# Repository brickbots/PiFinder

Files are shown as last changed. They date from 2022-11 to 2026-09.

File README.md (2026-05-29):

# PiFinder™
A plate solving telescope finder based around a Raspberry PI, imx296 camera, and custom UI 'hat'

For an overview of what the PiFinder™ is and how it came to be visit the official project website at [PiFinder.io](https://www.pifinder.io/build-yours) 

The PiFinder™ uses the [Cedar Detect](https://github.com/smroid/cedar-detect) and
[Cedar Solve](https://github.com/smroid/cedar-solve) libraries by
[smroid](https://github.com/smroid). Cedar Solve is licensed under Apache-2.0.

**Cedar Detect** is published under the Functional Source License (`FSL-1.1-MIT`),
which permits broad non-commercial use but excludes commercial uses that compete
with Cedar Detect. Because the PiFinder™ is also offered commercially, it bundles
and distributes the Cedar Detect binaries under a **separate license granted
expressly by the copyright holder** — not under the public FSL terms. The prebuilt
binaries live in [`bin/`](./bin/); see [`bin/README.md`](./bin/README.md) for the
full licensing details and a copy of the Cedar Detect license. Note this is
distinct from the PiFinder project's own GPL-3.0 [`LICENSE`](./LICENSE).

Thank you to [smroid](https://github.com/smroid) for all your support of the PiFinder project!

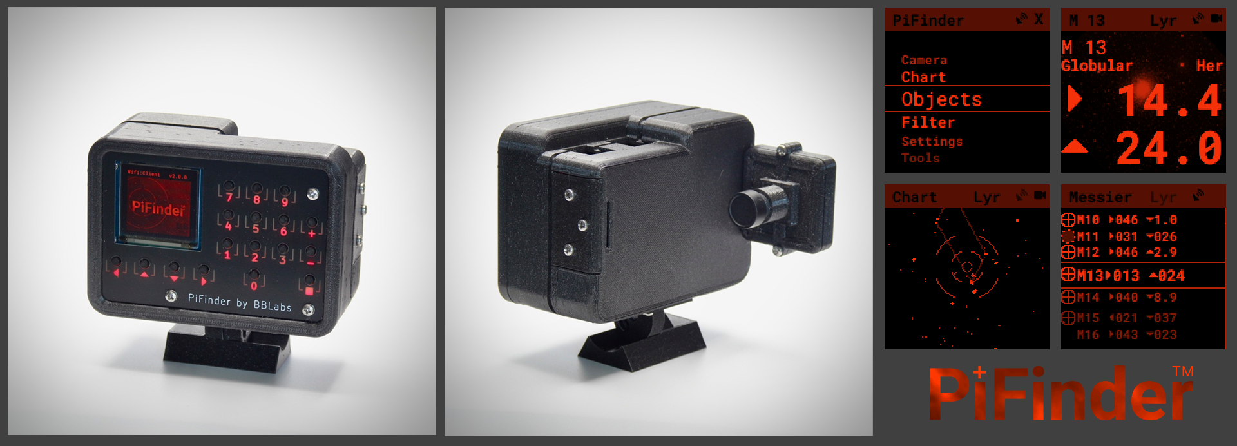
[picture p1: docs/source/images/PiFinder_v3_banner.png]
Banner

The PiFinder™ is my attempt to improve my time at my telescope.  I don't get nearly enough of it and I want to enjoy it as much as possible.  So after years of observing with paper charts and, later, a Nexus DSC here is what I felt I was missing:
* **Reliable telescope positioning:**  The Nexus DSC is great, but my scope just isn't built for solid encoder integration.  The slop in the way I have to couple the encoders means poor pointing accuracy.
* **Easy setup:**  The Nexus DSC needs multi-star alignment to understand how the encoders map to the sky.  The process is not terrible, but I'd like to avoid it.
* **Good push-to functionality**:  This is one place the Nexus DSC shines... if it's well aligned.  The catalog system is okay, and once you select and object the screen is clear and helpful to get the telescope pointed correctly.
* **Observation logging**:  I like to keep track of what I see each night.  I don't often sketch, just record what I saw when, with what eyepiece and some basic info about the experience.  If I could do this right at the eyepiece, that'd save time.

My hope is that other people will find this combination of functionality useful, will build their own PiFinder™ and help the whole project improve by making suggestions and potentially contributing to the software.  It's a pretty easy build with off the shelf parts and beginner friendly soldering.  

## Features
* Zero setup: Just turn it on and point it at the sky!  
* Accurate pointing: Onboard GPS determines location and time while the camera determines where the scope is pointing.  Inertial Measurement Unit tracks scope motion and updates sky position between camera solves
* Self-contained:  Includes catalog search/filtering, sky/object charting, push-to guidance and logging all via the screen and keypad on the unit.
* Dark site friendly:  Red OLED screen and soft backlit keys have wide brightness adjustment, right down to 'off'. No need for bright cell phones or tablets
* Easy access: Can be mounted by the eyepiece just like a finder.
- Wifi Access Point / SkySafari Integration:  The PiFinder™ can act as a WIFI access point to connect your tablet or phone to sync SkySafari or other planetarium software with your scope.

## Build Your Own
The PiFinder™ is fully open-source hardware and software.  You can order PCB's and 3d print the case with the files in this repo and order all the parts from the [parts List](https://pifinder.readthedocs.io/en/release/BOM.html).

If you would like pre-assembled units, kits or other items to jump start your PiFinder™ journey, visit [PiFinder.io](https://www.pifinder.io/build-pifinder) to see what's available and place an order.

## Docs

* [Quick Start](https://pifinder.readthedocs.io/en/release/quick_start.html)
* [User Manual](https://pifinder.readthedocs.io/en/release/user_guide.html)
* [Parts List](https://pifinder.readthedocs.io/en/release/BOM.html)
* [Build Guide](https://pifinder.readthedocs.io/en/release/build_guide.html)
* [Software Setup](https://pifinder.readthedocs.io/en/release/software.html)
* [Developer Guide](https://pifinder.readthedocs.io/en/release/dev_guide.html)

## Releases and Updates

If you are using a PiFinder, I recommend you watch releases in this repo.  Click the 'Watch' button up at the top right of the page, choose 'Custom' and then 'Releases' to make sure you don't miss any new features!

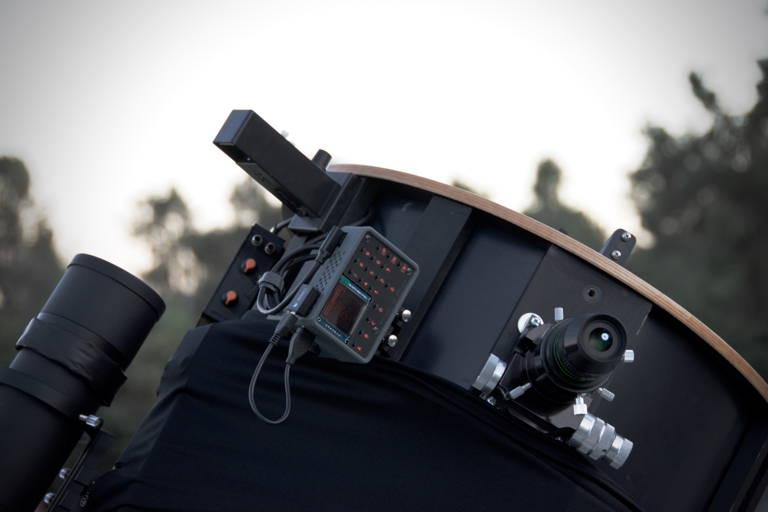
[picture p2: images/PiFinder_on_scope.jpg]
PiFinder™ on my Dob


If you'd like to learn more about how it works, and potentially build your own, everything you need should be here.  I recommend starting with the [User Manual](https://pifinder.readthedocs.io/en/release/user_guide.html) and then checking out the build process using the links below.

## Discord
Join the  [PiFinder™ Discord server](https://discord.gg/Nk5fHcAtWD) for support with your build, usage questions, and suggestions for improvement.

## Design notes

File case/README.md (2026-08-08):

# PiFinder Case Parts Readme 

In these directories you'll find STL's for all the parts of the PiFinder.
You won't need all these pieces for any one build.  There are a few options so
please read through the [build guide](https://pifinder.readthedocs.io/en/release/build_guide.html) 
and especially the [printed parts guide](https://pifinder.readthedocs.io/en/release/build_guide.html#printed-parts) 
before you start printing.   
Reach out to [info@pifinder.io](mailto:info@pifinder.io) or join our [Discord](https://discord.gg/Nk5fHcAtWD) 
to ask any questions.

## Versions

### DIY v2.5
The current DIY version of the PiFinder is the v2.5 and you can find all the parts for various
configurations in the v2.5 directory.  If you have purchased a kit or ordered PCB's and parts
from the BOM, this is the version you are building.

The v2.5 is functionally identical to the v3, runs the 
same software and performs the same, but the v2.5
has electronics that can be assembled by hand and the case design is easier to print/assemble.
Build instructions on the site are for the v2.5.

### Assembled rev4

Case parts and PCB designs for the rev3 are available here for reference, but there is no build 
guide and we can't support DIY rev4 builds as the electronics MUST be assembled
via reflow soldering and are not able to be built by hand.  If you've
ordered a kit or otherwise hand-assembled your electronics, you'll want to follow the v2.5 build
guide and print the v2.5 parts.

### Assembled v3

Case parts and PCB designs for the v3 are available here for reference, but there is no build 
guide and we can't support DIY v3 builds as the electronics MUST be assembled
via reflow soldering and are not able to be built by hand.  If you've
ordered a kit or otherwise hand-assembled your electronics, you'll want to follow the v2.5 build
guide and print the v2.5 parts.

## PiSugar
The internal battery option has proven so popular that all case configurations now accomodate the PiSugar battery and control board. 

## Adapters

In the adapters subdirectory you'll find different options and adapters for fixing your PiFinder to your telescope. 

At the moment there's an adapter solution for [Rigel Quickfinder's base plates](adapters/quikfinder).

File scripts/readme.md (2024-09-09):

use generate_script.py to generate a random testing script.

The frequencies you can find in the script can be changed for certain cases
but are a good starting point.

Scripts can be generated like this:

```bash
python3.9 generate_script new_random_1k 1000
```

Scripts can be run locally like this:

```bash
python3.9 -m PiFinder.main -fh --camera debug --keyboard local -x --script new_random_1k   # 1k is the number of frames
```

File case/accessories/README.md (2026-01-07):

# PiFinder Case Accesories

This directory contains a variety of useful accessories.  Unless otherwise
noted these are contributed by Brickbots

## 90 Degree Dovetail

Fits in a standard synta style finder shoe and offers a place to mount
another shoe at 90 degrees to the original.  If you have mounted your
scope side-saddle and the finder shoe is pointing out horizontally, this
may be the part you need to get your PiFinder mounted.

Requires 2x m4 inserts to provide a place to mount a commercial finder shoe

## Screen Cover

Contributed by KAL and found at:
* https://www.printables.com/model/1545603-v3-pifinder-protective-cover/files
* https://www.printables.com/model/1536615-v25-pifinder-protective-cover/files

A screen cover which friction fits onto the front of the PiFinder.  Designed to
be printed in a flexible material and with a version for v2.x and v3 style PiFinders!

## Tube Shoe Mounts

Clamps around a tube and provides a place to mount a finder shoe.  Tube OD size
is indicated in filename

Requires:
* 4x 1/4-20 Bolts
* 4x 1/4-20 Threaded inserts
* 2x M4 Threaded inserts

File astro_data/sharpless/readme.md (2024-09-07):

heasarc_sharpless.txt is currently not used, but contains J2000 coordinates.
galaxymap process/scrape is to gather the descriptions from the galaxymap website.

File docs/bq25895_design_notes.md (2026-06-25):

# BQ25895 Power-Path Design Notes

Reference notes from a design review of the BQ25895 battery charger for use in the new PiFinder hardware. Datasheet: TI SLUSC88C (March 2015, revised October 2022).

## Chip basics

- TI BQ25895 — single-cell Li-ion/Li-polymer I²C-controlled switch-mode charger.
- I²C address: **0x6A** (1101010b + R/W).
- Power-path topology: NVDC (Narrow VDC) — SYS is regulated just above battery voltage when running off VBUS, and switches to the battery via the internal BATFET when VBUS is gone.
- Internal FETs: RBFET (Q1, VBUS↔PMID), HSFET (Q2, PMID↔SW), LSFET (Q3, SW↔PGND), BATFET (Q4, SYS↔BAT).

## Pin map (relevant subset)

| Pin | Role |
|---|---|
| VBUS (1) | Adapter input (3.9–14 V), source of RBFET. |
| PMID (23) | **Internal node** between RBFET and HSFET. Doubles as boost (OTG) output. Only intended to have its bypass cap on it. |
| SW (19,20) | Switching node to external inductor. |
| SYS (15,16) | **System rail.** Regulated by buck when VBUS present, fed from BAT via BATFET when VBUS absent. This is the rail your loads should hang off. |
| BAT (13,14) | Battery terminal. |
| /OTG (8) | Hardware enable for boost mode. Both `/OTG` high *and* `OTG_CONFIG=1` (REG03 bit 5) required to enter boost. |
| /CE (9) | Charge enable, active low. |

## Key registers

| Reg | Bit(s) | Field | Notes |
|---|---|---|---|
| REG00 | 7 | EN_HIZ | Set to 1 to open RBFET (no current from VBUS). Default 0. |
| REG00 | 5:0 | IINLIM | Input current limit (100 mA – 3.25 A). |
| REG02 | 5 | BOOST_FREQ | 0 = 1.5 MHz, 1 = 500 kHz (default). |
| REG02 | 0 | AUTO_DPDM_EN | Auto D+/D- (USB adapter) detection on VBUS insertion. **Default 1.** When 1, each cable insertion re-runs detection and overwrites IINLIM (~500 mA for an SDP). Set to 0 to keep the configured IINLIM across replugs. |
| REG03 | 6 | WD_RST | Write 1 to kick the I²C watchdog. |
| REG03 | 5 | OTG_CONFIG | Boost (OTG) mode enable. **Default 1.** Set to 0 to disable. |
| REG03 | 4 | CHG_CONFIG | Charge enable (default 1). |
| REG03 | 3:1 | SYS_MIN | Minimum SYS voltage floor (3.0–3.7 V, default 3.5 V). |
| REG07 | 5:4 | WATCHDOG | I²C watchdog timer. **00 = disabled**, 01 = 40 s (default), 10 = 80 s, 11 = 160 s. When the watchdog times out, REG03 (and others) reset to defaults — meaning OTG_CONFIG snaps back to 1. |

## Disabling the boost converter from the command line

Goal: persistently disable the OTG/boost converter so PMID never sources voltage from the battery.

```bash
# Disable the I²C watchdog so register writes stick (REG07: 0x9D -> 0x8D)
sudo i2cset -y 1 0x6A 0x07 0x8D

# Clear OTG_CONFIG in REG03 (0x3A default -> 0x1A with bit 5 cleared)
sudo i2cset -y 1 0x6A 0x03 0x1A

# Verify
sudo i2cget -y 1 0x6A 0x03   # expect 0x1A
sudo i2cget -y 1 0x6A 0x07   # expect 0x8D
```

Order matters: kill the watchdog first, otherwise it can re-enable OTG between writes.

These are blind writes that assume otherwise-default REG03/REG07 contents. If you change SYS_MIN, charging timer, etc., do read-modify-write instead.

## Making a fast charge rate survive a cable replug (powered off)

Goal: charge at ~1.5 A and keep it there after the cable is unplugged/replugged while the PiFinder is off. The chip stays battery-powered when the system is off, so its registers persist; the two things that would otherwise revert the input limit are the I²C watchdog (a timeout resets the charge registers) and auto adapter detection (each insertion re-detects and drops IINLIM to ~500 mA). Disable both, then set the limits.

```bash
# 1. Disable the I²C watchdog first so the rest stick (REG07: 0x9D -> 0x8D)
sudo i2cset -y 1 0x6A 0x07 0x8D

# 2. Disable auto D+/D- detection so replugs don't re-detect (REG02 bit0)
#    0x3D default -> 0x3C
sudo i2cset -y 1 0x6A 0x02 0x3C

# 3. Input current limit -> 1500 mA (REG00 IINLIM=0x1C, keep EN_ILIM)
sudo i2cset -y 1 0x6A 0x00 0x5C

# 4. Fast-charge current -> ~1.5 A (REG04 ICHG=0x17 = 1472 mA)
sudo i2cset -y 1 0x6A 0x04 0x17
```

This is what `battery_bq25895.apply_charging_config()` does on every poll (read-modify-write, not blind). It is **not** truly permanent: a full power-on reset (battery fully drained or disconnected) restores `AUTO_DPDM_EN=1`, so the first insertion after that charges slowly until the unit is booted once more. The chip has no non-volatile config; the only software-independent fix is a hardware DCP signature (D+ shorted to D-) so the chip auto-detects a high-current source.

## Disabling VBUS draw (HIZ mode)

To stop drawing from VBUS while keeping the chip alive on battery:

```bash
sudo i2cset -y 1 0x6A 0x00 0x88   # set EN_HIZ=1, keep IINLIM at 500 mA
```

HIZ also stops charging — there is no mode that charges from VBUS while keeping PMID dark, because PMID *is* VBUS (through RBFET) during charging.

## OTG (On-The-Go / boost) mode summary

- Runs the buck converter in reverse: BAT → boosted output on PMID.
- Output: 4.55–5.51 V adjustable (REG0A bits 7:4).
- Output current: up to 3.1 A (REG0A bits 2:0).
- Activated only when both OTG_CONFIG=1 *and* /OTG pin high *and* no VBUS present.
- The intended use is "USB OTG" — letting a battery-powered host source 5 V on the same connector that normally receives charge.

## PMID vs SYS — important architectural point

PMID is **not** a regulated output rail in the normal sense. It has two roles:

1. **VBUS present, charging:** PMID = VBUS minus a small RBFET drop. It's the input bypass node for the buck converter, riding at adapter voltage (anywhere 3.9–14 V).
2. **VBUS absent, OTG enabled:** PMID is the boost output, regulated 4.55–5.51 V.

In the TI reference schematics (Figure 9-1, Figure 9-14) PMID has only its bypass cap (40–60 µF if OTG is used, 8.2 µF if not) and the optional OTG load. The host system is fed from **SYS**, never PMID.

**Takeaway for the new PiFinder board:** any system load currently tied to PMID should be moved to SYS. There is no I²C-only way to keep PMID dark while charging — the fix is in the schematic.

## SYS current limits

| Mode | Limit |
|---|---|
| VBUS feeding buck | **5 A continuous** (I_SYS spec, §7.3) |
| Battery feeding SYS via BATFET | **6 A continuous, 9 A peak ≤1 s** |
| BATFET OCP trip | 9 A |

Adapter must be sized ≥3 A on VBUS to deliver max SYS current per §10.

For a 1S Li-ion (3.0–4.2 V), 5 A on SYS ≈ 18–21 W — way more than a Pi-class load needs.

Thermal: WQFN-24, R_θJA ≈ 31.8 °C/W with PowerPAD soldered. Built-in thermal regulation at 120 °C (T_REG, REG08[1:0]), shutdown at 160 °C.

## SYS rail = 5.1 V?

Not natively achievable on the BQ25895. SYS is a narrow rail clamped just above battery voltage; you can't get 5 V regulated out of a 1S Li-ion via this chip's buck.

Options considered:

1. **Switch to a buck-boost charger** like BQ25798 / BQ25792 / BQ25790 — supports 1S–4S, USB-C PD, can produce higher SYS voltages. Bigger architectural change.
2. **2S battery + buck charger** like BQ25887 — gives a clean ≥5 V SYS naturally. More cells, more cost, more layout area.
3. **Keep the BQ25895 and add an external boost on SYS** — minimum-change path. **Chosen approach.**

## External SYS → 5.1 V boost

Existing build already uses an LM5157 to boost 5.1 V → 17 V for an OLED. LM5157 is a wide-input non-synchronous controller, fine where it sits, but **not** the right pick for the new SYS → 5.1 V stage:

- Non-synchronous (Schottky) costs ~7–9% efficiency at 5 V output.
- Boost ratio of 1.2–1.7× sits in the part's least-efficient region.
- Larger BOM / area than a dedicated low-Vout sync boost.

### Recommended part: **TPS61089**

- Synchronous boost, 5 A integrated switch, 94–96% efficiency at 5 V from Li-ion.
- Input 2.5–12 V, output adjustable 4.5–12 V.
- Internal compensation, programmable Fsw 500 kHz – 2.5 MHz.
- VQFN-12, ~3×3 mm.
- Sized appropriately for a Pi + camera + downstream LM5157 load (~2 A continuous, 3 A peak).

External BOM: ~1 µH inductor (e.g., Coilcraft XAL4020, ≥6 A sat), 22 µF X7R input cap, 22–47 µF X7R output cap, two-resistor FB divider for 5.1 V. No diode (synchronous).

### Alternatives

- **TPS61022** — if continuous load is firmly under 1.5 A; smaller, but likely undersized for the cascaded OLED stage.
- **TPS61288** — 10 A switch class; only worth it if ≥3 A continuous on the 5 V rail.

## Architectural optimization to consider

The current chain is two cascaded boost stages: SYS (3–4.5 V) → 5.1 V → 17 V, ≈ 83% end-to-end for the OLED rail.

LM5157 will accept inputs down to 1.5 V, so it could run directly from SYS (or BAT) and produce 17 V in one stage:
- From 3.7 V → 17 V, duty cycle ≈ 78%, well inside LM5157's ~90% max.
- Single-stage efficiency ≈ 88–90%.
- Eliminates the second conversion entirely for the OLED.

The 5.1 V rail (TPS61089) would then only feed actual 5 V loads, sizing the boost down. Worth evaluating if OLED runtime ever becomes a concern.

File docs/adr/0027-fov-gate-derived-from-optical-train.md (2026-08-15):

# FOV gate derived from the optical train

PiFinder ships more than one camera sensor and now more than one lens, but the
solver's FOV gate was the fixed pair `fov_estimate=12.0, fov_max_error=4.0` —
a compromise straddling the two sensors rather than a description of either.
We now derive the gate, SQM's radiometric field width, and the chart's frustum
shading from an **optical train**: the auto-detected camera profile paired with
a user-configured **lens**. Field of view stops being three disagreeing
constants and becomes one computed value.

## Why it mattered

A 12 mm lens on an imx296 images 17.8°, which falls outside the old
`[8.0, 16.0]` window. Tetra3 enforces that window twice — candidates are pruned
by implied field of view before verification, and survivors are rejected after
fitting — so such a frame does not solve *at all*, however many good centroids
it contains. The old constants happened to cover three of the four
sensor × lens combinations we can ship, and nothing in the code said which one
they were for.

## Considered options

**Widening the fixed window** to span every combination would work, but it
keeps a constant that describes no actual hardware and gets looser with each
new lens. Deriving instead makes the gate *tighter* than before while being
correct everywhere: the old window was effectively ±33% of its estimate.

**Margin: ±15% of the derived field of view**, not a fixed number of degrees.
An absolute margin is proportionally four times looser on a 10° train than a
20° one. 15% covers lens-sample spread, barrel distortion and focus shift;
it was validated against real frames re-projected to all four combinations,
including injected ±5% lens error, with every case solving.

**Effective, not nominal, focal length** drives the derivation. The shipped
"16 mm" lens measures ~15.6 mm, and a single effective length of 15.61 mm
reproduces *both* independently calibrated SQM field widths (imx296 13.71,
imx462 10.38) to within 0.02°. Deriving from the nominal 16.0 instead would
silently shift every existing user's SQM by ~0.05 mag. `Lens` therefore
carries both: nominal for the menu label the user reads off the barrel,
effective for all arithmetic.

## Consequences

**A mis-stated lens means no solves, and we deliberately do not recover from
it.** The gate is centred on what the user said is fitted, so stating the
wrong lens puts every frame outside the window. We considered detecting this
(retry unconstrained, read the fitted FOV, infer the lens) and rejected it for
this change: the lens is clearly marked on the barrel, so the troubleshooting
path documents cleanly, and self-healing would add a recovery path through the
solver's hot loop for a once-per-device setting.

The sharp edge is that this failure *presents as an exposure problem*.
Auto-exposure is driven by `Matches`, not by centroid count, so zero matches
from a rejected-but-perfectly-good frame sends zero-match recovery walking the
exposure ladder indefinitely. That weakness is not new — defocus does the same
thing today — and gating recovery on centroid count is tracked separately.
Until then, "solves stopped after I changed the lens" is a documentation
problem, not a code path.

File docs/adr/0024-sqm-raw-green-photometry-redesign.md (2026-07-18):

# SQM: raw-green photometry with self-calibrating black level, color term, and wing correction

The shipped SQM was computed on the 8-bit processed display image with a static
pedestal constant. It wandered 0.7–2.4 mag within a night as auto-exposure moved,
and shifted with focus and sensor swaps. We redesigned it to be self-calibrating:
every correction is either measured from the frame stream itself or is a fixed
property of the sensor — no hand-tuned absolute constant.

The plate-solving path is untouched: solving stays on the processed image
(bare sensors keep their NIR sensitivity for solving); only SQM photometry moves
to the raw frame.

## The decision, in four parts

1. **Photometry on the raw green channel** (`sqm_use_raw_green` in the camera
   profile). The processed image's clipping, 8-bit quantisation and resize break
   the flux linearity photometry needs. For Bayer sensors the green channel is
   the mean of the two green sites; solve centroids are scaled from the 512-px
   processed frame to green-frame pixels. If the raw frame is unavailable the
   SQM cycle is **skipped**, never computed on the processed image with the raw
   profile.

2. **Black level from a per-frame joint fit** (`PedestalEstimator`). Auto-exposure
   sweeps exposure continuously, so fitting `background = P0 + rate·exposure`
   over a rolling window recovers the true black level `P0` (glossary: this is
   the *bias offset*; the fitted slope is the dark-current term and is discarded,
   never subtracted). A static constant that misses the true black level is what
   made SQM exposure-dependent. The fit refuses to run until the exposure range
   spans ≥2×; the profile `bias_offset` is the fallback.

3. **Color term** `V − T·(B−V)` per matched star (B−V from Hipparcos by HIP id).
   The catalog magnitude is Johnson V but the sensor passband is not: bare color
   sensors leak NIR, over-fluxing red stars. `T` is per-sensor
   (`color_coefficient`): 0.8 measured on-sky for bare imx462/imx290, 0.0 for
   HQ (factory IR-cut; measured −0.05 ≈ 0), 0.0 *placeholder* for the imx296
   mono (unmeasured — no working unit available). This is an instrumental
   passband match — the same thing a hardware SQM meter's fixed spectral
   response does — and is distinct from the atmospheric correction that
   ADR-0002 keeps out of the published value.

4. **Wing correction** (`WingEstimator`). Curve-of-growth measurement on the
   sweeps showed the r=5 px aperture misses 25–38% of each star's flux in the
   lens-halo wings, biasing `mzero` low and SQM bright by 0.3–0.5 mag — the
   dominant absolute error. The estimator finds each star's wing boundary by
   growing rings until the profile flattens, measures the aperture's enclosed
   fraction `f`, smooths `f` in a rolling window, and applies `−2.5·log10(f)`
   to `mzero` on every frame. The **measure/smooth/apply split is load-bearing**:
   wings sink below the noise at short exposures, so a per-frame correction
   re-introduces the exposure dependence (measured: exposure slopes up to
   −1.2 mag/dex and 3–6× worse scatter).

5. **Robust mzero.** The zero point is the **median** of the per-star zero
   points, not a flux-weighted mean, and stars peaking above 70% of full scale
   are excluded (CMOS response bends well before hard clip). A flux-weighted
   mean concentrates the vote in the brightest stars — exactly the ones prone
   to nonlinearity and to colour-term extrapolation (B−V lookups are clamped
   to ≤1.2 for the same reason). One near-saturated red giant dragged a
   night's SQM by 0.5 mag under flux weighting; the median is unmoved
   (validated: night-to-night spread 0.63 → 0.06 mag on the imx462 sweeps).

## Considered and rejected

- **IR-cut filter (hardware):** clobbers the NIR sensitivity plate-solving
  depends on, and thousands of devices are already in the field.
- **Per-sensor zero-point constant** (additive mag offset calibrated against a
  reference meter): implemented, then removed. It rested on 3 hand-read meter
  points per sensor, and the residual it papered over turned out to be the wing
  loss (correctable from data) plus night-to-night reference scatter (not a
  sensor property). A constant cannot represent either.
- **Per-frame adaptive apertures** (radius ∝ HFD): wings extend far beyond any
  HFD-scaled radius, and the correction becomes exposure-dependent.
- **Low-percentile / minimum annulus background:** order statistics of a noisy
  sky sit below truth by a noise-dependent amount, and noise varies with
  exposure — measured slopes to −0.6 mag/dex. Median (or a mode estimator on
  large samples) is the only safe annulus statistic.
- **Faint-star cut in the mzero fit:** pooled per-star statistics show the
  faintest flux quartile reading −0.11 mag (identically on imx462 and hq —
  a fixed-ADU annulus error eats a bigger fraction of a small flux). Cutting
  those stars was scanned across the 8-sweep ensemble and made every metric
  worse: the median mzero already absorbs the tail, and shrinking a 10–20
  star sample toward 3–5 costs more in median noise than the bias removal
  gains. Don't re-invent this.

## Consequences

- On the six validation sweeps, SQM is exposure-flat and focus-flat
  (std 0.07–0.22 mag within a sweep) and lands within **±0.07 mag** of the
  hand-held reference meter on 4 of 6 nights with no tuned constant. Two nights
  read ~0.6 mag apart from the reference for reasons the star photometry cannot
  see (reference pointing/haze suspected); settling the absolute anchor needs a
  proper campaign (side-by-side meter on the camera field, or M67 standard
  photometry).
- All published values change scale relative to prior firmware; prior SQM logs
  are not comparable.
- The imx296 mono `color_coefficient=0.0` is an unmeasured placeholder; measure
  it when a working unit exists.
- The estimators condition over the first minutes of operation; until then SQM
  runs on the profile fallback (`bias_offset`, no wing correction).

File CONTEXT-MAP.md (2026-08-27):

# Context Map

PiFinder is a multi-process Raspberry Pi finder/plate-solver. These contexts each own a distinct slice of the runtime and have their own vocabulary.

## Contexts

- [Catalog](./docs/ax/catalog/CONTEXT.md) — loads, filters, searches astronomical catalogs (M, NGC, IC, WDS, planets, comets) for the UI.
- [Positioning](./docs/ax/positioning/CONTEXT.md) — acquires telescope pointing via plate-solving and IMU dead-reckoning; publishes the canonical "where am I looking?" answer.
- [GPS](./docs/ax/gps/CONTEXT.md) — acquires the observer's position and the wall-clock time from a satellite receiver, behind three interchangeable backends (raw UBX, gpsd, replay/fake).
- [SQM](./docs/ax/sqm/CONTEXT.md) — estimates sky brightness in mag/arcsec² from solved frames; also produces the noise-floor signal auto-exposure consumes.
- [Equipment](./docs/ax/equipment/CONTEXT.md) — models the user's telescopes and eyepieces; supplies the active optics that drive magnification, true field of view, and object-image orientation.
- [UI](./docs/ax/ui/CONTEXT.md) — the on-device menu system: menu tree, screen modules, the navigation stack and key dispatch, marking menus.
- [Camera](./docs/ax/camera/CONTEXT.md) — captures frames and decides exposure: the three exposure regimes, the auto-exposure controllers, and zero-match recovery.
- [Battery](./docs/ax/battery/CONTEXT.md) — reads battery voltage and charge state from the rev-4 BQ25895 charger and publishes `BatteryState`; read-only telemetry, gated on hardware presence.
- [Sound](./docs/ax/sound/CONTEXT.md) — turns named events into short **earcons** on the rev-4 passive buzzer (hardware PWM ch0, GPIO12); best-effort, fire-and-forget feedback, gated on hardware presence.
- [Display](./docs/ax/display/CONTEXT.md) — how panels turn rendered pixels into light: each panel's brightness axes, the dimming policy (knee curve), and the camera-as-photometer bench rig that measures panel flux. Runtime policy + bench tooling.
- [NixOS](./docs/ax/nixos/CONTEXT.md) — how a NixOS PiFinder is built, published, and updated over the air: the Attic cache, the stable/beta/unstable channels, and the on-device upgrade flow. Cross-cutting infrastructure, not a runtime slice.
- [Bring-up](./docs/ax/bringup/CONTEXT.md) — first power-on validation of a freshly assembled board: the checks a builder runs at the bench and which of them can be machine-verified. Bench tooling, not a runtime slice.

## Relationships

- **Positioning → Catalog**: Catalog reads RA/Dec/Alt/Az from `shared_state.solution()` to compute visibility and "near me" lists.
- **GPS → system-wide**: the GPS process is the only subsystem process that does **not** hold `shared_state`; it publishes `("fix" | "time" | "satellites", payload)` onto `gps_queue` and the main loop writes them into shared state on its behalf, applying the **location source** precedence rules (a `WEB`/`MANUAL`/`CONFIG:`/`replay` location outranks the receiver) and discarding any fix whose **position error** is worse than the stored one. `gps_queue` flows only *into* main — there is no main → GPS channel.
- **GPS → Positioning**: the stored location supplies the observer's lat/lon/altitude and the wall-clock time that turn a plate-solved RA/Dec into Alt/Az. Beware the word **solution**: in GPS it is the receiver's navigation solution, in Positioning it is a plate-solve result, and both hang off `shared_state`.
- **GPS → UI**: `UIGPSStatus` renders lock and satellite state, and can publish a fix of its own back onto `gps_queue` (save/lock location). The STATUS screen's **comms row** reports link liveness from the parser's **event** stream, including markers for frames that could not be decoded (see [ADR 0032](./docs/adr/0032-ubx-parser-yields-undecodable-frames.md)).
- **Positioning → SQM**: SQM is a side effect of every successful plate solve in the solver process; it reuses the tetra3 `matched_centroids` and the camera frame.
- **SQM / Camera units boundary**: SQM photometry and its pedestal diagnostics use raw sensor ADU. The Camera background controller measures processed 8-bit images and uses its separate shared 10 ADU floor; raw SQM thresholds must not cross that boundary.
- **Positioning → Camera**: `Matches` is published on every solve attempt (success or failure) as the feedback signal for solver-driven auto-exposure.
- **Camera → Positioning / SQM / UI (optical train)**: Camera owns the **optical train** — the detected sensor profile paired with the configured **lens**. Its derived **field of view** is the single source for Positioning's **FOV gate**, SQM's **radiometric field width**, and the chart's frustum shading. Each of those was previously an independent hard-coded constant, and they disagreed with each other and with the hardware. The sensor half is auto-detected and the lens half cannot be detected at all, so a mis-stated lens is a configuration error that surfaces as *no solves whatsoever* — deliberately not auto-corrected (see [ADR 0027](./docs/adr/0027-fov-gate-derived-from-optical-train.md)).
- **Camera → Positioning**: `SCREEN_ROTATE_AMOUNTS` (`camera_interface.py`) rotates every capture before the solver sees it; the post-rotation image defines Positioning's **camera frame**, so each entry is only valid paired with that variant's `q_imu2cam` — pairs are derived with the imu2cam tool and pinned together by `tests/test_imu2cam_tool_presets.py`.
- **Catalog ↔ Positioning**: Catalog supplies the `(RA, Dec)` target for the alignment flow that calibrates `solve_pixel` in Positioning.
- **Equipment → Catalog**: the active telescope's flip/flop flags and the active eyepiece's true field of view orient and scale the POSS/SDSS object image in `cat_images.get_display_image`.
- **Positioning → Equipment**: the object-image baseline rotation combines the active telescope's flip/flop with the live solve **roll** from `shared_state` (see [ADR 0003](./docs/adr/0003-object-image-orientation.md)).
- **Battery → UI**: STATUS (and web/API) display `BatteryState` from `shared_state.battery()` — *consumption is future work; this run is plumbing + tests only*.
- **Battery → system-wide**: `hardware_detect` probes the I²C bus at startup and publishes `HardwareCapabilities` into `shared_state`; the battery monitor process only runs when `has_bq25895` is detected (rev4). The same capabilities record is the source of truth for other rev-dependent decisions.
- **Sound → system-wide**: `hardware_detect` sets `has_buzzer` from the *same* rev4 marker (the charger probe — a bare GPIO buzzer can't be probed directly); the sound process only spawns when `has_buzzer`. On rev3/dev `sound_queue` is `None` and the producer helper no-ops.
- **UI → Sound**: keypresses and the volume menu in the main loop request earcons (`KEYPRESS`, `VOLUME_SAMPLE`); master volume is a `Config` setting (`sound_volume`) pushed to the player as `SetVolume`.
- **Sound → shutdown**: the shutdown chokepoint (`callbacks.shutdown`) plays `SHUTDOWN` and waits its catalog duration + margin **before** triggering the GPIO14 power latch (see [ADR 0007](./docs/adr/0007-gpio-poweroff-latch.md)), so the cue isn't cut off by power-down.

- **Bring-up → Battery / Sound / Positioning**: bring-up constructs those contexts' hardware seams *directly* (`BQ25895`, `BuzzerPWM`, `imu_pi.Imu`) instead of spawning their monitor processes — it is a single process with no `SharedStateObj`. It stays inside each context's rules: charger access is reads plus the sanctioned one-shot ADC trigger, never the fast-charge config write (ADR 0017), and earcons come from the Sound catalog rather than raw tones.
- **Display → UI**: the UI's brightness setting (level, 0-255) is Display vocabulary; `set_brightness` in the display drivers maps it to each panel's axes. The UI's tonal-range canary (the title-bar shade) constrains how far the dimming policy may cap rendered pixel values.
- **Display → Camera**: the photometer rig borrows the Camera context's sensor (lensless, fixed manual exposure) as its light meter and the SQM camera profiles for bias/crop constants — bench-only; at runtime the two contexts don't interact.
- **Display ↔ Bring-up**: both are (partly) bench tooling that drives panels below the UI layer; bring-up checks "does the panel light at all", Display characterizes how much light.
- **Bring-up → UI**: bring-up reuses the display drivers, fonts and layout helpers, but **not** `UIModule`, `MenuManager` or the menu tree — it draws its own frames and never joins the navigation stack. It reads the keypad as **switches** at their **matrix positions**, below the layer where UI's logical **keys**, `ALT_*` chords and `LNG_*` long presses are formed.
- **Bring-up ↛ `hardware_detect`**: unlike `main.py` and `splash.py`, bring-up does **not** derive its panel from the BQ25895 probe. Doing so would make a dead charger indistinguishable from a dead screen on exactly the boards it exists to diagnose.

Companion architecture docs live next to each `CONTEXT.md`:
- [`docs/ax/nixos.md`](./docs/ax/nixos.md)
- [`docs/ax/catalog.md`](./docs/ax/catalog.md)
- [`docs/ax/positioning.md`](./docs/ax/positioning.md)
- [`docs/ax/sqm.md`](./docs/ax/sqm.md)
- [`docs/ax/equipment.md`](./docs/ax/equipment.md)
- [`docs/ax/ui.md`](./docs/ax/ui.md)
- [`docs/ax/camera.md`](./docs/ax/camera.md)
- [`docs/ax/bringup.md`](./docs/ax/bringup.md)

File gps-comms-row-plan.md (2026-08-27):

# GPS comms row — implementation plan

**Goal:** answer "are we receiving GPS messages?" at a glance, on the device, with no restart and no second machine.

**Shape:** one row on the STATUS screen naming the most recent GPS **event** and how long ago it arrived.

```
GPS MSG TIMEGPS  0.4s
```

## What the row tells you

| On screen | Meaning |
|---|---|
| `SOL` / `DOP` / `TIMEGPS` churning, age near 0 | Healthy. The name changing frame to frame is itself the liveness signal — readable across a dark field without parsing digits. |
| `?0135` churning | Receiver is transmitting, but in a dialect we have no parser for. Wrong receiver, or a u-blox variant emitting IDs we don't register. |
| `?CKSUM` churning | Bytes arriving corrupted. Baud mismatch (`gps_baud_rate` is user-editable) or bad wiring. |
| name frozen, age climbing | The link died. The name tells you what it was doing when it stopped. |
| `--` | Nothing has *ever* been received this session. |

All four failure modes discriminated in one 21-character row. Today every one of them looks identical from anywhere above the parser.

## Decisions taken (and why)

1. **Live instrument, not a log view.** Every parsed message is *already* logged at DEBUG and there is a ready-made `logconf_gps.json`, but reaching it means switching log config, restarting the app, reproducing the fault, then reading a text file from another device. Unusable in the field.
2. **Capture at the frame layer, not just the message layer.** `_parse_ubx` silently drops any class/id it has no parser for, so "unintelligible" and "absent" are currently the same observation.
3. **One readout covering both backends.** `gps_gpsd` has no frames at all — its message half works unchanged, its frame-level events simply never occur.
4. **A menu item, not a key chord.** Originally scoped as SQUARE on the status screen; landed as its own discoverable, translatable entry. In the end the readout collapsed into a single status row, so no new screen is needed at all.
5. **Age + last event name, not a rate.** u-blox emits in per-epoch **bursts**, so a one-second window alternates between roughly 5 and roughly 10 and never settles. Age needs no window, is immune to burstiness, and reports *when* a dead link died — which a rate cannot.
6. **The parser yields markers for undecodable frames.** See [ADR 0032](docs/adr/0032-ubx-parser-yields-undecodable-frames.md).

## Rejected

- **A ring buffer of recent messages in `shared_state`.** The GPS process does not receive `shared_state` — it gets `(gps_queue, console_queue, gps_logqueue)` and nothing else, so this needs a new process argument. Worse, `UIStatus.update()` runs at the full 30 fps target with no throttle, so a whole-buffer copy back through the manager proxy would run 30×/second.
- **A dedicated GPS debug screen.** Designed in full, then dropped: a single row answers the actual question, and the screen would have been a second thing to navigate to while cold.
- **On-demand capture (press a key to start).** There is no main → GPS channel. `gps_queue` looks like one because it lives in `command_queues["gps"]`, but it flows only *into* main. Always-on also wins on merit: the age is already correct the instant you look, with no warm-up.
- **A once-per-second aggregate.** Would freeze the event name for a whole second and quantise the age, destroying the churn signal the design rests on.

## Implementation

### `PiFinder/gps_ubx_parser.py`

- `_parse_ubx`: for an unregistered `(class, id)`, return `{"class": f"?{msg_class:02X}{msg_id:02X}"}` instead of `{"error": "Unknown message type"}`, so the existing `if "class" in parsed` guard lets it through.
- `parse_messages`: on checksum mismatch, `yield {"class": "?CKSUM"}` alongside the existing WARNING.

Reserve the `?` prefix for markers. No real message class may start with it.

### `PiFinder/gps_comms.py` — new

`CommsPublisher(gps_queue, clock)`, shared by all three backends so the row means the same thing whichever is running. Holds the rate-cap state and does the `put`.

### `PiFinder/gps_ubx.py` — `process_messages`

Publish one comms event at the top of the `async for` loop, before the dispatch chain, so *every* event counts including ones we parse but don't act on:

```python
now = clock()
comms.publish(msg_class, now)
```

- Send the **raw** class (`NAV-TIMEGPS`); presentation belongs to the UI.
- Payload `("comms", class_name)` — the name only. See the stamping watch-out below.
- One clock reading per event, shared with the NAV-SAT freshness window, so the two agree on when a message arrived.
- **Rate-cap forwarding to ~20/s.** A resync storm can yield markers far faster than real messages arrive, and the `.ubx` replay path runs with `wait=0`. 20 Hz is well past perceptible against a 30 fps redraw, and it bounds worst-case queue traffic. This caps *reporting*, not parsing.

Steady-state cost is a handful of pipe writes per second against backpressure thresholds of 10 and 50, on a queue the main loop drains to empty 30×/second. The throttles only bite when the main loop is already stalled, where slowing GPS is the intended behaviour.

### `PiFinder/gps_gpsd.py`

Same publish in the `dict_stream` loop, using `time.monotonic()` and the same cap. Note the existing `filter=["TPV", "SKY"]` means this path can only ever report those two classes — the row is a weaker instrument on gpsd, and deliberately so rather than widening the filter as a side effect.

### `PiFinder/gps_fake.py`

The `.ubx` replay path reuses `process_messages` and gets this free. Add a publish to the synthetic branch too (class `FAKE`) so the row is live under `-fh` and the feature is developable without hardware.

### `PiFinder/state.py`

`gps_comms()` / `set_gps_comms()` and a `self.__gps_comms = None`, shaped exactly like the existing `sats` pair.

### `PiFinder/main.py`

One branch in the existing `gps_queue` drain, which is also where the event gets its stamp:

```python
if gps_msg == "comms":
    shared_state.set_gps_comms((gps_content, time.monotonic()))
```

### `PiFinder/ui/status.py`

- Add `"GPS MSG"` to `status_dict`, positioned after `"GPS LCK"` to group the four GPS rows. The key is exactly 7 characters, which is the width `_render_row` pads to. Status keys are untranslated literals throughout, so no `_()` — consistent with every existing row.
- Format in `update_status_dict` from `shared_state.gps_comms()`:
  - `None` → `"--"`
  - strip a leading `NAV-`: `TIMEGPS` and `POSECEF` (7) are the longest, versus `NAV-TIMEGPS` (11) which would not fit
  - age from `time.monotonic() - stamp`, bucketed to stay ≤ 5 chars: `<100s` → `47.2s`, `<100m` → `12m`, else `2h`

Base font is 21 chars on the 128 panel (`width=6`), key padded to 7, so the value column is **14**. Worst case `TIMEGPS 47.2s` is 13. The 176 panel gets 29, so it is only ever roomier. If a value ever does overflow, the row's existing horizontal scroller catches it rather than truncating.

## Tests

- **`test_gps_ubx_parser.py`** — an unregistered class/id yields `?XXYY`; a corrupted checksum yields `?CKSUM`. No existing test touches either branch (the one `"error"` assertion covers a short-payload SVINFO case), so nothing needs rewriting.
- **`test_gps_ubx_dispatch.py`** — extend the existing `run_messages` helper to capture `("comms", …)` puts. Assert one publish per event; assert the rate cap suppresses a burst, driven by the `FakeClock` already wired into `process_messages`; assert markers publish without disturbing the `(seen, used)` counts.
- **`test_status_scroll.py`** (or a sibling) — reuse the existing headless-display fixture for the formatter: `None` → `--`, `NAV-` stripping, age bucketing at each boundary, and **a width regression guard** asserting the rendered row fits `fonts.base.line_length` for every message class we can emit, on both panel resolutions.

## Watch-outs

- **The age stamp must be `time.monotonic()`, never wall clock.** GPS is what *sets* the system clock, so a wall-clock age jumps or inverts the moment a fix lands. This is the single easiest thing to get wrong here and it fails in exactly the situation the feature exists to diagnose.
- **...and both readings must come from the same process.** The first cut stamped in the GPS process and subtracted in main, on the theory that `CLOCK_MONOTONIC` is system-wide on Linux. It is — but `time.monotonic()`'s reference point is explicitly *undefined*, and on macOS it is process start, so the dev-machine row read a steady ~4s stale on a fake GPS publishing every 0.5s. Caught by running it, not by the tests. The stamp is now taken by main on receipt; only the name crosses the boundary.
- **`gps_queue.qsize()` raises `NotImplementedError` on macOS**, so the `.ubx` replay backend cannot run there at all (pre-existing, in both `gps_fake.emit` and `process_messages`' backpressure check). Exercise the replay path by driving `process_messages` directly, or on a Pi.
- `?` is reserved for markers.
- The gpsd path is limited to TPV/SKY by an existing filter.

## Follow-ups (not in scope)

- Surface `gps_comms` on the web status page / `/api/current-selection` — the web server already holds `shared_state`, so it is nearly free, and "read me your GPS MSG row" is a good support question.
- User-guide line documenting how to read the row.

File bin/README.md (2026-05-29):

# Cedar Detect binaries

This directory contains prebuilt **Cedar Detect** server binaries that the
PiFinder uses for star detection during plate solving:

| File | Platform |
|---|---|
| `cedar-detect-server-aarch64` | 64-bit ARM (`aarch64`) |
| `cedar-detect-server-arm64` | 64-bit ARM (`arm64`) |

At runtime PiFinder launches the binary matching the host architecture as a
local gRPC server (see the application startup notes in the project `CLAUDE.md`).

## Source

Cedar Detect is developed by Steven Rosenthal (**[smroid](https://github.com/smroid)**):

- Repository: <https://github.com/smroid/cedar-detect>

These binaries are built from that source and bundled here for convenience so
that PiFinder runs out of the box without a separate build step.

## License

Cedar Detect is published under the **Functional Source License, Version 1.1,
MIT Future License (`FSL-1.1-MIT`)**. A verbatim copy of that license, including
the upstream copyright notice, is kept alongside the binaries in
[`LICENSE-cedar-detect.md`](./LICENSE-cedar-detect.md).

In summary, the FSL grants broad rights to use, modify, and redistribute the
software for any *Permitted Purpose* — which includes internal use, and
non-commercial education and research — but **excludes a "Competing Use"**: making
the software available in a commercial product or service that substitutes for, or
offers substantially similar functionality to, Cedar Detect. (The license also
converts to the permissive MIT license five years after each version is released.)

> **Note:** This `FSL-1.1-MIT` license applies to **Cedar Detect** (the binaries in
> this directory). It is **separate from the GPL-3.0 license** that covers the
> PiFinder project itself (see the [`LICENSE`](../LICENSE) file in the repository
> root).

## PiFinder's commercial use is by express, separate permission

Because PiFinder is also offered as a commercial product, bundling and
distributing Cedar Detect with it falls outside the FSL's Permitted Purpose. The
PiFinder project does this under a **separate license granted expressly by the
copyright holder**, Steven Rosenthal — not under the public FSL-1.1-MIT terms.

The FSL itself anticipates this: *"The Software is available to be licensed under
different terms; please contact the copyright holder (Steven Rosenthal
smr@dt3.org) to discuss."* This separate grant covers the PiFinder project's use
only; it does not extend the right to commercial/competing use to anyone else
redistributing these binaries.

If you fork or redistribute PiFinder commercially, you are responsible for your
own compliance with the FSL-1.1-MIT terms or for arranging your own license with
the copyright holder.

Our thanks to [smroid](https://github.com/smroid) for supporting the PiFinder
project.

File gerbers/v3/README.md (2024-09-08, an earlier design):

# PiFinder v3 PCB Files

These files are for producing the surface mount boards used in the v3 PiFinder.
They are probably not the files you are looking for.  To build the DIY version
of the PiFinder with through-hole parts, use the gerber files in the directory
above this one.

These files require reflow soldering to assemble, even if you are good at 
hand soldering SMT parts.  The BNO055 package has leads under it that are 
impossible to solder by hand.

More than most of the files in this repo, these are very much provided AS IS
and will require a good amount of skill to assemble.

## Bill of Materials

There is a csv BOM file here with designators, part numbers, descriptions
and values.  These include the specific JLCPCB part numbers, but you should
be able to source these parts from any supplier.  To verify specific values
please use the provided part numbers and the database at https://jlcpcb.com/parts

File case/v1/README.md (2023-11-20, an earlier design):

# Version 1 parts

The current version for PiFinder case parts is version 2.  These parts are archived for reference/replacement.

## Insert Size
The build uses m2.5 threaded inserts, but there are two main types of these in general availability.  To support both of these types, there are two versions of all the pieces that require inserts.  These are stored in a `small_inserts` and `large_inserts` folder and you should only need one set.

See the images below to identify the type of insert you have.  They accept the same type of screw, but the outside diameters are slightly different.

#### Small Inserts
Small Inserts

#### Large Inserts
Large Inserts

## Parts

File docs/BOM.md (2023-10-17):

# Parts List

Please see our new documentation at:
[pifinder.readthedocs.io](https://pifinder.readthedocs.io/en/release/BOM.html)

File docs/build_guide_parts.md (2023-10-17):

# Build Guide - Printed Parts

Please see our new documentation at:
[pifinder.readthedocs.io](https://pifinder.readthedocs.io/en/release/build_guide.html)

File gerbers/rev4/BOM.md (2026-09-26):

# PiFinder rev4 Parts List

Working parts list for the rev4 (Landscape) PiFinder. This version of the PiFinder
is NOT intended as a DIY project and requires significant skill and experience to 
produce.  This list is provided as-is and no guarantee is provided. 

If you have questions, please reach out via the normal email or discord channels.

## Board files in this directory

Two of the line items below are boards produced from the gerbers here rather
than parts you order from a catalogue:

| File | Produces |
|---|---|
| `PiFinder4.zip` | The rev4 main board, ordered from JLCPCB as an assembled PCBA |
| `PiFinder4-top-plate.zip` | The rev4 keypad cover, ordered from JLCPCB as a bare PCB |
| `PiFinder4_jlc_bom.csv` | Component BOM for the PCBA assembly service |
| `PiFinder4-all_jlcpos.csv` | Pick-and-place positions for the PCBA assembly service |

The two CSVs describe the surface-mount parts that go onto the main board, so
they are not repeated in the tables below. The PCBA is a single line item here.
As with the v3 boards, the JLCPCB part numbers in the BOM can be cross-checked
or substituted using <https://jlcpcb.com/parts>.

## Electronics

| Qty | Item | Source | Notes |
|---|---|---|---|
| 1 | Raspberry Pi Compute Module 4 | TBD | CM4102000 — 2GB RAM, Lite, wireless. Lite because the board boots from its own microSD socket (J1). More RAM works if the SKU is easier to get |
| 1 | Camera module | TBD | imx296 or imx462 |
| 1 | M12 Lens (12mm or 16mm) | TBD | Set the Lens setting to match the focal length fitted, or the PiFinder will not solve |
| 1 | MicroSD card | TBD | Quality matters more than size — the software needs only a few GB |
| 1 | NHD-1.91-176176B | TBD | Newhaven Display 1.91" 176×176 display |
| 1 | Raspberry Pi heatsink kit | TBD | |
| 1 | Beitian BE-182 | TBD | GPS receiver |
| 1 | GPS cable (BE-182) | Shop-made | Current PCBA have 6 pin connector, BE-182 has 4 and currently requires a custom cable.  Future PCBA revisions will have the same 4 pin connector|
| 1 | 8000 mAh battery w JST 2.0 connector | TBD | |
| 1 | rev4 PCBA | JLCPCB, from `PiFinder4.zip` | Assembled board. See the BOM and pick-and-place CSVs in this directory |

## Other components

| Qty | Item | Source | Notes |
|---|---|---|---|
| 1 | Keypad cover (Landscape) | JLCPCB, from `PiFinder4-top-plate.zip` | A bare PCB, not a printed part |
| 1 | Rubber joystick cap | Adafruit | |

## Hardware

| Qty | Item | Source | Notes |
|---|---|---|---|
| 1 | M12 lock nut | TBD | Lens lock ring |
| 2 | M5 25 mm bolt | TBD | |
| 1 | M5 nut | TBD | |
| 2 | M5 nyloc nut | TBD | |
| 4 | M2.5 heat-set insert | TBD | |
| 7 | M2.5 8 mm screw | TBD | |
| 6 | M2.5 12 mm screw | TBD | |
| 4 | M2 10 mm self-tapping screw | TBD | |
| 1 | Spring | https://www.leespring.com/product/compression-spring-lc042d02m-music-wire | |

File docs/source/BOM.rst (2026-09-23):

Parts List
==========

Here's a full list of all the items you'll need to build your own PiFinder.  It roughly follows the :doc:`Build Guide<build_guide>` and I've tried to provide current sources where possible.  Reach out with any questions!

For those folks in the US, Digikey has most of the electronics components and this List can get you started:
`https://www.digikey.com/en/mylists/list/JMHESEPVKV <https://www.digikey.com/en/mylists/list/JMHESEPVKV>`_

PiFinder Hat Components
-----------------------

These are the electronic bits needed to build the Display/Keypad unit that fits onto the Raspberry Pi as a 'Hat'.  It's all through-hole soldering so should be approachable for all skill levels.

.. list-table::
   :header-rows: 1

   * - Qty
     - Item
     - URL
     - Notes
   * - 1
     - PCB Set
     - https://github.com/brickbots/PiFinder/tree/release/gerbers
     - You'll need a PiFinder board and the PiFinder top plate
   * - 17
     - 6 x 6mm x 7mm PCB Momentary Switch 4 Pin DIP
     - https://www.mouser.com/ProductDetail/113-DTS63KV or https://www.digikey.com/en/products/detail/apem-inc/ADTS63KV/1798560
     - Diptronics DTS63K or Apem ADTS63KV recommended
   * - 17
     - Red 1.8 mm (miniplast) leds
     - https://www.mouser.com/ProductDetail/78-TLUR2401
     - These need to be 2.5W x 3.3L x 3H to fit properly
   * - 1
     - 2N2222A NPN Transistor
     - https://www.mouser.com/ProductDetail/637-2N2222A
     - 
   * - 1
     - 22ohm Axial Resistor
     - 
     - R01 - 5% - 1/4w
   * - 1
     - 330ohm Axial Resistor
     - 
     - R02 - 5% - 1/4w
   * - 1
     - Waveshare 1.5 RGB Oled
     - `https://www.waveshare.com/wiki/1.5inch_RGB_OLED_Module <https://www.waveshare.com/wiki/1.5inch_RGB_OLED_Module>`_
     - 
   * - 1
     - Adafruit IMU Fusion Breakout - BNO055 - **See Note**
     - https://www.adafruit.com/product/4646
     - Order product 4646 exactly. Adafruit sells another BNO055 board (product
       2472) that looks very similar, but its data pins are in a different
       order and it does not work in the PiFinder
   * - 1
     - 2x20 40 Pin Stacking Female Header
     - https://www.amazon.com/dp/B0827THC7R
     - Depending on your heatsink/clearance you'll need long pins on this to make up the gap
   * - 1
     - GT-U7 GPS Transceiver board
     - https://www.amazon.com/Microcontroller-Compatible-Sensitivity-Navigation-Positioning/dp/B07P8YMVNT
     - There may be other pin compatible devices, but this one works great and the antenna fits the holder

Raspberry Pi / Camera / GPS
---------------------------

These are the bigger items/assemblies which you'll need to purchase to include in the overall build.

.. list-table::
   :header-rows: 1

   * - Qty
     - Item
     - URL
     - Notes
   * - 1
     - Raspberry Pi 4b 2gb
     - https://www.adafruit.com/product/4292
     - More memory is fine here...
   * - 1
     - Micro SD Card
     - 
     - High quality is best to avoid power sensitivity and corruption.  The software only needs a couple gigs, so almost any available size should be fine
   * - 1
     - innomaker imx296 mono camera module

       or
       
       innomaker imx462 color camera module
     - https://www.inno-maker.com/product/cam-mipi296raw-trigger/

       https://www.inno-maker.com/product/cam-mipi462raw/
     - 
   * - 1
     - 16mm F2 CCTV Lens for m12 Mount
     - https://www.amazon.com/dp/B07VDWNSG9
     - Other lenses might work here, but something fast is ideal.  How much sky the PiFinder
       sees depends on the camera as well as the lens.  This 16mm lens gives about 13.7
       degrees on the imx296 and about 10.4 degrees on the imx462.  The bundled star-pattern
       database sets the real limit on what you can substitute.  It is built for fields
       between 10 and 30 degrees.  A camera and lens that together see less than 10 degrees,
       or more than 30, cannot plate solve at all.  If you fit a 12mm lens instead, select
       Settings from the main menu, scroll down to Advanced, then select Lens and set it to
       12mm

You can use either the imx296 or imx462 module from innomaker.  They both 
perform about the same so choose the least expensive/easiest to get model 
in your particular location.

Case hardware
-------------

In addition to the 3d printed parts detailed in the :doc:`Build Guide<build_guide>` you'll need some bolts, heat-set inserts and standoffs to complete the build.  Everything is M2.5 and some of the lengths can vary a bit.

.. list-table::
   :header-rows: 1

   * - Qty
     - Item
     - URL
     - Notes
   * - 22
     - M2.5x4mm heat set inserts
     - 
     - 
   * - 20
     - M2.5x8mm bolts
     - 
     - Primary fastener for case frame
   * - 4
     - M2.5x20mm standoffs
     - 
     - Between Pi and Hat Depending on your heatsink and such you may need longer or shorter amounts here and you'll probably need to screw a couple together to get this length
   * - 7
     - M2.5x12mm bolt
     - 
     - 2 for the adjustable dovetail mount, 2 for the camera attachment and 3 for the shroud/top plate attachment

Power
-----

The PiFinder takes about .9amp at 5v under full load, and about 60% of this when in power-save/idle mode.  For battery sizing a good rule of thumb is about an hour of run time per 1,000mAh of battery capacity.  You can use any battery pack rated for at least 2 amps (start-up draws brief peaks of 1.5 amps) and plug this into the USB-C port on the unit.

If you'd like to have a fully stand-alone unit with integrated rechargeable battery, there are instructions in the build guide for integrating a `PiSugar S plus <https://github.com/PiSugar/PiSugar/wiki/PiSugarS-Plus>`_.  This is the lower-cost version without RTC, but it has a 5000mah battery which should provide four to five hours of run time.

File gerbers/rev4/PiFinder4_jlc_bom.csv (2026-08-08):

Comment | Designator | Footprint | JLCPart
- 503398-1892 | J1 | SD:MOLEX_503398-1892 | C428492
Light emitting diode - LED | D14,D12,D20,D3,D8,D18,D9,D5,D1,D6,D7,D2,D10,D4,D11,D17 | LED_SMD:LED_1210_3225Metric | C264578
Inductor, small symbol - 2.2uH | L4,L2 | Inductor_SMD:L_Coilcraft_XAL4020-XXX | C3151182
Resistor, small symbol - 180R | R6 | Resistor_SMD:R_0402_1005Metric | C138045
Gate resistor - 1k | R26 | Resistor_SMD:R_0402_1005Metric | C11702
22uF 25V cap - 22uF | C29,C28,C43,C45,C44 | Capacitor_SMD:C_0805_2012Metric | C45783
Resistor, small symbol - 5.1k | R19,R21,R18,R20 | Resistor_SMD:R_0402_1005Metric | C25905
2A, Discharge, Active High EN, TSOT-23-5 - RT9742CGJ5 | U5,U4 | Package_TO_SOT_SMD:TSOT-23-5 | C424402
Unpolarized capacitor, small symbol - 47nF | C47,C50 | Capacitor_SMD:C_0603_1608Metric | C1622
- TPS61088RHLR | U1 | TPS61088:RHL0020A | C87357
Push button switch, generic, two pins - SW_Push | SW0,SW_PLUS1,SW5,SW3,SW1,SW8,SW9,SW7,SW2,SW_MINUS1,SW10,SW4,SW_SQUARE1,SW6 | RSU:SW_Push_6x6mm_SMT_withhole_tight | C4364377
Resistor, small symbol - 680 | R5,R34,R33 | Resistor_SMD:R_0402_1005Metric | C137948
- Q_NPN_EBC | Q1 | RSU:PF_SOT-23-NPN | C280842
Unpolarized capacitor, small symbol - 5.6nF | C46 | Capacitor_SMD:C_0603_1608Metric | C107095
Unpolarized capacitor, small symbol - 100nF | C35,C51,C22,C34,C2,C4,C30,C14,C17,C9,C23,C55,C8,C19,C25 | Capacitor_SMD:C_0603_1608Metric | C14663
Unpolarized capacitor, small symbol - 2.2uF | C54 | Capacitor_SMD:C_0603_1608Metric | C23630
HuaWha MLT-5020 magnetic transducer, 12 ohm, 4kHz, SMD - MLT-5020 | BZ1 | RSU_Buzzers:MagneticBuzzer_HuaWha_MLT-5020 | C94598
Unpolarized capacitor, small symbol - 10uf | C52,C27,C33,C5,C1 | Capacitor_SMD:C_0805_2012Metric | C15850
Controlled Single Cell 5A Fast Charger with MaxCharge, WQFN-24 - BQ25895RTW | U9 | Package_DFN_QFN:Texas_RTW_WQFN-24-1EP_4x4mm_P0.5mm_EP2.7x2.7mm_ThermalVias | C80200
Resistor, small symbol - 10k | R7,R32,R8,R11,R12,R13 | Resistor_SMD:R_0402_1005Metric | C25744
Resistor, small symbol - 22 | R16,R29,R27,R28 | Resistor_SMD:R_0402_1005Metric | C25092
Resistor, small symbol - 182k 1% | R36 | Resistor_SMD:R_0402_1005Metric | C5159679
Unpolarized capacitor, small symbol - 1uF | C53,C40,C3,C20,C11,C18,C32 | Capacitor_SMD:C_0603_1608Metric | C15849
N-MOSFET, 30V, 5.7A, logic-level - AO3400A | Q2 | Package_TO_SOT_SMD:SOT-23 | C20917
Unpolarized capacitor, small symbol - 10uF | C21,C48 | Capacitor_SMD:C_0603_1608Metric | C96446
Resistor, small symbol - 12k | R14 | Resistor_SMD:R_0402_1005Metric | C25752
Unpolarized capacitor, small symbol - 47uF | C42 | Capacitor_SMD:C_1206_3216Metric | C403725
Navigation Switch, SMD, 500 gf, 12 V, 50 mA, Solder, 5 - MU-AS90R | SW_5WAY1 | 5-Way:MUAS70R | C38516684
Resistor, small symbol - 150k 1% | R39 | Resistor_SMD:R_0402_1005Metric | C2909320
Resistor, small symbol - 56k 1% | R37 | Resistor_SMD:R_0402_1005Metric | C114756
Resistor, small symbol - 270k 1% | R40 | Resistor_SMD:R_0402_1005Metric | C25770
Resistor, small symbol - 330 | R17 | Resistor_SMD:R_0402_1005Metric | C25104
Resistor, small symbol - 100k | R10,R15,R23 | Resistor_SMD:R_0402_1005Metric | C25741
Unpolarized capacitor, small symbol - 4.7uF | C49 | Capacitor_SMD:C_0603_1608Metric | C19666
Resistor, small symbol - 11k | R38 | Resistor_SMD:R_0402_1005Metric | C25749
Resistor, small symbol - 50 | R24 | Resistor_SMD:R_0603_1608Metric | C844932
Diode - D | D16,D15 | Diode_SMD:D_SOD-123 | C81598
Resistor, small symbol - 73.2k | R1 | Resistor_SMD:R_0402_1005Metric | C26986
Unpolarized capacitor, small symbol - 15nf | C31 | Capacitor_SMD:C_0402_1005Metric | C114405
- LTC2954ITS8-1#TRPBF | U3 | LTC2954:TSOT-23_TS8_LIT | C683782
Generic connector, single row, 01x06, script generated - JST 6pin connector - SM06B-SRSS-TB | J6 | Connector_JST:JST_SH_BM06B-SRSS-TB_1x06-1MP_P1.00mm_Vertical | C160392
Polarized capacitor, small symbol - 4.7uF | C26 | Capacitor_SMD:CP_Elec_4x5.4 | C970651
Resistor, small symbol - 33 | R31,R30 | Resistor_SMD:R_0402_1005Metric | C25105
Unpolarized capacitor, small symbol - 4.7uF | C15,C16 | Capacitor_SMD:C_1206_3216Metric | C29823
Ferrite bead, small symbol - 120Ω@100MHz | FB1 | Inductor_SMD:L_1206_3216Metric | C85841
Intelligent 9-axis absolute orientation sensor, LGA-28 - BNO055 | U2 | Package_LGA:LGA-28_5.2x3.8mm_P0.5mm | C93216
USB 2.0-only 16P Type-C Receptacle connector - USB_C_Receptacle_USB2.0_16P | J7,J2 | Connector_USB:USB_C_Receptacle_HCTL_HC-TYPE-C-16P-01A | C165948
- CM4102008 | M1,M2 | CM4102008:MODULE_CM4102008 | C597931
Unpolarized capacitor, small symbol - 10nF | C24 | Capacitor_SMD:C_0402_1005Metric | C15195
0.3mm 0.5mm 2mm 30P FPC Connector - ~ | J5 | FPCCONN:TE_3-1734592-0 | C375905
Schottky diode - SS210 | D21 | Diode_SMD:D_SMA | C14996
Resistor, small symbol - 49.9k | R2 | Resistor_SMD:R_0402_1005Metric | C2906873
Resistor, small symbol - 1.8M | R25 | Resistor_SMD:R_0402_1005Metric | C38587
400W unidirectional Transient Voltage Suppressor, 5.0Vr, SMA(DO-214AC) - SMAJ5.0A | D19 | Diode_SMD:D_SMA | C10758
Resistor, small symbol - 5.1 | R35 | Resistor_SMD:R_0402_1005Metric | C412902
Resistor, small symbol - 4.7k | R4,R46 | Resistor_SMD:R_0402_1005Metric | C25900
10uF 50v - 10uF | C7,C6 | Capacitor_SMD:C_1206_3216Metric | C13585
Two pin crystal - 32.768kHz | Y1 | Crystal:Crystal_SMD_3215-2Pin_3.2x1.5mm | C32346
Resistor, small symbol - 6.04k | R22 | Resistor_SMD:R_0402_1005Metric | C97819
Unpolarized capacitor, small symbol - 22pF | C13,C12 | Capacitor_SMD:C_0402_1005Metric | C1555
Resistor, small symbol - 3.09k | R3 | Resistor_SMD:R_0402_1005Metric | C11460
Resistor, small symbol - 44.2k | R9 | Resistor_SMD:R_0402_1005Metric | C25895
- FH12-22S-0.5SH55 | J8 | CSI22CONN:CONN_FH12-22S-0.5SH55_HIR | C597981
Inductor - 22uH | L1 | Inductor_SMD_Wurth:L_Wurth_WE-LQSH-3012 | C41405943
Unpolarized capacitor, small symbol - 220pF | C10 | Capacitor_SMD:C_0402_1005Metric | C1530
Generic connector, single row, 01x02, script generated - Battery | J4 | Connector_JST:JST_PH_B2B-PH-SM4-TB_1x02-1MP_P2.00mm_Vertical | C160352
- LM51571RTER | U8 | LM5171Q1:LM51571 | C3188430
Very low capacitance ESD protection diode, 2 data-line, SOT-23-6 - USBLC6-2SC6 | U7 | Package_TO_SOT_SMD:SOT-23-6 | C2687116

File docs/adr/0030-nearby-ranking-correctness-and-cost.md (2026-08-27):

# Nearby objects: a (Dec, RA) haversine index, queried as a bounded window, with the cursor bound to the pointing

Two features ask the same question — *which catalog objects are near where the
scope points?* The object list's **Nearby** sort wants them ranked, nearest
first; the chart's **nearby-DSO marker layer** wants everything inside the
current field. Both are served by `ClosestObjectsFinder` in
`PiFinder/nearby.py`, and both run against the live pointing while the user
slews.

That last part sets the constraints. The answer must be correct at *any*
declination, not just near the equator where most testing happens. It must be
cheap enough to compute inside the 30 Hz draw loop on a Pi. And it must decide
what the list does when the answer changes under the user's hands.

## Index the sky as `[dec, ra]`, in radians, haversine

The spatial index is a scikit-learn `BallTree` with `metric="haversine"`. That
metric is documented for geographic coordinates: **dimension 0 is latitude,
dimension 1 is longitude**. Declination is the latitude; right ascension is the
longitude. So rows are `[dec_rad, ra_rad]`, and every query point must be built
the same way.

This is written down because the argument order is invisible at the call site —
it is two floats in a list, and the wrong order raises nothing. Worse, the
mistake hides: when two objects share a meridian the metric degenerates to
`|dec1 - dec2|`, which is right whichever way round the axes go. Any test or
spot-check that keeps RA fixed will pass on a swapped index. **Treat a
same-meridian check as no check at all** — exercise this code with objects at
different RAs and at high declination, where a swapped axis order is loudest.

The alternative was to drop the index: compute a vectorised haversine over all
objects and `argsort`. Measured at 0.9 ms (14 000 objects) against the tree's
1.5 ms — no meaningful gain, and it gives up `query_radius`, which is what the
chart layer actually needs (bounded by angular distance, not by count). Keep
the BallTree.

## The Nearby list is a bounded window, not a total ordering

`get_closest_objects` accepts `n=0` meaning "rank everything", and the object
list used to take it. Ranking the whole catalog to draw about nine rows costs
O(N) twice over: once in the k-NN query, and again in the cursor-tracking
helper that rebuilds a `(catalog_code, sequence)` dict over the new ordering in
pure Python.

| N | k = N query | k = 200 query | cursor helper |
|---|---|---|---|
| 14 000 | 1.5 ms | 0.09 ms | 7.6 ms |
| 40 000 | 4.4 ms | 0.13 ms | 22 ms |

(Measured on a fast dev machine; a Pi is roughly an order of magnitude slower,
against a 33 ms frame budget.)

The cost is inherent to producing a *total* ordering — the vectorised
alternative above measured no better. It can only be avoided, so the decision
is to avoid it: `NEAREST_LIST_CAP = 200`, and the object list queries
`k = min(cap, N)`. Everything downstream is then bounded by the cap rather than
by catalog size, which is what keeps the re-rank off the frame budget.

**The trade-off:** a Nearby-sorted list no longer scrolls down to the object on
the far side of the sky. An object 140° away is not "nearby" under any reading,
and paying O(N) on every degree of slew to keep that tail reachable is the
wrong bargain. Catalog and RA sort still expose the full set.

Lazily extending the window as the user scrolls past 200 was considered and
rejected: it buys back an ordering with no observing use, at the cost of
carrying a paging state machine through the re-rank path.

`n=0` stays supported for callers that genuinely want everything, but the cap
is the default posture for anything drawing a list.

### Two lengths, and which one each caller means

Capping makes explicit something the screen already half-had: the list the user
navigates is not the same length as the catalog behind it. (Even before the cap,
`deduplicate_objects` merged listings sharing an `object_id`, so the ranked list
was already the shorter of the two.)

`UITextMenu.get_nr_of_menu_items` counts `_menu_items`, the source list.
`UIObjectList` overrides it to count `_menu_items_sorted`, because **that** is
what the screen draws, scrolls, opens and serialises. Anything addressing a row
— cursor clamping, the scrollbar, opening the focused object, the serialised
selection — must use the length of the list it is indexing, or the cursor can
address rows that do not exist. Long-DOWN to "the end" is the case that finds
this immediately.

The catalog's own object count is a *different* quantity, and it stays the
source length: it is reported in `catalog_info_1` for the header, where the user
is being told how big the catalog is, not how far the carousel scrolls.

Two consequences worth stating, because both were latent and are now reachable:
a sort may legitimately produce an empty list while the source is non-empty, so
the scrollbar must tolerate a zero count; and the in-frame re-rank must not run
before the spatial index has been built for the current list, or it replaces a
populated list with an empty one mid-draw. `Nearby.should_refresh` answers False
until the index is ready, which keeps the explicit `sort()` path the only thing
that can empty the list.

## Staleness is measured on the sky, not per axis

The ranking is recomputed when the pointing has moved far enough to change it.
"Far enough" is a **great-circle separation** from the pointing the current
ranking was built at (`great_circle_degrees`), compared against
`MAX_DEVIATION = 1.0` true degrees.

Per-axis RA/Dec degrees are not a usable proxy for this, and the reason is
worth recording because the cheaper test looks reasonable:

* One degree of RA spans `cos(dec)` degrees on the sky — 0.17° at Dec 80°,
  0.017° at Dec 89°. A per-axis threshold therefore re-ranks for movement the
  user cannot see, and does so exactly where slewing is slowest and a stall is
  most visible.
* RA wraps. A test on raw difference reads the step from 359.5° to 0.5° as 359,
  so it fires continuously in a band around the meridian.

Neither failure loses a refresh, so neither is visible as wrong output — they
are pure cost, which is why a per-axis test can sit unnoticed. The great-circle
form has no such blind spot and costs one `arccos`.

A second trigger re-ranks after `MAX_TIME = 10` s regardless of pointing. Its
job is *not* pointing changes — the deviation test owns those. It exists to pick
up catalog and filter changes and altitude drift. Sized from the sky's 15°/hour:
10 s bounds the drift error to ~0.04°, far inside anything the list expresses.
A shorter cadence buys nothing and re-ranks a stationary scope for no reason.

## The top row follows the pointing; a scrolled cursor follows the object

A Nearby list is rebuilt for two different reasons, and the user's intent
differs between them.

A **filter-driven** rebuild — the user logged an object, or tightened the
magnitude or altitude filter — should hold the cursor on the selected object, or
on the first of its old successors that survived. That is the natural next
target, and it is what `_next_target_index` exists for (see the filter-freshness
ADR).

A **pointing-driven** re-rank is the opposite case. The user slewed the scope
*in order to change what is nearest*. Carrying the cursor along with the
previously selected object works directly against that: the focused row drifts
down the ranking, away from what they just pointed at.

The decision splits the two:

* While the cursor sits on the top row, a pointing-driven re-rank keeps it
  there. The focused object is the nearest object, which is what the mode is
  for.
* Once the user scrolls off the top they are browsing, and the cursor pins to
  their selected object as it migrates through the ranking. Scrolling back to
  the top re-arms the tracking.
* Filter-driven rebuilds keep the pinning behaviour unconditionally.

This needs no new state and no user-facing setting: "the user has not scrolled"
is exactly `_current_item_index == 0`, read before the list is replaced.
Rejected alternatives: always reset to the top (destroys browsing — the list
becomes unusable as anything but a readout), and always pin to the object
(the behaviour this replaces).

## One rebuild policy for the spatial index

The tree is rebuilt only when the object set behind it changes, guarded on the
catalog filter's `dirty_time` — the same key `UIChart` already uses for its own
nearby-marker index. `dirty_time` does not cover a list rebuilt from source, so
`refresh_object_list` invalidates the index explicitly. Two consumers, one
policy, so a filter edit cannot leave the list and the chart disagreeing about
what is on the sky.

## Consequences

* Correctness no longer depends on where the scope is pointed. The chart layer
  gains more from this than the list does: a marker that is silently absent from
  the field is not something the user can notice.
* Per-refresh work is bounded by `NEAREST_LIST_CAP` rather than catalog size,
  which is what allows the re-rank to stay on the draw path at all.
* Nearby lists are truncated to 200 objects — the one behaviour a user may
  experience as a loss.
* Sort orders must each be given a branch in `sort()` *and* an entry in
  `_sort_order_label`. Both labels route through that one helper so a mode
  cannot be displayed under another mode's name.

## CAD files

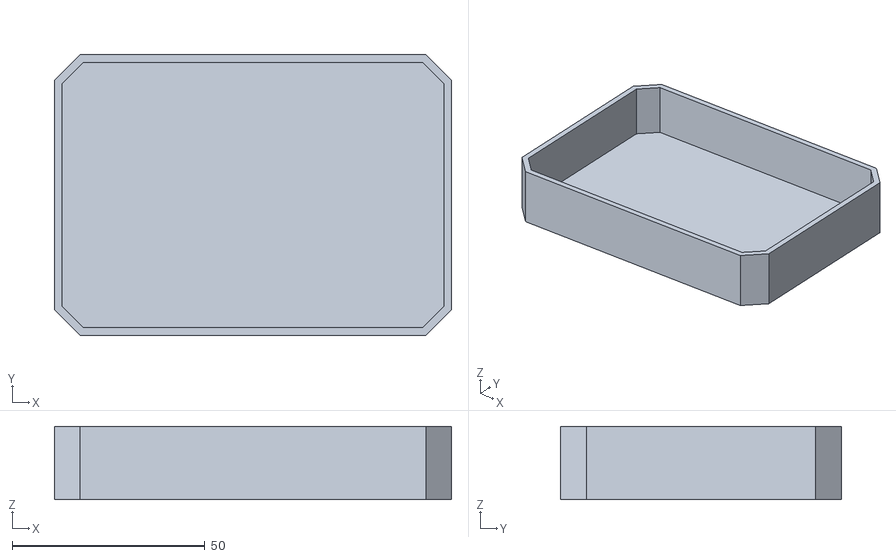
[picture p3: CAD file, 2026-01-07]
case/accessories/screen_cover_v2x.stl
103.1 x 72.8 x 19.0

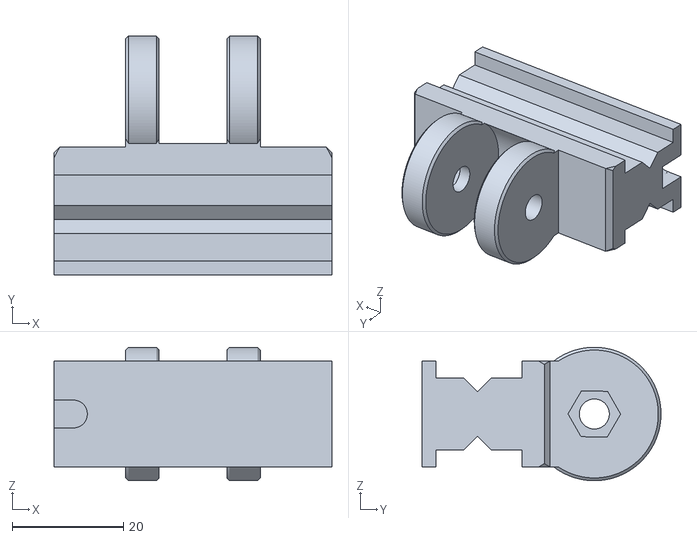
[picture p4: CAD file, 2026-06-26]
case/adapters/dovetail_meade_lxd.stl
50.0 x 43.0 x 24.0

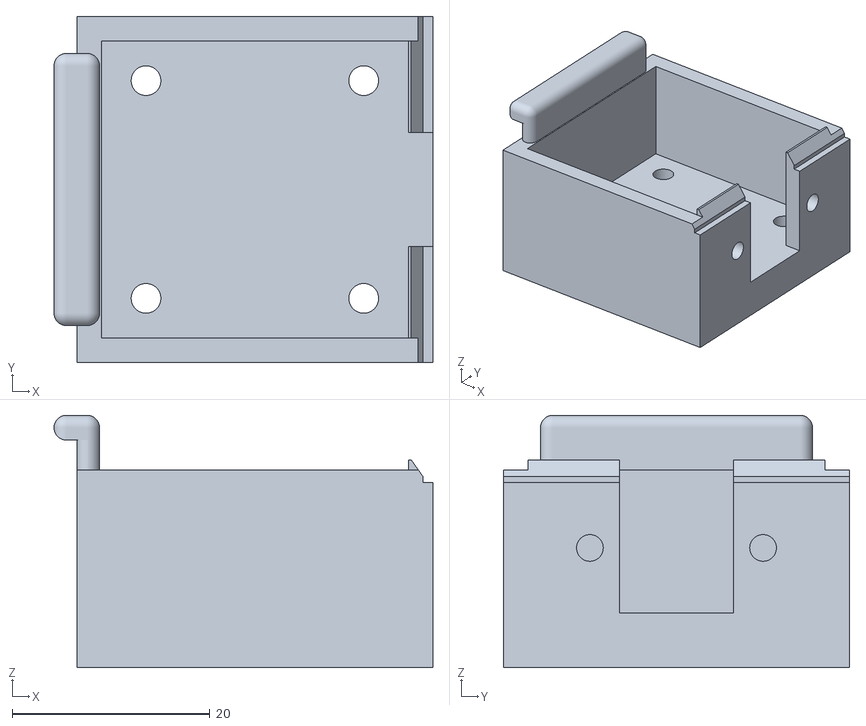
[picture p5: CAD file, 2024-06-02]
case/adapters/quikfinder/PiToQuikfinder v2 - Part 1.stl
38.3 x 35.0 x 25.5

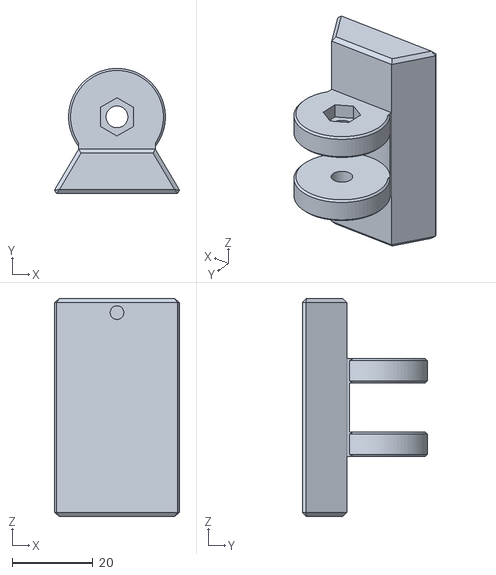
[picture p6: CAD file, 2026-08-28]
case/rev4/dovetail_bottom.stl
31.0 x 31.0 x 54.0

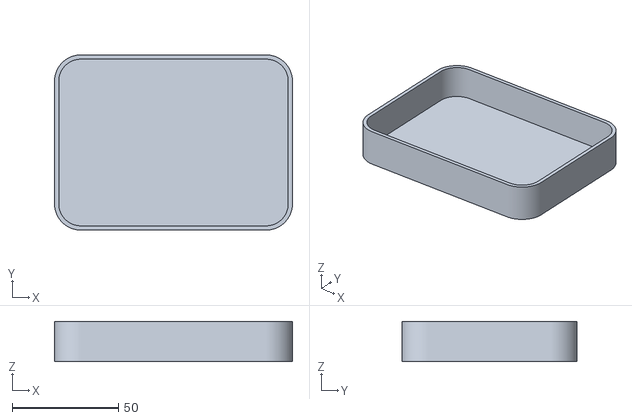
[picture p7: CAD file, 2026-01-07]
case/accessories/screen_cover_v3.stl
111.8 x 82.3 x 19.0

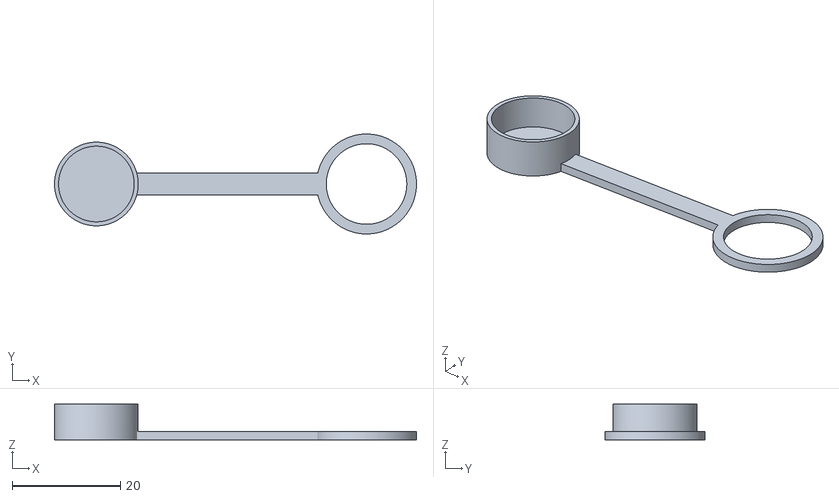
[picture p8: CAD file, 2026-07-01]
case/accessories/tethered_lens_cap/Tethered Lens Cap.stl
67.0 x 18.5 x 6.60

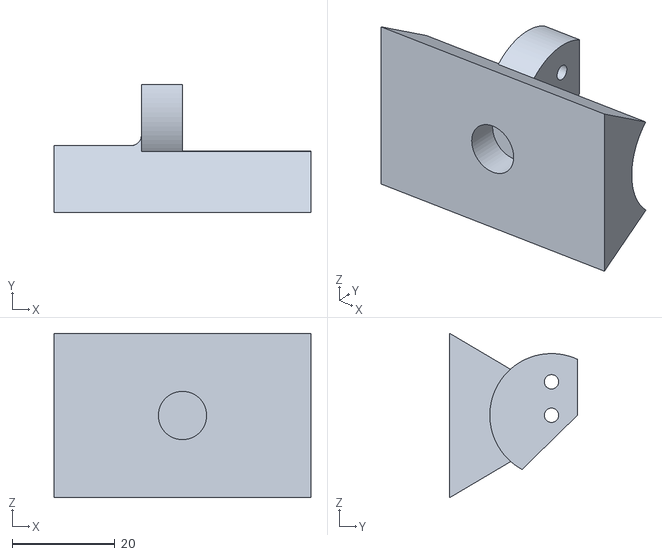
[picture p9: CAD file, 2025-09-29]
case/adapters/dovetail_bottom_tripod.stl
50.0 x 24.9 x 32.0

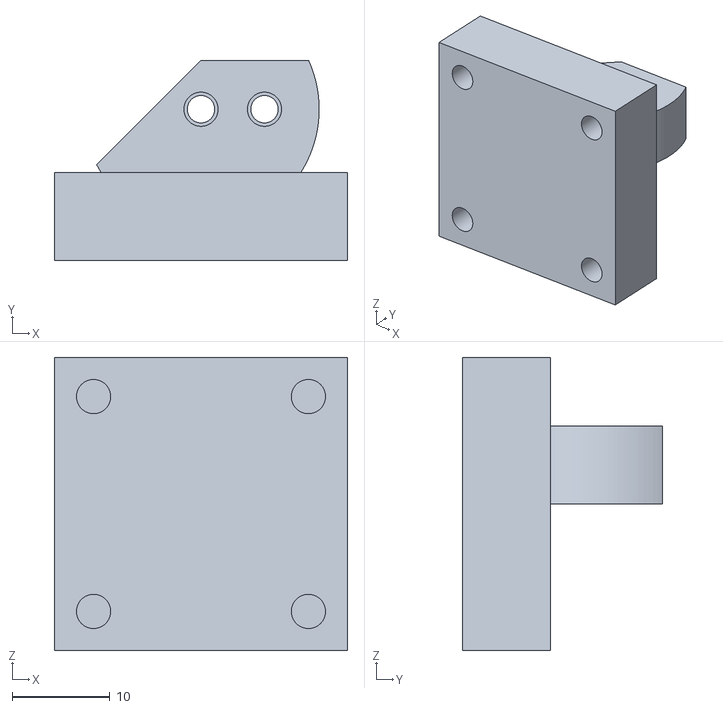
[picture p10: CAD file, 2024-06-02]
case/adapters/quikfinder/Pi2Q2Dovetail.stl
30.0 x 20.5 x 30.0

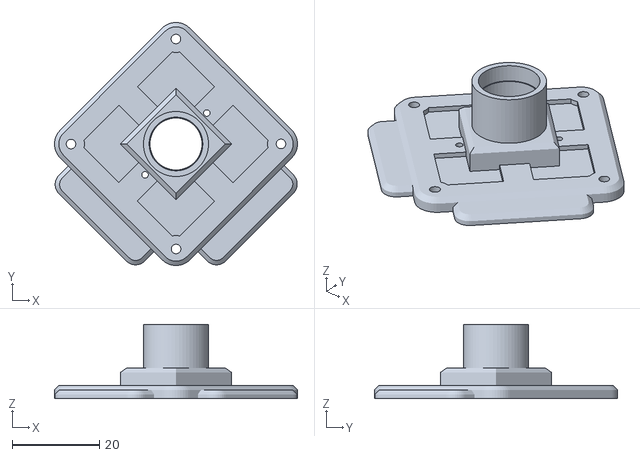
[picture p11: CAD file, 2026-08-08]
case/rev4/camera_hold_down.stl
55.6 x 55.6 x 17.0

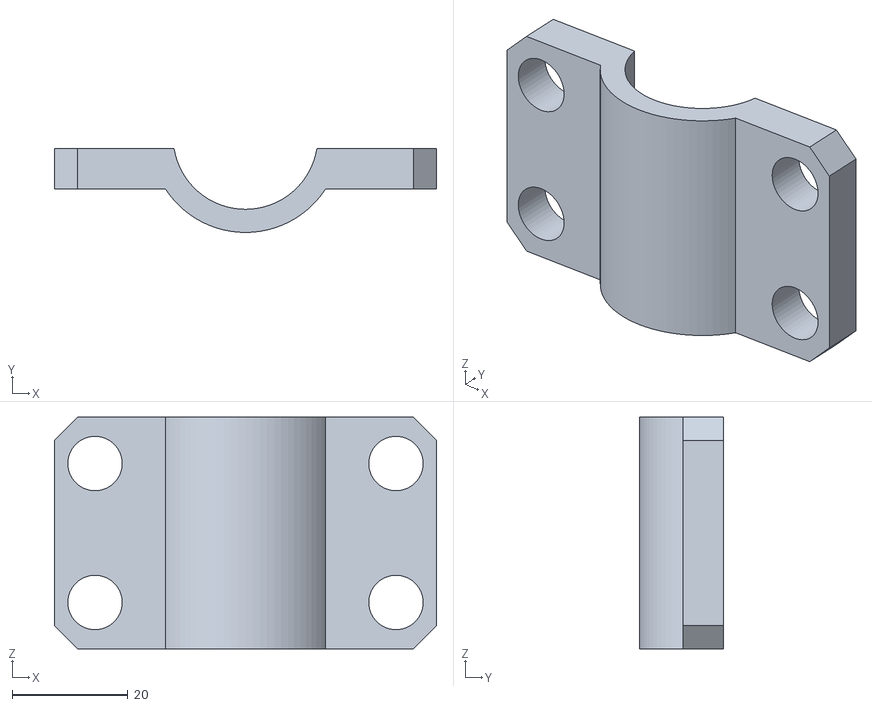
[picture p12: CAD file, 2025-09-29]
case/accessories/tube_shoe_mount_25mm_bottom.stl
66.0 x 14.5 x 40.0

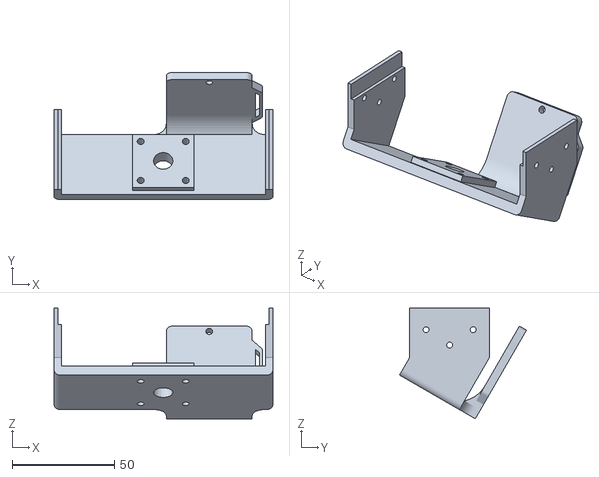
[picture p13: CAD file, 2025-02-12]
case/adapters/flat30_adapter_tripod.stl
107.0 x 62.1 x 54.0

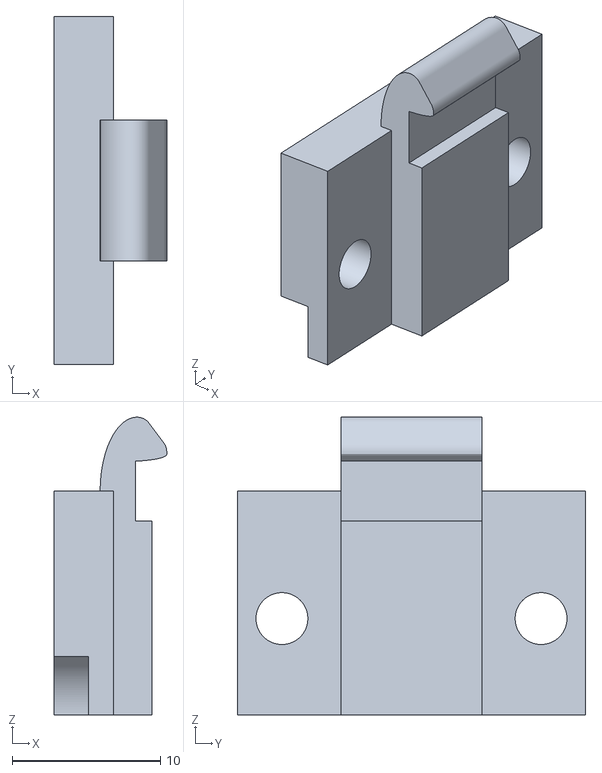
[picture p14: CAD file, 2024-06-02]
case/adapters/quikfinder/PiToQuikfinder v2 - Part 2.stl
7.60 x 23.5 x 20.1

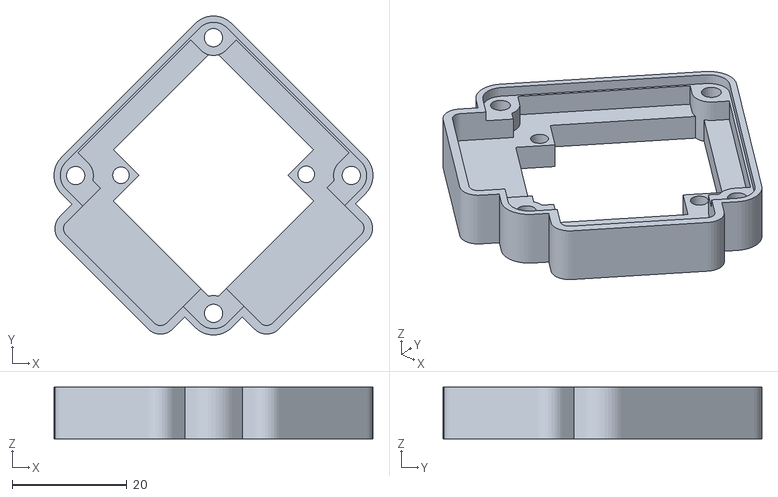
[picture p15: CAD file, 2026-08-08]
case/rev4/camera_tray.stl
55.6 x 55.6 x 9.00

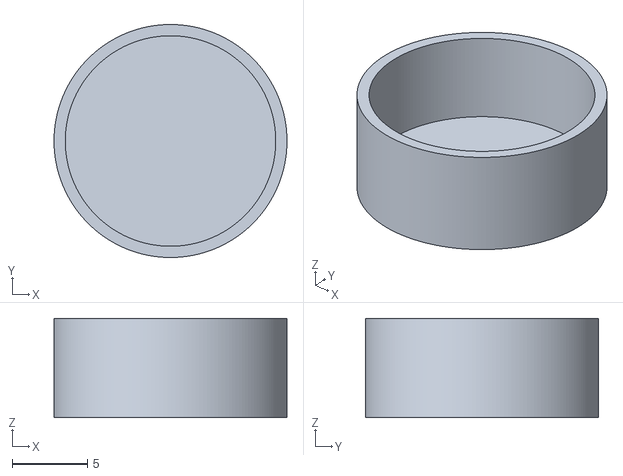
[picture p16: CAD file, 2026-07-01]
case/accessories/tethered_lens_cap/Lens Cap - TPU.stl
15.5 x 15.5 x 6.60

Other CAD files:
case/accessories/tube_shoe_mount_38mm_bottom.stl
case/adapters/flat30_adapter_sidemount.stl
case/rev4/case.stl
case/accessories/tethered_lens_cap/Lens Cap - PETG.stl
case/PiFinder_rev4.f3z
case/PiFinder_v3.f3d
case/accessories/90_degree_dovetail.stl
case/accessories/tethered_lens_cap/Jam Nut - Loose.stl
case/accessories/tethered_lens_cap/Jam Nut - Snug.stl
case/accessories/tethered_lens_cap/Threaded Lens Holddown.stl
case/accessories/tube_shoe_mount_22mm_bottom.stl
case/accessories/tube_shoe_mount_22mm_top.stl
case/accessories/tube_shoe_mount_25mm_top.stl
case/accessories/tube_shoe_mount_30mm_bottom.stl
case/accessories/tube_shoe_mount_30mm_top.stl
case/accessories/tube_shoe_mount_32mm_bottom.stl
case/accessories/tube_shoe_mount_32mm_top.stl
case/accessories/tube_shoe_mount_38mm_top.stl
case/accessories/vixen_right_angle.stl
case/adapters/dovetail_losmandy.stl
case/rev4/bezel.stl
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

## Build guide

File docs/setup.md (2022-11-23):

General Pi Setup
* Clock stretching - https://learn.adafruit.com/circuitpython-on-raspberrypi-linux/i2c-clock-stretching
**  Maybe not needed any longer with updated firmware?  Need to test

Packages
* timezonefinder
* Blinka - required to use BNO-055 circuitpython driver

Data
* Stellerium constellation data
* Hipparcos catalog - https://cdsarc.cds.unistra.fr/ftp/cats/I/239/hip_main.dat

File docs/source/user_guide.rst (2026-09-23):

======================
PiFinder™ User Manual
======================

.. note::
   This documentation covers rev4, v3 and v2.5 PiFinders running software |min_software| or
   above.  You can see which version you're running in the upper right of the welcome screen.

   Not sure which you have?  See
   :ref:`Which PiFinder do I have? <quick_start:which pifinder do i have?>` in the Quick
   Start.

   For docs covering a previous version, see
   `1.x.x <https://pifinder.readthedocs.io/en/v1.11.2/index.html>`_,
   `2.0.x <https://pifinder.readthedocs.io/en/v2.0.4/index.html>`_ or
   `2.1.x <https://pifinder.readthedocs.io/en/v2.1.1/index.html>`_.

Thanks for your interest in the PiFinder!  This guide describes how to use one.  To build
one, see the :doc:`Build Guide <build_guide>` and the :doc:`Bill of Materials <BOM>`.

The manual has sections you can reach from the links to the left.  Let's dig into what the
PiFinder can do.

How It Works
===============

The PiFinder is a self-contained telescope positioning device.  It tells you where your
telescope is pointed, lets you select an object such as a galaxy or another deep-sky
object, and directs you on how to move the telescope to find it.  It has other useful
features alongside these core functions, but its main purpose is to get interesting objects
into your eyepiece for a look.

To direct you, the PiFinder needs to know where your telescope is pointed.  It works this
out directly.  It photographs the night sky and examines the star patterns to determine
which section of sky it sees.  It does this quickly, up to 20 times per second, and very
accurately.  This only works while the telescope is still, so the PiFinder pairs the camera
with an accelerometer that estimates how far the telescope has moved since the last solve.
The Status screen and the Settings menu call this sensor the IMU.  The estimate carries
some error, but the moment you stop, a fresh photo corrects it.  The PiFinder works out its
own orientation as it solves, so you can mount it at any angle.  It does not need to sit
upright, as long as the camera points the same way as your telescope.

The PiFinder knows where your telescope points and where thousands of interesting objects
sit, so it can show you how to move the telescope to bring any of those objects into your
eyepiece.  Because it measures where the telescope actually points, you can trust its
guidance.

.. note::
   For a general overview of using the PiFinder, read the :doc:`quick_start`.  This manual
   goes deeper but doesn't cover the first-time set-up steps in the Quick Start.

The Menu System
=====================================

You reach all of the PiFinder's functions through its menu system:

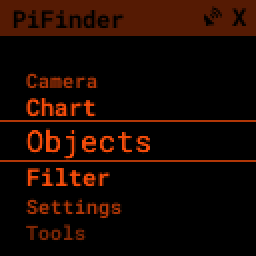
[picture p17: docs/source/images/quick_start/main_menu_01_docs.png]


Each menu is a list of items.  A menu item leads to a submenu, a screen, or a set of
options.  Scroll through a menu and select items with these keys:

.. This key list is duplicated in quick_start.rst (Using the PiFinder).  Keep the two in sync.

- The **UP** and **DOWN** arrows scroll the current menu
- The **RIGHT** arrow selects the current menu item, which either sets an option or opens another menu
- The **LEFT** arrow takes you back to the previous menu or screen
- Press and hold **LEFT** for more than a second to jump back to the TOP of the menus
- **RIGHT** is also the confirm key.  On a screen that asks you to confirm, such as
  :ref:`user_guide:shutdown`, **RIGHT** selects the highlighted option and **LEFT** goes back
- **SQUARE** does not confirm.  Press and hold it to open the :ref:`user_guide:quick menu`.
  A short press does whatever the screen you're on uses it for, such as cycling through
  extra information

The arrows are the four directions of the joystick.  Pressing the joystick straight in does
the same as the **SQUARE** key, and holding it in opens the Quick Menu.  To confirm, press
**RIGHT**.

.. note::
   On v3 and v2.5 PiFinders the arrows are four separate buttons in a row along the bottom
   of the keypad rather than a joystick.  The key names are the same on both.
   |v3_docs|

The status bar at the top of the screen shows the name of the menu you're viewing.

For a bird's-eye view of every menu and what each menu item does, see the
:doc:`menu_map`.

Screens
--------

Some menu items, like Camera, lead to a specific screen: a camera preview, a star chart, or
details about a catalog object.  The sections below cover each screen in more detail.

Options
--------

Some menus present a list of options where you select one or more items to control how the
PiFinder operates.  For instance, the Set Filters menu item takes you to a sub-menu of ways
to filter your object lists:

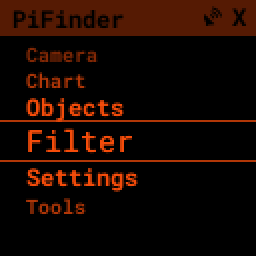
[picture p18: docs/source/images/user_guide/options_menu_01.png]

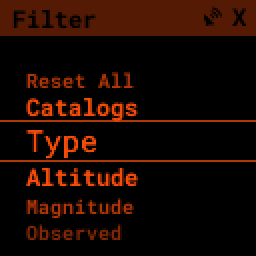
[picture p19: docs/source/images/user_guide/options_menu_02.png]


Select Type to see the deep-sky object types you can use to control which objects appear in
your object lists.

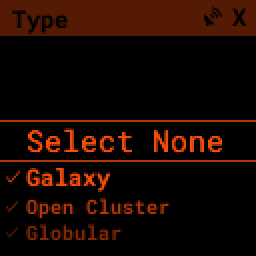
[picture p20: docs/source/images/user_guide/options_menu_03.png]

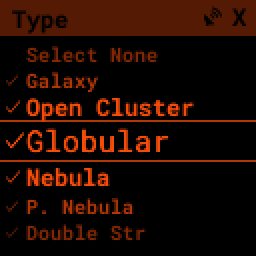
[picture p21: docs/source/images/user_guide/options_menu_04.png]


Lists that offer selections show a check-mark next to each selected option.  Press
**RIGHT** with an option highlighted to select or de-select it.


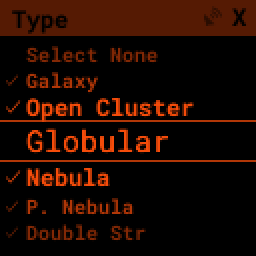
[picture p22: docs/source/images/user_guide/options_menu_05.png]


In menus that allow only a single selection, such as Altitude, selecting one option
de-selects any others.  Multi-Select menus offer options to select or de-select all items
at once.

When you're done, press **LEFT** to go back to your last menu or screen.

With this simple set of scroll-and-select tools you can reach all of the PiFinder's
features.

Quick Menu
-------------------------------------

You can reach everything through the menu system.  A secondary quick-menu brings some
functions into easier reach.

Press and hold **SQUARE** to open the Quick Menu.

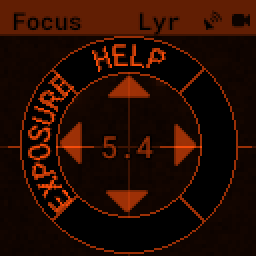
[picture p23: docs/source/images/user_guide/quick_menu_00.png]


This menu presents up to four options, one per arrow button.  Press an arrow to select its
item.  The menu changes with the screen you're on, but it often has
:ref:`HELP<user_guide:help system>` at the UP option.

Some Quick Menus have a second layer.  The Object List's Quick Menu, for example, offers
Sort and Filter.  Press **LEFT** for Sort to open a ring of sort orders, with subtle
shading marking the current one.

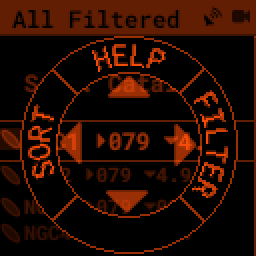
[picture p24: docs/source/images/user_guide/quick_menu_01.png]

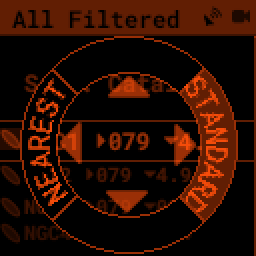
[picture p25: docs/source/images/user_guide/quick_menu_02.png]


Select a sort order to apply it.  To exit the Quick Menu at any time, press **SQUARE**
again.

Help System
--------------

Many screens offer help with their button functions, and with other details about how
things work or what a screen is for.

When available, HELP is the UP option in the Quick Menu



Press **UP** to select help.  Help opens one or more pages.  A prompt at the top or bottom
of the screen shows when more pages are available.  Press **UP** or **DOWN** to scroll
through them.

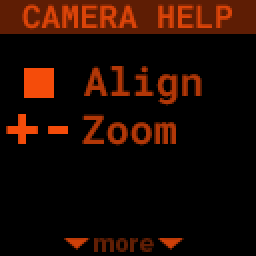
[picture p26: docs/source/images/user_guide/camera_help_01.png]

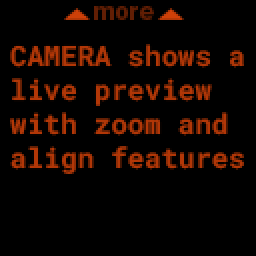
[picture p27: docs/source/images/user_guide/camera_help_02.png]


Observing with PiFinder
========================

Out under the stars, you do four basic things in various combinations:

* Curating a list of objects you're interested in
* Viewing details about those objects
* Pushing the telescope to bring them into your eyepiece
* Logging your observations

Everyone observes their own way, so use the features you want and skip the rest.

Object List
--------------------

The Object List is one of the PiFinder's main features.  It presents a collection of
objects you've selected using catalogs, filters, observing lists, and text search.

To start a list, select Objects from the main PiFinder menu, then select one of five menu
items:

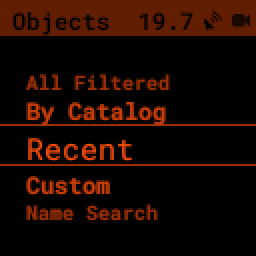
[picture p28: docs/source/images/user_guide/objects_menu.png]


- **All Filtered**: All objects across all catalogs that meet your
  :ref:`filter criteria<user_guide:filters>`.  This could be thousands of objects, and it
  is most useful with strict filters, such as globulars above 30 degrees altitude and
  brighter than magnitude 10.
- **By Catalog**: All objects from a specific catalog that meet your filter criteria.  Great
  for observing projects and finding the nearest objects in a particular catalog.
- **Recent**: Starts empty and builds a history of the objects you've looked at during
  the current session.
- **Custom**: Enter a right ascension and declination by hand to make a one-off Custom Target.
  See :ref:`user_guide:custom targets`.
- **Name Search**: Search for objects by name with the number keypad.  The Snowball planetary?
  Cat's Eye?  This is the way to find them.

However you build the list, it always displays the same information and offers the same
sorting and selection.

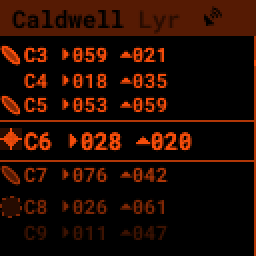
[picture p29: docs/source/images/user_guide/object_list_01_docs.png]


A symbol along the left shows each object's type.  Next to it is the designation, usually
the catalog abbreviation and index number, then the distance from your current telescope
position.  Each entry's brightness hints at its magnitude.

Press **SQUARE** to cycle through additional information for the objects on the list.

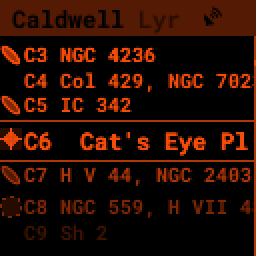
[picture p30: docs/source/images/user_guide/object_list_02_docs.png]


You can see a scrolling list of common names for each object.

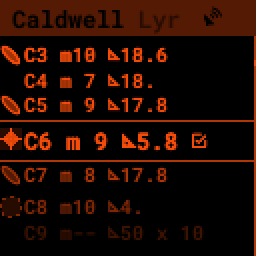
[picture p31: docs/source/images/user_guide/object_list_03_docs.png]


The next press shows the magnitude and size of each object, with a check mark to indicate
whether you've observed and logged it before.

Press and hold **SQUARE** to open the Quick Menu, where you can sort and filter this list.

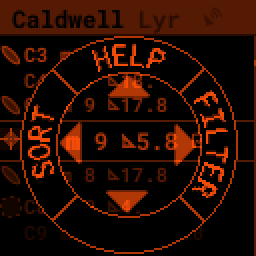
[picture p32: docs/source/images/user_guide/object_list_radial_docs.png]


Press **LEFT** to select SORT

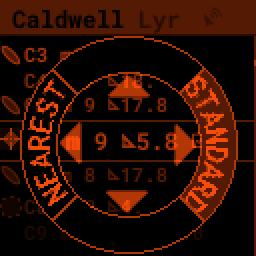
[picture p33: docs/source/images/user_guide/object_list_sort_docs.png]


By default, lists use STANDARD order.  That is usually the order the objects appear in the
catalogs.  Press the indicated arrow to select another order such as NEAREST, which puts
the object closest to your current telescope position at the top.

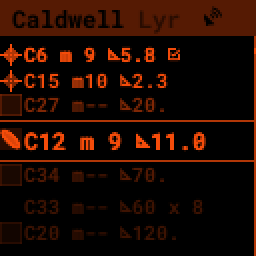
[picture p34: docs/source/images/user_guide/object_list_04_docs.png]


If you start typing a number, the Object List jumps to the next object with that index
number.  Press the **UP/DOWN** arrows to step to the next or previous match.  Press
**SQUARE** to exit jump mode and select an object.

Press **RIGHT** to open the details for the selected object.

Object Details
--------------------

Press **RIGHT** from the Object List to open the Object Details screen for the highlighted
object.  This screen shows large Push-To instructions,
:ref:`object images<user_guide:object images>`, and catalog details.

Press **SQUARE** to cycle through the object's information.  Press **UP/DOWN** to move to
the next or previous object in the list.  **LEFT** goes back to the full list, and
**RIGHT** opens the :ref:`Logging<user_guide:logging observations>` interface for the
current object.

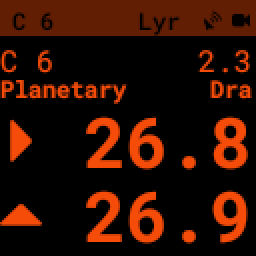
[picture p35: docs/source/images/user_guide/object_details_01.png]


The Push-To information shows which way, and how far, to move your telescope to put the
object in your eyepiece.  As you move the telescope the numbers dim, which means the
PiFinder is using the accelerometer to estimate where the telescope points.  When you stop,
or move slowly enough, the camera plate solves to give an absolute position and the numbers
brighten again.

When the numbers are near 0.00 the object should be in your eyepiece.  The numbers are the
distance to the object in degrees, so with an eyepiece offering a 0.5 degree true field of
view, getting them below 0.25 (half the true field) should put the object in view.

Closer to zero means more centered.  For a very dim object, knowing it's dead center and
consulting the object image can make all the difference.

.. note::
   By default the Push-To arrows guide you in altitude and azimuth, the way an Alt/Az or
   Dobsonian mount moves.  On an equatorial mount, set Mount Type to Equatorial in the
   :ref:`user_guide:settings menu`.  The guidance then switches to right ascension and
   declination to match your mount's axes.

   Leave Mount Type on Alt/Az if you use an alt-az telescope on an equatorial tracking
   platform.  You still move the telescope in altitude and azimuth, and the PiFinder
   corrects for the platform's rotation on its own.

The number in the upper right is the object's
:ref:`contrast reserve <user_guide:contrast reserve>`.  It estimates how easily the object
should show in your eyepiece tonight.

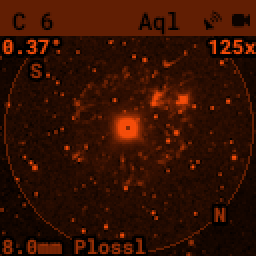
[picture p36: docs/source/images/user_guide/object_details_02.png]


The PiFinder can show images of all the extended objects in its catalogs.  See the section on
:ref:`object images<user_guide:object images>` below for more.

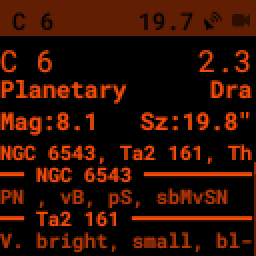
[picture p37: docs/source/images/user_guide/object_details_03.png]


Depending on the catalog, the PiFinder may have detailed notes alongside the object's type,
constellation, magnitude, and size.  It gives the size in degrees, arcminutes, or
arcseconds, whichever best suits the object.  Use the **+/-** keys to scroll the notes.

Many objects carry more than one catalog designation, and the notes can gather a description
from each.  A bright horizontal rule labelled with the catalog and number, for example
*NGC 6543*, separates one catalog's notes from the next, so you can see at a glance where
each note comes from.  The notes finish with a count of how many times you've logged the
object, marked by its own rule (it reads *Not Logged* until your first sighting).

What each part of the screen shows
^^^^^^^^^^^^^^^^^^^^^^^^^^^^^^^^^^^

The Object Details screen packs a lot in.  These two views label every part.  The first is
the Push-To screen.  The second is the catalog details you reach by pressing **SQUARE**.

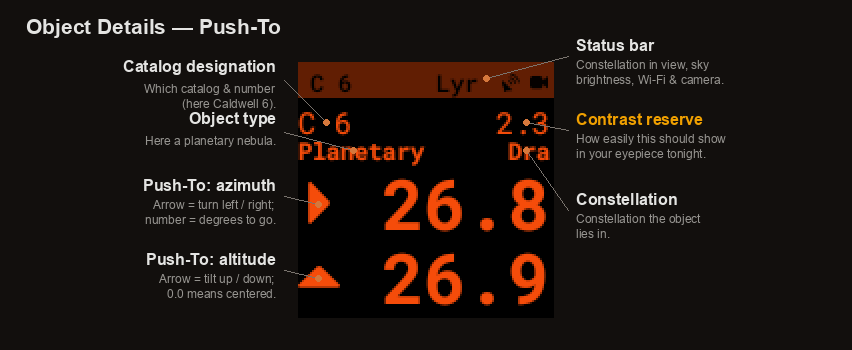
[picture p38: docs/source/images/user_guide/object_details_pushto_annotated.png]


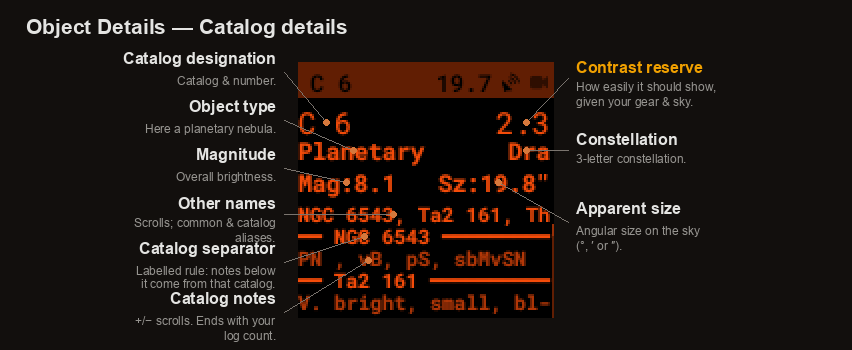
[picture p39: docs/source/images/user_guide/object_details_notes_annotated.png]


Contrast Reserve
^^^^^^^^^^^^^^^^^

The number in the upper right of the Object Details screen is the **contrast reserve**.  It
estimates how easily an object should stand out in your eyepiece.  It weighs the object's
brightness and size against your sky brightness, your telescope's aperture, and the
magnification of your active eyepiece, then compares the result to what the eye can detect.
A higher number means the object should be easier to see.

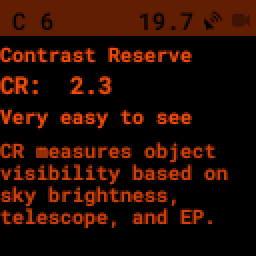
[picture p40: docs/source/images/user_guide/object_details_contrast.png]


Keep pressing **SQUARE** to reach the Contrast Reserve page, which shows the value on its
own with a plain-language reading of what to expect:

.. list-table::
   :header-rows: 1

   * - Contrast reserve
     - What to expect
   * - Below −0.2
     - Object is not visible
   * - −0.2 to 0.1
     - Questionable detection
   * - 0.1 to 0.35
     - Difficult to see
   * - 0.35 to 0.5
     - Quite difficult to see
   * - 0.5 to 1.0
     - Easy to see
   * - 1.0 and above
     - Very easy to see

The contrast reserve appears only when the PiFinder has everything it needs to work it out:
an active :ref:`telescope and eyepiece <equipment:choosing your active telescope and eyepiece>`,
a sky-brightness reading, and an object with a known magnitude and size.  If any of these is
missing, the PiFinder leaves the number off.  A double star has no single magnitude, for
example, and the sky brightness is unknown until the camera has estimated it.

.. note::
   The sky-brightness figure comes from the PiFinder's Sky Quality Meter (SQM), its
   camera-based estimate of how dark your sky is.  The contrast reserve therefore tracks
   your real conditions: the same object reads higher under a dark sky than from town.
   Treat it as a guide rather than a guarantee.  Averted vision, transparency, and how
   dark-adapted you are all play their part at the eyepiece.

Sky Quality Meter
------------------

The PiFinder measures how dark your sky is from its own camera.  It reports the result in
magnitudes per square arcsecond, where higher numbers mean darker skies.  To see the
reading, select SQM from the main menu.

The screen shows the current figure in large digits, along with the Bortle class that
describes the same sky in words.  Press **SQUARE** for a plain-language description of what
you can expect to see under a sky of that class.

There is nothing to set up.  The PiFinder recognises its own camera and starts measuring
when you turn it on.  The reading needs no plate solve, so it keeps updating through thin
cloud and through frames with too few stars to solve.

The :doc:`Sky Quality Meter page <sqm>` covers the screen in full, explains what the number
means, and describes the optional calibration wizard: when you need it, how to run it, and
what it changes.

Star Chart
-------------

The Star Chart, reached from the main PiFinder menu, draws a live map of the sky around
where your telescope points, with constellation lines and markers for nearby objects.  It
redraws as you move the telescope, so it is a quick way to see what is around you and
confirm your aim.  Zoom in and out with the **+/-** keys.

Deep-sky objects show as small symbols, one shape per object type.  Near where you point,
the chart marks the objects your :ref:`filters <user_guide:filters>` allow.  It reveals
fainter ones as you zoom in and keeps only the brightest as you zoom out, so the field never
crowds.  The chart also marks objects on a loaded observing list.  To dim these markers, or
switch them off, use the DSO Display setting under Chart... in the
:ref:`user_guide:settings menu`.

A brighter cross marks the object you last opened in :ref:`user_guide:object details`,
wherever you steer.  It is a quick way to see where that object sits relative to your aim.
On the chart the cross carries the object's designation, "M 57" for example.  Once the
object drifts off the edge, an arrow at the rim points the way instead.  The cross stays
bright even with DSO Display turned off.

A line along the bottom of the chart names the center object, the marker nearest the middle
of the chart.  It gives the object's designation and the first other name the catalogs carry
for it, "NGC 7000 North America nebula" for example.  Text too long for the line scrolls
across it.  With RA/DEC Disp. turned on, the
coordinates keep the bottom line and the center object sits just above them.

Press **RIGHT** to open that object's :ref:`user_guide:object details`.  The arrow at the
right of the line is a reminder of that key.  In the details screen, press **LEFT** to come
back to the chart.  Press **UP/DOWN** to step outward through the chart's other markers,
nearest first.

Only markers the chart has drawn can take the line, and only while they are on screen.  The
readout never names something you cannot see.  With DSO Display off, the cross is the only
marker left, so the line goes blank once the cross drifts off the edge.  The readout also
holds its choice until another marker comes clearly closer, so it does not flicker between
two markers as your aim drifts.  To switch the line off, set Center Object to Off under
Chart... in the :ref:`user_guide:settings menu`.  **RIGHT** then does nothing on the chart.

You decide how the chart is turned.  Select Coordinate Sys. under Chart... in the
:ref:`user_guide:settings menu`:

- **Horizontal** (the default) keeps the horizon level and the zenith up, matching what you
  see with the naked eye.
- **EQ (Auto)** lines the chart up with the celestial pole: north-up in the northern
  hemisphere, south-up in the southern.
- **EQ (North-up)** and **EQ (South-up)** force north-up or south-up wherever you are.

The chart labels what is currently at the top, so you always know how it is oriented.  The
labels are "Zenith up", "NCP up" (north celestial pole), and "SCP up" (south celestial
pole).  The same orientation applies to the Align screen.

.. note::
   The chart works before the PiFinder has a GPS fix.  The Horizontal and EQ (Auto) modes
   need to know where you are to orient themselves.  Until GPS locks, or you
   :ref:`enter your location by hand <user_guide:place & time>`, the chart falls back to
   north-celestial-pole-up.  It marks the label with a leading "!", for example "!NCP up",
   to show that the orientation is temporary and settles once your location is known.

Filters
----------

Every object list aside from :ref:`user_guide:name search` and Recent shows only objects
that meet the filter criteria you've set.  View and adjust your filters from the Set
Filters menu, the last item in the Objects menu.

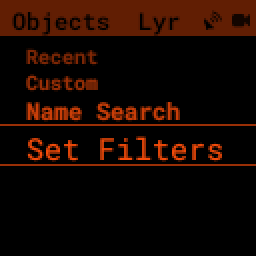
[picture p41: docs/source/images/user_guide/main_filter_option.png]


You can also reach the filter options from the :ref:`user_guide:quick menu` on the Object
List screen.



The Set Filters menu offers several ways to limit which objects appear, plus a Reset All
option to clear every filter.

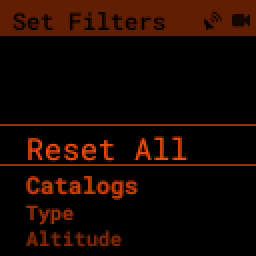
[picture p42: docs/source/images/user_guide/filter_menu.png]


With no filters set, every available object appears.  The All Filtered list then shows over
18,000 objects.

Some filter types take a single value, like Altitude, and some allow multiple selections,
like Object type.  Here's a brief explanation of each:

- **Catalogs**: Limit which catalogs the All Filtered list includes.  This is distinct from
  the catalog-specific object lists, which are a shortcut to one catalog.  Using the
  Catalogs filter, the All Filtered list can show globular clusters across multiple
  catalogs at once.
- **Type**: Limit by object type.  You can select multiple types to include.
- **Altitude**: The current apparent altitude of an object from your observing location.
- **Magnitude**: Limit to objects at least as bright as the selected magnitude.
- **Observed**: Include only objects you've logged, never logged, or any logged state.

Catalogs Filter
^^^^^^^^^^^^^^^^^

The PiFinder has many catalogs, so this menu groups them by category.

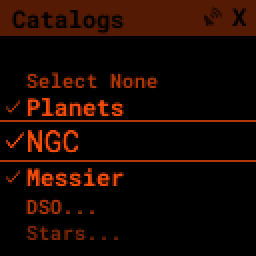
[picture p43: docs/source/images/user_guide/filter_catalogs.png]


Common catalogs appear at the top level for quick reference.  Less common ones sit in
sub-categories marked with an ellipsis (...).

Here's the DSO... category as an example:

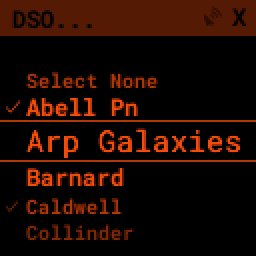
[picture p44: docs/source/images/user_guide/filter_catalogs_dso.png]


Selected catalogs show a check box, and you may see the same catalog, like Messier, in
multiple spots.  Selecting or de-selecting anywhere changes its state everywhere.

Name Search
------------

Name Search is a powerful way to search the PiFinder's large object database.  It finds
objects by their common name, like the Cat's Eye nebula.  To reach the Name Search screen,
select it from the Objects menu:

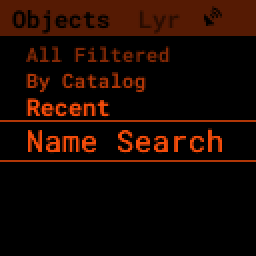
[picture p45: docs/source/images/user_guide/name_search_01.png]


It uses multi-tap text input, like the cellphones from the dawn of text messaging.  The
on-screen keypad shows the letters you get by pressing each number key several times in a
row.

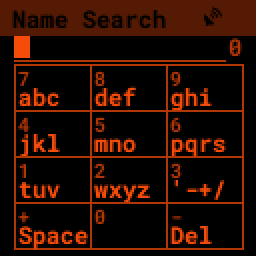
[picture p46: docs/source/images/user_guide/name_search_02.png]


Each number key generates its number, then the three or four letters shown, in turn.  Pause
long enough between presses, or press a different key, and the cursor moves to the next
position.

To press each key just once, switch the search input to T9.  Every press enters its digit,
and the PiFinder matches the digit sequence against the letters of each object name, so
``1897`` finds Vega.  Select Multi-Tap or T9 under Search Input in the
:ref:`user_guide:settings menu`.  You can also press and hold **SQUARE** here and select
Input from the :ref:`user_guide:quick menu` to reach the setting directly.

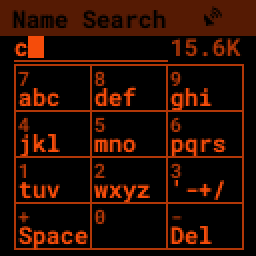
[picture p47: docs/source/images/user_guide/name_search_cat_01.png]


As you type, the PiFinder shows how many objects match your search term, to the far right
of your text.

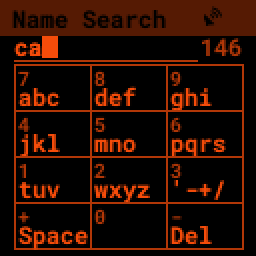
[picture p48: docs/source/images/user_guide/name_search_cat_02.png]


The count drops as you add more text.

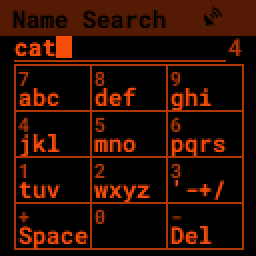
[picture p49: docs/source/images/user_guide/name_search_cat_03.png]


Once you've narrowed the list enough, press **RIGHT** to see the full list of matches.

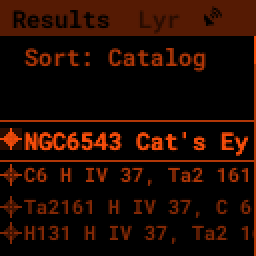
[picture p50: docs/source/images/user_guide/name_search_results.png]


Custom Targets
---------------

Sometimes the object you're after isn't in any catalog: a newly discovered comet, or a
position from a chart or article.  Select Custom from the Objects menu to enter a right
ascension and declination by hand, then push to it like any other object.

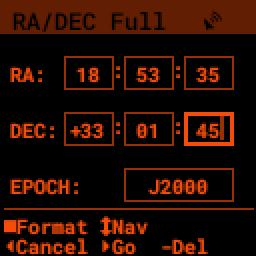
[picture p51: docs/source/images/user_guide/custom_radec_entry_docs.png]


Type the coordinates with the number keys.  The **UP/DOWN** arrows move between fields, and
**-** deletes the last digit.  Press **SQUARE** to cycle the entry format: full
hours/minutes/seconds (shown above), decimal hours and degrees, or decimal degrees for
both.  The title bar names the active format.  With the declination degrees selected, **+**
flips its sign.  On the EPOCH field, **+** cycles between J2000, JNOW, and B1950.

When the numbers look right, press **RIGHT** to create the target.  The PiFinder makes a
one-off object, opens its :ref:`Object Details<user_guide:object details>` screen with
Push-To guidance, and adds it to the Recent list so you can return to it during the
session.  Press **LEFT** to go back without creating anything.

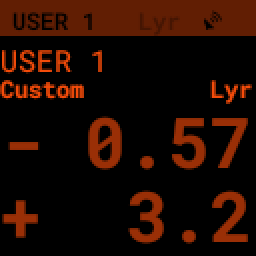
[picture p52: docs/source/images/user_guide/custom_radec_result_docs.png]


Observing Lists
---------------

You can bring a session you planned ahead of time to the eyepiece, whether you built it in
SkySafari or a spreadsheet, or a fellow observer shared it with you.  Copy the list file
into the ``obslists/`` folder of the PiFinder's :ref:`shared data
folder <connectivity:shared data access>`, then load it from Obs Lists in the Objects
menu.

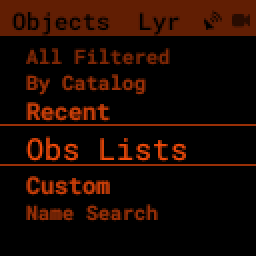
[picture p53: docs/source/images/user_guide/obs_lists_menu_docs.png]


The PiFinder reads observing lists in all of these formats.  It recognizes each by its file
extension and, for ``.txt`` files, by the content itself:

.. list-table::
   :header-rows: 1

   * - Format
     - Extension
   * - `SkySafari observing list <https://support.simulationcurriculum.com/hc/en-us/articles/236161107-SkySafari-5-Observing-Lists>`_
     - ``.skylist``
   * - PiFinder native
     - ``.pifinder``
   * - CSV
     - ``.csv``
   * - `Stellarium observing list <https://stellarium.org/guide/>`_
     - ``.sol``
   * - `Autostar / Meade tour <http://www.weasner.com/etx/autostar/as_tours.html>`_
     - ``.txt``, ``.mtf``
   * - `Argo Navis catalog <http://www.wildcard-innovations.com.au/downloads/documentation/argoman10.pdf>`_
     - ``.txt``
   * - `NexTour / Celestron tour <https://www.nexstarsite.com/PCControl/NexRemote.htm>`_
     - ``.hct``
   * - `EQMOD tour <https://eq-mod.sourceforge.net/tour/>`_
     - ``.lst``
   * - Plain text, one object name per line
     - ``.txt``

The Obs Lists screen shows every list it finds, along with any folders.  Folder names appear
in ``[brackets]``, so you can organize lists into subfolders by trip, season, or source.
Scroll with the **UP/DOWN** arrows and press **RIGHT** to open a folder or load a list.

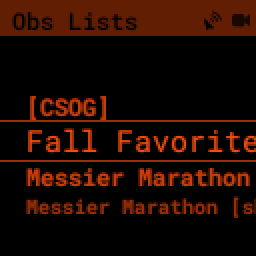
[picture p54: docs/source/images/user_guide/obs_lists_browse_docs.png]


When two lists share a name, such as ``Messier Marathon.skylist`` and
``Messier Marathon.csv``, the PiFinder appends the format to tell them apart, as in the
image above.

Loading a list matches each entry against the PiFinder's catalogs, briefly reports how
many objects matched, and opens the result as a regular
:ref:`Object List <user_guide:object list>` you can sort, browse, and push to.

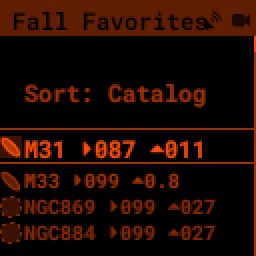
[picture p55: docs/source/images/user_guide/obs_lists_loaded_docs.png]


Entries that match a catalog behave exactly like objects you find by browsing.  Images,
descriptions, and your observation logs all come along.  An entry the PiFinder cannot
match, but that includes coordinates, becomes a one-off object under the code OBS, so
nothing on your list is left behind.

.. note::
   The ``.pifinder`` format is the PiFinder's own JSON list format.  Use it when a planning
   tool offers it, because it carries catalog references, magnitudes, object sizes, and
   coordinate epochs that the other formats drop.  The `observing-list formats reference
   <https://github.com/brickbots/PiFinder/blob/main/docs/ax/catalog/obslist-formats/README.md#the-pifinder-format>`__
   documents its fields, JSON schema, and a worked example.

Importing a CSV list
^^^^^^^^^^^^^^^^^^^^^

CSV is the format to reach for when another tool gives you a list as plain columns: a
spreadsheet, an observing planner, or a sky atlas.  The first line is a header naming the
columns.  The PiFinder reads them by name, so their order does not matter and the case is
ignored.  Only ``Name`` is required, plus coordinates so the PiFinder knows where to point:

.. list-table::
   :header-rows: 1

   * - Column
     - Holds
   * - ``Name``
     - A label for the row, e.g. ``M 3`` or ``My comet``.
   * - ``RA`` / ``Dec``
     - Right ascension and declination (see the coordinate forms below).
   * - ``Magnitude``
     - Brightness, optional.
   * - ``Type``
     - Object type such as ``Gx`` or ``PN``, optional.

The PiFinder accepts common spellings of those headers too.  ``ra``, ``dec``, ``mag``,
``RA_deg`` and ``Dec_deg`` all work.  The RA header can also carry the unit: the PiFinder
reads a decimal under ``RA_h`` or ``RA_hours`` as hours, and one under ``RA`` or ``RA_deg``
as degrees.  Write coordinates in any of three forms:

.. list-table::
   :header-rows: 1

   * - Form
     - RA example
     - Dec example
   * - Decimal degrees
     - ``205.8583``
     - ``+28.244``
   * - Colon-separated
     - ``13:43:26``
     - ``+28:14:39``
   * - Sexagesimal
     - ``13h 43m 26s``
     - ``+28° 14' 39"``

The PiFinder reads a decimal right ascension as **degrees** (0–360) unless its header names
hours.  A small list looks like this::

   Name,RA,Dec,Magnitude
   My target,205.8583,28.2442,6.3
   Comet 2024X,250.667,36.411,11.0

Each row resolves the same way as any other observing list.  If its name matches a catalog
object, you get that object with its images, descriptions, and your logs.  Matching ignores
spacing and capitalisation, so ``M 13``, ``M13`` and ``NGC 224`` all work.  If the name
matches nothing, the PiFinder uses the row's own coordinates as an OBS target.  To keep your
exact coordinates for an object the catalog would otherwise recognize, give the row a name
the catalog does not match.  A prefix, as in ``_M 3``, is enough.

For the complete column reference, see the `observing-list formats reference
<https://github.com/brickbots/PiFinder/blob/main/docs/ax/catalog/obslist-formats/README.md#csv-import>`__.
It covers every accepted header spelling, the coordinate forms, and the import notes.

Object Images
---------------

If you used the prebuilt PiFinder image, or have
:ref:`downloaded<software:catalog image download>` the set of catalog images, you can see
what the selected object looks like in sky-survey images.  These appear in the background of
the :ref:`user_guide:object details` screen.  Press the **SQUARE** key to cycle through the
pages of information about each object and view the images in full detail.

The PiFinder rotates each image to match the view through your eyepiece at your position and
time, which helps you identify the faintest objects.

Zoom in and out with the **+/-** keys.  The FOV appears at the bottom of the image, so you
can match it to your eyepiece.

As an example, here are the images available for M57

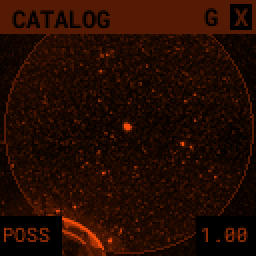
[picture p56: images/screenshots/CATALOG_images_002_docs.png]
Catalog Image


Catalog Image

These images match the view through your eyepiece for the telescope you're using, pointing
at a specific area of sky from your current location.  By default they are oriented for a
Newtonian reflector.  If you use a refractor, or an SCT with a star diagonal, set the
orientation options for your telescope as described in :doc:`equipment`.  Use the **+** and
**-** keys to switch between the fields of view of the eyepieces you configured in the
:ref:`Web Interface <connectivity:web interface>`.

Two overlays help you read the image.  Letters near the edge of the field mark the cardinal
directions, so you can relate the view to a chart.  You see two of N, S, E, and W,
depending on how the image is rotated.  A thin outline traces the object's cataloged size
and orientation.  When only the bright core shows in the eyepiece, that outline gives you a
feel for the object's full extent.  You can switch both overlays off under Image... in the
:ref:`user_guide:settings menu`.

Object image with cardinal-direction letters and size outline

The bottom left of the screen shows the source of the current image, and the left side
shows the current FOV information.

Logging Observations
-----------------------

Press the **RIGHT** arrow while viewing any object's details to open the logging interface.
There you add context about your observation and save it to your log.




Use the **UP/DOWN** arrows to select one of the four context items to change:

- **Observability**: How easy is it to spot and recognize this object
- **Appeal**: Your overall rating.  Would you recommend it to a friend?

Set these first two with a number key from 1 to 5, or press the **RIGHT** arrow to cycle
through the stars.

- **Conditions**...

  - **Transparency**: A relative measure of contrast.

  - **Seeing**: The stillness of the atmosphere.

- **Eyepiece**: Note which of your eyepieces you're using.

When you're done, use the **UP/DOWN** arrows to select **SAVE LOG** and record your
observation.  You can also save straight away, with no context, just to note that you
observed an object.

Observing Projects
--------------------

If you're like me, you may enjoy observing projects, such as working through all the
Messier or Herschel objects.  The PiFinder makes these long-term efforts easy.  Log each
object, and it then shows you only the objects you have left that are visible during a
session.

Combine a :ref:`filter<user_guide:filters>` on observation status with an object list
sorted by NEAREST to work through a collection easily.

Power & Charging
=====================================

Every rev4 PiFinder has an internal battery, good for a full night on a single charge.  You
can also keep one running indefinitely from any USB-C power source.  This section covers the
power button, how charging behaves, what the battery indicator tells you, how long a charge
lasts, and how to look after the cell.  For the first time you turn one on, the
:ref:`quick_start:powering the pifinder` section of the Quick Start walks through it step
by step.

Power button and shutdown
-------------------------

To turn the PiFinder on, press and hold the button marked **PWR**, on the front below the
keypad, for about two seconds.  The **PWR** label lights while the PiFinder starts up, and
goes out once the screen and keypad come up.



To shut down, press and hold the button again for about a second.  The screen goes straight
to the shutdown confirmation.  Press and hold the button once more to confirm, or press the
**RIGHT** arrow.  A tone plays, and the PiFinder turns itself off once it has closed
everything down safely.  In normal use you never need to cut the power by hand.  If the
software ever hangs and will not shut down, press and hold **PWR** for more than 14 seconds
to reset the power system.  See :ref:`troubleshooting:the pifinder won't turn on`.

The menus get you to the same place if your hands are already on the keypad.  See
:ref:`user_guide:shutdown`.

.. note::
   On v3 and v2.5 PiFinders power is a small white **slide** switch above the screen:
   facing the screen, slide it right for on and left for off.  Shut down from the menus
   first, then slide the switch off.
   |v3_docs|

Charging
--------

Two USB-C ports sit on top of the case, each named on the faceplate just below it:

- **POWER** runs the PiFinder and charges the battery.  This is the one to plug a charger
  or a power bank into.
- **DATA** is for connecting accessories, such as the PiFinder remote or other USB
  devices.

From empty, a full charge takes about six hours with the PiFinder turned off.  Charging
draws up to **1.5A**, so use a supply that can deliver it.  A weaker source charges
proportionally slower.

You can carry on observing while the battery charges.  There is no need to turn the
PiFinder off first.  Expect the charge to take considerably longer that way, because the
PiFinder consumes much of what the charger supplies.  A long charge that leaves the battery
still low almost always means the PiFinder was running the whole time.

A charge indicator labelled **CHG** lights while the battery is charging and goes out once
it's full.  It is red, but bright enough to be distracting once your eyes are dark adapted,
so it's worth knowing what it is before it appears beside you at the eyepiece.

.. note::
   The last stretch of charging is slow.  As the cell approaches full the charging current
   tapers off, so the **CHG** light can stay on for a while after the battery is nearly
   there.  That's normal, not a fault.

.. note::
   v3 PiFinders charge through the optional **PiSugar S Plus** board rather than an
   on-board charger.  Charge a v3 with the slide switch **off**, because one left running
   barely fills at all.  Use the port nearest the back of the case.  Its indicator glows
   blue while charging and green when full, and a full charge takes roughly three hours.
   The port nearest the keypad runs the PiFinder without charging.  It is wired ahead of
   the slide switch, so plugging into it turns a v3 on regardless of the switch position.
   |v3_docs|

The battery indicator
---------------------

The title bar carries a battery glyph, just left of the GPS and solver icons.





It estimates **how much longer the PiFinder will run**, not how much charge is left in the
cell.  Take it as a guide to the rest of the evening rather than a precise figure, and
expect it to err on the cautious side.

The glyph empties in coarse steps rather than counting down smoothly, and shows a hollow
outline for the last stretch.

While the battery is charging, a bolt appears in place of the usual glyph.



.. note::
   v3 and v2.5 PiFinders have no battery indicator.  The PiSugar board's charge state isn't
   visible to the PiFinder software, so nothing appears in the title bar.
   |v3_docs|

Low-battery warnings and automatic shutdown
-------------------------------------------

The PiFinder warns you twice as the battery runs down: once when the estimate reaches
**10%**, and again at **5%**.  Each is a brief message on screen with a sound to match.



Measured on the bench under a continuously solving load, the 10% warning arrives about an
hour and a half before the end, and the 5% warning about half an hour before it.  Lighter
use stretches both.  Each warning appears once per discharge rather than repeating, so it
does not nag you for the rest of the night.  Plugging in re-arms them for next time.

When the battery is nearly flat, the PiFinder shows a final warning, plays the shutdown tone
and shuts itself down cleanly.  It stops deliberately rather than letting the power cut out
on its own.



Battery life
------------

A full charge of the 8,000mAh cell runs the PiFinder for about **ten hours**.  Treat that as
a floor rather than an average.  It was measured with the camera solving continuously, the
screen at full brightness and the screen sleep turned off, which is harder work than a real
night at the eyepiece.  Sitting on one object, or stepping away from the telescope, lets the
PiFinder drop into power-save mode and stretches the time considerably.  Turning the
brightness down helps too.  Hold **SQUARE** and press **+** or **-** to adjust the screen
and keypad at any time.

.. note::
   The PiFinder drops into power-save mode after it has been idle for a while.  It dims the
   screen and slows the camera to save power.  Any key press, or movement of the telescope,
   wakes it.  You can change the idle time, or turn it off entirely, in the
   :ref:`user_guide:settings menu`.

Running on external power
-------------------------

Any USB-C source rated for at least **2A** runs the PiFinder: a wall charger, a USB power
bank, or a portable power station's USB output.  Plug it into the **POWER** port.  The
PiFinder then runs from it and tops the battery up at the same time, and you can add
external power mid-session without restarting.  As a rough guide, about 1,000mAh of
power-bank capacity runs the PiFinder for an hour, so a 10,000mAh bank is good for the
better part of a night.

If you hit power dropouts, suspect the cable first.  Some USB-C cables are unreliable at
the ~2A the PiFinder draws, especially on long runs.

.. note::
   On a v3, the port nearest the keypad runs the PiFinder without charging.  That makes a
   useful trick for stretching a long night.  Plug a power bank into that port and turn the
   battery **off**.  The PiFinder then runs on external power, with the cell held in
   reserve for after you unplug the bank.
   |v3_docs|

.. warning::
   Feed the PiFinder **5V USB-C power only**.  To run it from a telescope's 12V supply, you
   must use a 12V-to-5V step-down (DC-DC) converter with a USB-C output.  Never connect 12V
   directly to the PiFinder.  That will damage it.

Battery safety & care
---------------------

The internal battery is a lithium-polymer (LiPo) cell.  Treat it sensibly and it lasts for
years, but like any lithium battery it deserves a little respect.

.. warning::
   Stop using the battery and disconnect power if it ever becomes **swollen, damaged,
   unusually hot, or develops an odour**.  A puffed-up or punctured LiPo cell can vent or
   catch fire.  Do not continue to charge or use a cell in this condition.  Contact us
   about a replacement.

.. warning::
   Do not **puncture, crush, drop, or open** the battery, and don't open the case to get at
   it.  Keep the PiFinder dry.  The battery and electronics are not waterproof.

A few habits keep the cell healthy:

- **Charge through the POWER port only.**  The PiFinder's own charger looks after the cell,
  so just supply 5V USB-C as described above.  There is no need for an external LiPo
  charger, and you should not connect one.
- **Charge where you can keep an eye on it,** and not on or near anything flammable.  Do not
  charge or leave the PiFinder in extreme heat.  A closed car on a sunny day is the classic
  way to cook a battery.
- **Mind the temperature.**  Observers report using the PiFinder from about -15°C (5°F) to
  45°C (110°F).  That range describes the whole PiFinder in the field, not a separate
  battery rating.  Capacity drops in the cold, though the computer's own heat keeps the cell
  warm enough to work in most conditions.  Do not charge a battery that is below freezing.
- **For long-term storage,** leave the cell partly charged rather than full or empty and keep
  it somewhere cool and dry.  Top it up every few months so it does not discharge completely.
- **Dispose of it responsibly.**  Take a worn-out lithium battery to a battery-recycling
  drop-off, not the household rubbish.

.. note::
   On a v3, the battery and its charger are the optional **PiSugar S Plus 5000mAh** board,
   which is also the only compatible replacement part.  Other PiSugar models share the I2C
   bus with the PiFinder's motion sensor and cause problems, so make sure you fit the
   S Plus.  Don't attempt to disassemble the board itself.
   |v3_docs|

Settings Menu
==============

All user-configurable items live in the Settings Menu, near the bottom of the main
PiFinder menu.



The top items collect several options under User Preferences, the Chart Screen, and the
:ref:`object image <user_guide:object images>` overlays.  An ellipsis (...) indicates
more options below.



Below the general UI options are settings for which :ref:`connectivity:wifi` mode your
PiFinder is in, and for its physical configuration.



The Advanced submenu, near the bottom of the Settings Menu, holds the hardware setup you
normally configure once: PiFinder Type, Camera Type, and GPS Settings (type and baud rate).
Opening it shows a brief "Options for DIY PiFinders" reminder, because on a fully built
PiFinder these already match your hardware.

Sounds
------

A rev4 PiFinder has a small buzzer.  It plays a short tone on each key press, at startup
and shutdown, and with every low-battery warning.  The Volume menu item, in User
Preferences, sets how loud they are.  Its options are Off, or 1 through 5.  Selecting a
level plays a sample tone at that level, so you can set it by ear.



The tones vary in loudness by design: the buzzer is far louder at some pitches than
others, so a cue pitched away from its loudest note sounds softer.  Set Volume to Off if
you'd rather observe in silence.

.. note::
   v3 and v2.5 PiFinders have no buzzer.  The Volume setting appears on those PiFinders too,
   but nothing sounds.
   |v3_docs|

Connectivity
==============

The PiFinder hosts its own WiFi network, ``PiFinderAP`` (no password), so your phone or
tablet can join it anywhere.  It can also join your home network instead.  Switch between
the two modes from the :ref:`user_guide:settings menu`, and check the current mode and
address on the :ref:`user_guide:status screen`.  From a connected device the PiFinder
answers at ``http://pifinder.local``.  The :doc:`connectivity` page covers the web
interface, SkySafari and other planetarium apps, and the shared data folder.

Tools
==========================

Near the bottom of the main PiFinder menu, the Tools menu item leads to a set of screens
that aren't observing-related but provide useful information or let you perform actions:
checking the PiFinder's :ref:`status<user_guide:status screen>`, selecting your active
:doc:`telescope and eyepiece <equipment>`, setting your place and time by hand,
:ref:`updating the software<user_guide:update software>`, and
:ref:`shutting down<user_guide:shutdown>` or restarting.



For the full tree and a note on what every item does, see the
:ref:`Tools section of the Menu Map<menu_map:tools>`.  The sections below cover the screens
you reach for most often.

Status Screen
----------------------------------

The Status Screen is the central place to check the PiFinder's current state and operation.



Some of the key information shown:

- The current solver state, as LAST SLV on the top line.  It shows the seconds since the
  last plate solve, the solve type (i for IMU or C for camera), and, for a camera solve,
  the number of stars matched.
- WiFi information a bit further down, including the current WiFi mode, network name, and
  IP address.
- The GPS rows near the bottom.  The list is longer than the screen, so scroll down to
  see them.  GPS MSG names the last message from the GPS receiver, with how long ago it
  arrived.  On a healthy link the names change constantly and the age stays under a
  second.  A frozen name with a climbing age, or names starting with ``?``, point to a
  GPS problem.  See :ref:`troubleshooting:the gps never locks`.

Place & Time
----------------------------------

The PiFinder needs to know where and when it is to turn the sky's coordinates into the
directions it gives you.  Its built-in GPS handles this automatically.  You do not have to
wait for a fix, or have GPS at all, to get going.  Open Tools, then Place & Time, to set
everything by hand.

Set Location gathers the ways to manage your observing site:

- **Enter Coords** lets you type your latitude, then longitude, then altitude with the
  number keys.  The **+** key flips the sign for southern latitudes and western longitudes.
- **Load Location** recalls one of your saved sites, and **Save Location** stores the
  current one so you can select it again next time.

Set Time/Date sets the clock when there's no GPS.  Enter the time, and the PiFinder moves on
to a date-entry screen.  The PiFinder protects a time you set by hand, so a later GPS fix
does not overwrite it and your manual clock stays put.  Reset Location and Reset Time/Date
discard what's set, if you'd rather start fresh or hand control back to GPS.

.. note::
   With your location and time set by hand, the PiFinder is fully usable without a GPS
   signal.  You can focus, align, browse objects, and push to them.  The
   :ref:`user_guide:star chart` and Align screens also work before a GPS lock.

Getting a GPS lock
----------------------------------

The PiFinder's GPS receiver takes a few minutes to work out where it is.  This is normal,
and it is the part of the first night that surprises people most.  Knowing what the
receiver is doing saves you from chasing a fault that isn't there.

Before it can fix a position, the receiver has to download orbit data from the satellites
themselves.  That download runs at a slow, fixed rate, so it takes several minutes however
good your sky is.  Expect longer after the PiFinder has been off for a while, or when you
have travelled a distance since the last session.  Later nights at the same site are
quicker, because the PiFinder still holds usable data.

Open the Start menu and select GPS Status to watch progress.  That screen turns the camera
off, which cuts electrical noise and helps the receiver hear more satellites.  It shows
**Lock boost on** while it does this.  Leave the PiFinder on that screen and let it work.

Four things are worth knowing while you wait:

- **"Sats seen/used: 0/0" is not a progress bar.**  It reads 0/0 for most of the wait and
  then climbs quickly near the end.  A long run of zeros does not mean the receiver has
  failed or that the sky is blocked.
- **Leave the PiFinder on.**  Turning it off and on again restarts the download from the
  beginning.  Rebooting every few minutes to check on it is the one reliable way to never
  get a lock.
- **Your phone is not a fair comparison.**  Phones use assisted GPS.  They download the same
  orbit data over the mobile network in seconds and already know roughly where they are.  A
  phone showing dozens of satellites next to your PiFinder tells you nothing about
  conditions.
- **Give the receiver a clear view.**  It needs open sky.  Indoors, under a roof, or hard up
  against a wall all slow it down or stop it.

Once the fix arrives, the Lock Type on the GPS Status screen tells you how good it is:

- **Accurate** is a 2D fix.  It gives latitude and longitude without altitude.
- **Precise** is a 3D fix, which adds altitude.

Both are plenty.  The PiFinder only needs a rough position on Earth to point your telescope,
so a night that reads Accurate works exactly as well as one that reads Precise.  **Limited**
and **Basic** appear before a full fix, while the receiver is still settling.

.. note::
   You do not have to wait.  If the sky is good and you would rather start observing, enter
   your location and time by hand as described above.  Everything works from there.

Update Software
------------------

The PiFinder can download and install software updates directly from its screen and keypad.
To start, select Software Upd from the :ref:`user_guide:tools` menu.

Updates happen on the PiFinder itself, so there is no need to send it anywhere.  New PiFinders
often ship a version or two behind the latest release, so running an update is a normal part
of your first night out.



The PiFinder needs internet access, so put it in Client Mode connected to a WiFi network.
See :ref:`connectivity:connecting to a new wifi network` for details.

The PiFinder confirms it can reach the internet, then compares the current release version
to the one installed.



.. note::
   If the release version shows as **unknown**, the PiFinder cannot reach the internet to
   check.  It is either in Access Point mode, or its WiFi is not configured.  Put it in
   Client mode on a network with internet access (see
   :ref:`connectivity:connecting to a new wifi network`).  Re-imaging the SD card is not the
   fix for this.  If WiFi is configured but the check still fails, move closer to the
   router or re-enter the network details.

If a new version is available, select the option presented to start the update.  This may
take several minutes, and the PiFinder restarts when it's done.





You can also download a pre-built image of any software release and write it to the
PiFinder's SD card.  See our `release page <https://github.com/brickbots/PiFinder/releases>`_
for information about each release and a download link.

Instructions for writing release images to an SD card are on the :doc:`software setup<software>`
page.

Polar Alignment
---------------------------

An equatorial platform or equatorial mount tracks the sky by turning your telescope around a
single axis that's meant to point at the celestial pole.  That axis is the platform's pivot,
or the mount's right ascension axis.  The closer it is to the true pole, the longer objects
stay put in the eyepiece.  The Polar Alignment tool measures how far your axis sits from the
pole and walks you through correcting it.  It works from ordinary plate solves, so you need
no polar scope and no sight of Polaris.

It lives near the bottom of the main menu: open Tools, scroll down to Experimental, and
select Polar Align.

The tool solves the sky at two or three points while you rotate around that axis between
them.  You turn the platform, or slew the mount in right ascension only.  The PiFinder then
works out where the axis points from how the view shifts.  The measurement is only as good
as the solves behind it, so before you start make sure the PiFinder has a GPS lock, is
focused, and is solving reliably.  Turn your mount's or platform's sidereal tracking off as
well, because the measurement assumes the telescope holds still except when you rotate it
yourself.



.. note::
   This aligns the rotation *axis*, not the PiFinder to your eyepiece.  The one rule that
   matters: between captures, move only *around* that axis.  On a platform, keep the
   telescope clamped to the platform and rotate the platform.  On an equatorial mount, lock
   the declination axis and slew only in right ascension.  During adjustment, move the axis
   itself with your altitude and azimuth adjusters, not by slewing the telescope.

To take a measurement, open Polar Align and press **SQUARE** to begin, then:

1. Aim the telescope near the pole and wait for the screen to report a recent solve.  Press
   **SQUARE** to capture the first point.  :ref:`user_guide:getting a good measurement`
   below gives the best aim and sweep for each mount.
2. Rotate around the axis by at least about 10°, turning the platform or slewing in right
   ascension only.  Wait for a fresh solve, then press **SQUARE** for the second point.
3. For a stronger result, rotate farther and capture a third point.  Three points let the
   PiFinder check how well the captures agree.  To stop at two points instead, press **0**
   to solve now.



If the screen says 'Rotate more', the captures were too close together to pin down the axis.
Rotate farther and capture again.

Once it has enough rotation, the PiFinder switches to a live readout showing how far the
axis is from the pole, as push-to offsets in altitude and azimuth.  Turn your altitude and
azimuth adjusters to follow the arrows until both readings fall to zero.  On a platform
those are the platform's adjusters.  On a mount they are the polar-alignment bolts.  The
readout refreshes with each new solve.  If it shows 'No solve', hold everything still until
the PiFinder solves again.

.. note::
   Before touching the adjusters, lock *both* of the mount's axes.  Right ascension is the
   one everyone forgets, because you unlocked it to rotate between captures.  A clutch that
   slips while you work the adjusters quietly ruins the correction.  On a platform, leave
   the telescope alone entirely and adjust only the platform.

.. note::
   Turn Sleep Time off before you start.  Adjuster knobs move the telescope too slowly for
   the motion sensor to notice, so the screen dims part way through an adjustment even
   though you are working.  Only key presses hold the PiFinder awake, and the longest sleep
   delay is 2 minutes, so **Off** is the setting that suits this job.  Sleep Time sits under
   User Pref in the :ref:`user_guide:settings menu`.

   The same applies to a motorized mount at guide speed.  A slow slew may not register as
   motion, so the Push-To numbers appear to freeze and then jump when the PiFinder wakes.



The top line summarises the measurement: the number of points used, the total sweep, and,
for a three-point solve, a fit rating of ``ok``, ``mid``, or ``bad``.  A poor fit usually
means something moved between captures that shouldn't have, so it's worth redoing.

Press and hold **SQUARE** to open the :ref:`user_guide:quick menu`, which gathers the
advanced actions.  **STATS** opens a read-only detail view.  **REDO PT** drops just the
last point so you can recapture it.  **Roll On/Off** switches between a full three-axis
fit and an RA/Dec-only fit that ignores camera roll, which is useful after a camera flop.
:ref:`user_guide:getting a good measurement` covers which fit suits each mount.



The STATS view spells out the correction in both degrees and arcminutes for each axis, the
fitted axis position, the fit quality, and how the captures were spaced in time.  That
detail helps you judge whether a measurement is trustworthy.



To start a fresh measurement at any time, press **SQUARE**.  To exit the tool, press
**MINUS**.

Getting a good measurement
^^^^^^^^^^^^^^^^^^^^^^^^^^

The connection between the PiFinder and the telescope is never perfectly rigid.  Small
flexures grow with how much the PiFinder's attitude changes between captures, and they show
most strongly in camera roll.  Wider sweeps are better in theory, but in practice the sweet
spot is a moderate sweep taken close to the pole, which keeps the PiFinder's attitude nearly
constant.

On an equatorial mount:

- Point the declination axis so the telescope sits roughly 7–10° off the mount's polar axis.
  Measure from wherever that axis points now, not from where the true pole is.
- Sweep roughly 30–45° in right ascension: take the middle capture with the PiFinder's
  screen roughly vertical, and the first and last captures 15–22° either side of it.
- Set Roll Off in the Quick Menu.  Flexure shows up most strongly in roll, so the fit is
  better without it.

On an equatorial platform:

- Aim the telescope close to Polaris, ideally within 5°.
- Keep Roll On.  Aimed this close to the axis, the pointing barely shifts between captures,
  so the roll change carries most of the rotation information.
- Position the PiFinder so its screen is vertical at the middle of the platform's travel.
  That also keeps the altitude and azimuth arrows matching the real directions while you
  adjust.

Expect the result to land within 20–30 arcminutes of the pole.  A very rigid connection
between the PiFinder and the telescope, plus a wider sweep, can bring that down to around
10.  That won't match a polar scope, or a routine that images through a rigidly mounted
telescope with a much smaller field of view.  It is still a solid alignment when the pole is
hidden from your site or you have no polar scope, and it is close enough to put Polaris into
a polar scope's reticle.

Shutdown
---------------------------

You do not strictly have to shut down before you cut the power, but the PiFinder is a
computer and skipping the shutdown risks file corruption.  Some MicroSD cards are more
sensitive than others.

The quickest route is the power button.  Press and hold it for about a second, and the
confirmation below appears from wherever you are.



Press and hold the power button again, or press the **RIGHT** arrow, to confirm.  Press the
**LEFT** arrow to go back.  The screen and keypad turn off within a few seconds, and the
PiFinder turns itself off.

**SQUARE** does not confirm on this screen.  Press and hold it and the Quick Menu opens
instead.  For what each key does, see :ref:`user_guide:the menu system`.

The keypad gets you to the same screen.  The Tools menu offers a Shutdown menu item under
Power, and the Quick Menu is faster:

- Press and hold **LEFT** for more than a second to jump to the main menu
- Press and hold **SQUARE** to open the Quick Menu




- Press **DOWN** to select the SHUTDOWN option

.. note::
   On v3 and v2.5 PiFinders there is no power button, so use the keypad route above.  Once
   the screen and keypad turn off it's safe to slide the power switch off or unplug the
   battery.
   |v3_docs|

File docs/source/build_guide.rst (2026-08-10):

===========
Build Guide
===========

Introduction and Overview
=================================

.. note::
   This guide covers the self-built (DIY) PiFinder. It uses the v2.5 hardware
   and comes together in one of three configurations: Left, Right, or Flat.
   v3 PiFinders ship assembled and do not use these instructions.

Welcome to the PiFinder build guide. The build has three main parts: the :ref:`UI Hat <build_guide:pifinder ui hat>` with its screen and buttons, :ref:`3d printing <build_guide:printed parts>` and preparing the case parts, and :ref:`final assembly <build_guide:assembly>`. The :doc:`Bill of Materials <BOM>` lists every part you need. Send any questions by `email <mailto:info@pifinder.io>`_ or on `discord <https://discord.gg/Nk5fHcAtWD>`_.

PiFinder UI Hat
========================

A key part of the PiFinder is the UI Hat, a custom board that matches the general form factor of the Raspberry Pi and connects to its GPIO header. It carries the switches, the screen, the Inertial Measurement Unit, and the keypad backlight components.

Every component is through-hole, so this build is approachable even for beginners. The build order matters, though, because some components block access to others.

Some photos here still show the v1 non-backlit board, but the assembly is the same once the backlight components are in place.

You need both PCBs to start. One holds the electronic components. The other carries the shine-through legends and goes on top of the assembled board at the end. The main `PiFinder git repo <https://github.com/brickbots/PiFinder/tree/release/gerbers>`_ holds the Gerber files for both.

Backlight Components
------------------------

Start with the LEDs. They sit close to the board, so fitting them first makes them easier to align.



Polarity matters, so check the direction of each LED. The longer lead goes through the round hole in the footprint. The photo below shows the orientation.



Position each LED carefully. Keep them fairly uniform, though small inconsistencies don't matter much. Place them all in the board, then tape them in place.





Pull the legs straight and solder one leg of each LED. Remove the tape and check again. If any are wildly out of place, reheat that one joint and adjust.



When you are happy with the alignment, solder the remaining legs and clip the leads down to a single pair. Leave one pair of legs long. You need them to power the backlight for the test in the next section.



Fit the two resistors and the transistor next. R2 is the 330 ohm part and stands vertically. R1 is the 22 ohm part and lies horizontally. Direction doesn't matter for the resistors, but it does for the transistor. Check the photo below for the orientation. Make sure the transistor sits flat against the PCB and the resistors sit low. Solder from the back and clip the leads once they look good.



Testing the Backlight
^^^^^^^^^^^^^^^^^^^^^^

Test the backlight and the LEDs now with any 3V coin cell, such as a CR2032. Connect the positive side of the battery to the longer pin of an LED and the negative side to the shorter pin, as shown below with a single LED. The LEDs are wired in parallel on the board, so this lights all of them at once. Every LED should light up:



Replace any LED that doesn't light before you continue.

Switches
------------------------

Fit the switches next. Place each one on its footprint and press it down fully. Before you solder, check that none of them sit tilted.



Place the top legend plate over them to confirm they all clear the holes properly. Then solder them. You don't need to clip the switch leads, because they have plenty of room.



Headers
---------

Fit the headers next. They receive the IMU, the GPS module, and the screen. The procedure is the same for all three: insert the header, solder one pin, check that it sits flat and straight, then solder the rest. Clip the pins flush and apply some insulating tape.

Start with the IMU header. It goes on the underside of the board. Solder it from the top.





Apply the insulating tape. Fit the screen header next. It goes in from the top side:



Trim the pins and tape it up.



Fit the GPS header next. The modules ship with a yellow header, but any header works. Insert it from the bottom, then solder and tape it like the rest.





IMU
------------------------

Fit the Inertial Measurement Unit next. It has an annoyingly bright green LED. Paint over it with a few layers of black nail polish, or destroy it with your soldering iron. You can deal with it after soldering if you forget, but it is much easier beforehand. The image below shows the offending component.

Green led on IMU

The photo below shows the orientation on the back of the PCB. Make sure the IMU sits flat and square with the board. It doesn't need to be perfect, but it must be secure and low-profile. Solder it into position.



Display
------------------

The screen comes next. It covers the solder points of the IMU header, so check those joints before you continue.

Unscrew the stand-offs from the front and remove them.

Display as shipped

Display with standoffs removed

Next, remove the plug from the underside of the board. This step isn't strictly necessary, but it helps the screen sit lower and flatter. First cut each lead to the connector with sharp cutters. Cut low, though the exact spot isn't critical. Then cut away the plastic at the attachment points on both short sides with clippers.

Connector cut free

Sand back or cut the bottom tabs on the screen PCB. This makes the top plate fit better and look tidier. The tabs carry no circuitry and only provide screw points you don't need.

Cut/Sand tabs on display

Test-fit the screen with the header installed and the top plate in place. Everything should fit neatly and sit square.

Screen test fit

Solder the screen in place. Solder one pin first and check all around to make sure the screen sits flat. If it doesn't, heat that one joint and adjust.



GPS
------------------

.. danger::
   Complete the :ref:`Testing the Backlight <build_guide:testing the backlight>` step before you solder on the GPS module. The GPS module blocks access to some LED pins. To replace a blocked LED, you have to remove the module first. Removing it is difficult and can destroy the PCB. It has happened to us. Make sure the LEDs work before you continue.

   If you do need to desolder the GPS module later, work slowly and carefully, and use a desoldering pump.

.. caution::
   The GPS module also blocks access to some switch pins, so you can leave it out entirely until the end if you want to test the switches. The GPIO connector that attaches the UI Hat to the Raspberry Pi then makes this awkward.

   We don't recommend it. The LEDs have given us trouble in the past, but the switches have usually been rock solid.

The last active component is the GPS module. It goes component side up so you can access the antenna plug. Check the photo below and solder it securely.



Connect the antenna to the GPS module. The plug is fiddly, so check the alignment carefully before you apply much force. It snaps in and then rotates easily.

.. list-table::

   * - 

     - 

The route of the antenna cable matters for reception. Tape the cable to the back of the board as shown below. This keeps it secure and out of the way during the build.



Connector
------------------

The GPIO connector is the last soldered part of the UI Hat. To space it correctly, mount the PCB to your Pi with the stand-offs you use for final assembly.

The pins of the connector are long, so they suit a range of spacings. Plug the connector firmly into your Pi, mount the UI Hat with stand-offs and screws, then solder the connector at the correct spacing.

Add any heatsinks you plan to use first. Before you solder, take your time and check that the UI Hat sits securely on the Pi, that no parts interfere mechanically, and that you are happy with the spacing.

The photos below show the procedure, which is easier than it sounds. There are a lot of pins, so solder each one securely. This part takes force every time you install or remove the UI Hat.





With all the pins soldered, insert the SD card and turn the PiFinder on to check that everything works.



Once it has started completely, the :ref:`menu system <user_guide:the menu system>` appears. Use the buttons below the screen to scroll and select. The faceplate shows what each button does.

From the main menu, select Tools, then select Status to open the :ref:`Status screen <user_guide:status screen>`. Check that the PiFinder detects the IMU. The "IMU" lines show some numbers when it does. Then select Objects, select Name Search, and enter a few letters of an object name to test the keypad. The keypad is now working properly.

The UI Hat is now fully assembled. Move on to printing your parts or to :ref:`final assembly <build_guide:assembly>`.

Configurations Overview
========================

You can build the PiFinder in three configurations, so that it works conveniently on a wide range of telescopes.

.. list-table::

   * - 

          Left Handed

     - 

          Right Handed

     - 

          Flat

Any configuration works with any telescope. The camera always needs to face the sky, so the configurations differ in where they put the screen and the keypad for easy access. The Left and Right configurations mainly suit newtonian-style telescopes, such as Dobsonians, whose focuser sits perpendicular to the light path.

The Flat configuration puts the keypad and the screen in easy reach on refractors, SCTs, and other rear-focuser telescopes. When the telescope points upward, the screen tilts towards you for quick access.

All the STL files for the PiFinder case parts are in the main `PiFinder git repo case folder <https://github.com/brickbots/PiFinder/tree/release/case>`_.

Printed Parts
===========================

You can build the PiFinder in a left, right, or flat configuration to suit many telescopes. See the :ref:`configurations overview <build_guide:configurations overview>` for more, including example photos. Each configuration needs only some of the available parts.

Common Parts
-----------------------

Some parts are common to all three configurations. Every build uses the Bezel, the Camera Cover, and the Pi Mount.

Right and Left configurations
^^^^^^^^^^^^^^^^^^^^^^^^^^^^^

The photo below shows all the parts for a left- or right-hand PiFinder. The edge inserts let these pieces assemble into either configuration, so you need just one set of parts whichever side your focuser faces. The assembly guide covers how to orient the pieces as you put them together.



Flat Configuration
^^^^^^^^^^^^^^^^^^

The photo below shows the pieces for the flat version. The parts are the same with or without a PiSugar battery.



Printing
--------

These pieces print without supports in the orientation shown. I use 3 perimeter layers and 15% infill. The parts are small and don't take heavy forces, so almost any print settings work.

Print in a material other than PLA. Your PiFinder probably sees some sunlight, and PLA degrades under moderate heat and UV. PETG or a co-polymer such as NGen is a good choice. Prusament Galaxy PETG is the official PiFinder filament and appears in most of this guide, except where grey provided needed contrast.

Inserts
-------

Only some holes take inserts. The rest take M2.5 screws that pass through into inserts in other pieces. The brass inserts used here are M2.5 x 4mm long. Some go into holes through the full thickness of the piece, and some go into blind holes in the edges. The photos below show each part that takes inserts:

Pi Mount
^^^^^^^^^

The Pi Mount takes eight inserts total: four in the printed stand-offs and four in the edges.





Bottom
^^^^^^^

For left/right builds this is the bottom piece. It needs four inserts to attach the dovetail mount.



Flat Adaptor
^^^^^^^^^^^^^
.. note::
   The photos for the Flat Adaptor and the Back show the v2 build. The v2.5 parts
   are almost identical, but they have 2 camera mount holes rather than 4.

This piece replaces the bottom and back pieces from the left/right build. It needs eight inserts: four to attach the dovetail mount and four to attach the camera.



Back
^^^^^^^^^

The back piece holds the camera for left/right builds. It also reinforces the Pi Mount and the Bottom piece to keep everything square and sturdy. It needs six inserts: four to mount the camera and two in the bottom edge to connect with the bottom piece.



Dovetail Bottom
^^^^^^^^^^^^^^^^

The dovetail bottom has two inserts for the longer 12mm screws that allow angle adjustment. These inserts go in the side opposite where the top piece connects. The screws pass through the top piece and part of the bottom before they engage the inserts. This makes the assembly strong enough to hold the angle you set once the screws are tight enough.



Installation
^^^^^^^^^^^^^

I use a lot of these inserts, so I use a tool to seat them plumb into the parts. I have also done plenty freehand, and it isn't difficult. Use a temperature a bit below your normal printing temperature (I print PETG at 230c and use 170-200c for inserts) and give the plastic time to melt around them.

Insert Inserting

Mounting
--------

Most people print the dovetail mount. It fits the finder shoe included on most telescopes. The angle of the dovetail mount adjusts, so you can set the screen surface roughly vertical and perpendicular to the ground. This puts the IMU into its expected position. The image below explains it more clearly:

Finder shoe angle

Adjustable Dovetail Assembly
^^^^^^^^^^^^^^^^^^^^^^^^^^^^

If you print your own parts, add heat-set inserts as pictured in the photo above. The inserts must go in from the outside of the bottom piece, as pictured. The holes on the inside aren't large enough for inserts. They only let the screws pass through into the inserts.

The photos below show how the pieces fit together. Once assembled, loosen both screws to adjust the angle up to 40 degrees from horizontal, then secure them again. They don't need to be too tight, but they need a bit of friction to hold the angle.









If you need more flexibility, a go-pro compatible plate also bolts into the bottom plate. To use it, add inserts to the mounting footprint on the bottom plate.

Once all the parts are printed and the inserts are seated, you're ready to :ref:`assemble <build_guide:assembly>`.

Rigel Quikfinder Assembly
^^^^^^^^^^^^^^^^^^^^^^^^^

You need the following for a Rigel Quikfinder adapter:

.. list-table::
   :header-rows: 1

   * - Qty
     - Item
     - URL
     - Notes
   * - 1
     - PiToQuikfinder v2 - Part 1.stl
     - `git repo quikfinder <https://github.com/brickbots/PiFinder/tree/release/case/adapters/quikfinder>`_
     - You need both this and the next item
   * - 1
     - PiToQuikfinder v2 - Part 2.stl
     - `git repo quikfinder <https://github.com/brickbots/PiFinder/tree/release/case/adapters/quikfinder>`_
     - You need both this and the previous item
   * - 2
     - heat-set insert M2.5 x 4 mm
     -
     - Same as for the case

Print "Part 2" to maximize the strength of the "hook". Print it with supports, as shown below:



If you print your own parts, add heat-set inserts as pictured below. Space is limited, so fix it to the PiFinder first and then insert the second part. Tighten the screws just a little to hold the second part so it can't fall off.

After you put it on a Rigel Quikfinder base, tighten the screws fully. The double-sided foam adhesive supplied with the Rigel Quikfinder may compress under the weight of the PiFinder, which is about 6 times the weight of a Quikfinder. You may need to fix the base plate to your telescope another way.







To adjust the orientation of your PiFinder so it stands vertical on your telescope, you also need these:

.. list-table::
   :header-rows: 1

   * - Qty
     - Item
     - URL
     - Notes
   * - 1
     - Pi2Q2Dovetail.stl
     - `git repo quikfinder <https://github.com/brickbots/PiFinder/tree/release/case/adapters/quikfinder>`_
     - You need at least this and the next item
   * - 1
     - dovetail_top.stl
     - `git repo dovetail <https://github.com/brickbots/PiFinder/tree/release/case/v2>`_
     - You need at least this and the previous item
   * - 6
     - heat-set insert M2.5 x 4 mm
     -
     - Same as for the case

Add 4 heat-set inserts as shown in the photos below:





Assembly then follows the dovetail assembly in the previous section. You can fix the optional adapter in either of two orientations, depending on your needs. Make sure the "long lip" points in the same direction as the PiFinder. The photos below show the fully assembled adapter:





Once all the parts are printed and the inserts are seated, you're ready to :ref:`assemble <build_guide:assembly>`.

Assembly
======================

Assembly Overview
-----------------

From here you need the M2.5 screws, stand-offs, and thumbscrews, along with the 3d printed parts, the UI Hat, and the camera, lens, and GPS module. Most photos in this part show a build with the PiSugar. If you power the PiFinder another way, the assembly is almost identical.

*In all cases, don't over tighten the hardware.* There's no need, and you could damage the 3d printed pieces, inserts, or screws. Once they feel snug, that's enough. Once everything is in place, the case forms a rigid assembly that easily supports the camera and the other parts.

Pi Mounting
---------------------------

First, mount the Pi and the PiSugar battery to the Pi Mount piece. The photo below shows the pieces you need.

Build Guide Step

Whatever the orientation of your build, the Raspberry Pi and the battery always mount this same way, on top of the posts in the Pi Mount.

If you use a PiSugar, mount the battery pack now. Otherwise, skip this step. Flip the Pi Mount piece over and secure the battery with the zip ties as shown. Don't tighten these much, because that may damage the battery. Tighten them just enough to keep the battery from moving too much.

Orient the battery pack so the connector sits in the notch, as shown below.



Snip off the loose ends of the zip ties, then move on.



Camera Prep
---------------------------

The new v3 camera comes with one of two lens holders already installed. Remove and replace it in either case.

.. include:: includes/camera_prep.rst

Cable Routing
---------------------------

For a flat build, set the camera cable aside, because it routes differently. For left/right builds, it's easier to position the cable roughly now.

Return to the Raspberry Pi assembly and thread the camera cable through as shown. Note the orientation of the silver contacts at each end of the cable. The photos below show the cable routing for left- and right-hand builds.

.. list-table::

   * - 

       Left hand cable routing

     - 

       Right hand cable routing

.. important::
    If you use the recommended PiSugar S Plus, prepare it now.

    * Set the 'Auto Startup' switch on the bottom of the PiSugar to OFF. If you leave it ON, i2c does not work and the PiFinder cannot use the IMU. The orange outline in the image below shows the switch in the correct OFF position.

    * The blue power light on the PiSugar board is very bright. Cover it with black nail polish or destroy it with a soldering iron. Plug the board into the battery and turn it on to confirm the light is subdued. The orange arrow in the image below points to the LED you need to cover. The photo shows it already blacked out with nail polish.

Build Guide Step

The PiSugar ships with a protective film on the screw posts, as shown below. Remove it, or the screws are frustrating to fit.

Build Guide Step

The PiSugar sits under the Raspberry Pi with the gold pogo pins pressed against the bottom of the Pi. The side facing up in the image above presses against the bottom of the Raspberry Pi. The PiSugar documentation covers this in more detail.

Secure the combined PiSugar/RPI stack to the Pi Mount with the 20mm stand-offs. The photos below show the right- and left-hand stacks with their respective cable routing. Flat configurations build the same way, without any camera cable.

.. list-table::

   * - 

          Left hand PiSugar stack

     - 

          Right hand PiSugar stack

   * - 

          Secured with stand offs

     - 

          Secured with stand offs

Right / Left Configuration
---------------------------

Continue here to build a right- or left-hand PiFinder. The build is the same for both versions, with some differences in part orientation. Each step shows photos with the left-hand version on the left and the right-hand version on the right.

Now that the RPI is mounted, secure the Pi Mount to the bottom plate. You can flip the bottom plate so the screen faces the right or the left side, as the two photos below show.

In both cases, the RPI/Screen always faces the same direction as the long, flat side of the bottom piece. The angled cutout is always on the camera side, and the lens faces the angled portion.

.. list-table::

   * - 

     - 

First, screw the Pi Mount assembly to the bottom plate. Use two screws from underneath, running through the bottom plate into the threaded inserts in the side of the Pi Mount piece.

.. list-table::

   * - 

     - 

The back piece is next. First screw in the four short stand-offs that support the camera module. These can go on either side for left- or right-hand configurations. Check the photos below to see how the back piece fits each configuration, then decide which side takes the stand-offs.

.. list-table::

   * - 

     - 

   * - 

     - 

Secure the back piece to the assembly with three M2.5 8mm screws. One goes through the back plate into the side-insert in the Pi Mount. The Pi Mount has one of these inserts on either side, for left- and right-hand builds. The other two go through the bottom plate into the side-inserts on the back plate.

.. list-table::

   * - 

     - 

   * - 

     - 

Now mount the camera module. You need the module, the camera tray, and 2x 12mm M2.5 screws.

.. note::
   The images here show an older back piece and camera tray. New kits have a back piece
   with two holes which match the camera holder. In this simpler arrangement the camera
   tray has two holes through it and does not screw directly to the back piece.
   Longer screws pass through the tray and into the two holes in the back piece to hold
   the camera holder.

Connect the cable to the new camera module first.

.. include:: includes/camera_cable_connect.rst

.. note::
   The photos in the rest of this guide do not yet show the v3 camera.
   The build proceeds just the same, and we will update the photos soon.

Flip the PiFinder over and connect the RPI end of the camera cable. The photo below shows the proper cable orientation into the connector, with the silver contacts facing the white portion of the connector.



The left-hand version needs a twist in the cable before it enters the connector on the RPI. Work gently. You can adjust the twist when you fit the UI Hat later.

.. list-table::

   * - 

     - 

.. note::
   The rest of the build is almost the same for left- and right-hand builds. The photos below mix left and
   right handed builds. Where the difference is important, both appear for clarity.

Next, connect the UI Hat and fit the shroud. Lay the board out as it connects and slide the antenna into the holder on the Pi Mount piece. The ceramic top with the silver dimple needs to face upwards. See the photos below.







.. note::
   The images above show the GPS cable loose and routed incorrectly. Use the
   routing shown in the :ref:`GPS <build_guide:gps>` section.

Now plug the UI Hat carefully into the Raspberry Pi. Make sure both rows of pins line up, and take your time with the camera and GPS cables. The photos below show the cable routing for the left and right configurations.

.. list-table::

   * - 

     - 

The screw holes on the UI Hat should line up with three of the four stand-offs. The fourth provides support but does not secure the outer case. Collect the Shroud, the Bezel, and the cover plate, along with three of the 12mm screws, for the next steps.



The shroud has three optional openings: one on top for the PiSugar power switch, one for the USB ports, and one on the side for easier access to the SD card. Remove these with a little force or a sharp knife. If you use a PiSugar battery, you must remove the power switch tab. See the photo below:



Slide the shroud over the PiFinder, then stack the bezel and the front PCB plate on top. Secure them all with the three screws.









That's looking great. The PiFinder now needs a way to mount to the telescope. The top portion of the adjustable dovetail screws directly to the bottom of the PiFinder. The bottom portion then secures to the top. The orientation of the top part matters, so that the dovetail adjusts the proper way. See the left- and right-hand photos below:





The final dovetail assembly is tricky to photograph on the PiFinder. Follow the photos below and secure the bottom dovetail portion to the top:









That's it! You now have a fully assembled PiFinder.

If you haven't already prepared an SD card, continue to the :doc:`software setup <software>`.



Flat Assembly
----------------

This section covers a Flat build. This configuration is great for refractors, SCTs, and other rear-focuser telescopes. The screen sits 'flat' when mounted and the camera faces forward:

Flat example

Follow the :ref:`general assembly guide <build_guide:assembly>` through to the point pictured below, then return here.

Pi Module Assembled

If you routed the cable as above, pull the camera cable out of the RPI assembly. The routing differs for a flat build.

Collect the flat adapter and the dovetail. The dovetail secures to the underside of the flat adapter with screws through the adapter. The Pi Mount assembly slots into the flat adapter, and screws into the edge inserts hold it there. See the photos below for details.

Assembly Steps

Assembly Steps

Assembly Steps

Assembly Steps

Assembly Steps

Note the one additional screw on the other side, visible in the next photo. Once the Pi Mount is secure in the flat adapter, connect the camera cable to the RPi and to the camera as shown below.

Assembly Steps

Turn the PiFinder around and screw in the three thumbscrews as shown. Check the threads for excess plastic. If you hit resistance, try screwing them in from the other side first to clear any obstruction. Screw them most of the way in, but leave some room for adjustment.

Assembly Steps

Next, position the camera module and secure it with the longer M2.5 screw. Insert the screw through the center hole in the back of the flat adapter and thread it into the center hole in the camera cell. It should screw in 3-4mm and pull the camera cell against the ends of the three thumbscrews. If the cell isn't secure, extend the thumbscrews until they support it. No need to tighten anything too much here. You adjust it again later to align the PiFinder with the optical axis of your telescope.

Assembly Steps

Gently plug in the UI Hat and tuck the cable underneath it. Take your time and make sure the camera cable isn't pinched between the stand-offs and the UI Hat.

Assembly Steps

Assembly Steps

Assembly Steps

Once the UI Hat is plugged in all the way and the cable is tidy, gather the remaining parts to finish the build. The shroud slips over the UI Hat first, then the bezel slots on top, and finally the top PCB. Secure everything together with three of the long screws, as shown in the photos below.

.. note::
   If you haven't already flashed the SD card and inserted it into the Raspberry Pi, do it
   now. The card is harder to reach once the shroud is installed. If you use a PiSugar,
   also check that you have cut and punched the power switch opening out of the shroud.

Assembly Steps

Assembly Steps

Assembly Steps

Assembly Steps

Assembly Steps

One task remains: fit the camera lens. Unscrew the cap from the camera module, but leave the knurled adapter in place. The adapter sets the correct focus distance. Remove the cap from the silver end of the lens and gently screw the two together.

Assembly Steps

Congratulations, you have a PiFinder! See the :doc:`Software Setup <software>` guide for next steps.

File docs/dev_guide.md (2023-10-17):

# PiFinder software development guide

Please see our new documentation at:
[pifinder.readthedocs.io](https://pifinder.readthedocs.io/en/release/dev_guide.html)

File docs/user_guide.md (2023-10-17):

# PiFinder User Manual

Please see our new documentation at:
[pifinder.readthedocs.io](https://pifinder.readthedocs.io/en/release/user_guide.html)

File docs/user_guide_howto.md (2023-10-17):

# PiFinder User Manual - How To

Please see our new documentation at:
[pifinder.readthedocs.io](https://pifinder.readthedocs.io/en/release/user_guide.html#how-to)

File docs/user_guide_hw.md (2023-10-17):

# PiFinder User Manual - Hardware

Please see our new documentation at:
[pifinder.readthedocs.io](https://pifinder.readthedocs.io/en/release/user_guide.html#hardware)

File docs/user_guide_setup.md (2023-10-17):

# PiFinder User Manual - Setup

Please see our new documentation at:
[pifinder.readthedocs.io](https://pifinder.readthedocs.io/en/release/quick_start.html)

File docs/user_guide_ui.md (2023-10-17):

# PiFinder User Manual - User Interface

Please see our new documentation at:
[pifinder.readthedocs.io](https://pifinder.readthedocs.io/en/release/user_guide.html#user-interface)

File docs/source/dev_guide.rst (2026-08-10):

.. _dev_guide:

Contributors Guide
===================

If you'd like to help with developing PiFinder, this is the place 
to start. You don't need to be a developer to help out, as there 
are many ways to contribute to the project. Whether it's improving 
documentation, testing new features, or suggesting ideas, your 
contribution is valuable.

Here are some ways you can get involved:

- **Report Bugs**: If you encounter any issues, report them with detailed steps to reproduce the problem. This helps developers identify and fix bugs quickly.
- **Suggest Enhancements**: Share your ideas for new features or improvements. Your suggestions can help shape the future of PiFinder.
- **Improve Documentation**: Help make the documentation clearer and more comprehensive. If you find something confusing or incomplete, feel free to update it or suggest changes.
- **Translate the user interface**: Since v2.3.0 PiFinder is available in multiple languages. If you want to help with translations, please check the `internationalization`_ section below.
- **Beta Testing**: Try out new features and provide feedback. Testing helps ensure the software is stable and works as expected.
- **Contribute Code**: If you're a developer, you can contribute code by fixing bugs, adding features, or improving existing functionality.

No matter how you choose to contribute, your efforts are greatly appreciated. Join the PiFinder community and help make it even better!

The easiest way to get started is to join the `PiFinder Discord server <https://discord.gg/Nk5fHcAtWD>`_ and ask questions. The community is friendly and always willing to help newcomers. Reporting bugs and suggesting enhancements is also a great way to get involved.

If you have some experience with Unix/Linux and are willing to spend a little more time, you can improve the documentation or be a beta tester. See `beta testing`_ section below for more information.

If you are a developer, like to tinker with the code, troubleshoot your
PiFinder in depth or contribute to the project: this guide helps you to
do all these cool things. 

Submitting issues, bugs and ideas
---------------------------------

Generally the rule applies: if you ask a question or contribute, either 
here in GitHub, via Mail or in the discord channel, the more descriptive
and precise you are, the better. Please always describe exactly what 
you **found**, what you **expected** and how the way is to **reproduce** 
the issue for others. Therefore you can additionally submit error logs, 
show us pictures of the problem or make screenshots. This helps a 
lot to speed up things.

Depending on the complexity of the problem, it is probably wise, 
to discuss the issue on the 
`PiFinder Discord server <https://discord.gg/Nk5fHcAtWD>`_ in advance.  

- If you have a **question**, that is likely to be answered in short, 
  the quickest way is to ask in the 
  `PiFinder Discord server <https://discord.gg/Nk5fHcAtWD>`_ in the 
  section "support-software". There are a lot of users and developers online 
  who can help.

- If you are serious about an **error** or you have seen a **bug**, then 
  please feel free to open a **descriptive issue** here on `GitHub <https://github.com/brickbots/PiFinder/issues/new>`_.  

- Also, if you like to **submit your ideas** or have a wish for the 
  PiFinder, you can use the **issue** page. This helps the developers 
  to sort things out and prioritize. 

Beta Testing
-------------- 

When you look at the `PiFinder GitHub repository <https://github.com/brickbots/PiFinder>`_ you will see, that there are different branches. 
That is the way, how we develop the PiFinder. The main branch is the one, on which development is happening. If you want to test the latest changes, you can
check out the main branch and run its code. For this your PiFinder needs to be connected to the internet, i.e. your WiFi. 
Once you have connected, log into your PiFinder via ssh and run the following commands in the terminal:

.. code-block:: bash

    cd ~/PiFinder
    git fetch --all
    sudo systemctl stop pifinder
    git checkout main
    git pull
    ./pifinder_post_update.sh
    sudo systemctl start pifinder

This will stop the PiFinder, update the code and dependencies to the latest development version and start it again.

If you want to return to the stable version, you can run the following command:

.. code-block:: bash

    ./pifinder_update.sh

If you really, really would like to use bleeding edge code, you can check out a different branch, or checkout one of the forks of the repository.

To list all branches, run the following command:

.. code-block:: bash

    cd ~/PiFinder
    git branch -a

To checkout one of the forks of the repository, run the following commands:

.. code-block:: bash

    cd ~/PiFinder
    git remote add <rname> <url-of-fork>
    git fetch --all
    git checkout -b <branch> <rname>/<branch>

You have to replace <rname> with the name of the remote you added, <url-of-fork> with the URL of the fork you want to check out (you can copy this from github, by pressing on the "code" button), and <branch> with the name of the branch you want to check out. This will create a new branch in your local repository, which follows the branch of the fork you checked out.

To keep up to date with the latest changes in the fork, you can run the following commands:

.. code-block:: bash

    cd ~/PiFinder
    git pull
    cd python
    sudo pip install -r requirements.txt

The last command will install the requirements and only needs to be run occasionally, depending on the changes in the branch. You need to restart the pifinder service to see the changes.

Fork me - getting or contributing to the sources with pull request
------------------------------------------------------------------

If you like to alter or contribute new functionalities, fix errors in the code, 
or even just help with the documentation, best is to **fork** the code 
into your own GitHub account. Also, you can communicate your effort in the 
above mentioned `PiFinder Discord server <https://discord.gg/Nk5fHcAtWD>`_ .

Within your fork, you can do all the fancy changes, you like to see in the 
PiFinder, test them locally. Then you can do a **pull request** to the original 
code of the PiFinder project. If you are a programmer you should already know 
the procedure. If not, here is how you do this: 

* `GitHub Docs - About pull requests <https://docs.github.com/en/pull-requests/collaborating-with-pull-requests/proposing-changes-to-your-work-with-pull-requests/about-pull-requests>`_
* `GitHub Docs - Creating a pull request <https://docs.github.com/en/pull-requests/collaborating-with-pull-requests/proposing-changes-to-your-work-with-pull-requests/creating-a-pull-request>`_
* `Youtube - How To Pull Request in 3 Minutes <https://www.youtube.com/watch?v=jRLGobWwA3Y>`_

Documentation
-------------

The `PiFinder documentation <https://pifinder.readthedocs.io/en/release/index.html>`_
is written in `reStructuredText <https://www.sphinx-doc.org/en/master/usage/restructuredtext/basics.html#external-links>`_ . 
The files are located in PiFinders GitHub repository under ``docs/source`` and have 
the ending ``.rst``. The documentation is then published to `readthedocs.io <https://readthedocs.io>`_, when the change is committed 
to the official GitHub repository (using readthedocs's infrastructure). 

You can link your fork also to your account on readthedocs.io, but it is easier to build the documentation locally. 
For this, install Sphinx and the Read the Docs theme from the pinned
requirements file (run this from the ``docs`` directory):

.. code-block::

    pip install -r source/requirements.txt

You can then use the supplied ``Makefile`` to build a html tree using ``make html`` and running a http server in the directory with the files: 

.. code-block::

    cd build/html; python -m http.server

Reference documentation and AI assistant skills
-----------------------------------------------

Alongside this manual, the repository carries a second layer of documentation
aimed at people working *in* the code rather than reading about the product. It
captures the project's vocabulary and the reasoning behind choices that aren't
obvious from the code alone, and it doubles as guidance for AI coding assistants
working in the repo. Reading the relevant pieces before you change an area saves
you from guessing, and from accidentally renaming a concept the rest of the
codebase depends on.

The domain model
................

PiFinder is split into a handful of *contexts* — distinct slices of the running
system, each with its own vocabulary. This documentation lives under ``docs/`` in
the repository (it is not part of this Sphinx site) and is organised like this:

- ``CONTEXT-MAP.md`` (repository root) — the index of contexts (Catalog,
  Positioning, SQM, Equipment, UI) and how they relate to one another. Start
  here for any cross-context question.
- ``docs/ax/<area>/CONTEXT.md`` — the canonical glossary for each context. These
  define what each domain term means, which words to avoid, and how related
  ideas fit together. When one of these defines a term, prefer it over synonyms
  in your code, comments, commit messages and pull requests.
- ``docs/ax/<area>.md`` — an architecture deep-dive for each context: data flow,
  lifecycle and the gotchas that catch newcomers out. These sit alongside the
  system-wide :doc:`dev_arch` page.
- ``docs/adr/NNNN-*.md`` — short Architecture Decision Records that capture the
  *why* behind a non-obvious or hard-to-reverse choice, so you can tell a
  deliberate decision from an accident.

Keeping everyone on the same words is the point: when the code, the conversation
and the commit history all use the same terms, changes are far easier to discuss
and review. If you find language in the code that conflicts with a ``CONTEXT.md``,
that's worth flagging.

AI assistant skills
...................

If you work with an AI coding assistant such as
`Claude Code <https://www.claude.com/product/claude-code>`_, the repository
bundles a set of *skills* in ``.claude/skills/``. Each one packages a common
PiFinder workflow — the right files, conventions and steps — so the assistant
follows the house way of doing things instead of guessing. They are entirely
optional; you don't need them to contribute, but they save time. Invoke one by
its name (for example ``/docs``):

- **docs** — author and edit this user-facing manual in the house style,
  including building it to check for broken cross-references. See the
  `Documentation`_ section above.
- **grill-with-docs** — stress-test a plan against the domain model described
  above, sharpen the terminology, and update the ``CONTEXT.md`` glossaries and
  ADRs as decisions settle.
- **i18n** — run the translation workflow: mark strings, run the Babel
  extract/update/compile pipeline, and fill in missing translations. See
  `Internationalization`_ below.
- **pifinder-remote** — run PiFinder headlessly and drive it like a user over
  its HTTP API: press keys to navigate the menus, capture the 128×128 screen as
  a PNG, and read live state such as the current solve, location and IMU. Handy
  for reproducing a UI bug or grabbing a screenshot without real hardware.

Internationalization
-----------------------

PiFinder uses ``gettext`` and ``pybabel`` for internationalization.
You can find the information in folder ``python/locale`` in the repository. 
This means that strings that need translation must be 
enclosed in a call to ``_()`` such as ``_("string that needs translation")``. 

As we would like to allow users to switch the language of the user interface from the menu, and with-out restarting PiFinder,
care must be taken, that translations are performed dynamically, i.e. not at load time of python files. 
If you have a variable at package level that needs to be translated, you still need to mark the strings with ``_()``, but make sure 
it is not translated by overriding the ``_()``-function with a local one, that returns the string and then ``del`` that from the context, when you're done.
You can find an example of this in ``menu_structure.py`` at the top and bottom of the file. 

Please also check your unit tests, that these take care of installing ``_()`` into the local context, this can be achieved like this: 

.. code-block::

    import PiFinder.i18n  # noqa: F401

The ``# noqa: F401`` is needed to avoid the linter to remove the line, as the import is not used in the code.

Translating the user interface
.................................................

The translation files are located in the subdirectories in the ``python/locale`` folder. The files that need to be edited are the 
``messages.po`` files, in the respective subfolder with the language code, which is the respective ISO 639-1 code. These folders
also contain the compiled ``.mo`` files, which are binary representations of the translation and are used by the PiFinder software.

When you edit the files, check for each entry that has a ``msgstr ""`` line, which means the string is not translated yet.
You also need to check the translations of strings marked as "fuzzy". You need to remove the "fuzzy" line, once you have checked the translation.

In order to run the PiFinder software with the latest translation, you need to run the following commands: 

.. code-block::

    cd ~/PiFinder/python
    sudo pip install -r requirements_dev.txt
    nox -s babel 

The ``pip`` command installs the dependencies for the translation, the second command runs the babel toolchain to extract the strings 
to translate and update the .po files. This also compiles the .po files into .mo files, which are then used by the PiFinder software.

So if you want to test your translations, you need to run the ``nox`` command every time you change the .po files, then restart the PiFinder software:

.. code-block::

    nox -s babel
    sudo systemctl restart pifinder

Please post the changed po files in the Discord channel "translation" and we will include it in the next release.

Setup the development environment
---------------------------------

On the PiFinder
..................

The best development platform for the PiFinder is the PiFinder itself via SSH or with a 
monitor keyboard attached.  This will let you develop and test any part of the code. 

See the :ref:`software:build from scratch` section of the Software Setup guide for 
information on creating a base SD card and getting the base software running.

Other Options
................

Second to this is a standalone Raspberry Pi hooked up to a keyboard and monitor.  This
will make sure your code will run on the PiFinder, but you won't be able to test the 
IMU, GPS or other physical hardware features.  You can emulate these using the 
`--fakehardware` and `--display` flags.  See below for more details.

You can also develop on any Posix compatible system (Linux / MacOS) in roughly the 
same way you can on a Raspberry Pi.  The emulated hardware and networking features 
will work differently so this is mostly useful for UI/Catalog feature development.

Note that you can develop on Windows by activating Windows Subsystem for Linux (WSL2) 
and installing Ubuntu from the Microsoft Store. The window launched by PiFinder will 
be fully integrated into your windows desktop. 

To get started, fork the repo and set up your virtual environment system of choice
using Python 3.9.  Then follow some of the steps below!

Install python dependencies
...........................

For running PiFinder, you need to install some python libraries in certain
versions. These lists can be installed via 
`pip tool chain <https://pypi.org/project/pip/>`_  and are separated in two
files: one for getting PiFinder to run, one for development purposes:

.. code-block::

    pip install -r requirements.txt
    pip install -r requirements_dev.txt

Hipparcos catalog
.................

The `hipparcos catalog <https://www.cosmos.esa.int/web/hipparcos>`_
(``astro_data/hip_main.dat``) now ships in the repository, so no separate
download is required. If you ever need to refresh it, it can be re-fetched
from:

.. code-block::

    wget -O astro_data/hip_main.dat https://cdsarc.cds.unistra.fr/ftp/cats/I/239/hip_main.dat

Install the Tetra3/Cedar solver
................................

The `Tetra3 Solver <https://github.com/esa/tetra3>`_ is a "fast lost-in-space
plate solver for star trackers written in Python". It is the next gen solver, that PiFinder uses.

This is set up as a git submodule and you will need to initialize it using the following
command from with your checked out repo

.. code-block::

    git submodule update --init --recursive

Code Quality Automation
-----------------------

The PiFinder codebase includes features for maintaining code quality,
adherence to style guide and for evaluation and testing.  These will
be installed along with the dev dependencies and should be available
to run immediately.

NOX
....

We use `Nox <https://nox.thea.codes/en/stable/>`_ as an entrypoint to all of 
the code quality tools. Simply run ``nox`` to from the ``PiFinder/python`` 
directory and it will run (almost) all of the code quality checks and tests.

The first time it runs Nox will set up suitable environments for each session
it manages and this might take a bit.  Subsequent runs will be much faster.

To see what sessions are available use ``nox -l``

To run only a specific session use ``nox -s [session_name]``

The defined sessions are:

- lint -> Runs `RUFF <https://docs.astral.sh/ruff/>`_ using ``ruff check --fix`` to 
  check/fix common code issues.  It may produce warnings or fail completely if 
  there are issues with new code you are working on.  See the documentation for 
  details on any errors it finds.

- format -> Runs ``ruff format`` to reformat code in the Black style. 

- type_hints -> Runs `my[py] <https://mypy.readthedocs.io/en/stable/>`_ to do static
  type analysis.  The PiFinder code is not fully typed (yet!) but we are working on it
  and any new contributions will need to be fully annotated.  If you've not worked
  with type-hinted Python before, we'll help you out, so feel free to put up PR's 
  for non-type-hinted code and we can collaborate.

- smoke_tests -> Runs `PyTest <https://docs.pytest.org/en/8.2.x/>`_ and executes
  all tests marked SMOKE.  Smoke tests should be FAST and provide some basic 
  checking of sanity/syntax.

- unit_tests -> Runs PyTest and executes all tests marked as UNIT.  Unit tests 
  should exercise more functionality and make take a bit more time.  This Nox
  session is not run by default, but is executed on code check in to the PiFinder
  repository.

- ui_tests -> Runs PyTest against the UI module smoke harness
  (``tests/test_ui_modules.py``).  It builds every UI screen through a real
  ``MenuManager`` and exercises each screen's key handlers as a crash-only smoke
  test.  Because it builds the real catalogs and may download ``hip_main.dat`` on
  first run, it is heavier and more network-dependent than the unit suite, so it
  lives in its own session and is not run by default.

- babel -> Runs the complete toolchain for internationalization (based on `pybabel`).
  That means extracts strings to translate and updates the `.po`-files in `python/locale/**`
  Then these are compiled into `.mo`-files. Unfortunately, this changes the `.mo`-files in any case,
  even if the there have been no changes to strings or their translation. As this will show up 
  as changes to checked-in, this is not run by default.

- web_tests -> Runs PyTest and executes all tests marked as WEB. Web tests use Selenium 
  to automate browser testing of the PiFinder web interface. These tests require a 
  running Selenium Grid server and a running PiFinder web server. You can test against a real PiFinder 
  or a locally running instance. See the sections below for setup instructions. 

CI/CD
.......

All pushes to the PiFinder repository will run all the defined Nox sessions. Automations
for PR's will need to be triggered by a maintainer, but you can (and should!) set up 
your fork to run the existing automation to validate your code as you develop.

If you need help, reach out via email or discord.  We are happy to help :-)

Website Tests
.............

The PiFinder web interface can be tested using automated browser tests powered by Selenium.
These tests verify functionality across different viewports (desktop and mobile) and ensure
the web interface works correctly.

The tests exercise the remote control features of PiFinder, changing **the state of the PiFinder** and
therefore should **not be run** against a PiFinder you are actively using for observing.

.. tip::

    Note that the whole test suite runs approximately 20 min.

Running Website Tests locally
_______________________________

You can run ``pytest -m web --browser <browser> --local`` to run the website tests locally. 
This will have Selenium launch a browser on your local machine and run the tests against a locally running instance of PiFinder. 
The respective browsers need to be installed on your machine. Recognized browsers are ``chrome``, ``firefox`` and ``safari``. 

Note that when running the tests on Safari, you need to enable "Allow Remote Automation" in the Develop menu of Safari. In addition Safari
does not support the "headless" mode, so you will see the browser window when running the tests and you cannot use other windows while the tests are running.

If you want to run the tests against a real PiFinder, set the ``PIFINDER_HOMEPAGE`` environment variable to the URL of your PiFinder instance or 
pass the URL directly as a command line parameter with ``--url``. The PiFinder instance needs to be in the same WiFi as your machine, so that it is 
reachable via the network.

Running Website Tests remotely
________________________________

Using Selenium Grid you can set up servers with different operating systems and different browsers to run your tests in parallel. 
As the PiFinder is designed to have only one client accessing the web interface at a time, we recommend to run one Raspberry Pi per computer 
instance and browser in the grid. You can install the software on bare bones Raspberry Pi and fake the non-existing hardware.  
Or you can test against real PiFinders. 

In the following we describe a simple setup with Selenium Grid running locally and running tests againt a locally running instance of PiFinder. 
You can easily adapt this to more complex setups, e.g. by running the Selenium Grid server on a different machine or testing against a real PiFinder. 

Running against a locally running instance at localhost:8080:

.. code-block:: bash

    cd ~/PiFinder/python
    . .venv/bin/activate # Optionally active your virtual environment
    export SELENIUM_GRID_URL=<your selenium grid url which ends in /wd/hub> # Optional, default is http://localhost:4444/wd/hub
    nox -s web_tests

If you want to test against a real PiFinder, set the ``PIFINDER_HOMEPAGE`` environment variable to the URL of your PiFinder instance:

.. code-block:: bash

    cd ~/PiFinder/python
    . .venv/bin/activate # Optionally active your virtual environment
    export SELENIUM_GRID_URL=<your selenium grid url which ends in /wd/hub> # Optional, default is http://localhost:4444/wd/hub
    export PIFINDER_HOMEPAGE=http://pifinder.local # Change to the URL of your PiFinder, which needs to be in the same WiFi
    nox -s web_tests

If you run the tests with-out a working Selenium Grid instance, the tests will all be skipped. 
You can also run individual tests with PyTest directly, use ``SELENIUM_GRID_URL=... PIFINDER_HOMEPAGE=... pytest tests/website/test_file.py``.

Note that due to the tests depending on the response times of the PiFinder web server and the Selenium Grid server, there may be occasional timeouts or failures.
If you encounter such issues, simply re-run the tests. We need to strike a balance between test speed and reliability, and this may require some tuning in the future.

Setting up Selenium Grid
___________________________

If you choose to run the website tests using a Selenium Grid server, the easiest way is to download the Selenum Grid server jar 
from the selenium website, see https://www.selenium.dev/downloads/ and run it with Java:

.. code-block:: bash
  
    java -jar selenium-server-<version>.jar standalone

If you run the Selenium Grid server this way, the browsers need to be installed on the same machine. 
You'll have to consult the Selenium documentation for setting up a more complex grid with different machines and browsers.

Running/Debugging from the command line
---------------------------------------

When you installed all the dependencies, you like to develop and test your
code. You like to see debugging information and all verbose messages. You
probably like to save this information into a file. 

Therefore, switch to the ``~/PiFinder/python`` folder and start the PiFinder
python program with the command line parameters you need for the certain use case. 

.. code-block::

    cd /home/pifinder/PiFinder/python
    python3 -m PiFinder.main [command line parameters]

You simply stop the program with "Ctrl + C".

**Remember**: PiFinder is designed to automatically start after boot. So a
PiFinder process is likely running. Before you can start a PiFinder process for
testing purposes from the command line, you have to stop all currently running
PiFinder instances. Simply, because you can not run multiple PiFinder instances
in parallel. They would try to access the same hardware, which is not possible.
You can do this e.g. with the following code, which uses awk to kill all running processes of
PiFinder:

.. code-block::

    ps aux | grep PiFinder.main | awk '{system("kill -9  " $2)}'

Running cedar-detect-server
.............................

You will need to start the ``cedar-detect`` process manually, if your development machine is not a PiFinder, 
as it is started as a separate process on the PiFinder starting with v2.4.0. 
You can do this by running the following command in another terminal window:

.. code-block::

    cd /home/pifinder/PiFinder/bin
    ./cedar-detect-server-<your arch> -p 50551

-h, --help | available command line arguments
.............................................

Run ``PiFinder.main`` with the ``-h`` flag to print every available option:

.. code-block::

    python3 -m PiFinder.main -h

.. note::

   The set of command line flags changes between releases, so rather than
   reproduce the full list here it is best to consult the real output of
   ``-h``.  The flags you'll reach for most often are described in their own
   sections below.

-x, --verbose | debug information
.................................

You enable the debug information output simply by passing the '-x' flag.

.. code-block::

    pifinder@pifinder:~/PiFinder/python $ python3 -m PiFinder.main  -x
    Starting PiFinder ...
    2024-03-17 11:31:26,285 root: DEBUG using pi camera
    2024-03-17 11:31:26,383 PiFinder.manager_patch: DEBUG Patching multiprocessing.managers.AutoProxy to add manager_owned
    2024-03-17 11:31:26,431 root: DEBUG Ui state in main is{'observing_list': [], 'history_list': [], 'active_list': [], 'target': None, 'message_timeout': 0}
    Write: Starting....
    Write:    GPS
    Write:    Keyboard
    2024-03-17 11:31:28,544 root: DEBUG GPS waking
    [...]

--display DISPLAY
..........................

Start the PiFinder software with a particular display device.  This is useful
for developing on a different posix system like MacOS or Linux.  Available options
are:

- ssd1351 - This is the standard 1.5" OLED screen (DEFAULT)
- pg_128 - PyGame emulated 128x128 display.  Use this for developing/testing
  PiFinder code on a laptop or desktop.

-c CAMERA, --camera CAMERA
..........................

Use the "fake" camera module, so the PiFinder camera is not physically necessary
for testing purposes. Else specify which camera to use: pi, asi, debug or none.

.. code-block::

    python3 -m PiFinder.main -k local --camera debug -x

-fh, --fakehardware | imu, gps only
...................................

This uses fake hardware for the imu and gps. On its own this emulates
rev3 hardware, with no battery indicator; add ``--fakebattery`` to
emulate rev4.

.. code-block::

    python3 -m PiFinder.main -fh -k local --camera debug -x

-fb, --fakebattery
..................

With ``--fakehardware``, runs the fake battery monitor and enables the
rev4 battery indicator.

.. code-block::

    python3 -m PiFinder.main -fh -fb -k local --camera debug -x

-k KEYBOARD, --keyboard KEYBOARD
................................

A switch between the pi keyboard (on a real device), the local keyboard
(eg Mac with emulated screen) or via a webserver. That last one will probably
be retired because the remote server is always started.

.. code-block::

    python3 -m PiFinder.main -fh -k server --camera debug -x

Troubleshooting
---------------

Shared Memory location already exists
.......................................

It can happen that during development the shared memory location 
``//cedar_detect_image`` is not cleaned up properly, e.g. because of a crash. 
In this case, you can simply remove the shared memory location with the following command: 

.. code-block:: bash

    sudo rm /dev/shm/cedar_detect_image

on Linux or with the following command on MacOS:

.. code-block:: bash

    python -c "import _posixshmem; _posixshmem.shm_unlink('//cedar_detect_image')"

My app crashes
..............

When crashing, there are many unrelated stack traces running. Search for the
relevant one. The rest is not important, these are the other threads stopping.

Test the IMU
............

First power up the unit and look at the Status page while moving it around. The
status screen is part of the :ref:`user_guide:tools` menu.



If the IMU section is empty ("- -") or does not move, it is likely, that either
the IMU is defect or you have a problem on your board.

1. Please check, if the board is soldered all pins correctly and did not shorten anything (spurious lead). 
2. If you sourced the parts by you own, it might be, that you bought the wrong
   IMU hardware version. You need the 4646 version. On the non-stemma QT versions,
   the data pins are switched. 
   `See here on Discord <https://discord.com/channels/1087556380724052059/1112859631702781992/1183859911982055525>`_. 
3. The IMU is defect. 

If the IMU is defect, this only can be tested by removing the faulty hardware and replacing it with another one. 

The demo mode - it is cloudy, but I like to test my PiFinder anyways
....................................................................

Using the **demo mode** you will be able to run the PiFinder and almost all it's functionality, but not under the stars. Therefore the PiFinder get's an image of the sky from the disc instead from the camera and uses it. You can use all PiFinder commands, like searching for an object, you see the IMU run and you get a "fake" GPS signal. You also can check the PiFinder keyboard and the complete menu cycle. 

There are a few ways to enter this 'test' (or 'debug') mode.

The easiest is from the menu: open **Tools › Test Mode**. This supplies a fake
GPS lock and time and has the PiFinder solve a stored image from disk instead of
the camera, while still responding to IMU movement, so Push-To and everything
else that needs a solve/lock keeps working.

You can also toggle it from the **Console screen**: open **Tools › Console**,
then press **0** (the display shows "Debug: true"). Press **0** on the Console
screen again to leave it (the display shows "Debug: false").

Finally, you can start straight into this mode from the command line — see the
:ref:`dev_guide:Running/Debugging from the command line` section above.

.. note::

  If you are using the demo-mode and move the PiFinder and telescope around, you will notice, that the picture alway starts at the same "standard demo picture". And it always switch back to the same picture, once you stopped. Do not expect to move through the sky, like you normally would do and get a solve to the newly reached location. You will always be brought back to the same position in the sky.





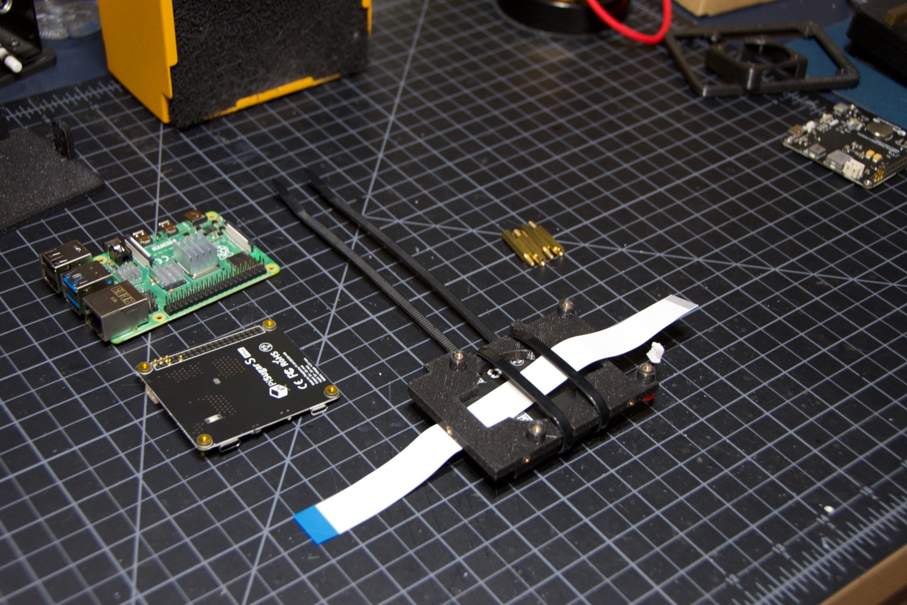
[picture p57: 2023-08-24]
docs/source/images/build_guide/cable_routing_right01.jpeg

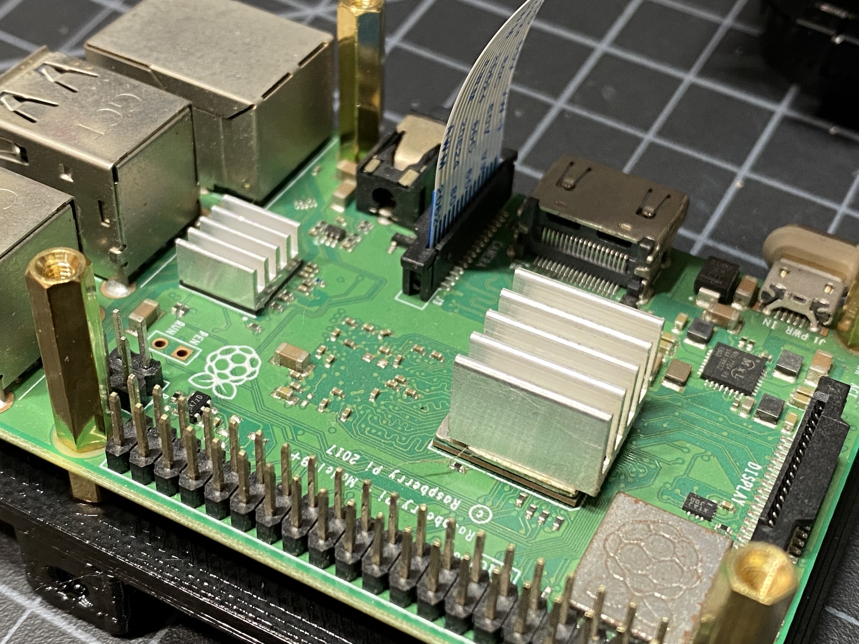
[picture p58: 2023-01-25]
images/build_guide/IMG_4690.jpeg

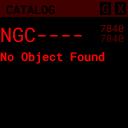
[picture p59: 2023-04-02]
images/screenshots/how_to_see_CATALOG_001.png

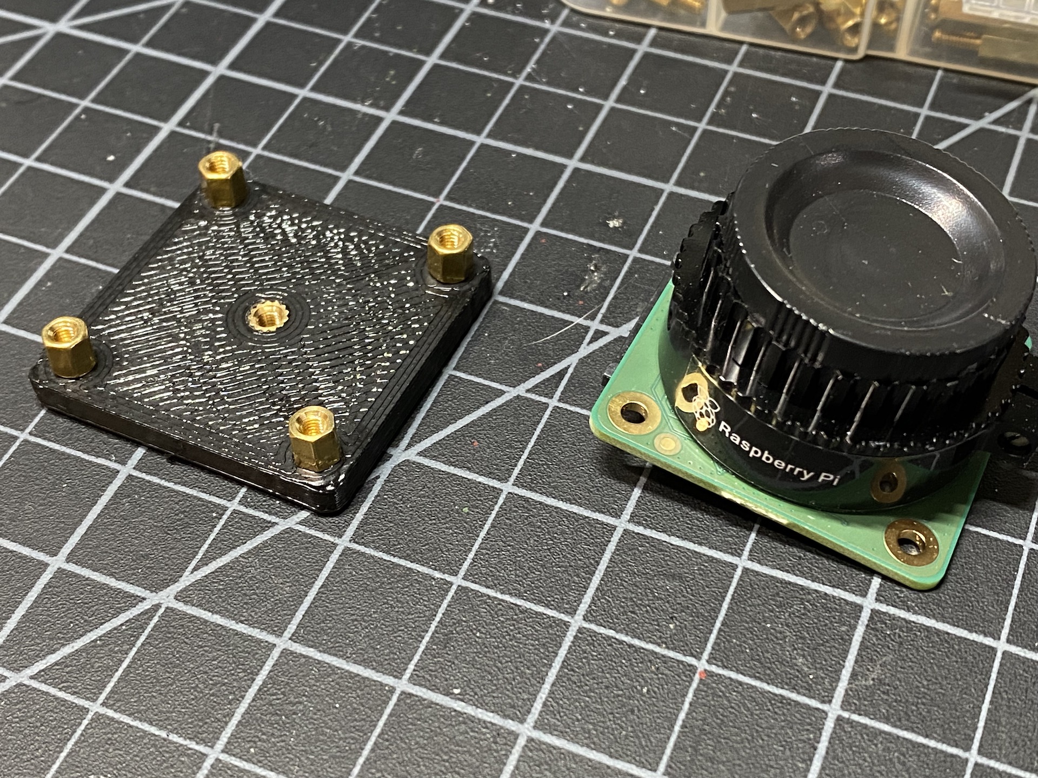
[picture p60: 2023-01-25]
images/build_guide/IMG_4707.jpeg

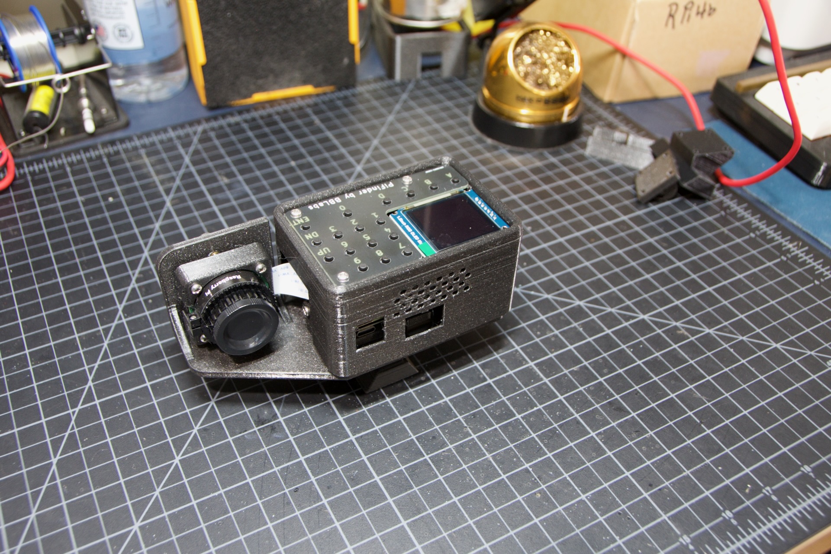
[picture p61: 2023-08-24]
images/build_guide/v1.6/flat/flat_build_guide_18.jpeg

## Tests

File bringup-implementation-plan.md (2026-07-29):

# `PiFinder.bringup` — implementation plan

Bench validation for freshly assembled rev4 boards: one command, one screen, every
listed subsystem exercised while the builder watches. Product of a grilling session
against the domain docs — the glossary it uses is
[`docs/ax/bringup/CONTEXT.md`](docs/ax/bringup/CONTEXT.md).

## 1. What it is

```
$ python -m PiFinder.bringup
```

A **single process** that opens the panel directly, drives the keypad backlight and
buzzer, interrogates the IMU and charger, and scans the keypad matrix — reporting
everything on one live screen. It does **not** boot the application: no
`SharedStateObj`, no catalogs, no solver, no camera, no `MenuManager`. It runs on a
card with nothing configured yet and is ready in about a second.

Six **checks**, in three kinds (the distinction the exit status turns on):

| Check | Kind | What proves it |
|---|---|---|
| `SCREEN` | witnessed | Test patterns then the live dashboard — builder's eyes |
| `BACKLIGHT` | witnessed | Continuous brightness ramp — builder's eyes |
| `BUZZER` | witnessed | Startup earcon + one per keypress — builder's ears |
| `IMU` | **probed** | BNO055 answers its chip-identity register; quaternion moves when tilted |
| `CHARGER` | **probed** | BQ25895 part-number register reads `0b111`; live voltages decode |
| `SWITCHES` | **exercised** | Every populated matrix position observed closing |

Only **probed** and **exercised** checks gate the verdict and the exit status.
Witnessed checks are reported as *emitted* — the program drove the hardware; whether
light or sound came out is not something it can know.

## 2. Decisions

| Decision | Choice | Why |
|---|---|---|
| Relationship to the app | Standalone module, `python -m PiFinder.bringup` | Works on a bare card before catalogs/cedar-detect exist; `splash.py` is the precedent |
| Name | `bringup`, not `hw_test` | `hw_test.py` matches pytest's `*_test.py` discovery and reads as a test file inside the package; "bring-up" is the industry term and gives docs a noun |
| Keypad input | Raw matrix scan in `bringup` | Proves each *switch* and its row/col wiring; immune to chording/long-press/auto-repeat, which would otherwise mask faults |
| Matrix tables | Extracted to a new import-safe `PiFinder/keypad.py` | One source of truth for the wiring; `keyboard_pi` can't be imported off-Pi (`libinput`, `RPi.GPIO`) |
| Panel selection | **Fixed rev4 default**, `--display` override | `main`/`splash` derive the panel from the charger probe; on a board under bring-up that makes a dead charger look like a dead screen |
| Screen proof | Pattern sequence, then dashboard | Dashboard alone can't reveal offset/rotation, edge pixels or wrong channel order |
| Sound + backlight | Wired into the button test | Startup earcon proves the buzzer at once; a keypress earcon per closure re-proves it ~18×; a ramping backlight makes a dim string obvious |
| Verdict | PASS banner + exit status | Scriptable later without redesign |
| Scope | The six checks only | Camera/GPS/wifi are separate bench steps with different rigs |

Declined during grilling: an ADR for the panel decision (the rationale goes in the
module docstring instead), and rewriting the build guide (follow-up).

## 3. Files

| File | Change |
|---|---|
| `python/PiFinder/keypad.py` | **New.** Import-safe matrix tables + population maps |
| `python/PiFinder/keyboard_pi.py` | Read the tables from `keypad.py`; no behaviour change |
| `python/PiFinder/bringup.py` | **New.** The entry point |
| `python/tests/test_bringup.py` | **New.** Pure-logic and layout tests |
| `docs/ax/bringup/CONTEXT.md` | **New.** Glossary (done — this PR) |
| `CONTEXT-MAP.md` | Bring-up context + relationships (done — this PR) |
| `docs/ax/ui/CONTEXT.md` | Keypad layout corrected to 5 columns / both revs (done — this PR) |

## 4. `PiFinder/keypad.py` (new, import-safe)

`keyboard_pi.py` imports `libinput` and `RPi.GPIO` at module scope, so it cannot be
imported on a dev box — which rules out importing the tables from it, both for
`bringup` (which must run headless for layout work) and for unit tests. Lift the pure
data into its own module, importing only `KeyboardInterface` (which is import-safe):

```python
"""Keypad matrix wiring: the physical truth shared by the keyboard scanner
and bring-up. Pure data, import-safe everywhere (no RPi.GPIO, no libinput)."""

from PiFinder.keyboard_interface import KeyboardInterface as K

MATRIX_ROWS = [19, 17, 18, 22, 20]      # BCM, driven LOW one at a time
MATRIX_COLS = [16, 23, 26, 27, 21]      # BCM, read with pull-ups
POWER_GPIO = 15                          # direct, not in the matrix

KEYMAP      = [...]   # 25 entries, moved verbatim from KeyboardPi.__init__
ALT_KEYMAP  = [...]
LONG_KEYMAP = [...]

def position(row: int, col: int) -> int:
    """Matrix position -> keymap index."""
    return row * len(MATRIX_COLS) + col

# Population maps: which positions carry a switch on each revision.
# rev3: cols 0-3 of every row (17 switches, 3 NA holes).
# rev4: rows 0-3 of cols 0-3, plus ALL of col 4 — the directional cluster
#       moved off the bottom row and gained its own centre SQUARE (18).
REV3_POPULATED = frozenset(...)
REV4_POPULATED = frozenset(...)
```

`KeyboardPi.__init__` then becomes `self.rows = keypad.MATRIX_ROWS`, etc. Its derived
`square_keycodes` / `repeat_keycodes` comprehensions keep working unchanged, since
they read `self.keymap`.

**The population maps are the load-bearing new fact.** From the 25-entry keymap:

```
       col0  col1  col2  col3    col4
row0    7     8     9    (na)    UP     ┐
row1    4     5     6    PLUS    LEFT   │ col4 = the cluster
row2    1     2     3    MINUS   DOWN   │ added for rev4, with
row3   (na)   0    (na)  SQUARE  RIGHT  │ a centre SQUARE
row4    LEFT  UP    DOWN  RIGHT  SQUARE ┘
        └─ rev3 directional row ─┘
           (unpopulated on rev4)
```

rev4 = 13 (calculator pad) + 5 (col 4) = **18 switches, two `SQUARE`s**. Note that
`(4,4)` *is* populated on rev4 — only cols 0–3 of row 4 are rev3-only. Getting this
wrong in either direction breaks the verdict: too many expected and PASS never
arrives; too few and a dead switch passes silently. **Confirm against the first
board** (see §10).

## 5. `PiFinder/bringup.py` structure

Follows `sound.py`'s discipline — pure logic separated from thin hardware seams, so
the interesting parts are unit-testable off-Pi and every hardware import is lazy.

```
bringup.py
├── module docstring ......... carries the panel-choice rationale (no ADR)
├── pure logic (testable off-Pi, no imports beyond stdlib/PIL)
│   ├── parse_pwm_overlay(config_txt) -> dict[channel, gpio]
│   ├── GridState .............. seen/held sets, press/release edges
│   ├── CheckResult / Kind ..... probed | exercised | witnessed
│   ├── compute_verdict(results) -> bool     # witnessed excluded by construction
│   ├── grid_layout(display) -> GridLayout   # derives from resolution
│   └── format_summary(results) -> str
├── hardware seams (constructed only on real hardware)
│   ├── BacklightPWM ........... PWM ch1, mirrors sound.BuzzerPWM
│   ├── MatrixScanner .......... GPIO row/col scan + power line
│   ├── ImuProbe ............... wraps imu_pi.Imu
│   └── ChargerProbe ........... wraps battery_bq25895.BQ25895
├── rendering
│   ├── draw_patterns(display) ......... the witnessed screen sequence
│   └── draw_dashboard(display, state) . title + status rows + grid
└── main(argv) ....... argparse, lock, preflight, run loop, summary, exit code
```

### Reuse

| From | Used for |
|---|---|
| `displays.get_display(name)` | Panel driver; `--display` accepts every existing name (`ssd1333`, `ssd1351`, `pg_176`, `headless_176`…) |
| `display.fonts` / `display.colors` | Text metrics and the red mask, so bring-up looks like the product |
| `ui.layout.rows_below_titlebar` | Status-line y-positions |
| `ui.layout.center_box_row` | One call per grid row — replaces per-screen centring math |
| `sound.BuzzerPWM`, `play_earcon`, `CATALOG`, `Earcon` | Buzzer; earcons from the catalog, never raw tones |
| `battery_bq25895.BQ25895`, `REG14`, `EXPECTED_PN` | Charger comms + live decode |
| `imu_pi.Imu` | IMU; its `adafruit_bno055` constructor validates the chip id and raises on mismatch — that *is* the comms proof |
| `utils.acquire_single_instance_lock()` | Refuse to run while the service holds the device |
| `keypad.*` | Matrix wiring and population maps |

Not reusable as-is: `main.py`'s `init_keypad_pwm` / `set_keypad_brightness` depend on
a `HardwarePWM` global imported inside main's `__main__` block (`main.py:1284`), so
bring-up needs its own ~12-line `BacklightPWM` seam. That seam is a candidate answer
to the standing `TODO` at `main.py:78` ("Keypad pwm class that can be faked maybe?"),
but adopting it in `main` is out of scope here.

## 6. The screen

```
┌────────────────────────┐
│ BRING-UP        rev4   │  title bar (inverts to "PASS" on verdict)
│ IMU  ok  cal2 q+0.71   │  status rows — rows_below_titlebar(small font)
│ CHG  ok  4.02V  PG     │
│ SW   13/18      PWR ·  │
│ ┌──┬──┬──┬──┬──┐       │
│ │7 │8 │9 │  │^ │       │  5×5 grid — center_box_row per row
│ ├──┼──┼──┼──┼──┤       │
│ │4 │5 │6 │+ │< │       │  cell states:
│ ├──┼──┼──┼──┼──┤       │    unpopulated  nothing
│ │1 │2 │3 │- │v │       │    unseen       dim outline + label
│ ├──┼──┼──┼──┼──┤       │    seen         bright outline + label
│ │  │0 │  │□ │> │       │    held         filled, label knocked out
│ ├──┼──┼──┼──┼──┤       │
│ │  │  │  │  │□ │       │  row4: only col4 populated on rev4
│ └──┴──┴──┴──┴──┘       │
│        [ PWR ]         │  power switch, its own cell (GPIO15 direct)
└────────────────────────┘
```

Separating **held** from **seen** is deliberate: a switch that reads permanently
closed is a solder bridge, and a switch that closes but never releases is a mechanical
fault. Both are build defects a press-counter alone would score as a pass.

Geometry derives from the display instance (ADR 0009), never hardcoded — cell size
falls out of `(resY - grid_top - 5*gap) // 6`. Fits 128×128 (≈12 px cells) and
176×176 (≈18 px cells); a unit test asserts no overflow on both.

**Pattern sequence** (≈4.5 s at entry, `--no-patterns` to skip, `--pattern-loop` to
repeat forever for panel-only work):

1. Full-field fill — dead pixels, uniformity
2. 1 px border + corner ticks + centre cross — full extent, offset, rotation
3. R | G | B vertical stripes — channel order, catches a wrong-BGR or wrong panel part

Patterns draw raw RGB, bypassing the red `Colors` mask — the point is to prove all
three channels reach the glass, even though the product only ever shows red.

## 7. Checks in detail

**Pre-flight** (before anything else, reported on its own line)

- `/dev/i2c-1` present → IMU and charger can be reached at all.
- PWM routing, parsed from `/boot/config.txt` (and `/boot/firmware/config.txt`):
  `dtoverlay=pwm,pin=13,func=4` routes **ch1 → GPIO13** only; the buzzer needs
  **ch0 → GPIO12**, i.e. `dtoverlay=pwm-2chan,pin=12,func=4,pin2=13,func2=4`.
  This matters because the Pi's PWM block always exposes two channels, so
  `HardwarePWM(pwm_channel=0)` **exports successfully and drives no pin** — a silent
  no-sound indistinguishable from a dead buzzer. Bring-up must say
  `PWM ch0 not routed to GPIO12 — buzzer cannot sound (add pwm-2chan)` instead of
  failing `BUZZER`. See §10: this repo's `pifinder_setup.sh` provisions only the
  single-channel overlay.

**SCREEN** (witnessed) — pattern sequence, then the dashboard is its own ongoing proof.

**BACKLIGHT** (witnessed) — `BacklightPWM` on ch1, sawtooth 0 → ~12 % → 0 over ~2 s,
stepped once per frame. A ramp beats a static level: a dim or partially-lit LED string
is obvious against a sweep and invisible against a fixed brightness. (12 % is main.py's
documented effective ceiling; re-confirm for rev4.)

**BUZZER** (witnessed) — `Earcon.STARTUP` once at entry at level `"5"`, then
`Earcon.KEYPRESS` on every new closure, so the buzzer gets re-proved ~18 times during
the switch sweep. Skipped with a clear reason if pre-flight says ch0 isn't routed.

**IMU** (probed) — construct `imu_pi.Imu()`; `adafruit_bno055` reads and validates the
BNO055 chip id in its constructor and raises on mismatch, so construction succeeding
*is* the comms proof. Then `imu.update()` per frame, showing calibration status and
the live quaternion so tilting the board visibly moves the numbers — that catches a
part that ACKs but sits in a bad mode, which a bare presence probe would pass.
PASS = constructed **and** at least one non-`None` quaternion.

Watch: `Imu.__init__` builds a `config.Config()`, which pulls in `equipment`/`locations`.
It tolerates a missing config file, so a fresh card is fine — but if it proves fragile
during bring-up, fall back to constructing `adafruit_bno055.BNO055_I2C(board.I2C())`
directly, which loses only the moving/threshold logic bring-up doesn't need.

**CHARGER** (probed) — construct `BQ25895()`, read `REG14`, check
`(reg14 >> 3) & 0b111 == EXPECTED_PN`. That identity check is stronger than the bare
ACK `hardware_detect` uses, and it is the right depth for bring-up. Then `read_state()`
about once a second for live battery/VBUS/SYS voltage and charge status.
**Strictly read-only**: `read_state()`'s one-shot ADC trigger is the sanctioned write
(ADR 0006); `apply_charging_config()` is never called — setting charge current belongs
to the monitor process (ADR 0017), not to a diagnostic.
PASS = part number matches.

**SWITCHES** (exercised) — the matrix scan mirrors `KeyboardPi.run_keyboard`: drive one
row LOW as an output, read all columns (pull-ups, active low), restore the row to
input. No debounce beyond the frame, no chord or long-press interpretation — bring-up
wants the raw edge. The power switch is read directly from `POWER_GPIO`, active low,
with no 1 s hold requirement (a brief tap lights it, which also keeps the press short).
PASS = every position in the revision's population map observed closed at least once,
power switch included.

Loop: scan at ~60 Hz like the shipping scanner; redraw at ~12 fps to keep SPI traffic
reasonable.

## 8. Lifecycle and guardrails

- **Single-instance lock.** Takes the same `utils.acquire_single_instance_lock()` as
  `main.py`, so it refuses to start while the service holds the panel, PWM and I²C —
  and says `stop the pifinder service first: sudo systemctl stop pifinder` rather than
  producing a garbled screen and confusing readings.
- **Never acts on the power switch.** No shutdown jump, no `jump_to_label`, and nothing
  anywhere near GPIO14 — pressing power during bring-up only lights a cell.
- **Never writes config**, never writes the charger's power path, never touches OTG/HIZ.
- **Ignores `Config` entirely** for its own behaviour: a board under bring-up has no
  user config yet. Consequence: it opens the panel unrotated, so a Bloom/Heart build
  shows the dashboard inverted — `--rotate {0,1,2,3}` covers that.
- **Cleanup in `finally`.** Both PWM channels stopped (buzzer silent, backlight off) and
  the panel blanked, on SIGINT/SIGTERM as well as normal exit — the buzzer must never be
  left driven.
- **Exit.** Ctrl-C ends the run; the summary prints to stdout and the exit status is 0
  when the verdict passes, 1 otherwise. Optional `--timeout SECONDS` for an unattended
  bench.

```
$ python -m PiFinder.bringup
PRE-FLIGHT  i2c-1 ok · pwm ch1→gpio13 ok · pwm ch0→gpio12 NOT ROUTED
SCREEN      emitted    3 patterns + dashboard          (witnessed)
BACKLIGHT   emitted    ramp 0-12% on pwm ch1           (witnessed)
BUZZER      skipped    pwm ch0 not routed              (witnessed)
IMU         PASS       BNO055 id ok, cal 2, q live     (probed)
CHARGER     PASS       BQ25895 pn=0b111, 4.02V, PG     (probed)
SWITCHES    FAIL       17/18 — (1,3) PLUS never closed (exercised)
VERDICT     FAIL
$ echo $?
1
```

## 9. Tests — `python/tests/test_bringup.py`, `@pytest.mark.unit`

Everything below runs off-Pi; the module must import with no `RPi.GPIO`, `board` or
`rpi_hardware_pwm` present, which is what keeps the hardware imports lazy.

1. `rev4` population map has 18 positions; `rev3` has 17.
2. Every populated position maps to a non-`NA` keymap entry (catches the two tables drifting).
3. `KeyboardPi` still sources its rows/cols/keymaps from `keypad.py` (guards the extraction).
4. `parse_pwm_overlay` — single-channel, `pwm-2chan`, absent, commented-out.
5. `compute_verdict` ignores witnessed results entirely; fails on a missing switch; fails on a probe failure; passes only when every gating check passes.
6. `GridState` press/release edges: repeat presses don't double-count; held ≠ seen; a stuck position stays held.
7. `grid_layout` fits within `resY` on `DisplayHeadless` (128), `DisplayHeadless176` and `DisplayHeadless320`.
8. `format_summary` renders each kind with the right label and never prints PASS/FAIL for a witnessed check.
9. `python -m PiFinder.bringup --help` succeeds with no hardware.

## 10. To confirm on the first board

These are assumptions the plan rests on that only hardware can settle:

1. **The rev4 population map.** The plan expects 18 switches including a second
   `SQUARE` at `(4,4)`. Commit `e82b809d` says the fix "enables repeat on **both**
   directional clusters", which could mean rev4 populates both the bottom row *and*
   col 4 (22 switches). If so, `REV4_POPULATED` changes — one constant, no redesign.
2. **`pwm-2chan`.** `pifinder_setup.sh:64` provisions only
   `dtoverlay=pwm,pin=13,func=4`. If a reference rev4 card's `/boot/config.txt` has no
   `pwm-2chan` line, the buzzer has never been routed to a pin and the setup script
   needs fixing — separate PR, and exactly the class of fault bring-up exists to name.
3. **The LTC2954 on a long power-button press.** ADR 0007 documents GPIO14 → KILL as
   the shutdown path; whether the controller *also* kills on a long button hold is
   unverified. If it does, document "tap, don't hold" in the builder instructions.
4. **Backlight duty range on rev4.** `main.py`'s "effective range seems 0-12" comment
   predates rev4; retune the ramp ceiling if the LEDs behave differently.
5. **Panel opens without the charger.** Pull the charger (or test a board with a dead
   one) and confirm `--display ssd1333` still brings the screen up — the entire reason
   the panel isn't derived from the probe.

## 11. Sequencing

- **PR 1 (this branch)** — docs only: the Bring-up glossary, the CONTEXT-MAP entry, and
  the rev3/rev4 keypad correction in the UI glossary. No code, no risk.
- **PR 2** — `PiFinder/keypad.py` extraction + `keyboard_pi.py` reading from it + tests.
  A pure data move with no behaviour change, landed on its own so any keypad regression
  is bisectable in isolation from the new tool.
- **PR 3** — `PiFinder/bringup.py` + `test_bringup.py`.
- **Follow-ups, not scheduled** — build-guide rewrite (replacing the manual "Tools >
  Status, then Name Search" procedure at `build_guide.rst:223`); `pifinder_setup.sh`
  PWM fix if item 2 above confirms it; adopting `BacklightPWM` in `main.py`.

## 12. Explicitly out of scope

Camera and solver validation (needs `cedar-detect` and a star target — a different
bench step), GPS, wifi, per-unit pass/fail record files, any menu entry in the running
app, and an ADR for the panel decision (rationale lives in the module docstring).

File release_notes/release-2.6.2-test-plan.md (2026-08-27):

# PiFinder v2.6.2 — Release Test Plan

Scope: everything on `main` that is not yet on `release` — 25 commits, 70 files,
+5,310 / −2,001 (Python: 32 files, +2,501 / −536; of which ~1,100 lines are new tests).

This plan is risk-ordered, not feature-ordered. Each gate has an owner, an explicit
pass criterion, and a note on what a failure blocks. Gates 1–3 must pass before the
`main` → `release` merge; gates 4–6 must pass before the update manifest is published.

**Status as of 2026-08-15** (`main` @ `db065b60`): `release` is an ancestor of `main`,
so the cut is a **fast-forward** with no conflicts to resolve. `.github/` is
byte-identical between the two branches, so the release workflow that runs post-cut is
the one already exercised on `release`. Gate 1 is green.

> **Both pre-cut blockers from the pre-release review (§9) are now resolved.**
> **(1)** `version.txt` reads **2.6.2** on `main` as of `db065b60` (**P1.1**).
> **(2)** #620 removed the Focus screen's Quick Menu Exposure jump, which was the
> ordinary route into the exposure-hold leak, and replaced the transient exposure
> readout with a standing status bar (**G2.12**). **This narrows the leak, it does not
> close it** — three routes still bury the screen, so G2.12 remains a real test item and
> the lease fix is still outstanding.
>
> Two cheap fixes remain recommended but unblocking: clearing `camera_lens` on a Camera
> Type switch (**G2.26**), and pulling in the docs-only #613 so that ADR 0027's accepted
> risk is actually mitigated (**§8.1**).

**Shape of this release, and what that means for testing.** Eighteen of the 25 commits
are documentation. The code surface is small — two features plus one fix — but one of
them sits
directly in the solver's hot path and changes the search window used for *every solve
by every user*. The testing effort should be weighted accordingly: this is not a
"docs release, ship it" cut. The single question that matters most is **does a
never-touched 2.6.1 device still solve exactly as it did**, and it has to be answered
on real hardware, because the thing that changed is a number derived from the sensor
the device reports at runtime.

---

## 0. Risk model

What actually changed, ranked by blast radius × likelihood of an undetected defect.

| # | Area | PRs | Blast radius | Why it's risky |
|---|---|---|---|---|
| R1 | Solver FOV gate now derived | #608, #609 | **All users, silent** | Every solve goes through a window that is now computed at runtime from the sensor the camera process reports, rather than a constant. A wrong derivation for any sensor means that sensor never solves — and tetra3 enforces the window twice, so the failure is total, not degraded. It also presents as an exposure problem, so it will be misdiagnosed. |
| R2 | Zero-migration lens default | #609 | **All upgrading users** | An install with no `camera_lens` key must resolve to the sensor's shipped lens. If that path raises, or picks the wrong lens, the device stops solving on update with no user action to explain it. |
| R3 | `CameraProfile` relocated out of `sqm/` | #609 | All users, silent | ~500 lines moved between modules, including the radiometric constants. A changed constant shifts everyone's SQM without failing; a missed importer breaks a process at startup. |
| R4 | Focus exposure hold lifecycle | #614, #620 | All users, next-session | A hold that is not released leaves the camera at a fixed manual exposure for the rest of the session **and stops zero-match recovery**, while Settings still reads "Auto". #620 removed the likeliest route in and reworked the on-screen readout into a standing status bar; three burying routes remain (see G2.12). New surface of its own: the bar changed tile geometry on every Focus view (G2.12b). |
| R5 | Debug camera relabelled `imx296` → `hq` | #609 | Developers, CI | If wrong, `-fh --camera debug` stops solving for every developer and every automated test that solves a frame. |
| R6 | Live lens re-read in the solver loop | #609 | All users | The train is resolved per frame from shared state. New shared-state reads inside the hot loop; a manager disconnect or a bad value must not wedge the loop. |
| R7 | Chart frustum + web chart API | #609 | Visual / web | Frustum shading now follows the derived value in two places. Cosmetic on the device, but the web chart API is a separate consumer that can fail independently. |
| R8 | Manual rewritten wholesale | #585–#600, #604, #607 | All users, **no code risk** | 13 pages rewritten. The risk is not breakage but *accuracy*: a rewrite can silently change meaning. #604 additionally reverses standing advice (EQ platforms → alt-az). |
| R9 | i18n | #609 | Non-English users | Four new msgids. One is machine-translated and unreviewed. Menu-index drift from a new menu entry has broken web remote tests in this project before. |
| R10 | SQM field width now derived | #609 | SQM users, silent | `radiometric_fov_degrees` was deleted as a stored constant. The claim is reproduction to within 0.03° (< 0.01 mag). If wrong, every SQM reading shifts and nothing fails. |

---

## 1. Pre-flight — repo housekeeping (before any testing)

- [x] **P1.1 — `version.txt` bumped to `2.6.2`** on `main` at `db065b60`. This was a
  release blocker, not housekeeping: `ui/software.py:245` fetches `release/version.txt`
  from GitHub and line 353 gates the update on `update_needed(self._software_version,
  self._release_version)`. Had `release` shipped 2.6.2 code with `2.6.1` in the file,
  **every existing device would have compared 2.6.1 against 2.6.1, rendered "No Update
  needed", and never been offered the update at all** — the release would have been
  invisible in the field. The Software screen, `splash.py:49`, `server.py:216` and
  `api_extensions.py:851` would also have misreported the version on every bug report.
  - **Re-run Gate 1 after this and any later commit**, and confirm on hardware at
    **G4.1** that the Status screen actually reads 2.6.2.
- [x] **P1.2 — Cut is a fast-forward.** `git merge-base --is-ancestor origin/release
  origin/main` succeeds. No merge commit, no conflict resolution, and no separate merge
  result to test — testing `main` *is* testing the cut.
- [x] **P1.3 — `.github/` is byte-identical** between `release` and `main`. The release
  workflow is the one already exercised.
- [x] **P1.4 — ADR collision resolved.** #608 and #606 both landed a `0027` a day apart.
  Resolved by #616 under the standing rules: the FOV gate keeps 0027 (most-referenced —
  ten bare `docs/adr/0027` mentions across seven source files plus two test modules),
  tracked black level moved to 0028. Three inbound references updated.
  - **Still outstanding, not this release:** #571 (`fix/equipment-input-validation`)
    carried a third `0027-equipment-measurements-are-validated-floats.md`. The earmark
    here went stale twice while the PR sat — 0029 went to #624, then 0030 to #622 — so
    it took **0033**, the lowest slot free across every branch, when main was merged in.
    Recompute the free slot at merge time; do not trust a written-down reservation.
    #502 still carries the older `0018` collision.
- [x] **P1.5 — i18n release pass verified.** Exactly four new msgids (`Lens`, `12mm`,
  `16mm`, `25mm`), taking every catalog 671 → **675 msgids, 0 untranslated, 0 fuzzy**,
  with no msgid removed. All four are wrapped in `_()` at `menu_structure.py`
  1078/1087/1091/1095, and all four `.mo` files are **byte-identical to a fresh
  compile** — no stale binaries. `Lens` is tagged `AI-TRANSLATED (claude): needs human
  review`; the three lens labels are numerals and identical across languages.
  *(`messages.pot` is gitignored in this repo — the check was scoped to the tracked
  `.po` diff rather than a full babel extract.)*
  - **Two cosmetic residuals, not blockers:** in es and fr the standalone
    `# AI-TRANSLATED` comment that preceded `GPS Settings` was displaced onto the newly
    inserted `Lens` entry (which carries its own copy), so `GPS Settings` silently drops
    off the human-review queue in those two catalogs. And `"HOLD"` on the Focus → Stats
    screen is not wrapped for translation — though the adjacent `"AUTO"` / `"MANUAL"`
    are equally unwrapped and already ship that way, so fixing all three together is the
    clean call rather than treating this as a 2.6.2 regression.
- [x] **P1.6 — No migration is required, and that is by construction.** No config-schema
  migration is added; the only `MIGRATION_*` constants in the tree belong to the
  unrelated NixOS OS migration (`sys_utils.py:480-481`), untouched in this range.
  `default_config.json` is **unchanged** and deliberately carries no `camera_lens` key.
  The new key is optional by design: `Config.get_option` falls through `_config_dict` →
  `_default_config_dict` → `None`, and `optics.resolve_lens(profile, None)` then returns
  `get_lens(profile.default_lens_key)`. `text_menu.py` was patched so that a stored
  `None` plus a `value_callback` keeps the resolved default rather than snapping to
  `items[0]` — which is what stops a 2.6.1 config from displaying "12mm". No
  `requirements*`, `pyproject.toml` or `noxfile.py` changes, so there is nothing new to
  stage on the image.

---

## 2. Gate 1 — Automated (CI, ~15 min)

Run on `main` directly — the cut is a fast-forward, so there is no separate merge
result.

```bash
cd python/
source .venv/bin/activate
git submodule update --init PiFinder/tetra3   # mypy + solver tests need this
nox -s lint
nox -s format
nox -s type_hints
nox -s smoke_tests
nox -s unit_tests
```

**Gate 1 is green on `main` @ `db065b60`** (macOS dev venv, Python 3.9, 2026-08-15),
re-run after #620 and the version bump. Run in clean worktrees rooted on `origin/main`
with the `tetra3` submodule freshly initialised, with reproducible results.

- [x] **G1.1** Ruff lint + format clean.
- [x] **G1.2** MyPy clean. Needs the `tetra3` submodule initialised; a stale
  `.mypy_cache` reports a phantom error, so clear it if the count disagrees.
- [x] **G1.3** `pytest -m "smoke or unit"` — **1,238 passed, 0 failures**, 472
  deselected (the non-smoke/unit markers). Reproduced exactly on a clean tree. (Was
  1,229 before #620, which added the Focus status-bar tests.) A materially lower count
  means test collection broke somewhere.
- [x] **G1.4** New suites confirmed **running, not skipping** — `test_optics.py`,
  `test_optics_solving.py`, `test_plot_frustum.py`, `test_lens_menu_callback.py`, plus
  the additions to `test_focus_preview.py` (now including the #620 status-bar and
  marking-menu tests) and `test_sqm.py`. `test_optics_solving.py`
  is the one that pushes real `test_images/` frames through tetra3, so **verify it did
  not skip** — if the submodule is missing it silently disappears and the debug-camera
  relabel (R5) goes untested.
- [x] **G1.5** Docs build clean — `python -m sphinx -nW -b html docs/source <out>`
  exits 0, "build succeeded", **0 warnings**, 18 sources. `conf.py` sets no
  `suppress_warnings` or `nitpick_ignore`, so a clean `-n -W` build is meaningful
  rather than muted. `sqm.rst` is wired into the `index.rst` toctree after `equipment`,
  all three new `images/sqm/*.png` are present, and the new `:ref:` targets in
  `user_guide.rst` resolve. *(Needs `pip install -r docs/source/requirements.txt`;
  `sphinxcontrib-mermaid` and `sphinx_rtd_theme` are not in the app venv by default.)*

**Blocks:** everything. **Re-run G1.1–G1.5 if anything further lands on `main` before
the cut** — in particular after the `version.txt` bump (P1.1).

---

## 3. Gate 2 — Bench, standard hardware (the population that upgrades)

**This is the most important gate.** Run on a real unit updated in place from 2.6.1.
Indoors is fine for most of it; use `Tools → Test Mode` for a solvable frame.

The organising question: *does a device nobody has touched behave identically?*

### The derived FOV gate (R1, R2) — highest priority

- [ ] **G2.1** Update from 2.6.1 **without opening the Lens menu**. Confirm the device
  solves. This is the zero-migration path and the one almost every user takes.
- [ ] **G2.2** Check the log for the `Optical train:` line. It must name your actual
  sensor, the shipped lens (16 mm on imx296/imx462, 25 mm on HQ), and a field of view
  matching the table in the release notes. **Record the fitted FOV tetra3 reports and
  compare it with the derived value** — #609 measured 10.20° fitted against 10.33°
  derived on the debug train. A fitted value near the edge of the gate rather than the
  centre is the early warning that the derivation is off for your sensor.
- [ ] **G2.3** Confirm `camera_lens` is **still absent** from `~/PiFinder_data/config.json`
  after a full session in which the Lens menu was never used. The default must be
  resolved, not written.
- [ ] **G2.4** Compare solve rate against 2.6.1 on the same test frame, same conditions.
  The new gate is *tighter* than the old one (±15% vs an effective ±33%), so a
  measurable drop in solve rate — not a total failure, a drop — is the signature of a
  derivation that is slightly off. **This is the subtlest failure mode in the release
  and the one most likely to escape.**
- [ ] **G2.5** Open `Settings → Advanced → Lens`. The correct lens must be shown as
  checked, with no config entry present. Confirm it is the resolved lens and not simply
  the first item in the list — 12 mm is first, so a bug here looks like "12mm is
  checked".
- [ ] **G2.6** Select the *correct* lens explicitly (the one already in force). Solving
  must continue uninterrupted, and `camera_lens` now appears in config.
- [ ] **G2.7** Select a **wrong** lens. Solving must stop **immediately, without a
  restart** — this is the designed behaviour and confirms the live re-read works.
  Select the right one again: solving must resume, again with no restart. Time both
  transitions; they should land within a frame or two.
- [ ] **G2.8** With a wrong lens selected, confirm the log carries the resolved-train
  line naming it. This is the only diagnostic a support thread will have.
- [ ] **G2.9** Select **25 mm on an imx296 or imx462**. Confirm the solver logs the
  explicit "FOV gate … lies outside the solver database's … range: no frame can solve"
  error. Confirm the device does not crash, wedge, or thrash — it should simply not
  solve. *(This is a combination the menu offers but the shipped pattern database cannot
  serve; see §8.)*
- [ ] **G2.10** Power-cycle with a non-default lens stored. It must survive the restart
  and be picked up by the solver on the first frame.

### Focus screen exposure hold (R4)

- [ ] **G2.11** Open Focus under Auto exposure. Stats must read `HOLD` with the exposure
  the controller had settled on — including an off-ladder value, not snapped to a menu
  rung. Confirm the value flashes top-left on entry.
- [ ] **G2.12** **The leak test — see review finding 2. Narrowed by #620, not closed.**
  The pre-release review confirmed, by driving the real `MenuManager`, that the exposure
  hold leaks whenever the Focus screen is *buried* rather than left with LEFT, and that
  the consequence is larger than #614 documented: `set_exp_transient` clears
  `_auto_exposure_enabled` in the camera process, and only `set_exp:auto` ever sets it
  back. A leaked hold therefore pins the camera at a manual exposure **and stops
  zero-match recovery for the rest of the session**, while Settings → Camera Exp still
  shows "Auto".
  #620 removed the Focus screen's Quick Menu Exposure jump, which was the one route an
  ordinary user was likely to take. The remaining routes are less likely but not
  hypothetical — and route **d** is *involuntary*, the user does nothing.
  Enter Focus, leave by each route, then watch the exposure for 60 s:
  - [x] **a.** Focus → Quick Menu → Exposure → long-LEFT. **Route removed by #620.**
        Instead confirm the Quick Menu on the Focus screen now offers **HELP only**, and
        that HELP still opens (nulling the menu would have taken the help with it).
  - [ ] **b.** Focus → long-RIGHT to object details → long-LEFT. *(Needs a non-empty
        recent list, so view an object first.)*
  - [ ] **c.** Focus → POWER button → long-LEFT (back out instead of confirming).
  - [ ] **d.** Focus open, push an object from SkySafari, then long-LEFT. **The user
        initiates nothing here** — `pos_server` calls `jump_to_label("recent")`.
  - [ ] **e.** Control: Focus → LEFT. This route is correct and must release the hold.
  For each leaking route, confirm the observable consequence: does auto exposure resume,
  does solving recover, and does Camera Exp still read "Auto"? Then confirm re-entering
  and leaving Focus with LEFT releases it, and that re-selecting Auto in Settings →
  Camera Exp recovers a leaked session.
  **Still outstanding:** the real fix is a self-expiring lease on the transient exposure,
  renewed per frame by the screen and dropped by the camera process on expiry (the
  black-level lease is the in-repo precedent). Making Focus `stateful` does **not** work
  — the `state` check in `add_to_stack` is on the pushed item, not the buried one.
  **Do not let #620 close this ticket.**

- [ ] **G2.12b** **The new Focus status bar (#620).** In **Stars**, **Single** and
  **Image**, a standing bar along the bottom shows the held exposure on the left and the
  keys on the right. Confirm:
  - [ ] The bar is present and readable, and the **arrows actually render** — Unicode
        arrows draw nothing in this font, so this is worth looking at rather than
        assuming.
  - [ ] The exposure in the bar tracks UP/DOWN immediately.
  - [ ] **Image** shows the exposure keys only, with no zoom hint (`+`/`-` do nothing
        there).
  - [ ] **Stats** has *no* bar, and still reports `HOLD` and the exposure itself.
  - [ ] No star tile is clipped or overdrawn by the bar — the rows are reserved out of
        the camera area, so the tiles should be slightly shorter, not covered.
  - [ ] Check on a 176px panel as well as 128px if one is available; the bar height is
        derived from panel resolution.
- [ ] **G2.13** UP/DOWN step along the ladder 0.025 s … 1 s. Confirm both ends **hold
  rather than wrap** — five UPs from 0.1 s must stop at 1 s. The underlying `exp_up` /
  `exp_dn` commands apply no clamp at all, so this bound exists only in the new code.
- [ ] **G2.14** `+` and `-` still change magnification, not exposure. This is shipped,
  documented behaviour from #531 and must not have moved.
- [ ] **G2.15** Confirm `camera_exp` in `config.json` is **unchanged** after a session of
  nudging the exposure up to 1 s and back.
- [ ] **G2.16** Leave Focus normally with a manual value set. Within ~35 s and with no
  input, auto exposure must move it — proving control was genuinely handed back.
- [ ] **G2.17** Back out of Focus with LEFT. `inactive()` is called twice on this route
  (once directly, once from `remove_from_stack`); confirm the double call is harmless.
- [ ] **G2.18** Open the Quick Menu over the Focus screen and dismiss it. Confirm the
  hold is neither leaked nor prematurely released.

### SQM (R3, R10)

- [ ] **G2.19** Record an SQM reading under stable conditions on 2.6.1, update, and read
  again under the same conditions. The claim is movement under 0.01 mag. **Anything
  larger than ~0.05 mag means the derived field width does not reproduce the deleted
  constant** and should block.
- [ ] **G2.20** Confirm the SQM screen still shows as calibrated if it was before — the
  calibration file is keyed to the camera and this release does not touch that keying.
- [ ] **G2.21** Change the lens and confirm the SQM field width follows on the next
  frame, not the next boot.
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

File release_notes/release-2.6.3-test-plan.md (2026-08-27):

# PiFinder v2.6.3 — Release Test Plan

Scope: **everything since the v2.6.1 tag** — 52 commits on `main` @ `0f54d7fc`.
Python: 75 files, +8,188 / −829. The raw repo diffstat (~260k insertions) is dominated
by the rev4 KiCad hardware files, which carry no software risk. This plan covers the
full 2.6.1 → 2.6.3 delta, **folding in the internal-only 2.6.2**: the field population
is on 2.6.1, so everything 2.6.2 changed is still new to every user this release
reaches.

This plan is risk-ordered, not feature-ordered. Each gate has an owner, an explicit
pass criterion, and a note on what a failure blocks. Gates 1–3 must pass before the
`main` → `release` merge; gates 4–6 must pass before the update is offered.
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

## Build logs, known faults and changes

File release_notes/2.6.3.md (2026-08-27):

# PiFinder v2.6.3 Release Notes

**There was no public 2.6.2.** A 2.6.2 build was cut to the release branch for internal use, with no announcement and no notes, and its update offer was withdrawn when it emerged that some rev4 units — the ones that shipped with a 12 mm lens and nothing in their configuration saying so — would stop solving on update. That regression is fixed in this release (see "Your PiFinder Now Works Out Its Own Lens"), and 2.6.3 supersedes 2.6.2 entirely: whether your device runs 2.6.1 or briefly took 2.6.2, it updates straight to 2.6.3. These notes cover everything since 2.6.1, with the internal 2.6.2's changes folded in.

PiFinder now understands that field of view is a property of the **sensor and the lens together**, which is what lets you fit a different lens and have the solver, the SQM and the chart all follow — and where nobody has stated which lens is fitted, the device now measures it for itself. The Focus screen stops fighting you by holding the exposure still while you turn the lens. **Nearby** now measures distance on the sky rather than on a swapped sphere, so the objects it ranks and the markers the chart draws are the ones actually near where you point. **Stellarium** can now push targets to the PiFinder the way SkySafari always could. The chart names the object at its center, the STATUS screen shows whether the GPS is actually talking, and the web interface's equipment and GPS forms now say so when they cannot read what you typed instead of pretending they saved it. All of this sits on top of the largest documentation pass the project has had: the manual rewritten end to end into a plain, translatable style, with a new Sky Quality Meter page and a batch of factual corrections driven by real support questions.

If you are on 2.6.1 and you have not changed your lens, this release changes nothing about what your device reads or how it solves. Update freely. If your PiFinder shipped with a 12 mm lens, it now works that out for itself rather than assuming the 16 mm.

## ⚠️ After You Update

- **A new `Settings → Advanced → Lens` setting appears, already set correctly.** An install with no stored lens resolves to the lens that ships with your sensor (HQ → 25 mm, imx296 / imx462 / imx290 → 16 mm). This reproduces the field widths previously stored as per-sensor constants to within 0.03°, which is under 0.01 mag of SQM — **no existing user's reading moves and no plate solve behaves differently.** You only need to touch this setting if the lens on the front of your PiFinder is not the one it shipped with.
- **If your PiFinder shipped with a 12 mm lens, it fixes itself on the first clear night.** Some rev4 units left with the 12 mm rather than the 16 mm and nothing in their configuration said so. Set the Lens if you like, but you do not have to: the PiFinder allows for every lens it could have shipped with until it has measured which one it has, then writes that lens down. It takes three solves. See "Your PiFinder now works out its own lens" below.
- **State the lens you actually have.** The lens cannot be detected, only declared, and the solver's search window is now centred on what you declared. Naming the wrong lens stops solving **completely** rather than degrading it — and because auto-exposure steers on match count, it presents as an exposure problem, not a configuration one. The focal length is marked on the lens barrel. See "Known sharp edges" below.
- **On the Focus screen, UP and DOWN now change the exposure**, and a new bar along the bottom of the screen shows the held exposure and the keys that change it. UP and DOWN were previously no-ops there. `+` and `-` are unchanged and still control magnification. Nothing you do on this screen is saved — the exposure is held for the visit and handed back when you leave, and `Camera Exp` in the menu still reads whatever you last saved. The Stats view reports the regime as `HOLD` while you are on the screen.
- **The Focus screen's Quick Menu no longer offers Exposure** (#620). UP and DOWN do that job directly now. To set an exposure the PiFinder keeps, go to `Settings → Camera Exp` as usual. Press and hold SQUARE on the Focus screen and you get HELP.
- **The Nearby sort ranks by true angular distance now, so the order you see changes.** The old ranking measured separation on a sphere with its axes swapped. It was right only for objects sharing a meridian, and got worse the further from the celestial equator you pointed. The chart's nearby-DSO markers ran on the same index and get the same fix.
- **A Nearby list now holds the 200 nearest objects rather than the whole catalog**, which is what keeps the re-rank off the frame budget while you slew. An object on the far side of the sky is no longer reachable by scrolling down a Nearby list. Catalog and RA sorts still expose every object.
- **In the Nearby sort, the top row follows your pointing.** While the cursor sits on the first row a re-rank leaves it there, so the focused object stays whatever is nearest. Once you scroll down, the cursor pins to the object you selected and follows it through the ranking instead; scrolling back to the top re-arms the tracking.
- **Object Details opens faster if you have a long observing log**, and the remote web interface's object-details view now works for objects opened from a Nearby-sorted list. It was silently blank on that path.
- **If you run an alt-az telescope on an equatorial tracking platform, set Mount Type to Alt-Az, not Equatorial.** The manual previously said the opposite. That misconfiguration is exactly what makes Push-To corrections jump around. This is a documentation correction, not a code change — but if you configured your device by following the old text, change it.
- **A rev4 board takes Camera Type `v3 - imx462`.** Also a documentation correction; the manual did not say so before, and rev4's card slot is externally accessible so people hit this during setup.
- **The chart gains a readout naming the object at its center, and it is on by default.** A line along the bottom of the chart names the drawn marker nearest the middle, and RIGHT opens that object's details. Turn it off at `Settings → Chart → Center Object` if you want your chart exactly as it was.
- **The STATUS screen gains a `GPS MSG` row** showing the last message the GPS receiver sent and how long ago it arrived. On a healthy unit the name churns and the age sits near zero; a frozen name with a climbing age means the link is dead. You do not need to do anything with it — it exists so support threads can tell four kinds of GPS failure apart.
- **Stellarium can now push targets to the PiFinder.** Same LX200 protocol, same port 4030 SkySafari uses; add a Meade LX200 compatible telescope in Stellarium pointed at `pifinder.local`. SkySafari setups are unchanged.
- **The web interface's equipment and GPS forms now reject input they cannot read, and say so.** Before, an unparseable value — a decimal comma is the easiest trigger — either reported "Eyepiece added" while saving nothing or returned a raw server error. Failures now re-render the form with a message and the values you typed. Fractional measurements like a 279.4 mm aperture are now accepted and survive a reload.
- No migration runs on update. The one thing that does write to your configuration file is lens self-heal, and only on a device that has never had a lens stated: after three agreeing solves it records the lens it measured, under `camera_lens`. It writes nothing else, and nothing at all if you have set the lens yourself.

## New Features

### Lens Selection and a Derived Field of View (#608, #609)

Field of view used to be three hard-coded constants that disagreed with each other and with the hardware:

| Consumer | Constant | Correct for |
|---|---|---|
| solver | `fov_estimate=12.0`, `fov_max_error=4.0` | 3 of the 4 sensor × lens combinations we can ship |
| SQM | `radiometric_fov_degrees`, per sensor | the 16 mm only |
| chart frustum | `9.5` | nothing currently shipped |

Nothing in the code said which lens any of them assumed. The practical consequence: a 12 mm lens on an imx296 images 16.38°, which falls outside the solver's `[8.0, 16.0]` window. Tetra3 enforces that window twice — pruning candidates before verification and rejecting survivors after fitting — so such a frame **does not solve at all**, however many good stars it contains.

All three now derive from one place, `PiFinder.optics`, which models the **optical train**: a camera profile paired with the lens fitted in front of it.

- **`Settings → Advanced → Lens`**, beside Camera Type, offering 12 mm, 16 mm and 25 mm. The menu shows the lens actually in force rather than the first entry in the list, including on installs that have never stored the setting.
- **Changing the lens restarts the PiFinder.** Everything that reads the lens live would follow it on the very next frame — the FOV gate, SQM's radiometric field width and the chart's frustum shading all re-resolve per frame. Tetra3's internal pattern cache would not: it stores results already filtered against whichever search window was in force when they were computed, under a key that does not mention the window, and nothing ever clears it. So a lens change could leave the solver holding stale work and appear not to have taken. Restarting is the reliable fix for a setting you change about once in the life of the device.
- **The gate is ±15% of the derived field of view**, proportional rather than a fixed number of degrees, which is *tighter* than the old fixed pair (effectively ±33%) while being correct for every combination rather than three of four.
- **Effective, not nominal, focal length drives the arithmetic.** The shipped "16 mm" measures 15.61 mm, and that single value reproduces both independently calibrated SQM field widths (imx296 13.71°, imx462 10.38°) to within 0.02°. Two different sensors agreeing on one lens is what makes it a measurement rather than a fudge factor. Deriving from the nominal 16.0 would have shifted every existing user's SQM by ~0.05 mag. The 12 mm has since been measured the same way and comes out at **13.04 mm** — 8.7% *long*, where the 16 mm runs 2.4% short, so no label predicts its own glass. The menu still shows the number printed on the barrel.

The field of view each combination now derives:

| Sensor | 12 mm | 16 mm | 25 mm |
|---|---|---|---|
| imx296 | 16.38° | **13.71°** | 8.26° ✗ |
| imx462 / imx290 | 12.44° | **10.40°** | 6.26° ✗ |
| HQ (imx477) | 20.43° | 17.12° | **10.33°** |

Bold is the lens that ships with that sensor and the value used when no lens is stated. ✗ marks combinations the shipped pattern database cannot solve — see "Known sharp edges".

### Your PiFinder Now Works Out Its Own Lens (ADR 0029)

The lens setting above has a gap in it, and it is one we put there. Deriving the search window from the lens is only right when we *know* the lens — and for an install that has never stored one, the "16 mm" the code fell back to was never knowledge. It was a guess wearing knowledge's confidence.

That guess is wrong on real hardware. Some rev4 units shipped with a 12 mm lens and nothing in their configuration recording it, so on 2.6.2 they searched a window centred on 10.40° for frames that are actually 12.44° wide. **Those units stopped solving on update having changed nothing.** The configuration that broke them is the configuration we shipped them.

The fix is to make the search window's width follow how much the PiFinder actually knows:

- **You stated the lens** (from the menu, or because the device measured it) → the window stays ±15% of that one lens's field of view, exactly as 2.6.2 already did. Nothing changes for you.
- **Nobody has stated it** → the window covers *every* lens that sensor has shipped with, so the device solves on either one while it works out which it has.

| Sensor | Lenses it shipped with | Window when the lens is unstated |
|---|---|---|
| imx462 / imx290 | 12 mm (12.44°), 16 mm (10.40°) | `11.57 ± 2.73` = [8.84, 14.30] |
| imx296 | 12 mm (16.38°), 16 mm (13.71°) | `15.25 ± 3.59` = [11.65, 18.84] |
| HQ (imx477) | 25 mm (10.33°) | [8.78, 11.88] — **unchanged** |

The imx462's window sits comfortably inside the fixed `[8.0, 16.0]` that 2.6.1 used, which is the behaviour these units are known to work under. The HQ only ever shipped one lens, so nothing about it widens at all.

**Then the PiFinder identifies the lens for itself.** A successful solve reports the field of view it measured, and the sensor is already known, so what is left is the lens. After **three consecutive solves agreeing to within 5%**, the device writes that lens into the Lens setting and narrows its window onto it. From then on the menu shows the real lens and the solver has 2.6.2's full precision back.

**The 12 mm's focal length had to be measured before any of that could work** (#627, #628). The registry carried the lens's nominal 12.0 mm, which derives a 13.51° field against a real 12.4366 ± 0.0025° — 7.9% out, and self-heal identifies a lens only within 5%. So a 12 mm unit fitted a field that matched no lens in the registry, on every frame, and took the branch above for third-party glass: write nothing, keep the wide window. The units this release exists to fix would have solved but never promoted. At the measured 13.04 mm that error is −0.07%, and promotion in three solves is demonstrated on the board that surfaced the bug, in both directions. It also corrects something nobody was looking for: SQM on a 12 mm unit was integrating over a field 8.6% too wide, and carrying the 16 mm's zero point across.

Four things it deliberately will not do:

- **It never overwrites a lens you set.** Your claim stays authoritative even when the measurement disagrees, because quietly overruling the setting would make the menu a lie. A mis-stated lens still means no solves, exactly as 2.6.2 documented.
- **It writes nothing when the measurement matches no lens we sell.** Third-party glass keeps the wide window and approximate SQM forever, which is honest: we do not know its focal length. A wrong write would be worse than none, because the window then tightens around it and the device can no longer measure its way out.
- **It never drops the window entirely.** Widening costs nothing measurable in solve time (1.1–1.4 ms at every width tested, against 1.5 ms with no window at all), but the *upper* bound is load-bearing: with injected noise, hintless searches returned confident false solves at 20–23° that the match threshold did not reject. The window is what catches those, so it stays finite.
- **It writes at most once per device.** The write is what ends the condition that triggers it.

Why widen rather than tighten the tolerance everywhere? Because the two failures are not the same size. A frame *outside* the window burns the entire solve timeout and returns nothing, every frame, forever. Against a wider window's ~0.3 ms, an over-tight one is the expensive mistake by three orders of magnitude.

No migration runs, and no rev4 unit is assumed to have a 12 mm. Not all of them do — a migration keyed on the board would have fixed most units by breaking the rest, and broken them in exactly the way this release exists to fix. The reasoning is in `docs/adr/0029-fov-gate-width-follows-lens-confidence.md`.

### The Focus Screen Holds the Exposure (#614, #620)

You open the Focus screen *because* focus is bad. But bad focus is what starves the plate solver of matches, and solver-driven auto-exposure steers on that match count — so the controller kept adjusting underneath you, and once matches hit zero, zero-match recovery walked the exposure much further still. The HFD readout moved and the visible stars changed for reasons that had nothing to do with the lens you had just turned. The signal you were trying to judge shifted under you.

The Focus screen now takes the exposure for the duration of the visit and hands it back on exit.

- **Entering** freezes whatever exposure is already in effect, without snapping to a menu value — under Auto it holds wherever the controller had settled, including off-ladder values like 0.32044 s.
- **UP** lengthens and **DOWN** shortens the exposure, stepping along the Camera Exp menu's own rungs (0.025 s … 1 s). The ends of the ladder hold rather than wrap. `+` and `-` remain magnification.
- **Leaving** restores the previous regime — back to Auto if that is where you were.
- **Nothing is persisted.** The hold never writes `camera_exp`. To save a value, use `Settings → Camera Exp`.
- **A standing bar along the bottom** carries the held exposure on the left and the keys on the right, so the exposure is readable for as long as you are on the screen rather than flashing and vanishing. The Image view lists the exposure keys only, since `+` and `-` do nothing there, and the Stats view has no bar because it already reports the exposure and its `HOLD` regime in full. The bar's rows are reserved out of the camera area rather than drawn over it, so no raw sensor pixel is hidden behind it.

This is the other half of a boundary the codebase already described: zero-match recovery is explicitly not responsible for defocus, because the focus indicator owns that. Now the focus indicator's screen suspends recovery too.

### Stellarium Can Push Targets (#621)

Stellarium — including Stellarium Mobile Plus — now connects to the PiFinder the same way SkySafari does and can send an object to the observing list for Push-To guidance. Same LX200 protocol, same port 4030: in Stellarium's telescope settings, add a **Meade LX200 compatible** telescope at `pifinder.local` (or the numeric IP from the STATUS screen). Stellarium marks the telescope's position on its chart, and a selected object sent to the PiFinder lands in the observing list exactly as a SkySafari push does. Stellarium also sends its own observing site and clock while connecting; the PiFinder accepts them and keeps using its own GPS position and time.

Getting there meant fixing the position server's LX200 dialect, because several replies were wrong in ways that only a second client ever exposed:

- **Degrees-to-arcminutes conversion multiplied the fractional digits by 60 and truncated**, which is only right when the product happens to be four digits — 42.10° answered an out-of-range `42*60` and 42.05° answered `42*30` for a true 3.0′. Roughly one site in six was silently wrong. Replaced with divmod arithmetic that rounds and carries.
- **Longitude dropped its sign**, so Berlin (13.4° E) read as 13.4° West. `:Gg#` now uses Meade's documented positive-west 000–359 convention — the same one `:Sg#` accepts — with the wrap applied after rounding so a site just east of Greenwich cannot land on `360*00`.
- **The UTC-offset reply parsed `"-0500"` as −500 hours**, a 20-day timedelta, masked only because the shared clock is always UTC-aware. `:GL#` and `:GC#` now report local time and `:GG#` returns LX200's sign-inverted `sHH` form (US Eastern is `+05`, not `-05`). Locale-dependent date formats are hardcoded to what LX200 specifies.
- **A packet carrying two commands only dispatched the first**, so Stellarium's goto — which sends `#:Sr…##:Sd…#` in one write — silently never fired. Reads are now split into `#`-framed commands and each is dispatched, with the leading `#` optional so unprefixed SkySafari traffic parses through the same path.

SkySafari is deliberately protected from all of this: `:Q#` is answered only for a client that identified itself with Stellarium's ACK (an unsolicited reply can desync SkySafari's parser), per-connection state is reset so a SkySafari session cannot inherit a stale Stellarium site, and a pushed object is no longer labelled as coming from SkySafari when Stellarium may have sent it. The position server also gains its first test suite — 382 lines covering both dialects.

### The Chart Names What You Are Centered On (#633, ADR 0031)

A new readout along the bottom of the chart names the **center object** — the drawn marker nearest the middle of the chart — as its designator plus the first other name the catalogs carry, marquee-scrolled when it does not fit, with an arrow glyph advertising that RIGHT opens that object's details. The choice is held sticky between solves so it does not alternate between two near-equidistant markers as the pointing drifts.

The candidate set is exactly what the chart drew this solve, restricted to the screen bounds, so the readout never names something you cannot see — that rather than the Nearby ranking, and distance measured in screen pixels, is the decision ADR 0031 records. The readout repaints its strip from a cached copy of the chart backdrop every frame, so the marquee scrolls smoothly at display rate rather than stuttering at the 1–2 Hz solve rate, and the projection of the candidate set is batched into a single skyfield round trip (3.68 ms → 0.18 ms per solve, bit-identical output).

`Settings → Chart → Center Object` (Off/On, **default On**) controls it, and RIGHT is gated on the same switch — off, blank, or no solve leaves RIGHT inert exactly as before. The chart also gains `serialize_ui_state`, so `/api/current-selection` now reports the center object and the readout state to the web interface.

### The STATUS Screen Shows GPS Link Health (#635, ADR 0032)

One new row — `GPS MSG TIMEGPS 0.4s` — showing the last event the GPS process handled and how long ago the main process received it. That single row discriminates four failure modes that previously all looked identical from anywhere above the parser:

| What you see | What it means |
|---|---|
| name churning, age near zero | healthy — the receiver is talking and being understood |
| `?0135`-style marker | the receiver is talking a dialect the parser does not decode |
| `?CKSUM` | bytes are arriving corrupted |
| name frozen, age climbing | the link is dead |

The parser change behind it is ADR 0032: a UBX frame that cannot be decoded now yields a marker instead of being silently dropped, which is what makes "we cannot read this" distinguishable from "nothing is arriving". All three GPS backends (UBX, GPSD, fake) publish through the same rate-capped channel — 20 Hz, a cap on reporting rather than parsing, so a resync storm cannot flood the queue.

One subtlety worth recording: the age is stamped by the **main process when it drains the queue**, not by the GPS process when it sends. `time.monotonic()`'s reference point is undefined across processes — on macOS it is process start — so stamping at the sending end made the row read a steady ~4 s stale against a fake GPS publishing every 0.5 s. Only the event name crosses the process boundary.

## Fixes

### Nearby Ranks by True Angular Distance, in a Bounded Window (#622, ADR 0030)

Two features ask the same question — which catalog objects are near where the scope points? The object list's **Nearby** sort wants them ranked nearest first; the chart's nearby-DSO marker layer wants everything inside the current field. Both are served by one `BallTree` with scikit-learn's `haversine` metric, and that metric reads **dimension 0 as latitude**. Declination is the latitude. The tree was built and queried as `[ra, dec]`.

With the axes swapped, separations came out right only between objects sharing a meridian, and worse the further from the celestial equator you pointed.

The mistake hides, which is why it survived. When two objects share an RA the metric degenerates to `|dec1 − dec2|`, which is correct whichever way round the axes go — so any spot-check that holds RA fixed passes on a swapped index. Index and query are now `[dec, ra]`, and the tests place objects off a shared meridian and at high declination, where a swapped axis order is loudest.

The chart layer gains more from this than the list does. A mis-ranked list is something you might notice; a marker silently absent from the field is not.

**Ranking is now bounded.** Ordering the whole catalog to draw about nine rows cost O(N) twice over — once in the k-NN query, and again in the pure-Python cursor-tracking helper that rebuilds a lookup over the new ordering — on every re-rank, on the draw path, while you slew:

| Objects | rank everything | rank 200 | cursor helper |
|---|---|---|---|
| 14 000 | 1.5 ms | 0.09 ms | 7.6 ms |
| 40 000 | 4.4 ms | 0.13 ms | 22 ms |

(Measured on a fast dev machine; a Pi is roughly an order of magnitude slower, against a 33 ms frame budget.)

`NEAREST_LIST_CAP = 200` bounds both, and everything downstream with them. The cost is the one behaviour a user may experience as a loss: a Nearby list no longer scrolls down to the object 140° away. That object is not "nearby" under any reading, and paying O(N) on every degree of slew to keep the tail reachable is the wrong bargain.

**Staleness is measured on the sky, not per axis.** The re-rank used to trigger on raw RA/Dec degrees. One degree of RA spans `cos(dec)` degrees on the sky — 0.017° at Dec 89° — so that test re-ranked for movement you cannot see, exactly where slewing is slowest and a stall is most visible. And RA wraps, so the step from 359.5° to 0.5° read as 359 and fired continuously in a band around the meridian. Neither failure loses a refresh, so neither showed up as wrong output; both were pure cost. The trigger is now a great-circle separation against 1.0 true degree, at the cost of one `arccos`. The unconditional time-based refresh moves from 2 s to 10 s: its job is catalog and filter changes, not pointing, and 10 s bounds sidereal drift to ~0.04°.

**The carousel counts the list it actually navigates.** `UIObjectList` draws, scrolls, opens and serialises the *sorted* list, which is shorter than the source whenever the sort caps or deduplicates listings sharing an `object_id` — but it counted the source. Long-DOWN therefore parked the cursor past the end of the ranked window, and opening that row raised `IndexError`. The catalog's own object count is a different quantity and stays the source length, reported in the header where you are being told how big the catalog is.

Fixed alongside, all latent and adjacent:

- **A Nearby-sorted list blanked the remote web interface's object-details view.** The list arrives as the NumPy object array the ranking returns, and `serialize_ui_state` tested it for truthiness — which raises on a multi-element array. The raise landed inside the method's own `except`, so it never surfaced as a crash. It just serialised every object opened from a Nearby list as an error instead of state.
- The **"No Solve Yet"** message was unreachable and now appears.
- The **scrollbar** tolerates an empty list, which a sort can now legitimately produce from a non-empty source.
- The **spatial index** is cached on the catalog filter's `dirty_time`, the same key `UIChart` already used for its own nearby-marker index — so a filter edit cannot leave the list and the chart disagreeing about what is on the sky.
- The in-frame re-rank **holds off until the index is built**, rather than replacing a populated list with an empty one mid-draw.

The reasoning is in `docs/adr/0030-nearby-ranking-correctness-and-cost.md`.

### Opening Object Details No Longer Rebuilds the Observed-Objects Cache (#623)

Since #528 the observed-objects cache resolves every logged listing to its sky object id, so that logging an object marks it observed under all of its catalog names. It did that one lookup per listing — and `UIObjectDetails` built a new `ObservationsDatabase`, and therefore a new cache, on every entry into the screen. #564's index on `catalog_objects` took each lookup from a ~151k-row scan down to an index probe, which removed the stall; what remained was a per-entry cost that still grew with the size of your observing log.

The mapping is now one chunked query, and the screen shares a single `ObservationsDatabase` for the life of the UI process, exactly as it already did for the catalog handle. Opening the screen no longer rebuilds the cache at all.

Measured on a Pi 4 with 138 logged listings, against the indexed catalog DB: 7.2 ms of per-listing lookups versus 1.6 ms for the bulk query. Against an unindexed catalog DB — one built before #564, before the on-open backfill runs — 5.5 s versus 0.075 s.

The bulk query groups by catalog code rather than asking for a `(catalog_code, sequence) IN (VALUES …)` row-value match, and that detail is load-bearing. SQLite will not drive a two-column index from a row-value list: it constrains on `catalog_code` alone and scans the remainder of every catalog named in the chunk. WDS holds ~131k of the ~151k rows in `catalog_objects`, so a single logged double star pulled the whole WDS range into every chunk — 110 Messier listings plus one WDS listing measured 21.83 ms against 0.67 ms of per-listing lookups, a regression on the exact path the change set out to speed up. Grouped by catalog code, SQLite plans a probe per listing. There are 21 catalog codes, so this stays a handful of queries however large the log grows: 0.12 ms for that case, and 3.16 ms for 2 000 random listings against 14.07 ms of individual lookups.

### The Web Forms Validate at the API, Not Just the Browser (#571, ADR 0033)

The equipment handlers parsed form input with bare `float()`/`int()` inside a catch-all that logged and then rendered the success template regardless — so an unreadable value reported **"Eyepiece added, restart your PiFinder to use"** while saving nothing. The GPS form had no handler at all, so the same input reached you as a raw 500. A decimal comma is the easiest trigger, and PiFinder ships in German, Spanish, French and Chinese — but any unparseable value did it, including the blank instrument name of #569.

Field rules now live in one table beside the equipment dataclasses: the edit forms render them into their client-side check, and the API re-checks them before anything reaches your configuration. A failure re-renders the form with a message and the values you typed, in your language — 18 new translated strings across all four catalogs. Along the way:

- **Measurements are floats throughout**, so a 279.4 mm aperture is enterable and a configuration already carrying one now loads instead of aborting startup before the UI comes up (#291). Whole millimetres still display as `1000`, not `1000.0`.
- **The GPS form parses everything before locking anything**, so a bad clock entry can no longer half-apply a position. It also gains the decimal-comma normalisation the location forms got in #536, which never reached it, and two decimal→DMS bypasses in the locations page are closed.
- **The DeepskyLog import skips records it cannot read** — and says how many — rather than writing them through into your equipment list.
- **Route indexes are range-checked**, so a stale edit link renders an error page instead of a 500.

Covered by 68 new request-level tests, because the Selenium suite runs `en-US` and structurally cannot catch a decimal-comma bug. The rules themselves are recorded in ADR 0033 (equipment measurements are validated floats).

### Debug Frames Are No Longer Judged by Your Lens (#632)

`--camera debug` stopped solving for any developer with a stated lens. The debug camera declares the sensor its archived frames were shot on (`hq`), but the lens half of the optical train reads live from your configuration — so stating a 16 mm paired `hq × 16mm` (17.12°) against frames that are 10.2° wide, and tetra3 rejected every one before verification. Same shape as the rev4 regression, mirrored: there an assumption wore a statement's confidence; here a statement was made about hardware that is not in the loop.

The fix names the state rather than special-casing the debug camera. An **unknown optical train** is one whose frames did not come through this device's optics, and it extends ADR 0029's confidence ladder a third rung: stated → ±15%, assumed → union over shipped lenses, **unknown → no gate at all**. Two consequences follow from one rule: nothing about the device may be asserted about the frames (no FOV hint), and nothing about the device may be inferred from them (**no lens self-heal**). That second half closes a live bug — with no lens in the developer's config, debug mode solved at 10.20°, self-heal matched it to the hq's 25 mm within 1.3%, and wrote a real lens into the config off frames from a filesystem. Attach a real camera afterwards and the now-stated 25 mm stops it solving, and self-heal cannot undo it, because it only ever writes into an absence.

`CameraInterface.optical_train_known()` defaults **True**, so a camera backend has to opt *out* — a new hardware backend inherits the gate rather than silently losing it. Only the debug camera opts out.

## Documentation

This release is mostly documentation, and it is a substantial rewrite rather than a tidy-up.

### The manual is now in simplified technical English (#585, #586–#600)

Every user-facing page has been converted to a consistent house style built for this specific audience: readers standing outdoors in the dark, reading on a phone, often working through the English manual as a second language because the interface ships in German, Spanish, French and Chinese.

Seven rules: one idea per sentence, active voice, imperative instructions, simple tenses, no auxiliary chains, at most three stacked nouns, and one word per concept. The approved-term table is evidence-based — a sweep of the 13 user-facing pages counted the existing usage and the majority won (`select` over choose/pick, `screen` over display, `press` over push/tap, `object` over target/DSO, `telescope` over scope).

Pages converted: catalogs, equipment, software, v2.5 upgrade, SkySafari, connectivity, SD card, troubleshooting, menu map, quick start, the user guide, the build guide, and the shared camera includes. The starting point was 259 em-dashes and 83 semicolons across the manual.

The ring-shaped shortcut menu is now called the **Quick Menu** everywhere in the manual (#607). Polar alignment was the one section still calling it the marking menu, which is the internal code term — a reader who meets both names reasonably wonders whether they are two different things.

### New: Sky Quality Meter page (#606)

The SQM was rebuilt across #532, #544 and #560, all of which shipped in v2.6.1, but the manual never followed. Worse, the menu map still told users that "a recent solve gives the most reliable value" — which describes the pre-2.6.1 stellar path. The published value has been radiometric and solve-independent since 2.6.1, and deliberately keeps updating *through* failed solves and cloudy frames.

The new `docs/source/sqm.rst` covers reading the screen, why no plate solve is needed, why the value is not altitude-corrected, the Bortle bands (taken from the table the code actually uses rather than approximated), and the calibration wizard: when you need it, which is normally never.

It is honest about what calibration does, because the code does not support overselling it — the dark-current rate is the lasting contribution, the bias offset is superseded by the in-session black-level tracker, and read noise is diagnostic only. The headline archive accuracy figures were measured with no calibration file present at all.

### Corrections from support (#604)

Worked through a support-driven review of every page, verified against source rather than carried over on trust:

- **Equatorial platforms** (the most consequential): an alt-az telescope on an EQ tracking platform is still *operated* in alt-az. The docs told those owners to set Mount Type to Equatorial.
- **Getting a GPS lock** — a new section covering the ephemeris download, why `Sats seen/used 0/0` is not a progress bar, why power cycling restarts the wait, and why a phone is not a fair comparison. Plus a "The GPS never locks" troubleshooting symptom.
- **Rev4 Straight** sits at 45°, not "straight back". The old wording argued rear-focus telescope owners out of the configuration that actually suits them.
- **Comets and Planets** added to the catalogs page, both needing a GPS lock, with the practical "power up on WiFi beforehand" advice for comet element refresh.
- **Sleep mode** — only key presses hold the PiFinder awake. Motion wakes it but does not reset the timer, which is why polar alignment and slow slews dim the screen mid-task.
- **Eyepiece AFOV must be a whole number** — a decimal silently discards the eyepiece while still reporting "Eyepiece added".
- Smaller fixes: SkySafari's floor stated once (a paid version, 6 or later), the dovetail is one M5 bolt and does not require removing the PiFinder, field temperature reports run to 45 °C / 110 °F, Test Mode surfaced in the FAQ as the cloudy-night answer, and the web nav label reads "Network Setup" in both places.

## Developer Improvements

- **New bounded context**: `docs/ax/camera/CONTEXT.md` gains an Optics section defining lens, nominal vs effective focal length, pixel pitch, optical train, field of view and plate scale — including two flagged ambiguities, since "focal length" collides with Equipment's telescope/eyepiece vocabulary and "FOV" means three different things. `docs/ax/positioning/CONTEXT.md` gains FOV gate and fitted FOV.
- **Four new ADRs**: 0027 (FOV gate derived from the optical train), 0028 (tracked black level supersedes stored bias — the rule shipped in #544 but lived only in a commit message and a code comment), 0029 (gate width follows lens confidence, amending 0027) and 0030 (nearby ranking: a `[dec, ra]` haversine index, queried as a bounded window, with the cursor bound to the pointing). `docs/ax/camera/CONTEXT.md` gains **stated lens** and **assumed lens** to name the distinction 0029 turns on. 0030 was drafted as 0029 and renumbered on merge: the lens ADR keeps the number because seven places in shipped code cite it, against three references that all lived inside 0030's own branch.
- **Three more ADRs since**: 0031 (the chart's center object comes from the drawn markers, not the Nearby ranking), 0032 (the UBX parser yields undecodable frames as markers rather than dropping them) and 0033 (equipment measurements are validated floats — drafted as a third 0027 while the branch sat, renumbered on merge under the standing most-referenced-keeps-the-number rule). `docs/ax/camera/CONTEXT.md` gains **unknown optical train**, the third rung of 0029's confidence ladder.
- **The GPS bounded context exists now** (`docs/ax/gps/CONTEXT.md`, wired into `CONTEXT-MAP.md`). It pins down frame vs message vs marker vs event, lock vs lock type, sats seen vs used, and the location-source precedence rules — and flags the surprising bits: `gps_queue` is not a command channel (there is no main → GPS channel at all), a worse fix is silently discarded, and "solution" means something entirely different one context over. `docs/ax/equipment/CONTEXT.md` gains the validation vocabulary alongside ADR 0033.
- **`CameraProfile` gains `shipped_lens_keys`**, the set of lenses a sensor has actually been sold with. `default_lens_key` keeps its job but has a narrower one: it is now specifically *the lens to assume*, which is not the same as "the lens this sensor ships with" once two of them do.
- **`CameraProfile` moved out of `sqm/`** to `PiFinder.camera_profiles`. It describes the sensor, and SQM is only one of several consumers. It gains `pixel_pitch_um` and `default_lens_key`; `radiometric_fov_degrees` is removed and derived instead. `sqm/camera_profiles.py` re-exports for existing callers.
- **The debug camera now declares `hq`, not `imx296`** (load-bearing). Its frames in `test_images/` are ~10.2°, committed in 2022 during the HQ + 25 mm era; the `imx296` label was added later. Under derivation the old label produces a `[11.65, 15.77]` gate and **all four debug frames stop solving**, which would break `-fh --camera debug` for every developer.
- **`UITextMenu` value callbacks can now supply the default** when a config option is unset, so a menu shows what is actually in force rather than its first entry.
- **The `/docs` skill** was reworked into the simplified-technical-English house voice, with a full approved-term table, worked before/after examples from real manual lines, and a replacement pattern for each of the five ways this manual used an em-dash. Its stale facts were fixed along the way — notably a hardware reference that predated rev4 and stated, unconditionally, that PiFinder has "no on-screen battery indicator and no graceful low-battery shutdown". Rev4 has both.
- **The failed-solve log line reports the gate actually in force.** `solver.py` hardcoded `FOV est: 12.0°, max err: 4.0°` into the one message a reader consults while diagnosing a no-solve. Those constants stopped being true when the gate started coming from the optical train in #609, so for two releases the line described a window the solver had not used. It now prints the resolved gate and whether the lens is stated or assumed. (The `logger.info` that would have explained the 12 mm identification failure is invisible on a stock unit: `logconf_default.json` sets the root logger to `ERROR`, so no Integrator line reaches `pifinder.log`.)
- **`ObjectsDatabase.get_object_ids_by_listings()`** maps many `(catalog_code, sequence)` listings to their objects-table ids in one chunked, catalog-grouped query. Return types are `Optional[int]`: `catalog_objects.object_id` is nullable, so the `>= 0` guard the per-listing loop carried is live, not dead code.
- **`UIObjectList.get_nr_of_menu_items()`** now overrides `UITextMenu`'s and counts `_menu_items_sorted`. Two lengths exist on this screen and they are not interchangeable — anything addressing a row must use the length of the list it indexes, and the catalog's own size belongs in the header.
- **`SortOrder.RA` has an implementation.** The enum value, the marking-menu branch and the "Sorting by RA" message all existed; `sort()` had no branch for it, so selecting RA announced a sort and left the list alone. Both sort labels now route through one `_sort_order_label` helper, so a mode cannot be drawn under another mode's name — the drawn `Sort:` line read "Nearby" for RA. The sort is still not reachable from the Quick Menu; see "Known sharp edges".
- **115 new test functions** for the optics work, across five new suites — `test_optics.py` (63), `test_lens_self_heal.py` (19), `test_plot_frustum.py` (6), `test_lens_menu_callback.py` (8) and `test_optics_solving.py` (3, pushing real `test_images/` frames through tetra3 and guarding both directions of the debug-camera relabel) — plus additions to `test_focus_preview.py` (18) and `test_sqm.py` (2). The HQ's gate is asserted on its exact floats rather than approximately, because the one sensor that must not move under 0029 is the one that only ever shipped a single lens.
- **32 further tests** for the nearby and observed-cache work: three new suites — `test_catalog_object_indexes.py` (6), `test_objects_db_listings.py` (4) and `test_observed_identity.py` (8) — plus 12 added to `test_nearby.py` and 2 UI regression tests in `test_ui_modules.py` that drive long-DOWN then RIGHT over a catalog larger than the cap. `test_bulk_listing_lookup_uses_an_index` asserts the query *plan* rather than the result, so a rewrite back to row values fails loudly instead of quietly scanning.
- **A further ~230 tests from the late-landing work**: `test_pos_server.py` (the position server's first test suite — 382 lines covering both the SkySafari and Stellarium dialects), `test_chart_center_object.py` (302 lines), the four web-validation suites (`test_equipment_validation.py`, `test_server_equipment_forms.py`, `test_server_gps_update.py`, `test_config_equipment_load.py` — 68 tests at the request level), `test_camera_interface.py` and additions to `test_lens_self_heal.py` and `test_optics_solving.py` for the unknown-train rung, and `test_status_gps_comms.py` plus parser/dispatch additions for the GPS comms row.
- **The unit + smoke suite stands at 1,531 passing**, with no test removed in this release (verified 2026-08-25 on `main`, alongside clean ruff, mypy and a warnings-as-errors docs build). `test_ui_modules.py` carries the integration marker, so its additions sit outside that count.
- **`Starfield.radec_to_xy_many`** projects a whole candidate set in one skyfield round trip; the scalar `radec_to_xy` delegates to it, so existing callers are untouched.
- **Twenty-three new translatable strings since 2.6.1** — the Lens set (`Lens`, `12mm`, `16mm`, `25mm`), `Center Object`, and 18 web-validation messages — across de, es, fr and zh, taking every catalog to 694 msgids with 0 untranslated and all four `.mo` files byte-identical to a fresh compile.

## Known Sharp Edges

- **A mis-stated lens still means no solves, and the device deliberately does not recover from it.** Self-heal writes into an *absence*, never over a statement, so it does not rescue you here: the gate is centred on what you declared, and a wrong declaration puts every frame outside it. The failure presents as an exposure problem, because auto-exposure is driven by match count rather than centroid count. The log now names which case you are in — `Optical train: stated 16mm lens on imx462, …` versus `assumed` — so it tells you both what the device thinks is fitted and whether anybody told it that.
- **Changing the physical lens after self-heal deadlocks, exactly as it does for any stated lens.** Once the device has measured its lens it has *stated* one, so swapping the glass leaves the gate tight around the old lens, no frame solves, no measurement arrives to correct it, and you must set the menu by hand. This is 2.6.2's accepted consequence, but it newly reaches people who never opened the Lens menu — before this change they had a window wide enough to absorb the swap. The general cure is to re-open the gate on sustained zero matches *with adequate centroids*, which is #611's scope. Until then it is documented in `troubleshooting.rst`.
- **Switching Camera Type in the menu does not clear the stored lens.** The sensor is re-detected on every boot; the lens is a sticky setting nothing invalidates. So if you have explicitly chosen a lens and then swap camera types — for example a v3 user moving to the v2 HQ camera, which ships with a different lens — the device carries your old declaration onto the new sensor and stops solving. Re-select the correct lens after any Camera Type change.
- **The 25 mm lens on an imx296 or imx462 cannot solve at all**, even when correctly declared. Those trains derive 8.26° and 6.26°, and the shipped pattern database is built for `[10°, 30°]`. The solver logs an explicit error when a gate falls entirely outside the database range, but the menu still offers the combination. These are not shipped configurations — the 25 mm exists for the HQ camera — but the menu does not say so.
- **The 12 mm lens is only partly calibrated** (#612). Its effective focal length is now measured — 13.04 mm, from six solves on a rev4 imx462 fitting 12.4366 ± 0.0025°, cross-checked by putting the 16 mm on the same board and reproducing that lens's derived field to 0.02%. The other two values are still assumptions: `radiometric_zero_point` is calibrated per sensor *on the shipped lens*, so a 12 mm user currently gets the 16 mm's zero point, and the f-number is a conservative f/2.0 against a plausible f/1.6–f/2.0. One referenced exposure sweep closes both.
- **The 12 mm's 13.04 mm rests on a single sample.** The 16 mm earned its 15.61 mm by reproducing two independently calibrated field widths on two different sensors. The 12 mm has been measured once, on a rev4 imx462, with the 16 mm fitted to the same board on the same night as the control. A second sample — ideally on an imx296, so the sensor half varies too — would put it on the same footing. Recorded as an amendment to ADR 0029 rather than a rewrite, because only the arithmetic moved: the regression 0029 exists to fix was real under either constant.
- **A Nearby list stops at the 200 nearest objects.** Scrolling no longer reaches anything beyond that, and there is no indication on screen that the list has been cut. Extending the window lazily as you scroll past 200 was considered and rejected: it buys back an ordering with no observing use, at the price of carrying a paging state machine through the re-rank path. Use the Catalog or RA sort to reach the full set.
- **The RA sort works but cannot be selected.** `SortOrder.RA` now sorts, and its label is drawn correctly wherever it appears, but the Quick Menu's Sort submenu still offers only Nearest and Standard — the slot RA would occupy is an empty option. Nothing regressed here; the sort was previously unreachable *and* unimplemented, and is now unreachable and implemented.
- **Leaving the Focus screen sideways can still leave the exposure held, which turns auto-exposure off for the rest of the session.** `MenuManager.add_to_stack` only calls `inactive()` on the outgoing screen when the *incoming* one is stateful, and `key_long_left` only deactivates the top of the stack — so anything pushed over Focus buries it, and going long-LEFT home from there discards it without releasing the hold. Removing the Quick Menu Exposure jump took away the route you were most likely to take, but three remain: long-RIGHT to object details, the power button, and an incoming object push from SkySafari — and that last one you do not initiate at all. The camera then stays at a fixed manual exposure and zero-match recovery stops running, while Settings → Camera Exp still shows "Auto". Re-selecting Auto, or a reboot, restores it. Backing out of Focus with LEFT — the ordinary route — is unaffected. The SQM screen and daytime align share the same underlying lifecycle gap. Fixing it centrally is not safe, because the date, time and location entry screens fire commit callbacks from `inactive()` and would commit early whenever a child screen is pushed — the asymmetry is load-bearing, not an oversight.
- **The center-object readout shows catalog designations, not popular names.** M 45 reads "M 45 Cr 42", not "Pleiades" — the catalog has no "Pleiades" entry at all, and the readout takes the first cross-designation exactly as the object lists already do. Preferring a popular name would be a change to that shared convention, not a fix in the readout.
- **The Stellarium dialect is verified at the protocol level, not yet broadly on hardware.** The push path was reverse-engineered against Stellarium Mobile Plus and every reply is covered by the new `test_pos_server.py` suite, but a live-app session against current Stellarium desktop and Mobile Plus is a test-plan gate, not something this release has already banked. SkySafari's traffic is covered by the same suite and its behaviour was deliberately left byte-compatible.

## Follow-Ups Filed

- **#610** — auto-exposure is driven by `Matches`, so a solver-rejected frame is indistinguishable from a dark one. `SolveDiagnostics` carries no centroid count.
- **#611** — gate zero-match recovery on centroid count. Shares #610's prerequisite and fixes the pre-existing defocus thrash too.
- **#612** — calibrate the 12 mm lens on-sky. **Partly done in this release** (#627, #628): the effective focal length is measured at 13.04 mm and `effective_focal_length_measured` is now true. The SQM zero point and the f-number are still open.
- **#613** — **done in this release.** `troubleshooting.rst` gains the "changed lens → no solves" path, narrower now that self-heal covers the never-stated case, and `BOM.rst` no longer advises "something fast with a 10deg FOV", which was imx462-specific and contradicted the parts list two lines above it.
- **#605** — outstanding SQM documentation item.

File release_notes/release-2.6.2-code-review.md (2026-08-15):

# PiFinder v2.6.2 — Pre-Release Code Review

Scope: `origin/release..origin/main` @ `6aad0645` — 23 commits, 68 files,
+5,088 / −1,976.

> **Status update, 2026-08-15.** Findings **1** and **2** have since been addressed:
> `version.txt` was bumped to 2.6.2 at `db065b60`, and **#620** removed the Focus
> screen's Quick Menu Exposure jump and replaced the transient exposure readout with a
> standing status bar. #620 **narrows finding 2 rather than closing it** — three routes
> still bury the Focus screen and strand the hold. The per-finding entries below are
> annotated; everything else stands as written and was reviewed against `6aad0645`. Eighteen commits are documentation; the reviewed code surface is
`PiFinder.optics` (new), `PiFinder.camera_profiles` (relocated), `solver.py`, `plot.py`,
`ui/preview.py`, `ui/callbacks.py`, `ui/menu_structure.py`, `ui/text_menu.py`,
`ui/align.py`, `state.py`, `api_extensions.py`, and the `sqm/` refactor.

**Method.** Three independent review agents with non-overlapping briefs — (a) optics /
camera profiles / solver / plot, (b) UI and shared state, (c) cross-cutting: SQM
refactor, i18n, upgrade path, build health. Each was instructed to try to *refute* its
own findings before reporting. Every finding below was then independently re-verified in
this session against the source, and several were re-derived numerically or executed.
Where the agents disagreed with each other or overstated a consequence, the version
below is the corrected one.

**Verdict: one blocker, one high-severity defect worth holding the cut for, and a set
of medium issues that are release-readiness rather than correctness.** The core optics
work is in good shape — the math is right, the zero-migration claim holds, and the
constants survived their move byte-identical. The problems are at the edges, and they
share a theme: **nothing ties the configured lens to the sensor actually in use**, and
the accepted risk in ADR 0027 was accepted on the strength of documentation that has
not been written.

---

## Findings

| # | Severity | Area | Summary |
|---|---|---|---|
| 1 | ~~Blocker~~ **fixed** | Release mechanics | `version.txt` still reads `2.6.1`; cutting as-is makes the release un-installable and invisible — **bumped at `db065b60`** |
| 2 | ~~High~~ **Medium** | Focus screen | The exposure hold leaks by ordinary routes, killing auto-exposure and zero-match recovery for the rest of the session — **#620 removed the ordinary route; three remain** |
| 3 | Medium | Optics | A stale `camera_lens` after an in-device Camera Type switch silently stops all solving, and the safety net does not fire |
| 4 | Medium | Docs | The Lens setting has no user documentation — the risk ADR 0027 accepted is unmitigated |
| 5 | Medium | Optics | The menu offers 25 mm on imx296 / imx462, which the shipped pattern database cannot solve |
| 6 | Medium | Chart | `frustum_box` derives the vertical extent from the width; on non-square displays it is wrong and can raise |
| 7 | Low | SQM tooling | Archive re-analysis scripts ignore the lens the archive now records |
| 8 | Low | Dev | `--camera debug` stops solving for any developer who has ever opened the Lens menu |
| 9 | Low | Optics | `CameraProfile` field defaults let a new profile produce a silently broken gate |
| 10 | Low | Optics | An unrecognised lens key falls back with nothing in the log |
| 11 | Low | Web API | Unsynchronised optical-train cache shared across waitress threads |
| 12 | Low | i18n | `"HOLD"` is unwrapped; the `AI-TRANSLATED` marker was displaced in es/fr |
| 13 | Info | — | ADR 0027's "within 0.02°" is really 0.0226°; `state.py` loads `Config()` twice |

---

### 1. ~~BLOCKER~~ FIXED — `version.txt` was still `2.6.1`; the release would have been invisible in the field

> **Resolved at `db065b60`:** `version.txt` on `main` now reads `2.6.2`. Verify
> end-to-end at **G4.1** that a real 2.6.1 device is actually *offered* the update —
> that is the behaviour this finding was about, not the file contents.

**`version.txt`** — `git diff origin/release..origin/main -- version.txt` is empty. Both
branches read `2.6.1`. The bump to `2.6.2` exists **only as an uncommitted edit in the
maintainer's working copy**.

This is not merely a cosmetic version-string problem. `ui/software.py:245` fetches
`raw.githubusercontent.com/brickbots/PiFinder/release/version.txt` into
`_release_version`, and line 353 gates the update on
`update_needed(self._software_version.strip(), self._release_version.strip())`. If
`release` ships 2.6.2 code with `2.6.1` in the file, **every existing 2.6.1 device
compares `2.6.1` against `2.6.1`, renders "No Update needed", and `_go_for_update` is
never set — the update is never offered at all.**

Secondary: the Software screen, `splash.py:49`, `server.py:216` and
`api_extensions.py:851` would all report `2.6.1` for 2.6.2 code, misattributing every
field bug report for the life of the release.

**Fix:** commit the bump to `main` before the cut, then re-run Gate 1.

---

### 2. ~~HIGH~~ MEDIUM — The Focus screen's exposure hold leaks, and takes auto-exposure down with it

> **Narrowed by #620, not closed.** The Quick Menu Exposure jump — the one route an
> ordinary user was likely to take — is gone, and the transient top-left readout became a
> standing bottom status bar carrying the exposure and the UP/DOWN keys that replaced the
> jump. The marking menu was kept (blanking `left` rather than nulling the menu) because
> `MarkingMenu.up` defaults to HELP and this screen has help pages.
>
> **Routes b, c and d in the table below still leak**, and **d is involuntary**. The
> lease fix remains the real cure and is still outstanding — see the fix options at the
> end of this finding. Do not treat #620 as closing this.
>
> One deliberate consequence: the Focus screen can no longer persist an exposure at all.
> Saving now means `Settings → Camera Exp`, and the docs were updated to say so.

**`ui/preview.py:153-171`** (`inactive()`), enabled by
**`ui/menu_manager.py:190-218`** (`add_to_stack`) and **`:414-428`** (`key_long_left`).

`_begin_exposure_hold()` sends `set_exp_transient:<µs>`, which sets
`_auto_exposure_enabled = False` in the camera process (`camera_interface.py:558-573`).
The only things that ever set it back are the `set_exp:auto` command
(`camera_interface.py:523-533`) and camera-process startup. The release path is
`inactive()` and nothing else.

`add_to_stack` calls `inactive()` on the outgoing screen **only when the incoming item
carries a preloaded `state`**:

```python
if item.get("state") is not None:
    self.stack[-1].inactive()
    self.stack.append(item["state"])
else:
    self.stack.append(item["class"](...))
```

The Focus item (`menu_structure.py:50-53`) is neither `stateful` nor `preload`, so
anything pushed over it buries it silently. `key_long_left` then calls `inactive()` on
`self.stack[-1]` only and truncates the stack, discarding the buried Focus instance with
`_exposure_hold_active = True`.

**Consequence:** the camera stays pinned at a manual exposure for the rest of the
session. Solver-driven auto-exposure and zero-match recovery are both dead — recovery
only runs inside `if self._auto_exposure_enabled` at `camera_interface.py:430`. Settings
→ Camera Exp still shows **"Auto"** checked, so nothing surfaces it. Recovery requires
re-selecting Auto or rebooting.

**Why this is worse than PR #614 documented.** The PR characterises the leak as an
"exotic exit" — long-RIGHT to recent objects, then long-LEFT. But the Focus screen's
*own* Quick Menu carries an **Exposure** jump (`preview.py:134-141`,
`menu_jump="camera_exposure"`). Adjusting exposure from the focus screen is an entirely
ordinary thing to do while focusing, and:

| Route | Result |
|---|---|
| Focus → Quick Menu → **Exposure** → long-LEFT | **LEAK** — no camera command sent on exit |
| Focus → incoming object push (`pos_server` → `jump_to_label("recent")`) → long-LEFT | **LEAK** |
| Focus → POWER (`base.py:597` → `jump_to_label("shutdown")`) → long-LEFT | **LEAK** |
| Focus → long-RIGHT (object details) → long-LEFT | **LEAK** |
| Focus → LEFT (control) | Correct — `set_exp:auto` sent once, idempotent on the double `inactive()` |

The agent reproduced the first two by driving the real `MenuManager` over a real
`UIPreview`; I re-verified the gating code and the camera-side flag independently. The
marking-menu Exposure jump already existed on `release` — **only the hold is new, which
is exactly what converts a dormant lifecycle gap into a camera-state bug.**

Compounding it: the `camera_exposure` menu (`menu_structure.py:916-958`) has no
`post_callback` on plain back-out, so a user who opens it and leaves without selecting
gets config saying `auto` while the camera is manual.

**Fix options.** Making Focus `stateful` does **not** work — the `state` check in
`add_to_stack` is on the *pushed* item, not the buried one. Either `add_to_stack` /
`key_long_left` must deactivate what they bury (which this project deliberately leaves
alone, because `dateentry` / `timeentry` / `locationentry` fire commit callbacks from
`inactive()`), or the hold must stop depending on `inactive()`. The repo already has the
right precedent for this exact shape: the **black-level lease**
(`tests/test_black_level_lease.py`). A leased transient exposure that the Focus screen
renews each frame and the camera process drops on expiry closes every route above at
once, without touching the load-bearing lifecycle asymmetry.

**Recommendation:** hold the cut for this, or ship the Focus exposure hold disabled. It
is on the screen users visit most on their first night, and its failure mode is a
degraded solver that nothing in the UI explains.

---

### 3. MEDIUM — A stale `camera_lens` after an in-device Camera Type switch silently stops solving

**`ui/callbacks.py:196-211`** (`switch_cam_imx477` / `_imx296` / `_imx462`) and
**`optics.py:170-180`** (`resolve_lens`).

The sensor half of the train is re-detected every boot. The lens half is a sticky config
value, and **nothing invalidates it** — I grepped every `camera_lens` reference; the only
writer is the menu's `post_callback`. The `switch_cam_*` callbacks rewrite the dtoverlay
and reboot but leave `camera_lens` untouched.

Trigger: a v3 user who has explicitly selected **16mm** later swaps to the v2 HQ camera
via Advanced → Camera Type (the HQ ships with the 25 mm). After reboot:

```
resolved:  hq + 16mm  ->  17.12°,  gate [14.55, 19.69]
actual:    hq + 25mm  ->  10.33°
```

Every frame is pruned before verification. Per ADR 0027 this is deliberate for a
*mis-stated* lens — but here the user never mis-stated anything; **the device's own menu
invalidated their earlier statement.**

The safety net does not fire. `_warn_if_outside_solver_database` (`solver.py:155-186`)
logs only when the gate has *no overlap* with the database's `[10.0, 30.0]`, and
`[14.55, 19.69]` overlaps. So the log shows a cheerful `Optical train: 16mm lens on hq…`
and nothing else, while the UI presents it as an exposure problem. The reverse direction
(HQ → v3 with a stale `25mm`) does warn, because that gate falls entirely below
`min_fov`.

**Fix:** clear `camera_lens` in the `switch_cam_*` callbacks — falling back to the new
sensor's `default_lens_key` is exactly right. Cheap and closes finding 8 too.

---

### 4. MEDIUM — The Lens setting has no user documentation

ADR 0027 accepts "a mis-stated lens means no solves, and we deliberately do not recover
from it" on the **explicit grounds** that *"the troubleshooting path documents cleanly"*
and *"'solves stopped after I changed the lens' is a documentation problem, not a code
path."*

That documentation is not in this release:

- `docs/source/menu_map.rst` lists Camera Type under Advanced (lines 210, 281) — **no
  Lens entry.**
- `docs/source/user_guide.rst:967` still says the once-configured settings are
  "PiFinder Type, Camera Type, and GPS Settings".
- `docs/source/troubleshooting.rst` has no lens/no-solve entry.

The `docs/ax` and ADR side of #608 is thorough; the user-facing side was not written.
**#613 is filed for exactly this and is docs-only** — pulling it into the cut would
convert an unmitigated risk into the mitigated one the ADR assumed. There is a real irony
in a release whose other 18 commits rewrite the entire manual shipping its one new user
setting undocumented.

---

### 5. MEDIUM — The Lens menu offers combinations the shipped database cannot solve

**`ui/menu_structure.py:1072-1096`.** The menu is a static three-item list with no
per-sensor gating. Verified directly against the shipped
`python/PiFinder/tetra3/tetra3/data/default_database.npz` (`props_packed` → `min_fov =
10.0`, `max_fov = 30.0`):

| Sensor | 12 mm | 16 mm | 25 mm |
|---|---|---|---|
| imx296 | 17.78° | **13.71°** | **8.26° — cannot solve** |
| imx462 / imx290 | 13.51° | **10.40°** | **6.26° — cannot solve** |
| HQ | 22.16° | 17.12° | **10.33°** |

The solver does log the explicit "no frame can solve" error for these two, because their
gates fall entirely below `min_fov` — so this is the one place the safety net works as
designed. But the menu presents nine combinations as equally valid and two of them are
dead. Note this also contradicts #608's claim that `min_fov=10.0, max_fov=30.0` "already
spans every combination": it spans the four combinations the ADR validated, not the nine
the menu offers.

**Fix:** either gate the menu items by sensor, or note the constraint in the Lens menu
help and in the docs from finding 4.

---

### 6. MEDIUM — `frustum_box` derives the vertical extent from the width

**`plot.py:56-60`:**

```python
offset = (width - ratio * width) / 2
return (offset, offset, width - offset, height - offset)
```

The projection scale is uniform (`pixel_scale` at `plot.py:206-207` derives from
`render_size[0]` only), so a square camera field must map to a `ratio * width` **square**.
The returned box is `ratio*width` wide but `height − (width − ratio*width)` tall — a
constant 80 px shortfall on a 320×240 target.

Because `frustum_box` now gates **both** the shading and the `visible_stars` filter
(`plot.py:524-535`), the Align screen shades sky the camera can actually see and drops
legitimate alignment stars near the top and bottom of the field.

At low ratios the box becomes **inverted**, and that is not merely cosmetic — I executed
it:

```
320×240, imx296 @ 60° chart FOV: ratio 0.229 -> box (123.4, 123.4, 196.6, 116.6)
PIL 10.4.0 ImageDraw.rectangle -> ValueError: y1 must be greater than or equal to y0
```

The Align screen's `fov_list` is `[5, 10.2, 20, 30, 60]` (`ui/align.py:85`) and it draws
with shading on, so 60° is reachable. `st7789` (320×240) is a selectable display
(`displays.py:578`). The `visible_stars` filter `(y_pos > top) & (y_pos < bottom)` also
yields the empty set whenever the box inverts.

**Two corrections to the agent reports, which both flagged this:** it is **not a 2.6.2
regression** — `origin/release:plot.py:387-398` has the identical formula — and one
agent's claim that #609 "makes the error more visible" is backwards. The shortfall is a
constant 80 px, so a larger box means a *smaller* relative error, and the inversion
threshold moves in the safe direction for every shipped sensor (old `9.5/fov < 0.25`
degenerates above 38°; imx296's `13.71/fov` not until 54.8°). What the refactor *did*
change is that the bug is now a named, tested function whose tests
(`test_plot_frustum.py`) use only `RENDER_SIZE = (128, 128)` — so it is locked in behind
green tests.

**Fix:** `off_x = (width - ratio*width)/2; off_y = (height - ratio*width)/2`, and add a
non-square case to `test_plot_frustum.py`. Square panels (128/176) — which is the
mainstream shipped hardware — are unaffected either way, so this need not block the cut.

---

### 7. LOW — Archive re-analysis scripts ignore the lens the archive now records

**`python/scripts/evaluate_radiometer_archive.py:120`** and
**`python/scripts/report_sqm_production_archive.py:142`** call
`radiometric_sqm(sample, profile)` / `accumulator.estimate(profile, now, …)` with no
`field_width_degrees`, so `radiometer.py:184-185` falls back to
`optical_train_for_profile(profile).fov_degrees` — the sensor's *shipped* lens —
regardless of what the sweep metadata says was fitted.

This release fixed the **writer** (`save_sweep_metadata` now records `lens`,
`lens_effective_focal_length_mm`, and a derived `radiometric_fov_degrees`) but not the
**readers**. The writer's own docstring says the omission "silently poisons the next
calibration".

Harmless today — every archived sweep is on a shipped lens, and derived-vs-retired
constants differ by < 0.005 mag. It bites the first 12 mm sweep analysed: reducing an
imx296 + 12 mm sweep at 13.71° instead of 17.78° is a **≈ −0.56 mag systematic**, folded
straight into any refitted `radiometric_zero_point`, which then ships to every user.
Given #612 asks for exactly that 12 mm sweep, this will be stepped on. Developer tooling
only, not shipped runtime.

---

### 8. LOW — `--camera debug` breaks for any developer who has opened the Lens menu

**`camera_debug.py:41`.** The relabel to `"Debug hq"` is correct and well-tested, but it
fixes only the *sensor* half. The lens half still comes from config:

```
--camera debug, camera_lens unset  -> gate [ 8.78, 11.88], frames 10.2°  SOLVES
--camera debug, camera_lens "16mm" -> gate [14.55, 19.69], frames 10.2°  NO SOLVE, no warning
```

Same root cause as finding 3, and the same fix helps. `test_optics_solving.py` does not
catch it because it calls `build_optical_train("hq")` with `lens_key=None` directly
rather than going through config. Affects the `pifinder-remote` skill and the
docs-screenshot workflow.

---

### 9. LOW — Profile field defaults let a new profile produce a silently broken gate

**`camera_profiles.py:52,58`.** `pixel_pitch_um` and `default_lens_key` are both required
for the derivation but default to `0.0` / `""`. A new profile that forgets the pitch
yields `fov_degrees == 0.0` and `solver_fov_params() == (0.0, 0.0)` — a device that never
solves, with no exception and no log line. `test_optics.py` pins `default_lens_key` via
`test_every_profile_names_a_registered_default_lens` but there is no equivalent for
`pixel_pitch_um`. A forgotten `default_lens_key` at least raises `ValueError: Unknown
lens: `.

---

### 10. LOW — An unrecognised lens key falls back with nothing in the log

**`optics.py:178-180`.** `resolve_camera_profile` logs a warning on an unknown sensor;
`resolve_lens` does not on an unknown lens. A hand-edited or downgraded config saying
`"18mm"` runs as 16 mm with nothing whatsoever in the log. Given ADR 0027 makes the log
*the* diagnosis path for this entire class of problem, the asymmetry matters.

---

### 11. LOW — Unsynchronised optical-train cache shared across waitress threads

**`api_extensions.py:31, 471-473`** with `OpticalTrainResolver.resolve` at
**`optics.py:284-291`** — an unsynchronised check-then-set. Two `/chart` requests
interleaving across a lens change (or the boot-time `imx296` → detected-sensor
transition) can leave `_key = A` with `_train = train_B`, so later requests for key A get
the wrong train until the key changes again: wrong frustum size and a wrong
`visible_stars` box. The comment at `:465-470` reasons carefully about waitress threading
for the adjacent `Starfield` object; the resolver next to it has the same exposure. Very
narrow window, web-chart-cosmetic impact.

---

### 12. LOW — i18n residuals

- **`ui/preview.py:648`** — `exposure_mode = "HOLD"` is not wrapped, so the Focus → Stats
  screen shows English "HOLD" in de/es/fr/zh. Mitigating: the adjacent `"AUTO"` /
  `"MANUAL"` at `:652` are equally unwrapped and already ship that way on `release`, so
  this is consistent with existing behaviour rather than a regression. Fixing all three
  together is the clean call.
- **`locale/es/…/messages.po`, `locale/fr/…/messages.po`** — the standalone
  `# AI-TRANSLATED (claude): needs human review` comment that preceded `GPS Settings` was
  displaced onto the newly inserted `Lens` entry (which carries its own copy), silently
  dropping `GPS Settings` off the human-review queue in those two catalogs. Review
  metadata only, zero runtime effect.

---

### 13. Informational

- **ADR 0027 slightly overstates its own result.** It claims 15.61 mm reproduces both
  calibrated widths "to within 0.02°". imx462 derives **10.4028** against the shipped
  **10.38** = **0.0226°**. Nothing fails — `test_optics.py`'s tolerance is 0.03° — but
  the ADR and the PR body should say 0.03°.
- **`state.py:304,308`** constructs `config.Config()` **twice** in
  `SharedStateObj.__init__` (once for `target_pixel`, once for `camera_lens`) — two full
  disk reads plus Equipment/Locations parsing in the manager process at boot. Hoist one
  local.

---

## What was verified as correct

This is the larger half of the review, and it matters as much as the findings.

**The optics math is right.** `fov = 2·atan((crop_width_px · pixel_pitch_µm / 1000) / 2 /
f_eff)`, degrees conversion correct, `atan2` arguments positive. It matches tetra3's own
definition — `fov_estimate` is the **horizontal** FOV of the image width
(`tetra3.py:1603`) — and it matches the real pipeline: `camera_pi.capture()` does
`profile.crop_and_rotate(raw)` then `.resize((512,512))`, so the crop width *is* the
solver image width. The crop is square for imx296 (1088²) and imx462/290 (980²); hq is
1516×1520, a 0.26 % anisotropy, far inside the gate. Effective focal length is the only
one used in arithmetic; nominal reaches only `menu_label`.

**No existing user's SQM moves.** Derived field widths against the three retired
per-sensor constants — recomputed independently in this session:

| Profile | Retired constant | Derived (shipped lens) | ΔSQM |
|---|---|---|---|
| imx296 | 13.71 | 13.7116 (16 mm) | +0.0003 mag |
| imx462 / imx290 | 10.38 | 10.4028 (16 mm) | +0.0048 mag |
| hq | 10.34 | 10.3284 (25 mm) | −0.0024 mag |

**Backward compatibility is clean — there is no KeyError path.** `camera_lens` is absent
from `default_config.json`, so `Config.get_option` returns `None` →
`resolve_lens(profile, None)` → `profile.default_lens_key`. An unknown lens key, an empty
string, a non-string, and an unknown *sensor* all fall back rather than raise. A 2.6.1
config boots and solves identically. No config migration is needed and none is added.
`text_menu.py:64-76` was patched so a stored `None` plus a `value_callback` keeps the
resolved default rather than snapping to `items[0]` — which is what stops a 2.6.1 config
from displaying "12mm"; the Lens menu is the **only** menu in the tree with both
`config_option` and `value_callback`, so that change has no other blast radius.

**The `camera_profiles` move is clean.** `sqm/camera_profiles.py` is a pure 26-line
re-export shim with no duplicated or diverged table. I confirmed by import that
`CAMERA_PROFILES`, `CameraProfile`, `get_camera_profile` and `detect_camera_type` are
`is`-identical through both paths. All six remaining old-path importers resolve. No
circular import. A full-text diff of the 466-line original against the 500-line
relocation shows **zero numeric change** to any radiometric constant — `bias_offset`,
`radiometric_zero_point`, `radiometric_colour_slope/pivot/range`, `clear_zero_point`,
`clear_sky_brightness`, `sqm_band_offset`, `color_coefficient`, gains and crops all
carried across unchanged. The only removal is `radiometric_fov_degrees`, which has zero
remaining attribute readers.

**All four shipped default trains sit inside the bundled pattern database.** imx296
13.71 → [11.65, 15.77]; imx462/290 10.40 → [8.84, 11.96]; hq 10.33 → [8.78, 11.88],
against `min_fov 10.0, max_fov 30.0`. The ±15 % gate is genuinely tighter than the
retired ±33 % and correctly centred where `12.0 ± 4.0` was not.

**The debug-camera relabel is right and end-to-end tested.** `test_optics_solving.py`
really solves both `test_images/` frames through tetra3 with the hq train, confirms the
fitted FOV (10.2°) is within 5 % of derived, and confirms the imx296 train rejects the
same centroids.

**Solver integration is defensively correct.** Resolution sits inside the same
`BrokenPipeError` / `ConnectionResetError` guard as the rest of the loop, logs once per
change (cached under the stated key, so an unknown sensor logs once, not per frame), and
`t3.database_properties` genuinely exists. No startup race:
`camera_interface.get_image_loop` calls `set_camera_type` before the first capture, and
the solver only resolves a train after `is_new_image`, so the pre-camera `imx296` default
is never used for a real frame.

**Shared state propagates correctly.** `camera_lens()` / `set_camera_lens()` are scalar
getter/setter *methods* on the `BaseManager`-proxied object — a proxied method call, not
a nested-container mutation, so it crosses process boundaries. No stale-state window:
`text_menu.py:187` writes config before `:251` fires `set_camera_lens`, and every
consumer re-resolves live (solver per frame, align per frame, camera per call, API per
request).

**Exposure clamping on the Focus screen is safe.** `FOCUS_EXPOSURE_LADDER` is pinned
equal to the Camera Exp menu values by test, `step_exposure` cannot leave the ladder, and
the AE controllers clamp to the same `[25_000, 1_000_000]` µs bounds. The genuinely
unclamped `exp_up` / `exp_dn` (×1.25 with no ceiling) is **not reachable** from the Focus
screen — only `ui/align_daytime.py:360-364` sends it, unchanged in this release.

**Menu index drift causes no breakage.** Lens lands at index 2 of Settings → Advanced;
only `GPS Settings` shifts 2 → 3. `tests/website/test_web_remote_settings.py:24`
explicitly excludes the Advanced submenu, no test hard-codes an index there, and the
`camera_lens` label does not collide. (Worth a spot-check anyway during G6.3 — index
drift broke three remote tests during the 2.6.1 cycle.)

**`frustum_box` fixed a latent `ZeroDivisionError`** for callers that pass no
`camera_fov` (`ui/chart.py`), which the old unconditional `9.5 / self.fov` would have hit.

**Build health.** `pytest -m "smoke or unit"` → **1,229 passed, 0 failures**, 472
deselected (**1,238 on `main` after #620**) — reproduced identically in the maintainer's checkout and in a clean worktree
rooted on `origin/main` with a freshly initialised `tetra3` submodule. Ruff and mypy
clean. Sphinx `-nW` build succeeds with **0 warnings** over 18 sources, with no
`suppress_warnings` or `nitpick_ignore` in `conf.py` to mute it. `sqm.rst` is wired into
the `index.rst` toctree and its three new images are present. i18n: 671 → 675 msgids, 0
untranslated, 0 fuzzy in all four catalogs, with every `.mo` byte-identical to a fresh
compile. ADR numbering is collision-free after #616, and all 16 cross-references to
0027/0028 resolve.

---

## Recommendation for the cut

**Must fix before the cut — both now done:**
1. ~~Commit the `version.txt` bump (finding 1).~~ **Done at `db065b60`.**
2. ~~Decide on the Focus exposure-hold leak (finding 2).~~ **#620 removed the ordinary
   route in and replaced it with a discoverable status bar.** This lowers the likelihood
   substantially and leaves the impact unchanged, so the leak moves from blocker to
   accepted risk. The lease fix is still the right long-term answer and should keep its
   own ticket.

**Should fix before the cut — cheap and high value:**
3. Clear `camera_lens` in the `switch_cam_*` callbacks (findings 3 and 8, one change).
4. Pull #613 in, or write the equivalent minimal Lens documentation (finding 4). The
   ADR's accepted risk is explicitly predicated on it.

**Can ship, fix after:** findings 5, 6, 7, 9, 10, 11, 12, 13. Note that finding 7 should
be fixed *before* anyone runs the 12 mm calibration sweep that #612 asks for, or the
resulting constants will be biased by ≈ 0.56 mag.

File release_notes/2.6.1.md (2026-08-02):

# PiFinder v2.6.1 Release Notes

A substantial point release built on field feedback from v2.6.0: a rebuilt Focus screen that shows you the actual stars, a self-calibrating Sky Quality Meter that finally holds steady through a night, chart markers for the objects around you, full software enablement for rev4 hardware (battery, sound, power button, 176px display), and a fix for a bug that silently killed plate solving on any unit you'd ever SSH'd into.

## ⚠️ After You Update

- **SQM readings are on a new scale.** The Sky Quality Meter was rebuilt around raw-sensor photometry with per-frame black-level tracking. Values are no longer comparable with readings logged under v2.6.0 or earlier. The SQM screen will also show as **uncalibrated** after updating — the calibration file is now keyed to the camera rather than the processed image. A wizard run is no longer required to get a reading, but re-running `SQM → CALIB` (long-press for the marking menu) restores the per-camera dark-current refinement.
- **Observed status is now a property of the object, not the listing.** Logging M 31 marks NGC 224 observed, and your existing log history is applied retroactively. Expect an "Observed: No" list to visibly shrink on first use, sibling rows to gain checkmarks, and a sibling's details to show the combined log count. This is intended.
- **Set Time/Date now needs a location fix first.** Manual time is interpreted in the observer's timezone, which only exists once a location is known. The screen still opens; it shows "Set location first" and you back out with LEFT.
- **Some labels changed.** The Type filter now uses the same labels as the object-detail screen (`P. Nebula` → `Planetary`, `Double Str` → `Double star`, `Cluster/Neb` → `Cluster + Neb`, …). On the Status screen, `GPS LST` is now `GPS LCK` (last GPS lock — it was being misread as Local Sidereal Time). The SQM marking menu reads `CALIB` and `SWEEP` (was `CAL` / `CORRECT`).
- **A one-time system migration runs on update** (`v2.6.1`), adding a `RemoveIPC=no` drop-in for systemd-logind. See the shared-memory fix below for why.
- **If you're running a rev4 board with a pre-release config**, the `v4_left` / `v4_right` / `v4_straight` screen-direction values are automatically migrated to `rev4_*`. No action needed.

## New Features

### Rev4 Hardware Enablement (#498, #530, #539)
Full software support for the fourth-revision PiFinder board, all gated on runtime hardware detection so **rev3 and dev boards are unaffected**:

- **Battery telemetry** — BQ25895 charger read over I²C, with a title-bar battery icon (level buckets plus a charging bolt) and an idempotent fast-charge configuration re-asserted on every poll.
- **Sound** — an earcon subsystem on the rev4 passive buzzer, with a new `Settings → User Pref → Volume` setting (Off, 1–5). Delivery is best-effort and latest-wins, so audio never blocks the UI.
- **Power button** — a dedicated power key that opens a shutdown confirmation; a second press confirms, and the shutdown earcon plays before the GPIO14 power latch fires.
- **SSD1333 176×176 display** — rotation fixes, a resolution-flexible boot splash, and the 5-column rev4 keypad matrix with its directional cluster.
- **New build variants** in `Settings → Advanced → PiFinder Type`: **AS Heart**, **Rev4 Left**, **Rev4 Right**, and **Rev4 Straight**, joining AS Bloom. Each carries the IMU-to-camera frame constants for that mounting, derived with a new visual `imu2cam` tool and pinned to the production tables by test.

### Low-Battery Safety (#541, #549)
On battery-equipped hardware, PiFinder now warns and then shuts itself down cleanly rather than running blind into an SD-corrupting hard power cut. Advisory popups (plus an earcon) fire once at **10%** and once at **5%** state of charge, and when the charger's ADC goes blind at ~3.5 V for four consecutive polls on battery, PiFinder shows a final warning and performs an orderly software shutdown. Warnings latch for the whole discharge — only plugging in a charger re-arms them — so ADC quantisation noise near the flat knee of the discharge curve can't re-fire them (field logs showed the first implementation firing ~90 times a run). The state-of-charge curve was re-anchored on bench discharge data with 0% at the shutdown point.

### Rebuilt Focus Screen (#531)
The Focus screen now finds the **four brightest stars** in the frame and shows each magnified in its own quadrant, holding its quadrant as the image shifts under your hand. Tiles are raw camera pixels — crop and nearest-neighbour enlargement only, no sharpening or contrast tricks — so what you see is honestly how tight your stars are. The **HFD** readout sits at the center with a 10-second trace along the divider, and **SQUARE** cycles four views:

- **Stars** — the four magnified tiles
- **Single** — the brightest star alone at double magnification
- **Image** — the full camera frame
- **Stats** — HFD with an FWHM estimate, detected-star count, exposure, gain, and a raw histogram

**+/−** adjusts magnification between 4x and 16x, and a badly defocused star automatically gets a wider view so its donut isn't clipped. None of this needs a plate solve, so it works however far out of focus you start.

### Self-Calibrating Sky Quality Meter (#532, #544, #560, #561)
The SQM wandered 0.7–2.4 magnitudes within a night as auto-exposure moved, and shifted with focus and sensor swaps. It was rebuilt end to end:

- **Radiometer-first publication** — the published value now comes from the raw diffuse sky background, exposure, and a per-sensor radiometric zero point. It **no longer needs a plate solve**, so it keeps updating through failed solves and star-poor or cloudy frames.
- **Raw photometry** — measurement moved off the clipped 8-bit processed image onto the linear raw frame (Bayer green, or the mono frame). Plate solving is untouched.
- **Tracked black level** — a per-session estimator joint-fits the true black level from the auto-exposure stream, replacing a static pedestal constant that never matched the sensor.
- **A zero point that follows the sky's colour** — the radiometer measures sky in the *sensor's* passband while a reference meter measures V, and converting between them depends on the sky's spectrum: light pollution is sodium/LED and green-weighted, airglow is grey and NIR-rich. One constant per camera was therefore wrong at one end of the range or the other — the shipped value read ~0.1 mag dark at a light-polluted site and ~0.85 mag bright at a dark one. On bare sensors (imx462/imx290) the zero point is now a measured function of the frame's own red/green ratio, clamped to the calibrated range rather than extrapolated. Mono sensors and the IR-cut HQ keep a plain constant, both refit.
- **Colour and wing corrections** — a per-sensor B−V colour term (sensors without an IR-cut over-flux red stars) and a measured aperture wing correction that tracks how the star halo grows with dew and seeing.
- **Scale-aware geometry** — photometry radii are now expressed in the photometry image's pixel pitch, which fixes the imx296 (whose full-res frame put the aperture inside the star profile and left the wing estimator permanently inert).
- **Calibration wizard fixes** — captures now gate on the sensor's *actual* reported exposure with a re-capture on stale frames, and discard optical-black clamp-settle frames after each exposure change.

Stability, measured across 19 referenced exposure sweeps on four devices: within-sweep swing went from 0.7–2.4 mag to a 0.07–0.22 standard deviation, and focus sensitivity from large to 0.03 mag. Absolute accuracy against hand-held reference meters, re-derived over the full 23-sweep imx462 archive: median residual +0.005 mag with the spread collapsing from −0.23…+1.08 to −0.18…+0.16, and leave-one-night-out cross-validated error 0.247 → 0.108. The HQ's refit constant lands on a median of +0.000.

Some of the calibration is still thin, and says so in the code: the imx462 colour model's dark-site anchor is a single night, the imx296 rests on four sweeps from one observer, and the imx290 constants are mirrored from the imx462 with no sweeps of its own. Reference-meter comparisons from more sites and sensors are the thing that improves this — the `SQM → SWEEP` archive is what those refits are derived from.

### Chart Markers: Target Cross and Nearby Objects (#513)
The chart's target cross had lost all its callers in an earlier refactor and never drew; nearby catalog objects were never plotted at all, so a fresh session with no observing list loaded showed a bare chart. Both are fixed:

- The **last object you opened in details** is marked with a bright cross, labelled with its designator when on-screen and replaced by a rim arrow when it drifts off. The cross stays bright even with DSO Display turned off.
- **Nearby deep-sky objects** that pass your active filters are now plotted, with a **zoom-scaled magnitude limit** (mag 11 at 5° FOV to mag 7 at 60°) so the field reveals fainter objects as you zoom in and never crowds when you zoom out. Capped at the brightest 20, deduped against observing-list markers.

### Observing List Import: CSV and Stellarium 2.0 (#510, #527)
- **CSV is now genuinely importable from other tools.** Headers are matched case-insensitively through an alias table (`name`, `ra`/`ra_deg`, `dec`/`de`, `mag`/`magnitude`/`vmag`, …) in any column order, and coordinates parse as decimal degrees, `HH:MM:SS`, or sexagesimal. A decimal RA is degrees unless the header names hours (`RA_h`). Previously only PiFinder's own exact export format loaded — anything else silently imported as nameless objects at RA 0 / Dec 0.
- **Stellarium 2.0 lists import.** Current Stellarium builds export a new schema (lists nested under `observingLists`, whitespace-free RA strings, display-string object types); these silently produced an empty list. Both 1.0 and 2.0 now work, and object types that PiFinder doesn't recognise are coerced to `?` so they can't vanish behind the Type filter.

### Bench Bring-Up Tool (#550, #551, #552, #556)
`python -m PiFinder.bringup` validates a freshly assembled board in one command, without booting the application — no catalogs, solver, camera, or menu system, so it runs on a card with nothing configured. It drives the screen, keypad backlight, and buzzer, interrogates the IMU and charger, and scans every populated switch in the keypad matrix. Checks are typed by what actually proves them — *probed*, *exercised*, or *witnessed* — and only the first two can gate the exit status, because a program cannot know whether sound came out of a buzzer. A pre-flight pass checks card provisioning first, so a misprovisioned image is never diagnosed as a bad board.

Holding the power switch for one second ends the run and asks the OS for a clean shutdown — the same gesture the finished unit uses for the same switch, so a builder at a bench with no terminal in sight never has to pull power on a mounted filesystem. A tap still just registers the closure for the switch check, and the power cell fills a bar over the second so the boundary is visible and an accidental hold can be released.

## Improvements

- **SSD1333 dimming range** (rev4 displays): the panel's two current registers bottom out about 20x brighter than a red night-vision display wants at a dark site. Brightness now uses the gray scale ceiling as a third axis, taking the dimmest setting from 0.106% of full to 0.005% — a 13,400:1 range over 253 distinct levels, with the full 31 shades preserved at any setting at or above 0.35%. Full brightness is held to 70% of available current, measured as the point where bright pixels stop blooming. The 128×128 SSD1351 is unaffected.
- **Object type codes are single-sourced** (#511): the Type filter menu is generated from `OBJ_TYPES` rather than a hand-maintained duplicate list, with a drift guard that also covers the shipped default filter selection and the docs table.
- **Filtered lists stay fresh** (#528): logging an object now drops it from an "Observed: No" list on the next refresh, altitude-filter verdicts age out as the sky rotates (600 s TTL), and the arrival of the first GPS fix triggers a refilter — closing the boot-time gap where pre-lock verdicts let everything through forever. A list left open refreshes in place, and the cursor stays on target across refreshes, falling to the next surviving object rather than jumping to the top.
- **Timezone handling made explicit** (#508): shared state now always stores a UTC-aware datetime, with separate `utc_datetime()` and `local_datetime()` accessors so consumers can't accidentally read one as the other. This fixes the Status screen showing identical UTC and local times after manual entry, and a manual date entry that could be pre-filled 24 hours off.
- **Chinese is now actually selectable** (#562): the in-app Language menu has offered Chinese for some time and the translation shipped complete, but `zh` was missing from the validated language list in `main.py` and from the web server's accept-language match, so `--lang zh` raised "Unknown language 'zh'" and the web UI could never be served in Chinese. All four catalogs (de, es, fr, zh) are now at full coverage — 671 strings, none untranslated, none fuzzy — including the new rev4, Volume, low-battery, migration and telemetry-replay strings. Wordings were checked against the real fonts and the 128px layout budget, which caught six overflows. Two caveats: much of the translation is machine-generated and tagged in the `.po` files as needing human review (native speakers very welcome), and Chinese marking-menu labels currently render as overlapping glyphs — a known renderer issue with CJK glyph widths, not a translation problem, and one whose fix changes menu geometry for every language.

## Performance

- **Object lists open instantly** (#526): opening any catalog list re-applied the filter across all ~151k objects even when you only wanted to view NGC's 7.8k — measured at ~0.58 s per open on a Pi, from 604,680 filter calls across four opens. Catalogs already filtered against the current criteria now return their cached list, taking repeat opens from ~0.58 s to microseconds. A changed filter parameter, a deferred background load, or a comet refresh all still force a full re-filter.

## Bug Fixes

- **Plate solving silently died after an SSH logout** (#548): systemd-logind's default `RemoveIPC=yes` deletes every POSIX shared-memory segment owned by the `pifinder` user the moment that user's last login session ends — and the PiFinder services hold no login session of their own. The solver's cedar-detect segment vanished, and the recovery path raised `FileNotFoundError` *before* disabling shared memory, so the designed inline-image fallback never engaged and **every subsequent solve failed until restart**. Device logs showed ~28,000 identical solver exceptions per night on two independent units. Fixed in three layers: the client now treats an already-gone segment as released (so even the frame that hits the error still gets centroids), fresh installs get a `RemoveIPC=no` drop-in, and existing units get the same drop-in via the `v2.6.1` migration.
- **Camera Test Mode did nothing** (#542, #543): a rename in the SQM work moved the test-mode flag's initialisation inside the capture loop (resetting it every frame) and deleted the command handler that toggled it, so `Tools → Test Mode` and console key 0 had no effect on Focus or Align (Day).
- **Shared-memory solving broken by a mismatched protobuf field** (#542): the same change passed a `reopen_shmem` field the checked-in cedar-detect bindings don't have, raising `ValueError` before any RPC — and because it wasn't a gRPC error, the inline fallback never engaged. Reverted to the known-working handoff.
- **DeepskyLog equipment import crashed** (#529): importing equipment containing any new eyepiece returned an Internal Server Error, and because the save came after the import loop, telescopes collected in the same request were lost too. A v2.5.1 → v2.6.0 regression from the Flask migration.
- **Web location entry failed in comma-decimal locales** (#536): typing `51,3` (or `51.3`) into the coordinate fields and clicking Save did nothing in much of Europe — a `type="number"` input returns an empty value for locale-mismatched text, so client-side validation cancelled the submit. Only integers saved. Inputs are now text with `inputmode="decimal"`, both separators normalise before validation, and the server tolerates a comma and returns a friendly message instead of a 500.
- **GPS satellite counts were wrong on every receiver generation** (#524, #563): on protVer < 15 receivers (NEO-6/7, early M8) the per-satellite fields were parsed one byte off, so satellite IDs were channel numbers and the "seen" count was inflated to near the full channel count — the mysterious `20/0`. On protVer ≥ 15 receivers (later M8, M9, M10) the used count stayed 0 forever because NAV-PVT's `numSV` was parsed but never surfaced. Live-verified against a real MAX-M8 against gpsd's own decode. A follow-up pass fixed three more ways the counts could go wrong: a single NAV-SAT message permanently silenced the NAV-SVINFO fallback for the life of the connection (now a 5 s freshness window, so SVINFO resumes if NAV-SAT stops), NAV-PVT/NAV-SOL could publish a used count with no seen count — the physically impossible `0/9` — and NAV-SVINFO counted "used" and "seen" over different populations, so used could exceed seen.
- **Polar Align guidance corrected** (#518): field reports reversed the original advice. Step 1 said to aim *well away* from the pole, but flexure — felt mostly in camera roll — grows with how much the PiFinder's attitude changes between captures, so moderate near-pole sweeps beat wide ones.
- **Manual time entry could localise against a bogus timezone** (#512, #563): the Set Time/Date screen now gates itself on a location fix and renders a notice instead, live — the entry boxes appear the instant a fix locks while the screen is open. A location whose timezone couldn't be resolved from its coordinates now settles to UTC at the source rather than being stored as nothing: previously the screen rendered but committing the time crashed, and the line that names the zone the digits are read against was silently dropped.
- **NixOS migration wifi never connected** (#521): the initramfs shell converter wrote SSIDs into NetworkManager keyfiles as hex byte lists, but NM's keyfile format only parses decimal — so every migrated device scanned for a network literally named `61;70;6f;…`. Keyfile generation moved to unit-tested Python running on Debian before reboot; the initramfs just copies the pre-staged files.
- **NixOS migration hardening** (#523): tarballs that can't fit in board RAM are rejected before boot configuration is touched, the previous boot configuration is restored automatically after any pre-format failure, formatting is treated as the explicit destructive boundary, and unexpected `set -e` exits surface as a visible migration failure instead of panicking the kernel.
- **SQM screen exposure display and calibration detection** (#544, and the calibration-path fix above).
- **SQM diagnostic sweeps were labelled one step behind** (#561): the exposure sweep flushed a fixed two frames after each change, but the IMX290/462 serves exactly three at the old exposure — so every sweep pair's processed image belonged to the *previous* step, and the radiometer sample recorded alongside it described that image rather than its label. A fixed count can't suit every sensor (the IMX477 emits half-exposure transitional frames instead), so the sweep now watches the driver's reported exposure and discards until it matches, with a cap and a warning if it never settles. Diagnostic archives only — the on-screen SQM was unaffected.

## Hardware & Case

- **Threaded lens holddown and lens-cap accessories** (`case/accessories/tethered_lens_cap/`), contributed for v2.5 kits: an M12×0.5 threaded holddown with loose and snug jam nuts for locking focus, PETG and TPU replacement lens caps, and a tethered TPU cap that folds back against the case so it can't be lost.
- **Meade LXD dovetail adapter** (`case/adapters/dovetail_meade_lxd.stl`), contributed by John Purdy — replaces the bottom half of the standard Vixen/Synta foot with an LXD-shoe profile.
- **Threaded camera holddown for v2.5** (`case/v2.5/v25_camera_holddown_threaded.stl`).
- The obsolete tall dovetail parts were removed from `case/accessories/`.

## Documentation

- **Focus screen rewritten** in the Quick Start, covering the four views, the magnified tiles, and the small-turn technique: the whole range from badly defocused to sharp is only a few lens turns, fair-to-good is under half a turn, and 1/8–1/4 turn at a time with a pause for vibration to settle is what actually works. Later-night touch-ups should be judged on the HFD readout, not the lagging camera icon (#546).
- **Polar Alignment: "Getting a good measurement"** — per-mount advice folded in from field reports. EQ mount: point the Dec axis 7–10° off the polar axis, sweep 30–45° in RA, use Roll Off. Platform: aim within ~5° of Polaris, keep Roll On. Realistic accuracy is 20–30 arcmin, down to ~10 with a very rigid connection. Plus: turn sidereal tracking off before starting, and lock *both* mount axes before touching the adjusters — a slipping RA clutch was the most common field failure (#518).
- **Chart markers and CSV import** documented in the user guide, including a full column reference, the three accepted coordinate forms, and how to keep your own coordinates for an object the catalog would otherwise resolve.
- **Observing-list format reference** expanded with nine worked CSV examples and a JSON schema for the native `.pifinder` format.
- Menu Map updated for the new Focus views and the rev4 build variants.

## Developer Improvements

- **New bounded contexts**: `docs/ax/battery/`, `docs/ax/sound/`, and `docs/ax/bringup/` glossaries, plus `docs/bq25895_design_notes.md`.
- **Thirteen new ADRs** covering read-only battery telemetry, the gpio-poweroff latch, best-effort sound delivery, battery fast-charge configuration, UTC-aware civil datetime storage, self-gating UI modules, SoC as a runtime fraction, blind-floor shutdown, the SQM redesign, radiometer-first publication, the sky-colour-keyed radiometric zero point, SSD1333 three-axis brightness, and filter freshness.
- **Import-safe keypad module** (#551): the matrix tables moved out of `keyboard_pi` (which imports `libinput` and `RPi.GPIO` at module scope) into `PiFinder.keypad`, with per-revision population maps derived from the keymap rather than hand-listed.
- **`imu2cam` derivation tool** (#530): a single-file visual tool for deriving per-variant IMU-to-camera frame constants in 3D, emitting the `(q_imu2cam, rotate_amount)` pair with human-checkable axis correspondences and a ready-made pytest block. Its presets are pinned to the production tables by test, so tool and code can't drift.
- **`-fb`/`--fakebattery`** (#535): `-fh` alone now emulates rev3 hardware (no battery process, no title-bar icon), keeping docs screenshots on the baseline UI; `-fb` opts into the fake rev4 battery monitor, which runs a full discharge lap including the low-battery warnings and blind-floor shutdown.
- **Battery runtime analysis tool** (`python/tools/battery_runtime_analysis.py`) for fitting the state-of-charge curve from bench discharge logs.
- **~450 new tests** (1,137 unit + smoke passing), including 60 covering the bring-up tool, 46 covering NetworkManager keyfile generation, 117 covering rev4 hardware logic, and field-data regression tests that replay real discharge telemetry through the low-battery warner.
- **The SQM calibration is re-derivable in-repo** (#560): `scripts/evaluate_radiometer_archive.py` now re-fits both the constant and colour models from the sweep archive and judges them by leave-one-night-out error rather than in-sample scatter, which a free parameter always wins. The whole radiometric model is recorded in sweep metadata, so an archived sweep is self-describing rather than needing a constant looked up by camera type.

---

**Version**: 2.6.0 → 2.6.1
**Commits**: 58
**Files changed**: 242 (+26,012 / −5,692); Python: 135 files (+18,467 / −2,125)

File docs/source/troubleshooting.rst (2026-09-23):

Troubleshooting & FAQ
=====================

.. note::
   This page applies to rev4, v3 and v2.5 PiFinders running software |min_software| or above.  If
   you're on older software, updating is often the fix in itself.  See
   :ref:`user_guide:update software`.

   Not sure which you have?  See
   :ref:`Which PiFinder do I have? <quick_start:which pifinder do i have?>` in the Quick Start.

Most PiFinder problems have a quick fix.  The cause is usually something simple, such as focus
or a settings mismatch, rather than a fault.  This page is organised by *symptom*.  Find the
line that matches what you're seeing and follow it to the fix.  If your symptom isn't listed,
or a fix doesn't work, the PiFinder community on the
`Discord server <https://discord.gg/Nk5fHcAtWD>`_ is quick to help.

The PiFinder won't turn on
--------------------------

Power is the button marked **PWR**, on the front below the keypad.  Press and hold it for
about two seconds to turn the PiFinder on.  The **PWR** label lights while it boots.  Press
and hold it while the PiFinder is running to bring up the shutdown confirmation.  The
**SQUARE** key never controls power.

Things to check:

- **Is the battery charged?**  Plug a USB-C cable into the **POWER** port.  The **CHG** light
  comes on while the battery charges.  Once the PiFinder is running, the title bar shows
  roughly how much longer it will run.  See :ref:`user_guide:the battery indicator`.
- **Try a different cable and supply.**  Some USB-C cables cannot reliably carry the current
  the PiFinder draws.  If the PiFinder runs on external power but not on battery, the fault
  is in the battery, not the computer.

If none of that helps, press and hold the **PWR** button for more than **14 seconds**.  This
resets the power system itself rather than the software.  It cuts power to a PiFinder whose
software has hung and will not shut down.  It also lets a PiFinder turn on again when
something is stopping it from starting normally.  This is a hard cut rather than a clean
shutdown, so keep it for when the PiFinder is genuinely unresponsive.

.. note::
   On v3 and v2.5 PiFinders, power is a small white **slide switch**.  It slides side to side
   and is not a push button.  Facing the screen, slide right for on, left for off.  A v3 has
   no battery indicator, so plug in to charge if you're unsure.  The charging light glows
   blue while charging and green when full.  The port closest to the keypad powers the
   PiFinder *immediately, regardless of switch position*, which is a quick way to tell a flat
   battery or a failed switch from a dead computer.  If you built your own PiFinder and it
   won't turn on at all, double-check the connections to the PiSugar battery board.
   |v3_docs|

The screen is blank, or it won't finish booting
-----------------------------------------------

Rule out the simple explanations first:

- **Brightness turned all the way down.**  If you last used the PiFinder at a dark site, the
  screen may be dimmed to nothing.  Hold **SQUARE** and press **+** several times to bring it
  back.
- **Give it time on the first boot.**  A normal boot reaches the welcome screen in about
  20 seconds.  The *first* boot after re-imaging takes a minute or two and restarts itself
  several times while it sets up.  This is expected.  Wait a full five minutes before
  deciding something is wrong.

If the screen is still blank, the keypad backlight tells you where the problem is:

- **No keypad light and no screen**: this is almost always **SD card corruption**, the most
  common hardware issue.  A faint red LED inside the case means the Pi has power but is not
  booting.  Re-image the card with the latest release, or request a fresh one.  :doc:`sd_card`
  covers getting at the card on each revision.  SD card faults are all-or-nothing.  They stop
  the PiFinder booting rather than causing subtle misbehaviour, so don't re-image to explain
  slow solves or the occasional position jump.
- **Keypad lights up, but the screen is blank or garbled**: this points to the screen's
  connection, not the software.  Confirm it through the
  :ref:`web interface <connectivity:web interface>`.  If the remote screen looks correct
  there, the software is fine and the physical screen connection needs attention.  On DIY
  builds that usually means a solder reflow.

For re-imaging instructions, see :ref:`user_guide:update software` and the
:doc:`software` page.

The camera view is blank or black
---------------------------------

The Focus screen opens on its magnified star tiles, which stay black whenever the PiFinder
detects no stars.  A perfectly healthy camera therefore looks dead there in daylight or under
cloud.  Don't judge the camera by that screen.

To see what the camera sees, open the Start menu and select Align (Day).  It switches the
camera to a short daytime exposure and shows a full live image, which is the quickest way to
tell whether the camera works at all.  Point the PiFinder at something bright and you should
get a recognisable picture.  Even with the lens cap on you should see faint noise rather than
pure black.

If Align (Day) shows nothing whatsoever, the **Camera Type** setting probably doesn't match
the camera in your PiFinder.

- From the main menu, select Settings, scroll down to Advanced, then select Camera Type and
  try a different option.  A rev4 PiFinder takes ``v3 - imx462``.  There is no separate rev4
  entry, and that one is correct.  The v3 sensors are ``v3 - imx462`` and ``v3 - imx296``,
  and older v2 cameras are ``v2 - imx477``.  Trying each one does no harm.
- **After changing Camera Type, turn the PiFinder fully off and on again.**  A software
  restart alone does not apply it.
- A software update can quietly reset this setting, so re-check it after you update.

It won't plate solve ("can't find stars")
------------------------------------------

Plate solving is how the PiFinder works out where it points.  See
:ref:`quick_start:setting focus & first solve`.  When it won't solve, **focus is the cause far
more often than anything else**.  Stars that look fine at normal zoom are often not tight
enough.

Work through these in order:

- **Focus, properly.**  On the Focus screen, rotate the lens until the four magnified stars
  are as small as possible and the central HFD reaches its lowest value.  The difference
  between fair and good focus is less than half a turn.  Work in steps of an eighth to a
  quarter of a turn, and pause after each step for vibration to settle.  Judge by the HFD
  rather than the camera icon, which lags a second or so behind each change of the lens.
  Tight focus matters *even more* under bright, light-polluted skies, where slightly soft dim
  stars vanish into the background.  If you're starting from far off, set the lens so about
  6 mm of thread shows, roughly a pencil's width.  That is close to in focus.
- **Lens cap off, and hold still.**  The PiFinder can only solve a sharp, stationary
  image.
- **Exposure.**  The PiFinder defaults to **AUTO** and sets the exposure itself from each
  solve.  Leave it there unless you have a reason not to.  To set it by hand, select Settings
  from the main menu, then select Camera Exp.  0.2 s suits most skies, bright urban skies want
  0.4 s, and dark skies solve well at 0.1 s.  The Focus screen holds the exposure steady while
  it is open, so it reads ``HOLD`` there even on **AUTO**.  The **UP** and **DOWN** steps on
  that screen change the exposure for the visit only, and the PiFinder does not save them.
  Software older than 2.2 has no AUTO option, which is another reason to update.
- **High, thin cloud.**  An invisible drifting cloudbank stops solves at an otherwise perfect
  site.  If solves come and go while the telescope is dead still, suspect the sky before the
  hardware.
- **Did you fit a different lens?**  The PiFinder cannot see which lens is on the front, so it
  works from the Lens setting.  A setting that names the wrong lens stops solving completely
  rather than making it worse, because the PiFinder then looks for a patch of sky the wrong
  size.  This looks like an exposure problem.  On **AUTO** the PiFinder keeps working its way
  up and down the exposure range and still never solves.  Check the Lens setting before you
  spend more time on the exposure.  Select Settings from the main menu, scroll down to
  Advanced, then select Lens.  Set the focal length printed on the lens barrel.  The PiFinder
  restarts when you change it.

.. note::
   You only need to set the Lens by hand if you fitted the lens yourself.  A PiFinder still
   set to the lens it shipped with works this out on its own.  It allows for every lens it
   might have come with, then records the one it measures after its first few solves.

.. note::
   On older v2 cameras the lens has two rings, a focus ring and an aperture ring.  The
   **aperture must be fully open** for the PiFinder to see enough stars to solve.

The GPS never locks
-------------------

A first lock takes several minutes, and often longer.  The receiver has to download orbit
data from the satellites before it can fix a position, and that download runs at a fixed
slow rate whatever the sky is like.  Most reports of a dead GPS turn out to be a wait that
was cut short.

- **Open the Start menu and select GPS Status, then leave the PiFinder there.**  The screen
  turns the camera off to help the receiver, and shows **Lock boost on** while it does.
- **"Sats seen/used: 0/0" is not a progress bar.**  It sits at 0/0 for most of the wait and
  then climbs quickly near the end.
- **Don't turn the PiFinder off and on again to check.**  A restart throws away the partial
  download and starts over.  Repeated restarts can stop a lock arriving at all.
- **Get the receiver under open sky.**  It does not work indoors or under a roof.
- **Don't compare it with your phone.**  Phones use assisted GPS over the mobile network, so
  they lock in seconds.  That comparison says nothing about your PiFinder or your sky.

One setting can stop a lock outright.  On a v3 or v2.5 PiFinder running a freshly imaged
card, check the **GPS Baud Rate**.  The release image sets ``115200 (UBlox-10)``, which
suits the rev4 receiver.  The older receiver in these PiFinders needs ``9600 (standard)``.
At the wrong baud rate the GPS never locks, no matter how long you wait.

The :ref:`user_guide:status screen` shows this problem directly.  Its GPS MSG row names
the last message from the GPS receiver, with how long ago it arrived.  From the main menu,
select Tools, then Status, and scroll down to GPS MSG.  Watch it for a few seconds.  On a
healthy link the names change constantly and the age stays under a second.  Names that
start with ``?`` mean data is arriving that the PiFinder can't decode.  That is the sign
of a wrong baud rate.  To fix it, from the main menu select Settings, scroll down to
Advanced, select GPS Settings, then select GPS Baud Rate.

If you would rather not wait, enter your location and time by hand and start observing.  See
:ref:`user_guide:place & time`.  For what the lock types mean, see
:ref:`user_guide:getting a gps lock`.

.. note::
   Push-To and the Planets and Comets catalogs need a location and a time.  They do not
   need the GPS receiver to supply them.  Entering your location and time by hand works
   just as well as a lock.  With no lock and nothing entered by hand, Push-To shows
   **Searching for GPS** in place of directions, and the two catalogs stay empty.  The
   Focus and Align screens work either way, because neither depends on where or when you
   are.

An object has "disappeared" from a list (for example, M45)
----------------------------------------------------------

The PiFinder never deletes objects.  If something you expect is missing, an active **filter**
is hiding it.  The filters cover magnitude, altitude, type, observed status, and which
catalogs are selected.  To bring everything back, open the Filter menu and select
**Reset All**.  See :ref:`user_guide:filters` for what each filter does.

The chart or Push-To directions look backwards
----------------------------------------------

**Reversed Push-To directions are the classic sign that the PiFinder Type setting doesn't
match your hardware.**  You push the telescope the way the arrows point, and the object moves
further away instead of closer.  A mirrored star chart is the same fault showing itself
somewhere else.  One setting drives both.

On rev4, suspect this first.  The body rotates between the Left, Right and Straight positions
without tools, so it's easy to reposition the PiFinder for a different telescope and leave the
setting describing where the screen used to face.  Set it to match under Settings, as
described in :ref:`Configuration Setup <quick_start:configuration setup>`.

.. note::
   You can also configure the clockwise / counter-clockwise Push-To arrows to suit how you
   picture turning your telescope.  If only the left/right (azimuth) direction feels reversed,
   change that preference in Settings rather than the PiFinder Type.

"Is this normal?"
-----------------

A few PiFinder behaviours surprise people into thinking something is broken.  These are
all expected:

- **The alignment reticle isn't centred.**  The Telrad-style reticle on the Align screen shows
  where your telescope points *within* the camera's wide 10° view.  It is not meant to sit in
  the middle, and a reticle off to one side is normal.  See :ref:`quick_start:alignment`.
- **The star chart is "zenith up", not eyepiece-matched.**  The on-screen chart is a naked-eye
  view, oriented as you'd see the sky looking up, so it won't match the flipped or rotated
  view through your eyepiece.  The object *image* previews, by contrast, are rotated to match
  the eyepiece.
- **Push-To numbers dim while you move the telescope.**  While you move, the PiFinder
  estimates position from its motion sensor and dims the numbers to say so.  The instant you
  stop, it takes a fresh photo, the numbers brighten, and the position is exact again.  This
  is separate from the whole screen dimming in power-save mode.
- **The charging light is slow to turn green.**  Near a full charge the current tapers off, so
  the final stretch from blue to green takes a while.  That's normal, not a fault.

Frequently Asked Questions
--------------------------

**It's cloudy.  Can I still learn my way around?**
   Yes.  Test Mode solves a saved star image from disk and supplies a stand-in location, so
   the PiFinder behaves as though it is pointed at the sky.  You can explore the menus,
   catalogs, filters and Push-To indoors.  From the main menu, select Tools, then select Test
   Mode.  It stays on until you restart the PiFinder, and it blocks real observing while it
   runs, so restart before you go out.

**Do I still need a finder scope or Telrad?**
   Not for finding objects.  Once aligned to your telescope, the PiFinder replaces a
   traditional finder.  A zero-power finder, such as a red dot or a Telrad, is handy for the
   *initial* alignment, because that step asks you to put a bright star in your eyepiece to
   select it on the PiFinder's chart.

**Does it work in light-polluted skies?**
   Yes, very well.  Leave the exposure on **AUTO** and the PiFinder adapts it to the sky.  If
   you set it by hand, a longer 0.4 s helps pull stars out under heavy light pollution.  Good
   focus matters most of all here.

**How do I update the software?**
   Connect the PiFinder to a WiFi network with internet access (Client mode).  From the main
   menu, select Tools, then select Software Upd.  If the version reads "unknown", the PiFinder
   can't reach the internet to check.  That is a connectivity issue, not a reason to re-image.
   Full details are in :ref:`user_guide:update software`.
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

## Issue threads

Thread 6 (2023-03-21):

ENT+A turns screen off

rwillsuk, 2023-03-21:
Trying to bring up the other screens by pressing ENT+A and it will take me back to the preview screen. Press it again and the screen turns off. I have to cycle power to get it back on.

brickbots, 2023-03-21:
This sounds like a bug where the status screen crashes getting the IP address of the unit if the hostname is not exactly `pifinder`.... sorry about that oversight, it got me too when I renamed my unit so I could test two at once.  The beta branch has a fix for this, along with some a left-hand mount config option and related code changes.  These updates will be in the main branch shortly, but for now you can switch to the beta branch to see if this resolves your issue.

SSH into the PiFinder and type
```
cd PiFinder
git pull
git checkout beta
```
This should switch you to the beta branch.

brickbots, 2023-03-24:
I think I've finally tracked down the multiple sources of this status screen crash 🎉   Please update to release 1.2.3 for the latest fixes.

Thanks for reporting this and helping me to track down a couple (hopefully rare) crash conditions.

Closed 2023-03-24.

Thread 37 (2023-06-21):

Image/chart roll does not take into account mount angle

brickbots, 2023-06-21:
Roll is based on camera solved orientation, but the camera may have it's own roll depending on where on the scope it's mounted around the circumference

* Need to determine mount angle via IMU or config item
* Might need to be different/inverted for left/right hand mount config

Closed 2024-01-21.

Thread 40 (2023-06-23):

Add catalog descriptions when no object is selected

mrosseel, 2023-06-23:
When you're in the catalog view on 'NGC ----' there is only the text 'No object found'.
Here we would like to show some information on the current catalog instead, such as the full name, describing what's inside and a glossary of terms used in its descriptions.
When searching for objects and not finding them (e.g. 'NGC 9999') we should still show the 'No object found'.
Solved in #39

Closed 2023-07-14.

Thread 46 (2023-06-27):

Exception logged and  key not accepted on messier catalog screen

mikewagnercmp, 2023-06-27:
Fired up main, using python 3.10.12. navigated to web page, and clicked the "A" until the catalog screen was reached, then clicked the "C" button" until the messier catalog was selected. Then clicked "0" and then "3" when the web interface crashed and multiple exceptions were logged.

Expected result - Type in M031 , pull up the andromeda object.

 ➜  python cd pythonpython3 -m PiFinder.main -fh -k server --camera debug -x
[06/27/2023, 8:50:24.525 AM] starting main
[06/27/2023, 8:50:24.526 AM] 2023-06-27 08:50:24,525 root: DEBUG using debug camera
[06/27/2023, 8:50:24.616 AM] pygame 2.5.0 (SDL 2.28.0, Python 3.10.12)
[06/27/2023, 8:50:24.616 AM] Hello from the pygame community. https://www.pygame.org/contribute.html
[06/27/2023, 8:50:24.721 AM] Write: Starting....
[06/27/2023, 8:50:27.111 AM] Write:    GPS
[06/27/2023, 8:50:27.740 AM] Write:    Keyboard
[06/27/2023, 8:50:28.168 AM] Write:    Camera
[06/27/2023, 8:50:29.178 AM] Write:    IMU
[06/27/2023, 8:50:29.185 AM] Write:    Solver
[06/27/2023, 8:50:29.202 AM] Write:    Integrator
[06/27/2023, 8:50:29.219 AM] Write:    Server
[06/27/2023, 8:50:29.236 AM] Write:    Event Loop
[06/27/2023, 8:50:29.546 AM] 2023-06-27 08:50:29,545 root: DEBUG loading NGC
[06/27/2023, 8:50:29.604 AM] 2023-06-27 08:50:29,603 root: DEBUG loading IC
[06/27/2023, 8:50:29.624 AM] 2023-06-27 08:50:29,623 root: DEBUG loading M
[06/27/2023, 8:50:29.625 AM] 2023-06-27 08:50:29,625 root: DEBUG loading C
[06/27/2023, 8:50:29.627 AM] 2023-06-27 08:50:29,626 root: DEBUG loading Col
[06/27/2023, 8:50:29.629 AM] 2023-06-27 08:50:29,628 root: DEBUG loading SaA
[06/27/2023, 8:50:29.631 AM] 2023-06-27 08:50:29,629 root: DEBUG loading Ta2
[06/27/2023, 8:50:29.969 AM] 2023-06-27 08:50:29,969:tetra3.Tetra3-INFO: Loading database from: /Users/mikewagner/Projects/PiFinder-main 2/python/PiFinder/tetra3/default_database.npz
[06/27/2023, 8:50:55.253 AM] 2023-06-27 08:50:55,253 root: DEBUG Catalog>update_object_info(), self.cat_object=None, self.catalog_index=0, self._catalog_item_index=0
[06/27/2023, 8:50:55.254 AM] 2023-06-27 08:50:55,253 root: DEBUG after key_c, catalog index is 1
[06/27/2023, 8:50:59.630 AM] 2023-06-27 08:50:59,629 root: DEBUG Catalog>update_object_info(), self.cat_object=None, self.catalog_index=1, self._catalog_item_index=0
[06/27/2023, 8:50:59.630 AM] 2023-06-27 08:50:59,629 root: DEBUG after key_c, catalog index is 2
[06/27/2023, 8:51:02.150 AM] 2023-06-27 08:51:02,150 root: DEBUG Calling find by designator with:   M ---
[06/27/2023, 8:51:02.150 AM] 2023-06-27 08:51:02,150 root: DEBUG find by designartor, objectnumber is 0
[06/27/2023, 8:51:02.150 AM] 2023-06-27 08:51:02,150 root: DEBUG Catalog>update_object_info(), self.cat_object=None, self.catalog_index=2, self._catalog_item_index=0
[06/27/2023, 8:51:05.219 AM] 2023-06-27 08:51:05,218 root: DEBUG Calling find by designator with:   M --3
[06/27/2023, 8:51:05.219 AM] 2023-06-27 08:51:05,219 root: DEBUG  searching: c['sequence']=1type(c['sequence'])=<class 'int'>
[06/27/2023, 8:51:05.220 AM] 2023-06-27 08:51:05,219 root: DEBUG  searching: c['sequence']=2type(c['sequence'])=<class 'int'>
[06/27/2023, 8:51:05.220 AM] 2023-06-27 08:51:05,219 root: DEBUG  searching: c['sequence']=3type(c['sequence'])=<class 'int'>
[06/27/2023, 8:51:05.220 AM] 2023-06-27 08:51:05,219 root: DEBUG Found c['sequence']=3, at index 2
[06/27/2023, 8:51:05.220 AM] 2023-06-27 08:51:05,219 root: DEBUG Catalog>update_object_info(), self.cat_object={'catalog': 'M', 'sequence': 3, 'obj_type': 'Gb', 'ra': 205.55, 'dec': 28.383333333333333, 'const': 'CVn', 'l_size': ' ', 'size': 16.2, 'mag': 6.4, 'desc': '!!, glob. cl. , eB, vL, vsmbM, st 11...; = M3     \n'}, self.catalog_index=2, self._catalog_item_index=3
[06/27/2023, 8:51:05.350 AM] Process Process-7:
[06/27/2023, 8:51:05.350 AM] Process Process-4:
[06/27/2023, 8:51:05.350 AM] Process Process-6:
[06/27/2023, 8:51:05.350 AM] Traceback (most recent call last):
[06/27/2023, 8:51:05.350 AM]   File "/Users/mikewagner/.pyenv/versions/3.10.12/lib/python3.10/runpy.py", line 196, in _run_module_as_main
[06/27/2023, 8:51:05.351 AM]     return _run_code(code, main_globals, None,
[06/27/2023, 8:51:05.351 AM]   File "/Users/mikewagner/.pyenv/versions/3.10.12/lib/python3.10/runpy.py", line 86, in _run_code
[06/27/2023, 8:51:05.351 AM]     exec(code, run_globals)
[06/27/2023, 8:51:05.351 AM]   File "/Users/mikewagner/Projects/PiFinder-main 2/python/PiFinder/main.py", line 715, in <module>
[06/27/2023, 8:51:05.351 AM]     main(script_name)
[06/27/2023, 8:51:05.351 AM]   File "/Users/mikewagner/Projects/PiFinder-main 2/python/PiFinder/main.py", line 550, in main
[06/27/2023, 8:51:05.351 AM]     update_msg = current_module.update()
[06/27/2023, 8:51:05.351 AM]   File "/Users/mikewagner/Projects/PiFinder-main 2/python/PiFinder/ui/catalog.py", line 384, in update
[06/27/2023, 8:51:05.352 AM]     aka.draw((0, posy))
[06/27/2023, 8:51:05.352 AM]   File "/Users/mikewagner/Projects/PiFinder-main 2/python/PiFinder/ui/ui_utils.py", line 180, in draw
[06/27/2023, 8:51:05.352 AM] Traceback (most recent call last):
[06/27/2023, 8:51:05.352 AM] Traceback (most recent call last):
[06/27/2023, 8:51:05.352 AM]   File "/Users/mikewagner/.pyenv/versions/3.10.12/lib/python3.10/multiprocessing/process.py", line 314, in _bootstrap
[06/27/2023, 8:51:05.352 AM]     self.run()
[06/27/2023, 8:51:05.352 AM] Traceback (most recent call last):
[06/27/2023, 8:51:05.352 AM]   File "/Users/mikewagner/.pyenv/versions/3.10.12/lib/python3.10/multiprocessing/process.py", line 108, in run
[06/27/2023, 8:51:05.352 AM]     self._target(*self._args, **self._kwargs)
[06/27/2023, 8:51:05.352 AM]   File "/Users/mikewagner/Projects/PiFinder-main 2/python/PiFinder/integrator.py", line 147, in integrator
[06/27/2023, 8:51:05.352 AM]     location = shared_state.location()
[06/27/2023, 8:51:05.352 AM]   File "<string>", line 2, in location
[06/27/2023, 8:51:05.352 AM]   File "/Users/mikewagner/.pyenv/versions/3.10.12/lib/python3.10/multiprocessing/managers.py", line 818, in _callmethod
[06/27/2023, 8:51:05.352 AM]     kind, result = conn.recv()
[06/27/2023, 8:51:05.352 AM]   File "/Users/mikewagner/.pyenv/versions/3.10.12/lib/python3.10/multiprocessing/connection.py", line 250, in recv
[06/27/2023, 8:51:05.352 AM]     buf = self._recv_bytes()
[06/27/2023, 8:51:05.352 AM]   File "/Users/mikewagner/.pyenv/versions/3.10.12/lib/python3.10/multiprocessing/connection.py", line 414, in _recv_bytes
[06/27/2023, 8:51:05.352 AM]     buf = self._recv(4)
[06/27/2023, 8:51:05.352 AM]   File "/Users/mikewagner/.pyenv/versions/3.10.12/lib/python3.10/multiprocessing/connection.py", line 383, in _recv
[06/27/2023, 8:51:05.352 AM]     raise EOFError
[06/27/2023, 8:51:05.352 AM]   File "/Users/mikewagner/.pyenv/versions/3.10.12/lib/python3.10/multiprocessing/process.py", line 314, in _bootstrap
[06/27/2023, 8:51:05.352 AM]     self.run()
[06/27/2023, 8:51:05.352 AM]   File "/Users/mikewagner/.pyenv/versions/3.10.12/lib/python3.10/multiprocessing/process.py", line 108, in run
[06/27/2023, 8:51:05.352 AM]     self._target(*self._args, **self._kwargs)
[06/27/2023, 8:51:05.352 AM]   File "/Users/mikewagner/Projects/PiFinder-main 2/python/PiFinder/camera_debug.py", line 62, in get_images
[06/27/2023, 8:51:05.352 AM]     camera_hardware.get_image_loop(
[06/27/2023, 8:51:05.352 AM]   File "/Users/mikewagner/.pyenv/versions/3.10.12/lib/python3.10/multiprocessing/process.py", line 314, in _bootstrap
[06/27/2023, 8:51:05.352 AM]     self.run()
[06/27/2023, 8:51:05.352 AM]   File "/Users/mikewagner/.pyenv/versions/3.10.12/lib/python3.10/multiprocessing/process.py", line 108, in run
[06/27/2023, 8:51:05.352 AM]     self._target(*self._args, **self._kwargs)
[06/27/2023, 8:51:05.352 AM]   File "/Users/mikewagner/Projects/PiFinder-main 2/python/PiFinder/solver.py", line 51, in solver
[06/27/2023, 8:51:05.352 AM]     imu = shared_state.imu()
[06/27/2023, 8:51:05.352 AM]   File "<string>", line 2, in imu
[06/27/2023, 8:51:05.352 AM]   File "/Users/mikewagner/.pyenv/versions/3.10.12/lib/python3.10/multiprocessing/managers.py", line 818, in _callmethod
[06/27/2023, 8:51:05.352 AM]     kind, result = conn.recv()
[06/27/2023, 8:51:05.352 AM]   File "/Users/mikewagner/.pyenv/versions/3.10.12/lib/python3.10/multiprocessing/connection.py", line 250, in recv
[06/27/2023, 8:51:05.352 AM]     buf = self._recv_bytes()
[06/27/2023, 8:51:05.352 AM]   File "/Users/mikewagner/.pyenv/versions/3.10.12/lib/python3.10/multiprocessing/connection.py", line 414, in _recv_bytes
[06/27/2023, 8:51:05.352 AM]     buf = self._recv(4)
[06/27/2023, 8:51:05.353 AM]   File "/Users/mikewagner/.pyenv/versions/3.10.12/lib/python3.10/multiprocessing/connection.py", line 383, in _recv
[06/27/2023, 8:51:05.353 AM]     raise EOFError
[06/27/2023, 8:51:05.353 AM] EOFError
[06/27/2023, 8:51:05.353 AM]   File "/Users/mikewagner/Projects/PiFinder-main 2/python/PiFinder/camera_interface.py", line 82, in get_image_loop
[06/27/2023, 8:51:05.353 AM]     imu = shared_state.imu()
[06/27/2023, 8:51:05.353 AM] EOFError
[06/27/2023, 8:51:05.353 AM]   File "<string>", line 2, in imu
[06/27/2023, 8:51:05.353 AM]   File "/Users/mikewagner/.pyenv/versions/3.10.12/lib/python3.10/multiprocessing/managers.py", line 818, in _callmethod
[06/27/2023, 8:51:05.353 AM]     kind, result = conn.recv()
[06/27/2023, 8:51:05.353 AM]   File "/Users/mikewagner/.pyenv/versions/3.10.12/lib/python3.10/multiprocessing/connection.py", line 250, in recv
[06/27/2023, 8:51:05.353 AM]     buf = self._recv_bytes()
[06/27/2023, 8:51:05.353 AM]   File "/Users/mikewagner/.pyenv/versions/3.10.12/lib/python3.10/multiprocessing/connection.py", line 414, in _recv_bytes
[06/27/2023, 8:51:05.353 AM]     buf = self._recv(4)
[06/27/2023, 8:51:05.353 AM]   File "/Users/mikewagner/.pyenv/versions/3.10.12/lib/python3.10/multiprocessing/connection.py", line 383, in _recv
[06/27/2023, 8:51:05.353 AM]     raise EOFError
[06/27/2023, 8:51:05.353 AM] EOFError
[06/27/2023, 8:51:05.353 AM]     self.layout(pos)
[06/27/2023, 8:51:05.353 AM]   File "/Users/mikewagner/Projects/PiFinder-main 2/python/PiFinder/ui/ui_utils.py", line 222, in layout
[06/27/2023, 8:51:05.353 AM]     f"Layouting {self.text=}, {self.textlen=}, {self.pointer=}, {self.counter=}, {self.scrollspeed=}"
[06/27/2023, 8:51:05.353 AM] AttributeError: 'TextLayouterScroll' object has no attribute 'counter'. Did you mean: 'pointer'?
[06/27/2023, 8:51:05.577 AM] Traceback (most recent call last):
[06/27/2023, 8:51:05.577 AM]   File "/Users/mikewagner/.pyenv/versions/3.10.12/lib/python3.10/site-packages/bottle.py", line 876, in _handle
[06/27/2023, 8:51:05.577 AM]     return route.call(**args)
[06/27/2023, 8:51:05.577 AM]   File "/Users/mikewagner/.pyenv/versions/3.10.12/lib/python3.10/site-packages/bottle.py", line 1759, in wrapper
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
mikewagnercmp, 2023-06-27:
Edit to add - based on my snooping with a web proxy, I see the command for key "0" being made with a return of success, but the UI image returned does not up date to reflect it - I was trying to type the leading zero for M031
then when i typed the 3 it caused the crash. the 3 was also acknowledged by the API with a success.

mrosseel, 2023-06-27:
this seems to be the error:
```
[06/27/2023, 8:51:05.353 AM] File "/Users/mikewagner/Projects/PiFinder-main 2/python/PiFinder/ui/ui_utils.py", line 222, in layout
[06/27/2023, 8:51:05.353 AM] f"Layouting {self.text=}, {self.textlen=}, {self.pointer=}, {self.counter=}, {self.scrollspeed=}"
[06/27/2023, 8:51:05.353 AM] AttributeError: 'TextLayouterScroll' object has no attribute 'counter'. Did you mean: 'pointer'?
```

mrosseel, 2023-06-27:
solved in #48

mrosseel, 2023-06-27:
this was some merge error from the PR's to main - if you take a look at the error you can apply the fix locally as well, it's short

mikewagnercmp, 2023-06-27:
That did it thanks!

Closed 2023-06-27.

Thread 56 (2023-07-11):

Feature Request: Swap out IMU BNO055 with BNO085

steamraven, 2023-07-11:
Adafruit is now selling the BNO085 with the exact same footprint.  In fact, it is the same hardware, just a different firmware.  The firmware is supposed to be a whole lot more accurate.

https://www.adafruit.com/product/4754

brickbots, 2023-07-11:
Hi Steamraven!

Thanks for submitting this issue.  I compared the two units when I was doing the initial R&D for the PiFinder and found it to be... less impressive than the description would make it seem.  It does offer some interesting higher-level classification stuff (like tap/shake/step recognition), but the overall stability of the fused quaternions was similar or worse than the vanilla unit in my, admittedly,  limited testing and the extra high-level classification didn't seem useful for the PiFinder.

It is a couple bucks cheaper, which is certainly nice... but the vanilla unit seemed to be available in larger quantities...so I went with that one.  If someone has time to do more thorough testing to see if it really is more accurate, I'd be willing to support both (have to support legacy hardware), but I'm hesitant to add more lines of code to account for the differences in the two units unless there is a compelling case.

The most interesting potential bit for PiFinder use , the UART UVC, has some specific assumptions about the types of motion likely to be experience as it's fine tuned for robotic navigation so fails to properly read altitude angles changes past a point :-/

steamraven, 2023-07-13:
Thanks for the detailed explanation.  I only really mentioned it, because I have seen a lot of posts complaining about the BNO055 loosing precision fast, but that is probably not a problem for the PiFinder, as the plate-solver can re-acquire position.

I love this project, and thank you for all your hard work on it

Closed 2023-07-13.

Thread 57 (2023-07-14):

Use fonts with icons

mrosseel, 2023-07-14:
So we can use icons for GPS, camera, ...

https://www.nerdfonts.com/

mrosseel, 2023-08-13:
the font we currently use is also present within nerdfonts, so I'll use that one.
Switching to another font is either not necessary or not for this issue.

mrosseel, 2023-09-21:
solved by #90

Closed 2023-09-21.

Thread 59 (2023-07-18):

OLED screen should have a screensaver

mrosseel, 2023-07-18:
Currently, after a short period of time the screen dims, which is a nice feature.
It could be useful for the screen to go off after a longer period, say 15 mins. Say you are away from your telescope or you are developing on the unit. The screen should re-awake with a button-touch. TBD if leds should stay on, probably yes to indicate the unit is still alive.

related to #51

mrosseel, 2023-09-21:
solved by #92

Closed 2023-09-21.

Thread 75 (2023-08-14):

Using the push nearest function before first solve crashes UI

brickbots, 2023-08-14:
Kiwi72 reported:

[I selected] 5 Push All in Catalog options screen when running on the table inside so obviously no solves and it just blanked the screen or shutdown, hard to tell what happened as I couldn't get the screen back up no matter what buttons or combination I pushed

mrosseel, 2023-08-14:
which version?

brickbots, 2023-08-14:
Kiwi72 said they updated after the 1.6.2 release, so I'm assuming 1.6.... but I'm asking just to double check!

brickbots, 2023-08-14:
Yes, confirmed it was with release 1.6.2!

mrosseel, 2023-08-16:
solved for main branch in #77

mrosseel, 2023-08-16:
should this be backported to release?

brickbots, 2023-08-17:
I think it's sort of edge-case-y, so it can wait until next release?  Let me know if you feel differently and I'll back-port it or do another point release 👍

mrosseel, 2023-08-23:
also backported to release with #78

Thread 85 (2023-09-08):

Star identification fails with bright stars

mrosseel, 2023-09-08:
On main the camera preview can now detect stars and align on them, but it fails to detect bright stars or, as in this case, Jupiter.
Here  is the solver_debug_dump acquired with ENT+D

[c56a5c9e.zip](https://github.com/brickbots/PiFinder/files/12554459/c56a5c9e.zip)

brickbots, 2023-09-08:
Thank you @mrosseel for the debug info!  I've tried a few different tetra3 star extraction params and I think I've found a set that works well on the example images, is not too slow, and hopefully will be a bit more stable from frame to frame.

Please try the `snap_fixes` branch and let me know what you think 👍

brickbots, 2023-09-19:
I tested this quite a bit over the last week and I think it's solved.  I'm going to update the snap_fixes branch and get a PR going

Closed 2023-09-19.

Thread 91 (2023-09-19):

Add Barnard dark nebula catalog

brickbots, 2023-09-19:
http://cdsarc.u-strasbg.fr/viz-bin/Cat?VII/220A

mrosseel, 2023-09-19:
already mentioned in #27 but ok to track it seperately here.
I'm not adding any more catalogs atm because I feel that pretty soon we'll need a better catalog selection mechanism.
Another option is to disable some of the less used ones to keep it manageable, and later allow this to be configured via the menu - this way we can postpone the catalog selection rewrite for some time

brickbots, 2023-09-19:
D'Oh! Sorry, I missed that it was already included in #27 I'll close this one.  Agreed that the catalog volume is getting large.  The simple fix that you suggested, an option to 'exclude' some catalogs from the rotation should be easy to implement with the current menu system and will do the job for a while :+1:

Closed 2023-09-19.

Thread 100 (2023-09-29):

Allow usernames other than 'pifinder'

hovissimo, 2023-09-29:
The install script hard-codes some paths for the `pifinder` username.

There is a conversation in Discord here: https://discord.com/channels/1087556380724052059/1087556507933089874/1157420010860445737

hovissimo, 2023-09-29:
It seems that I can't add a branch to open a PR, but here's the commit I would submit for this issue.

```
Author: Hovis <github@bunkercode.com>
Date:   Fri Sep 29 14:15:58 2023 -0700

    Use $HOME in pifinder_setup.sh

    This abstracts the username and prevents errors when users pick a
    username when using the Raspberry Pi imager.

    Resolves #100

diff --git a/pifinder_setup.sh b/pifinder_setup.sh
index a693a56..cb14fe2 100644
--- a/pifinder_setup.sh
+++ b/pifinder_setup.sh
@@ -6,27 +6,27 @@ cd PiFinder
 sudo pip install -r requirements.txt

 # data dirs
-mkdir ~/PiFinder_data
-mkdir ~/PiFinder_data/captures
-mkdir ~/PiFinder_data/obslists
-mkdir ~/PiFinder_data/screenshots
-mkdir ~/PiFinder_data/solver_debug_dumps
-mkdir ~/PiFinder_data/logs
-chmod -R 777 ~/PiFinder_data
+mkdir $HOME/PiFinder_data
+mkdir $HOME/PiFinder_data/captures
+mkdir $HOME/PiFinder_data/obslists
+mkdir $HOME/PiFinder_data/screenshots
+mkdir $HOME/PiFinder_data/solver_debug_dumps
+mkdir $HOME/PiFinder_data/logs
+chmod -R 777 $HOME/PiFinder_data

 # Wifi config
-sudo cp ~/PiFinder/pi_config_files/dhcpcd.* /etc
-sudo cp ~/PiFinder/pi_config_files/dhcpcd.conf.sta /etc/dhcpcd.conf
-sudo cp ~/PiFinder/pi_config_files/dnsmasq.conf /etc/dnsmasq.conf
-sudo cp ~/PiFinder/pi_config_files/hostapd.conf /etc/hostapd/hostapd.conf
-echo -n "Cli" > ~/PiFinder/wifi_status.txt
+sudo cp $HOME/PiFinder/pi_config_files/dhcpcd.* /etc
+sudo cp $HOME/PiFinder/pi_config_files/dhcpcd.conf.sta /etc/dhcpcd.conf
+sudo cp $HOME/PiFinder/pi_config_files/dnsmasq.conf /etc/dnsmasq.conf
+sudo cp $HOME/PiFinder/pi_config_files/hostapd.conf /etc/hostapd/hostapd.conf
+echo -n "Cli" > $HOME/PiFinder/wifi_status.txt
 sudo systemctl unmask hostapd

 # Samba config
-sudo cp ~/PiFinder/pi_config_files/smb.conf /etc/samba/smb.conf
+sudo cp $HOME/PiFinder/pi_config_files/smb.conf /etc/samba/smb.conf

 # Hipparcos catalog
-wget -O /home/pifinder/PiFinder/astro_data/hip_main.dat https://cdsarc.cds.unistra.fr/ftp/cats/I/239/hip_main.dat
+wget -O $HOME/PiFinder/astro_data/hip_main.dat https://cdsarc.cds.unistra.fr/ftp/cats/I/239/hip_main.dat

 # Enable interfaces
 echo "dtparam=spi=on" | sudo tee -a /boot/config.txt
@@ -35,7 +35,7 @@ echo "dtparam=i2c_arm_baudrate=10000" | sudo tee -a /boot/config.txt
 echo "dtoverlay=pwm,pin=13,func=4" | sudo tee -a /boot/config.txt

 # Enable service
-sudo cp /home/pifinder/PiFinder/pifinder.service /etc/systemd/system/pifinder.service
+sudo cp $HOME/PiFinder/pifinder.service /etc/systemd/system/pifinder.service
 sudo systemctl daemon-reload
 sudo systemctl enable pifinder```

brickbots, 2024-01-21:
Closing in prep for new deployment/update system in Bookworm release

Closed 2024-01-21.

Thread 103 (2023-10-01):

catalog related assertion crash in main

mrosseel, 2023-10-01:
crash found by running random2 script:

```
Traceback (most recent call last):
  File "/opt/homebrew/Caskroom/miniconda/base/lib/python3.10/runpy.py", line 196, in _run_module_as_main
    return _run_code(code, main_globals, None,
  File "/opt/homebrew/Caskroom/miniconda/base/lib/python3.10/runpy.py", line 86, in _run_code
    exec(code, run_globals)
  File "/Users/mike/dev/amateur_astro/myPiFinder/python/PiFinder/main.py", line 816, in <module>
    main(args.script, args.server, args.fps)
  File "/Users/mike/dev/amateur_astro/myPiFinder/python/PiFinder/main.py", line 598, in main
    current_module.active()
  File "/Users/mike/dev/amateur_astro/myPiFinder/python/PiFinder/ui/catalog.py", line 330, in active
    self.catalog_tracker.set_current_object(
  File "/Users/mike/dev/amateur_astro/myPiFinder/python/PiFinder/catalogs.py", line 402, in set_current_object
    self.set_current_catalog(catalog_name)
  File "/Users/mike/dev/amateur_astro/myPiFinder/python/PiFinder/catalogs.py", line 332, in set_current_catalog
    assert catalog_name in self.catalogs, f"{catalog_name} not in {self.catalogs}"
AssertionError: SaM not in {'IC': catalog repr, 'M': catalog repr, 'Str': catalog repr, 'Col': catalog repr, 'Her': catalog repr, 'Ta2': catalog repr, 'SaA': catalog repr}
ERROR:root:EOFError in Camera Loop
```

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

brickbots, 2023-10-03:
Replicated and fixed!  If you de-activated the catalog for the currently selected/targeted object, it would crash

Closed 2023-10-03.

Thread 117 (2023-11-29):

Chart rotation potentially incorrect very near celestial poles

brickbots, 2023-11-29:
When aligned on a pixel off-center from the camera image, the chart rotation appears incorrect when the celestial pole is between the geometric center of the camera image and the target pixel.

Tetra3 returns roll based on the geometric center, not the target pixel.  According to Gustav this would be tricky to implement.

A potential solution is to render the chart based on the geometric center of the camera image (raw solution values + roll) then offset  this render by the target pixel values to align it with the target pixel before copying it to the screen and adding the reticle.  This would ultimately center the chart on the target pixel, but provide a more stable rotation reference.

TakKanekoGit, 2024-07-09:
@brickbots -- I will try to pick this issue up in step 2 of the "Roll Issue Fix".

As I understand from your comments above, the roll measured by plate solving is only valid at the centre of the camera FoV. The difference between the roll at the camera centre and the target pixel becomes bigger higher declinations. If we want to use the roll as a measurement, as proposed for later enhancements, I think we need to fix this?

Here's how I propose to fix it:

1. Take the (ra_camera, dec_camera, roll_camera) from plate solving. Compare the measured roll against the roll calculated at (ra_camera, dec_camera) against the measured roll_camera to get the roll_offset. This should be reasonably constant for an Alt/Az mount.
2. Work out the (ra_scope, dec_scope) at the target pixel as done currently. Calculate the roll at the target and add the roll_offset. This should give the correct roll as seen by the scope.

Do you think this will work or is there more to the problem?

Closed 2025-02-24.

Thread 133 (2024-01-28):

Get SQM estimate from camera image

mrosseel, 2024-01-28:
do you have any ideas on estimating SQM from the camera image? Would be great to be able to show this to the user and log it in the observations.

Found this: [pbase](https://www.pbase.com/samirkharusi/image/37608572&exif=Y)
and also this:
[stargazers lounge page 1](https://stargazerslounge.com/topic/370621-sqm-sky-background-measurement-using-an-image-and-the-astap-program/)
and also this, seems pretty straightforward once an image is platesolved
[stargazers lounge page 2](https://stargazerslounge.com/topic/370621-sqm-sky-background-measurement-using-an-image-and-the-astap-program/page/2/)

brickbots, 2024-02-20:
I very much like the approach of using a plate solved image.  It seems to cut down on the variables quite a bit and does not require a dark frame to be taken :-)

If this is fast enough to do, it can be done for every solve... but I expect we may want to be more judicious... perhaps with a keypress on the camera screen?

mrosseel, 2024-02-20:
Depending on how fast we can get it to be it can be done always, every x minutes or on-demand like when logging an observation.

If I understand page 2 correctly it's just this:

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

So we need to know the Pixel sum of a detected star in the field (or many stars), the pixel sum of the entire field and the magnitudes of the detected stars. Probably also some indication of the star annulus if we need to calculate the pixel sum ourselves.

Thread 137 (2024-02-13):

Get GPS coords from phone browser

mrosseel, 2024-02-13:
The implementation of this is ready, but needs the website to be served over HTTPS.

@HeyApos said:
would it be possible to also take the GPS location of the handy, if using the browser based GUI to transfer to the pifinder? This is not a big deal with google geolocation API (http://dev.w3.org/geo/api/spec-source.html). There are a lot of devices, that can do this (e.g. the OnStep program WebGui, Stellarmate, https://artyom-beilis.github.io/astrohopper.html ,...) I find a hole bunch of ready to use code for this: https://www.google.com/search?q=browser+program+get+gps+from+handy
A "one click button" on the main page for setting time/location would be great. So the GPS dongle would be more or less totally optional.

local cert using letsencrypt:
https://thriveread.com/ssl-localhost-certificate-for-https-local-domain/

apos, 2024-02-14:
Hi Mike, thanks a lot. This is Axel / HeyApos (Discord) from Germany/Ludwigshafen :-)

apos, 2024-03-17:
The problem which most users will have, that they have to manually deploy the self-signed local domain SSL certificate to their browser to use it (step 9 / 10). This is for 127.0.0.1 (localhost). If the local domain is other than localhost, here pifinder.local it has to be publically avaiable (chapter "Let’s Encrypt SSL Certificate for Local Domain (Not Localhost)"), which is not the case for us, as far as I understand.

jscheidtmann, 2024-08-09:
Reading up on this, I believe there's no easy solution to managing an SSL certificate. The most promising scenario (courtesy ChatGPT) would be this:

 - create an application, that is locally installed on the  users mobile phone.
 - This app get's the user's permission to access the geolocation info and
 - once it detects that "pifinder.local" is present, sends a request to the PiFinder's server initializing PiFinder's location
 - e.g. upon activation of the app

Big drawback is the effort to set this up for both Android and iOS, though...

jscheidtmann, 2024-08-09:
Assuming
 - we can get an accurate time fix from a connected phone (didn't look into that), and
 - that the telescope is level so that the IMU reported angle is the angle between an object and the horizon
one can use [celestial navigation](https://en.wikipedia.org/wiki/Celestial_navigation) to estimate the position.

We would have to check to what precision we a) need the position and b) what precision angle measurements need to have to give a "good enough" position:

You'd move around the telescope to different parts of the sky, platesolving the sky position and measuring the horizont angle of stars using the IMU and then estimate the position from this data.

Relevant python packages are [pyalmanac](https://pypi.org/project/pyalmanac/) and [Capella](https://pypi.org/project/Capella/). The latter offers an UI where you can plug in measurements and it calculates your position.

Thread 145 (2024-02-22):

Support for LX200 align command

brickbots, 2024-02-22:
In our current implementation this function in SkySafari or other LX200 control apps acts like a go-to command and starts a push-to cycle on the PiFinder.

For some use cases where the telescope pointing position is far outside the camera FOV, this could server as an alternate alignment method.  It should cause the PiFinder to store the offset between the provided RA/DEC and current solution and apply this to future solutions.

Some notes:
* The provided RA/DEC would need to be converted to a sort of camera space offsets as the actual pointing offset will be in the the 2d camera plane (like the current bright star alignment)
* There is likely some point where this offset will be too great to reliably provide telescope pointing position.  Maybe we need a warning for this?

mrosseel, 2024-05-14:
how would you propose to do the push-to if the align command can't be used?
I would prefer to do the align on the pifinder itself.
If both are possible that's of course the best solution.

brickbots, 2024-05-14:
I see this as an alternative to the built in bright star alignment and potential object alignment.  Basically just another way to tell the PiFinder 'Hey the telescope is pointed here!'

mrosseel, 2024-05-14:
That would be fine, my question is how will you replace the push-to feature which is now using the align command?

brickbots, 2024-05-14:
Not sure how it's implemented behind the scenes, but in SkySafari there are two buttons, one for Align and one for GoTo (see image).   We currently do the same thing on both buttons, but I suspect SkySafari is sending different commands for align and GoTo, but I'm not sure.

The user requested that we use the Align button to do sort of what it does on the LX200, which is to snap the telescope reticle on to the selected item.  Similar to our current Bright Star Alignment.

This might not be a useful enough feature to implement, especially if we implement object alignment ourselves.

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

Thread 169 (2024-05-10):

Rework catalog filtering to include observation status

brickbots, 2024-05-10:
* Verify that Observation Status is used for filtering everywhere
* Make sure observations from the current session are included in filtering

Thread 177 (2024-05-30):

Add an adapter for Rigel Quikfinder base

jscheidtmann, 2024-05-30:
I am going to add an adapter for a Rigel Quikfinder base:

 * create directories case/adapters/quikfinder
 * change case/README.md
 * reflect this change in documentation under "Mounting".

Shortcoming of this adapter: One cannot orient the PiFinder perpendicular to the ground, as recommended.

Looks like this:
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

brickbots, 2024-05-30:
This is a great idea/addition.  What software are you using to model this in?  Perhaps we can merge the pivot portion of the existing foot with this connector?

jscheidtmann, 2024-05-30:
I used OnShape, free version. I believe you're using Fusion360?

jscheidtmann, 2024-06-01:
Here‘s the first construction:
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

Idea is to to be compatible to the dovetail top. Will print it tomorrow, to check dimensions.

Closed 2024-06-02.

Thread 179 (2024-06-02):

More secure WiFi setup

jscheidtmann, 2024-06-02:
As I am going to go to a star party in September, I was wondering how to give PiFinder a better default security posture:

First, the documentation should recommend to attach an Ethernet cable during the build phase to setup local WiFi client access. This avoids entering WiFi passwords over unencrypted channels, as the documentation currently recommends.

Second, if the unit activates access point mode, it should:
-  attach a random number (5 decimal places from 00000-99999) to the SSID, such that PiFinders in the vicinity use different SSIDs (at least a collision is rather unlikely),
- At least WPA2 should be configured on the WiFi, using a random password of 15 or 20 places consisting of characters a-z0-9, in groups of 5.
- This password should be displayed after boot up and be part of the "main" screens, i.e. it must be accessible from pressing "A" multiple times (screen can be deactivated in settings)
- This configuration shall be created once and be stored and reused by each boot up,
- until a new configuration is generated by the user in settings.

What do you think?

dnlombard, 2024-06-02:
Yes, /recommend/ Ethernet. There could be much more to it.

Hotspots typically display SSID & PW either on the home screen or from 1
button press. The former is nicer when the screen will blank after a
timeout.

WPA2 is fine.

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

--
dnl

brickbots, 2024-06-02:
Thanks @jscheidtmann for thinking about this and for your passion about security!   I'm on-board with all of your thoughts, except the suggestion of using an ethernet cable.  It seems if your other suggestions were implemented, the need for this would be removed, but I may be missing something.

I have some hints/suggestions for anyone who wants to take this change on, but in the meantime, here are a couple things which can help anyone who is using a PiFinder at a public event:

* The access point name can be changed, and this is probably a good idea to prevent your PiFinder from conflicting with another.   **In a quick PR the documentation can be updated to encourage this** :+1:
*  The user account/Web Interface password can and should be changed.  **Again, a quick PR can adjust the documentation to encourage this.**

These two steps will discourage/prevent any accidental and general mischief.  A determined attacker can still do packet collections and such, but the cost/benefit for this attack would be pretty low as there is not much value to a compromised PiFinder.

**A quick/easy software change could enable manual mitigation of the remaining risks:  Allow the setting of a WPA password on the Access Point network via the web interface.**  Yes, initial configuration is done in the clear, but the chance of an attacker being in the right place at the right time to take advantage of this is, seemingly, quite small.

BUT, better is better and your suggestions are very good ones that should not negatively impact the usability very much.  For anyone who wanted to take a run at implementing some of these, here are some thoughts:

1)  The current PiFinder image is based on an older version of Raspberry Pi OS (Bullseye).  There is a branch where work has been started to port the software to Bookworm. I mention this as the network subsystems have changed significantly between the two so making these changes on Bullseye will require some re-implementation on Bookworm.  Might be worth targeting the Bookworm branch and helping to accelerate the transition there.

2)  There is not any mechanism or hook currently for 'first time boot-up' which could be used for generating the random AP network config.  This would be pretty useful though and there are probably a couple of ways to set this up so that it runs on first boot along with the SD Card volume expansion 🤔

jscheidtmann, 2025-04-04:
On bullseye, having had a look at `hostapd`, this seems quite easy to implement, all one needs to do is add the following lines to hostapd.conf:

```
wpa=2
wpa_key_mgmt=WPA-PSK
wpa_passphrase=<passphrase>
rsn_pairwise=CCMP
```

It turns out, that the more involved seems to be the WiFi country. To make that work, you need to run in addition:

```
sudo raspi-config nonint do_wifi_country <ISO 2-letter country code>
```

It might then in addition be necessary to also configure some channels and wifi modes, to be recognized by other devices in that country.

I‘ll work on a pull request next.

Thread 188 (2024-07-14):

"Searching for GPS..." on locate screen does not disappear when GPS manually entered.

tranquilaxolotl, 2024-07-14:
Software Version: 1.11.2
Alt-Az Mode
PiFinder in Flat Configuration.

When manually entered GPS position through website LOCATE screen still shows "Searching for GPS...."
When proper GPS lock is established it seems problem goes away.

After manually entering GPS coordinates, GPS indicator on top of the screen stops flashing,

This problem limits PiFinder as being useful for Grab&Go, I observe from deck and area is obstructed by building/trees  resulting in very long wait times for GPS lock (sometimes up to 30minutes)

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

cdSheriff, 2024-07-15:
Able to duplicate bug in a different form, driven through PiFinder w/out webpage interface and driven through SkySafari. here are the SW/HW details:
- Rpi 4
- PiSugar S Plus
- 1.11.2 built fresh from release .img
- reproduced on both AP and client wifi modes
- tested in open space without obstructions, GPS antenna pointed at least 40deg above horizon up to straight up

Method to reproduce:
- Startup PiFinder in Alt/Az mode
- Wait for GPS lock symbol on top right of UI
- Move to _catalog_ screen, select object
- _Locate_ screen says "**searching for GPS**"
- _Status_ screen shows minimum 5 satellites and lat/lon coords. Seen both before and after selecting catalog item to locate
- also reproduced when sending GOTO from SkySafari Pro

Method to fix:
- Change PiFinder to EQ mode. EQ mode does not show this bug and _Locate_ screen works normally

Notes:
- Persistent through software driven resets (changing config values) and software driven shutdown. Also persistent through power down (PiSugar switch), have not tested with battery removal

Will reproduce soon to get debugging images (logs if possible) and attach here

brickbots, 2024-07-15:
Hello @tranquilaxolotl, thank you for the bug report with screen shots.  I'm hoping you can help me out by providing answering a couple of questions.

I've tried a couple of times and have not been able to replicate this issue, but I did notice that the camera icon in the upper-right of the screen shot you sent is missing.
* Was the PiFinder properly solving at that point?

On one attempt to replicate this issue, the PiFinder had gone into low-power mode while I was entering the information from the GPS in the web interface, and the 'Waiting for GPS' message did not actually go away until I moved the PiFinder to wake it from the low-power state.
* If you are able to replicate this issue, would you please try moving the PiFinder or pressing a physical key to make the screen/keypad brighten and see if that potentially solves the issue?

Thank you so much, I'm keen to understand and fix this issue!

brickbots, 2024-07-15:
@cdSheriff and @tranquilaxolotl One other thing to check, please, is the time displayed on the Status screen.  The GPS lock is a combination of lat/long/time and it would be great to know what all three of these components are 👍

tranquilaxolotl, 2024-07-16:
@brickbots , I took it out and was able to re-produce the bug, although it was cloudy, so got just few solves.

I also tested it on version 1.10 one before the "Waiting for GPS" addon, and it had the same behavior.

I have also did same in the basement, so I did not get a proper plate solve, and screen was showing "Waiting for solve",

Here is how I replicated the bug:

1. Unplug GPS antenna to make sure GPS signal will not show up.
2. Power up - AltAz Mode, Flat.
3. Search for nearby object, and I got "Searching for GPS"
4. set GPS coordinates, and time using browser
5. verify if GPS/Time was correct in status screen, seemed ok.
6. Search for nearby object, and I got "Searching for GPS"
7. I pressed several buttons multiple times to make sure that it is not in sleep mode.

Camera in the upper right showed for a short while, but after few seconds disappeared (too cloudy)

Let me know if you need any more info.

bellow screenshots that I took:
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

brickbots, 2024-07-19:
Hi @tranquilaxolotl !  Thank you so much for the additional info and for the very helpful photos :+1:  I've taken a look through this and the code and I *think* I know what's going on.... at least I've been able to replicate it under the conditions below.

The GPS status on the Locate screen is only checked with each new plate solve, and it seems like there has not been a new plate solve since the location/time has been set via the web interface.  There could be a deeper issue here, but based on the images you sent, it seems like this is what is going on if this tracks with your experience.  If you have seen this same issue while the PiFinder is solving, let me know and I can keep looking and trying to replicate this.

I'll put this on the todo list, but this generally should not be an issue when actually using the PiFinder for observing as a plate solve should be coming in every second or more frequently.  Has this issue caused you problems under actual observing conditions?

tranquilaxolotl, 2024-07-19:
I'm usually observing very short sessions 10-20 minutes maximum, so when I took scope out it showed me waiting for GPS all the time while I was trying to see something. I will do some more testing to see how it behaves when plate solves are coming in.
 I'll be out of town for 2 weeks, so will not have much time to use PiFinder, Once I'm back I'll get back to testing

brickbots, 2024-07-19:
Thank you so much!  I look forward to hearing about your results.
Have a good trip 👍

AstroScot66, 2024-08-09:
I have the same issue. I purchased the PiFinder fully built.
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

tranquilaxolotl, 2024-08-10:
I did test it again today. Tried several times, once it worked. It seems to me that after password is entered on website, PiFinder stops plate solving. When I closed the website, once it managed to recover and started working. but it is very intermittent.

brickbots, 2024-08-10:
Sorry for not giving more frequent updates here, we've been busy with finalizing the PiFinder v3 hardware and re-writing the UI code.

We're continuing to dig into this and have found that it's actually some issue with the solver crashing after the gps info is set via the web interface.  We'll focus on fixing this up shortly after the v3 release.

Here's a hint for getting the GPS to lock, which is ultimately the best outcome:
* The Bump on the top of the PiFinder houses the GPS antenna, which is directional.  Pointing the bump on the top of PiFinder towards the most open part of the sky, especially if there are obstructions, can sometimes speed up lock times.  For left/right units, this generally means pointing the scope towards the horizon so that the bump is pointing up towards the sky.

AstroScot66, 2024-08-11:
Thank you. I'll test this out tonight.

AstroScot66, 2024-08-11:
That didn't work for me.  Plate solves look like they work well, but GPS fails.  When I manually enter the GPS on the mobile app, then plate solve stops working.

tranquilaxolotl, 2024-08-12:
I tried few times, and could not get it to work, GPS for takes forever to get a lock. When I try on open field, then I can get GPS lock. I will try again when new UI is released.

I was thinking that maybe with the new user interface it would be easy to add 4-5 preset preset GPS locations, and time/date setting, that could be easily accessible when "Searching for GPS..." is displayed. Adding this would make life much easier for people observing from obstructed locations (lots of trees, buildings, balcony in an apartment etc...)

mrosseel, 2024-08-12:
That's a good suggestion, probably not for the first release but soon after. Another fix is to the number of sats seen / used, this is currently only updating after a fix so useless. As for the web every, I've seen that fail on an old branch but not on current main, I will test again to be sure.

brickbots, 2024-08-24:
I spent a bit of time trying to replicate this one the bench and could not, but I've seen it happen several times when testing under the stars, so I'll try tonight if it's clear.

While I was looking through the code I realized that even if this works, it probably won't actually work.  The web interface only asks for time and the PiFinder code combines this with whatever the system date is, which is likely to also be wrong.  This should be updated to ask for the entire date/time to be entered and to grab this from the browser time automatically.
I'm logging this as #220

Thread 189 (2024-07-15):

'Align camera' target locations persistent if no target is selected

cdSheriff, 2024-07-15:
Flow to reproduce bug:
1. move telescope to sky view 'A'
2. initiate **Align** function from _Camera_ screen
3. cancel **Align** function without selecting object
4. move telescope to sky view 'B'
5. initiate **Align** function from _Camera_ screen
6. **objects 1,2,3 are persistent in screen location from sky view A, no relation to sky view B**

HW/SW:
- RPi 4
- 1.11.2 fresh build from .img

brickbots, 2024-11-10:
This should be resolved with the new alignment system :+1:

Closed 2024-11-10.

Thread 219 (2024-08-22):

Position & Time for Grab‘n‘Go Use

jscheidtmann, 2024-08-22:
Use Case: An observer at a fixed location wants to use PiFinder for a Grab‘n‘Go telescope.

Requirements:
 1) After switching on, observer position shall be read from the configuration file
 2) Once a GPS lock is achieved, the observer position should be stored in the configuration file (every 10-15 min) and only if the last stored position is different by more then 5 km (?) distance
 3) If PiFinder‘s WiFi is in client mode, time should be synced using ntpd and read at startup from the system.
 4) A configuration option „Grab‘n‘Go“ shall be created, that:
      4.1 presents position and time at startup and
      4.2 allows to edit position and time
      4.3 upon confirmation the position is stored in the config file

brickbots, 2024-08-23:
Thank you for laying out some actual specifications after the Discord discussion.  This looks good as a general feature set... but I think it using any non-GPS location should always start with some user action.  I.e. we can store and cache the last position, but I'd like choosing to use this to be a step that people actually invoke rather than having it try to do this on start up.

The primary reason being we don't know if the last position is correct and if people don't know the system is using the cached location, they may be confused when things don't work properly.

Determining the reliability of time is easier as we can see if the unit is online and able to get to an NTP server.. so we can automatically use this data if it's available.

jscheidtmann, 2024-08-24:
Updated with feedback from Brickbots.

jscheidtmann, 2025-06-29:
Shall we create a different issue for "enter position on device" and close this?

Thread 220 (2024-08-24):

Web Interface Location/Time entry screen needs to ask for date

brickbots, 2024-08-24:
As discovered while testing #188 the web interface only requests the current time, assuming the system date is correct.  This will almost inevitably lead to incorrect results as the system date is very likely wrong

* Adjust web interface to include input for date along with time
* Change javascript to populate date as well from the browser
* Change back-end code (server.py line 211) to use provided date rather than system date

Closed 2024-08-25.

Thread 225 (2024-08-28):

scroll_object in ui/object_details.py gets passed weird stuff

jscheidtmann, 2024-08-28:
See https://github.com/brickbots/PiFinder/pull/222/files#r1732015625

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
mrosseel, 2024-08-28:
Nearby sorting is using numpy for speed, we should either use numpy for all sorting stuff or convert nearby sort to normal list. I'm currently reworking sorting so it's probably best to revisit this after the sorting changes are done

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

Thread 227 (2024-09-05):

Sh2-119 Coordinates incorrect

brickbots, 2024-09-05:
This seems like it may be an issue with more than one of the Sh2 catalog entries.  Probably needs a re-process/audit

mrosseel, 2024-09-06:
might be something in the B1950 to J2000 conversion?
I've found the J2000 coordinates on heasarc, which match the wikipedia coordinates (on SH2-1) so that seems consistant.
So either we fix the transformation - which is most interesting because we might need to do that again in the future - or we use the new coordinates from heasarc to at least fix the issue

mrosseel, 2024-09-06:
[heasarc_sharpless.txt](https://github.com/user-attachments/files/16905007/heasarc_sharpless.txt)

brickbots, 2024-09-18:
Fixed with #230

Closed 2024-09-18.

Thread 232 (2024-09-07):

Implement framework to invoke/exercise UI modules in testing environment

brickbots, 2024-09-07:
- Set up a display type that works without hardware or pygame.  I believe the Luma module already has something like this
- Develop a fixture that spins up or mocks all of the items required to invoke a UIModule
  - display_class - the mock/stub display class
  - camera_image - A pil image which can be set to solvable/unsolvable during testing
  - shared_state - A mock (saved?) shared state where we can set solution/gps info for testing
  - command_queues - This is a dictionary of queue objects, should be easy to mock
  - config_object - Probably just use the actual config object, but could be easily mocked
  - catalogs - Probably best to use the actual catalogs object
  - add_to_stack - Just a function that returns
  - remove_from_stack - Just a function that returns
- Add a flatten_menu_items function to menu_manager to traverse the whole tree and return a flat list of menu_item_defininitions
- Develop a UIModule exerciser...
  - Adjust state in various ways (non solvable image, gps /no gps, ???)
  - Call .activate of module
  - Call all key related methods, with update after each
  - Adjust state and repeat

Once we have all of these pieces, then the test becomes
- Set up the fixture
- Get a list of menu_items to test
- Create a class instance for each menu_item
- Pass the class instance to the exerciser

We can add this as the first integration test, but if it's takes too long we can make a new 'slow' category of tests.  In any case, we can then run this on either all merges to main, or perhaps PR's or only PCs

brickbots, 2024-09-07:
https://luma-core.readthedocs.io/en/latest/device.html#luma.core.device.dummy

mrosseel, 2024-09-09:
In general I like this plan, however we should refrain from doing something special for testing, and just make the app more flexible in where the config comes from. Like the queues.
I guess my main point is: let's use this exercise to not only enable testing, but improve the code while we're at it.
One way to check this is if the changes will bring us closer to full replay capability. Not something we need right now, but I feel that would be the correct general direction.

Also not sure why the stack methods shouldn't do anything?

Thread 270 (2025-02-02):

Use equipment flip/flop and arrow config

brickbots, 2025-02-02:
- [ ] Flip/Flop of object images should be driven by attributes of currently selected instrument
- [ ] Arrow config should come from specific instrument, rather than global setting

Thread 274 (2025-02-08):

Update should handle downgrade gracefully.

jscheidtmann, 2025-02-08:
When updating, and a newer version is installed, update should at least ask "Are you sure?", before downgrading.

brickbots, 2025-02-08:
Hi @jscheidtmann! When you say 'newer version' are you talking about higher semantic version number in the version.txt file?

Is the use case here for people who are not on the release branch or did you run into a situation where updating from one release to another caused some downgrade?

jscheidtmann, 2025-02-08:
Came across the upgrade dialog in PiFinder while checking for translation. Noticed that there was no indication of a downgrade.
Being on main/i18n, check was against release branch.

Given the discussion we had on scripts running at upgrade time, we should make sure downgrading works.

brickbots, 2025-02-08:
Aha, thanks for the clarification.  The current update system is very much one-way-only and there is not a realistic path to making the system as it currently works downgrade capable.

If we want the ability to downgrade, we'll need to switch to a different pattern for managing software releases.  I've designed one which allows safe updating with rollback, arbitrary downgrades, and access to different release branches... but it requires implementation, testing and switching to this new system would require all users to reimage their SD card 😬

For now I'll make sure the update won't switch you to release if you have manually set yourself to a non release branch :+1:

brickbots, 2025-02-14:
With #276 The software update system will now checks the semver more carefully and will avoid installing previous versions

Closed 2025-02-14.

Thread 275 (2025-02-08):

Help and uiobject.message updates to support i8n

brickbots, 2025-02-08:
To allow more flexible and thorough translation of the UI these changes are proposed:

**Switch help system from using pre-rendered images to text**
Move all help text to strings that can be translated while maintining the ability to show button images, split pages, and include arbitrary images

- [ ] Work out specific token that represent buttons and would be replaced with images on rendering
- [ ] Decide on a token to indicate a page break
- [ ] Implement system to include images as needed

**Allow multi-line messages**
To provide more flexibility in translated strings, allow a newline char to be used to break text in .message method

jscheidtmann, 2025-06-29:
mrosseel is working on text help in #326

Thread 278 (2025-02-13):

Feature Request: Simulation Mode

jscheidtmann, 2025-02-13:
Let's create a simulation mode:

- [ ] Flag in settings to enable simulation mode (stored in config)
- [ ] Alt/Az pointing from IMU is converted into RA/DEC at current location and used as platesolve location. (Assuming current location and time have been set using the UI.)

Goal: This way one can experience the user interface (up to Camera and Alignment) by moving the PiFinder around in daylight.

brickbots, 2025-02-14:
This seems (mostly?) covered by the existing test mode found under 'Tools'.  Are you thinking of improving this, or completely replacing it?  Two differences I see:

* This proposes that the simulation mode persist across restarts... this has the potential for confusion if a user forgets it's on and starts observing, and only helps if you are restarting multiple times during a simulation session.  Are you thinking this is mostly a tool for developers who may start the software multiple times?

* The current Test system continually resets the position after the PiFinder stops moving.  We could potentially improve this by starting with the image saved from disk and generating a new image synthetically (via the current chart rendering) after the IMU detects motion has started/stopped.  It would make the testing mode more interesting!

jscheidtmann, 2025-02-14:
Good point, I have the feeling test-mode is almost there. I'll look into adjusting that.

Idea of this is to have a mode, that can be used to demonstrate **all** features of PiFinder.

jscheidtmann, 2025-02-14:
Ok, Test mode seems to do what I want. Sorry to bother you.

Closed 2025-02-14.

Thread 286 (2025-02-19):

Logging seems to be split

jscheidtmann, 2025-02-19:
DeadricGems reported a hang after a failed upgrade in Discord at this point:

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

But the log file, that we could access via SMB was empty.

I seems that the log configuration is switched / wrong at that point in the boot process.

jscheidtmann, 2025-02-19:
I cannot find that "WiFi:Client" message in the source. Not even find `find . -type f -print0 |xargs -0 grep -i wifi:client`.

brickbots, 2025-02-24:
The splash screen is handled in the file splash.py which is called via a different start up service before networking and other bits are online.

Even if it crashes, the main code should start up, so I don't think having proper logging on the splash screen is needed....

This still does not really help with why the software ended up in an un-usable state during the update and the main.py file crashed before logging anything 🤔   Given that the state of the code/sd card could end up very corrupted if the updated is terminated part way through I'm not surprised it can end up in some broken conditions.

Making the update process more robust, with a fail-safe rollback, is definitely needed

Closed 2025-02-24.

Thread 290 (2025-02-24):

Unify Console and Logging

brickbots, 2025-02-24:
This is a proposal to adjust the console such that it reads and displays the log file rather than being a separate source of information.  Originally the console was the only 'log', but since we much better multi-process logging has been implemented, it might make sense to have the console essentially tail the log file.

mrosseel, 2025-02-24:
Maybe rename to Log, and show the logging level as first line of the log. Changing log level there would be nice, maybe too dev centric but could be good for helping to debug issues

jscheidtmann, 2025-03-22:
The primary reason we do logging, is to get info what went wrong, when people report problems. I.e. it’s for customer support.

What is the primary purpose and customer added value of the console, if we showed the logs there?

I don’t see how it makes sense to show the log on the small screen. I am sorry, but I can imagine people sending us screenshots from the console asking for help. Let’s not do that.

I think it would make more sense to have a debug or support page in the server, offering to download the logs (i.e. not going through samba).

Also take into account, that when the main ui thread aborts, there is no console: Console is basically a queue, messages of which are captured into a string array in the main ui thread, to be displayed in the console view. The console view in addition is rather dumb at the moment, you can scroll up and down, but not left and right.

The log contains timestamps, detailed infos and stack traces from all processes, possibly mixed, if two processes happen to log at the same time. Because the log is also basically a queue into which all processes write, but it’s consumed and written to disk in an extra process.

mrosseel, 2025-03-22:
I've been thinking about adding something in the web server under 'Tools' which would zip all the logs and download it. Some warnings about leaking gps coords and ip addresses etc. If someone reports a crash they can do that and send it to us via discord/email. Being able to change the log level would also be nice, put it to debug, recreate the crash and send us the logs.

Now that you mention it, the screen is indeed too small for our kind of logging, maybe it should be removed altogether and replaced by a better status screen. With green/red lights for things such as camera, gps/time, imu. Platesolve could be 'solve within the last minute' for instance.

brickbots, 2025-03-23:
Thanks for the great discussion @jscheidtmann and @mrosseel 🤝

I think Console probably is not serving much purpose ultimately... and we should either just leave it as is, or remove it.  Adding some logging related tools to the web interface seems like a much better use of someone's time.

I'm going to close this and add an issue with some of the notes here for the web interface

Closed 2025-03-23.

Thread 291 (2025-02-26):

Equipment entry with decimal in focal length causes hard crash

omeganon, 2025-02-26:
Downloaded 2.1.0, tried adding in my telescope and experienced an error on save. PiFinder locked up and would not fully boot to the application. ssh'd in and found this in syslog --

```
Feb 25 18:56:37 pifinder python[413]: 2025-02-25 18:56:37,841 MainProcess-root:ERROR:Exception in main(). Aborting program.
Feb 25 18:56:37 pifinder python[413]: Traceback (most recent call last):
Feb 25 18:56:37 pifinder python[413]:   File "/home/pifinder/PiFinder/python/PiFinder/main.py", line 876, in <module>
Feb 25 18:56:37 pifinder python[413]:     main(log_helper, args.script, args.fps, args.verbose)
Feb 25 18:56:37 pifinder python[413]:   File "/home/pifinder/PiFinder/python/PiFinder/main.py", line 284, in main
Feb 25 18:56:37 pifinder python[413]:     cfg = config.Config()
Feb 25 18:56:37 pifinder python[413]:   File "/home/pifinder/PiFinder/python/PiFinder/config.py", line 22, in __init__
Feb 25 18:56:37 pifinder python[413]:     self.load_config()
Feb 25 18:56:37 pifinder python[413]:   File "/home/pifinder/PiFinder/python/PiFinder/config.py", line 48, in load_config
Feb 25 18:56:37 pifinder python[413]:     self.equipment = equipment.Equipment.from_dict(eq_config)
Feb 25 18:56:37 pifinder python[413]:   File "/usr/local/lib/python3.9/dist-packages/dataclasses_json/api.py", line 70, in from_dict
Feb 25 18:56:37 pifinder python[413]:     return _decode_dataclass(cls, kvs, infer_missing)
Feb 25 18:56:37 pifinder python[413]:   File "/usr/local/lib/python3.9/dist-packages/dataclasses_json/core.py", line 233, in _decode_dataclass
Feb 25 18:56:37 pifinder python[413]:     init_kwargs[field.name] = _decode_generic(field_type,
Feb 25 18:56:37 pifinder python[413]:   File "/usr/local/lib/python3.9/dist-packages/dataclasses_json/core.py", line 315, in _decode_generic
Feb 25 18:56:37 pifinder python[413]:     xs = _decode_items(_get_type_arg_param(type_, 0), value, infer_missing)
Feb 25 18:56:37 pifinder python[413]:   File "/usr/local/lib/python3.9/dist-packages/dataclasses_json/core.py", line 410, in _decode_items
Feb 25 18:56:37 pifinder python[413]:     return list(_decode_type(type_args, x, infer_missing) for x in xs)
Feb 25 18:56:37 pifinder python[413]:   File "/usr/local/lib/python3.9/dist-packages/dataclasses_json/core.py", line 410, in <genexpr>
Feb 25 18:56:37 pifinder python[413]:     return list(_decode_type(type_args, x, infer_missing) for x in xs)
Feb 25 18:56:37 pifinder python[413]:   File "/usr/local/lib/python3.9/dist-packages/dataclasses_json/core.py", line 247, in _decode_type
Feb 25 18:56:37 pifinder python[413]:     return _decode_generic(type_, value, infer_missing)
Feb 25 18:56:37 pifinder python[413]:   File "/usr/local/lib/python3.9/dist-packages/dataclasses_json/core.py", line 321, in _decode_generic
Feb 25 18:56:37 pifinder python[413]:     res = _decode_dataclass(origin, value, infer_missing)
Feb 25 18:56:37 pifinder python[413]:   File "/usr/local/lib/python3.9/dist-packages/dataclasses_json/core.py", line 237, in _decode_dataclass
Feb 25 18:56:37 pifinder python[413]:     init_kwargs[field.name] = _support_extended_types(field_type,
Feb 25 18:56:37 pifinder python[413]:   File "/usr/local/lib/python3.9/dist-packages/dataclasses_json/core.py", line 274, in _support_extended_types
Feb 25 18:56:37 pifinder python[413]:     else field_type(field_value))
Feb 25 18:56:37 pifinder python[413]: ValueError: invalid literal for int() with base 10: '279.5'
```

Related config snippet -

```
    "equipment": {
        "telescopes": [
            {
                "make": "Celestron",
                "name": "Deep Space",
                "aperture_mm": "279.5",
                "focal_length_mm": "1960",
                "obstruction_perc": 13.0,
                "mount_type": "equatorial",
                "flip_image": true,
                "flop_image": true,
                "reverse_arrow_a": true,
                "reverse_arrow_b": true
            }
        ],
```

Changing aperture_mm to '279' allowed for a graceful start.

brickbots, 2025-03-17:
Fixed in #289 released as part of 2.1.1

Closed 2025-03-17.

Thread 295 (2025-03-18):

Enhancements to make it easier to polar align a platform

alexis-cousein, 2025-03-18:
To polar align a platform (or even a mount!) *roughly* it's easy to use Polaris. (Str 60 in PiFinder parlance). I'll assume the North hemisphere.

-Put the platform at the start of travel (you can put it at the end of travel too, but need to reverse up/down and left_right in the rest if you do)
-Set Polaris as the target.
-Move your scope to Polaris
-Move the platform to the other end of travel.

You've just made the scope point to a new location rotated 15° counterclockwise around the polar axis of the platform. If that was pointing to Polaris, then Polaris will not have moved.

If Polaris is now "up" that means the platform axis is left of Polaris, so it needs to be rotated clockwise
If Polaris is now "down" that means the platform axis is right of Polaris, so it needs to be rotated counterclockwise
If Polaris is now "left" that means the platform axis is under Polaris, so the N side needs to be raised.
If Polaris is now "right" that means the platform axis is above Polaris, so the N side needs to be lowered (or the S side raised).

The good thing is that the target arrows of the PiFinder will actually tell you *exactly* what needs to be done.

This allows you to use Polaris, but the North Celestial Pole is actually 0.7° off.

Alas, the NCP is not one of the possible targets so you can't use the same trick to align more properly on the true pole.

Some possible fixes:
-allow input of target using RA/DEC. The NCP is at Dec +90° at any RA. Might be cumbersome
-A "Celestial Pole" category of objects with just two objects (the NCP and SCP)
-A hack, but one that will work: add numbers 999 (NCP) and 998 (SCP) to the "Star" catalogue

Ideally of course a DIRECT alignment help would be there.

-Point PiFinder anywhere (sure beats having to use a pole)
-Go to "polar alignment help" -- PiFinder plate solves where it is now
-Input  pole (NCP, SCP), angle of rotation and direction (clockwise, counterclockwise) of rotation around mount axis
-Move mount along RA by specified angle (usu whatever the platform will support or for regular mounts 90° or 180°)
-Hit enter.

Remember the parameters and you won't even have to correct for elapsed time most of the time.

The new plate solve's location and old plate solve location can only correspond to the angle the user indicated for the mount rotation for *one* location of the centre of rotation. Display how much in Alt and Az the true pole is from there (with arrows).

alexis-cousein, 2025-03-18:
Actually, if you also know the image rotation you don't even need ANY input. If the polar alignment is off you'd have field rotation between the two views that you can try to detect.

 For mounts that you can rotate over a lot that's good enough, but platforms can only be rotated 10° or so.

brickbots, 2025-03-23:
If we got the N/S CP added as objects, is there anything else that needs to be done here, or is that enough to enable a knowledgable user to polar align their platform?

alexis-cousein, 2025-03-24:
It's not ideal but it's a lot better than it is now.

If you know the platform rotation angle between the two extremes, and you point the scope to the NCP, then you know that the rotation axis is roughly 90° from where the NCP moves to after the platform reset; for the usual angle of 15° you also know that the distance to that rotation axis is roughly four times the distance that the NCP walked over ( from the geometry of two mirrored triangels, tan(7.5°) *1/2).

So it lets you read the Alt and multiply by 4 to get the Az error and lets you read the Az error and multiply by four to get the Alt error.

But then you need to play a little visualisation mind game to know in what direction. If your platform did a reset clockwise facing N then you expect the NCP to do a movement counterclockwise around the platform's axis with respect where the scope is now pointing, so if the NCP is now left and up from where the platfom is pointing, then the rotational axis is too high (left->high) and too much to the left (up->left) of the real NCP.

If you could input the direction of rotation of the platform and the angle and let the PiFinder do a before and an after plate solve, you could *directly* determine the axis of rotation (by the location of the two plate solves) and say how much to raise/lower the platform in Alt and how much to rotate it in Az to get alignment correct, without any iteration or any possiblity of guessing the direction wrong.

And you wouldn't even need to point your scope to the NCP to do it, *ANY* plate solve would allow you to find it. In fact, plate solves far from the NCP would be more precise.

alexis-cousein, 2025-03-25:
Edited last comment for clarity.

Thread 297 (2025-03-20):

Enhancement: Image capture automation

dasshark, 2025-03-20:
If someone wanted to insert a "save what the camera sees every N seconds" routine into the pifinder stack (through a fork + PR) where would you like to see this added?

I would like to add:
- config item to the web to set default capture
   - None
   - Timer (seconds)
   - Sky change
- Capture Settings:
   - interval in seconds
   - Sky change Delta of float(RA), Delta of float(Dec)
- console menu to select current image capture mode (default behavior to only be modifiable from the web config)
- console menu to adjust the interval seconds and save to stored config (RA/Dec should probably only be changed in the web config)
- web page area for viewing/downloading/erasing the images.
- a storage folder
- card capacity protection

The solver function is likely the best place to put this so it triggers on a timer always.

```
from datetime
now = datetime.datetime.now()

New dataclass called "last_solve"
- timestamp: datetime = <time of last platesolve>
- RA: float = CurrentSolve.RA
- Dec: float = CurrentSolve.Dec

imageformat = "PNG"
NewFileName =  f"{now.strftime("%Y-%m-%d %H%M%S}_RA-{CurrentSolve.RA}_Dec{CurrentSolve.Dec}.{imageformat.lower()}")
image.save(NewFileName,imageformat)

if config.imagecapture = interval
   if now - last_solve.timestamp).total_seconds()) > config.ImageCaptureInterval:
      <take a new photo>
elif config.imagecapture = skychange
  import math
  if math.isclose(abs(last_solve.RA), abs(current_solve.RA),rel_tol=config.skychangedelta) || math.isclose(abs(last_solve.Dec), abs(current_solve.Dec),rel_tol=config.skychangedelta):
  <take new photo>

```

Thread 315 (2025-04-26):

Eyepiece selection crashes when logging observation

mrosseel, 2025-04-26:
While logging an observation and going into the eyepiece selection, the crash below happened.
I did add a new eyepiece during this session, before the logging of the observation. Maybe this addition throwed it off?

```
Apr 27 01:00:52 pifinder-mr2 python[1542]: 2025-04-27 01:00:52,524 MainProcess-root:ERROR:Exception in main(). Aborting program.
Apr 27 01:00:52 pifinder-mr2 python[1542]: Traceback (most recent call last):
Apr 27 01:00:52 pifinder-mr2 python[1542]:   File "/home/pifinder/PiFinder/python/PiFinder/main.py", line 902, in <module>
Apr 27 01:00:52 pifinder-mr2 python[1542]:     main(log_helper, args.script, args.fps, args.verbose)
Apr 27 01:00:52 pifinder-mr2 python[1542]:   File "/home/pifinder/PiFinder/python/PiFinder/main.py", line 720, in main
Apr 27 01:00:52 pifinder-mr2 python[1542]:     menu_manager.key_right()
Apr 27 01:00:52 pifinder-mr2 python[1542]:   File "/home/pifinder/PiFinder/python/PiFinder/ui/menu_manager.py", line 473, in key_right
Apr 27 01:00:52 pifinder-mr2 python[1542]:     self.stack[-1].key_right()
Apr 27 01:00:52 pifinder-mr2 python[1542]:   File "/home/pifinder/PiFinder/python/PiFinder/ui/text_menu.py", line 188, in key_right
Apr 27 01:00:52 pifinder-mr2 python[1542]:     self.config_object.set_option(config_option, config_value)
Apr 27 01:00:52 pifinder-mr2 python[1542]:   File "/home/pifinder/PiFinder/python/PiFinder/config.py", line 85, in set_option
Apr 27 01:00:52 pifinder-mr2 python[1542]:     self.equipment.set_active_eyepiece(value)
Apr 27 01:00:52 pifinder-mr2 python[1542]:   File "/home/pifinder/PiFinder/python/PiFinder/equipment.py", line 44, in set_active_eyepiece
Apr 27 01:00:52 pifinder-mr2 python[1542]:     self.active_eyepiece_index = self.eyepieces.index(eyepiece)
Apr 27 01:00:52 pifinder-mr2 python[1542]: ValueError: Eyepiece(make='APM', name='XWA 13mm 100gr', focal_length_mm=13.0, afov=100, field_stop=2>
Apr 27 01:00:52 pifinder-mr2 python[1615]: Process Integrator:
Apr 27 01:00:52 pifinder-mr2 python[1610]: 2025-04-27 01:00:52,536 Solver-Solver:ERROR:Lost connection to shared state manager: [Errno 32] Brok>
Apr 27 01:00:52 pifinder-mr2 python[1610]: 2025-04-27 01:00:52,537 Solver-Solver:ERROR:Exception in Solver: BrokenPipeError: [Errno 32] Broken >
Apr 27 01:00:52 pifinder-mr2 python[1615]: Traceback (most recent call last):
Apr 27 01:00:52 pifinder-mr2 python[1615]:   File "/usr/lib/python3.9/multiprocessing/process.py", line 315, in _bootstrap
Apr 27 01:00:52 pifinder-mr2 python[1615]:     self.run()
Apr 27 01:00:52 pifinder-mr2 python[1615]:   File "/usr/lib/python3.9/multiprocessing/process.py", line 108, in run
Apr 27 01:00:52 pifinder-mr2 python[1615]:     self._target(*self._args, **self._kwargs)
Apr 27 01:00:52 pifinder-mr2 python[1615]:   File "/home/pifinder/PiFinder/python/PiFinder/integrator.py", line 167, in integrator
Apr 27 01:00:52 pifinder-mr2 python[1615]:     imu = shared_state.imu()
Apr 27 01:00:52 pifinder-mr2 python[1615]:   File "<string>", line 2, in imu
Apr 27 01:00:52 pifinder-mr2 python[1615]:   File "/usr/lib/python3.9/multiprocessing/managers.py", line 808, in _callmethod
Apr 27 01:00:52 pifinder-mr2 python[1615]:     conn.send((self._id, methodname, args, kwds))
Apr 27 01:00:52 pifinder-mr2 python[1615]:   File "/usr/lib/python3.9/multiprocessing/connection.py", line 211, in send
Apr 27 01:00:52 pifinder-mr2 python[1615]:     self._send_bytes(_ForkingPickler.dumps(obj))
Apr 27 01:00:52 pifinder-mr2 python[1615]:   File "/usr/lib/python3.9/multiprocessing/connection.py", line 416, in _send_bytes
Apr 27 01:00:52 pifinder-mr2 python[1615]:     self._send(header + buf)
Apr 27 01:00:52 pifinder-mr2 python[1615]:   File "/usr/lib/python3.9/multiprocessing/connection.py", line 373, in _send
Apr 27 01:00:52 pifinder-mr2 python[1615]:     n = write(self._handle, buf)
Apr 27 01:00:52 pifinder-mr2 python[1615]: BrokenPipeError: [Errno 32] Broken pipe
Apr 27 01:00:52 pifinder-mr2 python[1615]: Loading config from /home/pifinder/PiFinder_data/config.json
Apr 27 01:00:52 pifinder-mr2 python[1610]: 2025-04-27 01:00:52,538 Solver-Solver:ERROR:[Errno 32] Broken pipe
Apr 27 01:00:52 pifinder-mr2 python[1610]: Traceback (most recent call last):
Apr 27 01:00:52 pifinder-mr2 python[1610]:   File "/home/pifinder/PiFinder/python/PiFinder/solver.py", line 120, in solver
Apr 27 01:00:52 pifinder-mr2 python[1610]:     state_utils.sleep_for_framerate(shared_state)
Apr 27 01:00:52 pifinder-mr2 python[1610]:   File "/home/pifinder/PiFinder/python/PiFinder/state_utils.py", line 6, in sleep_for_framerate
Apr 27 01:00:52 pifinder-mr2 python[1610]:     if shared_state.power_state() <= 0:

```

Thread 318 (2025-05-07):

When choosing Planets make Names the default

Git4me2day, 2025-05-07:
When going to the menu on the PiFinder, make the menu option of

“Objects” -> “By Catalog” -> “Planets”

show the Planet Name ie. Mars as Default.

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

brickbots, 2025-05-09:
Thanks for logging this @Git4me2day it's been 'on the list' for a while, but it's good to have it on the *actual* list 😅

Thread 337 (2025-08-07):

Determine the offset/digital gain for imx296 and imx462 sensors

brickbots, 2025-08-07:
In testing the imx477 there is an offset to the black level  in the raw output, and that star detection/solve robustness was improved by removing this offset and adding a digital gain prior to converting to an 8 bit image.  This offset/gain is available for all sensors, but only have experimentally validated values for the imx477.

See #335 for details

This issue is to perform simulated and real-world tests to see if the other sensors have a black level offset and to determine what, if any, digital gain will help them perform their best.

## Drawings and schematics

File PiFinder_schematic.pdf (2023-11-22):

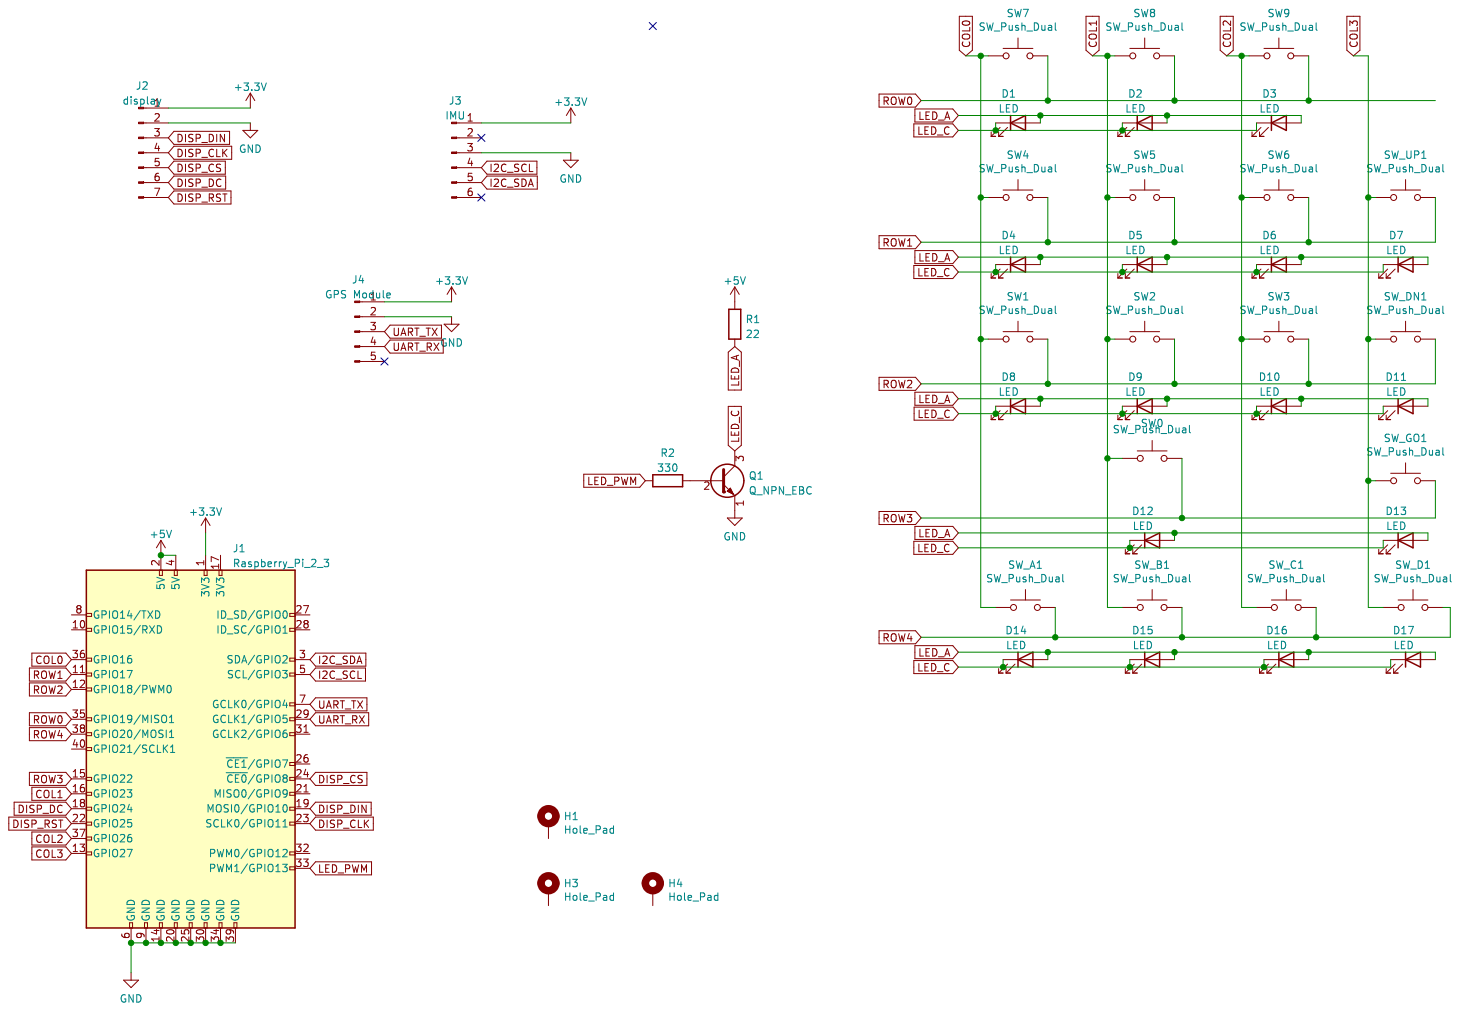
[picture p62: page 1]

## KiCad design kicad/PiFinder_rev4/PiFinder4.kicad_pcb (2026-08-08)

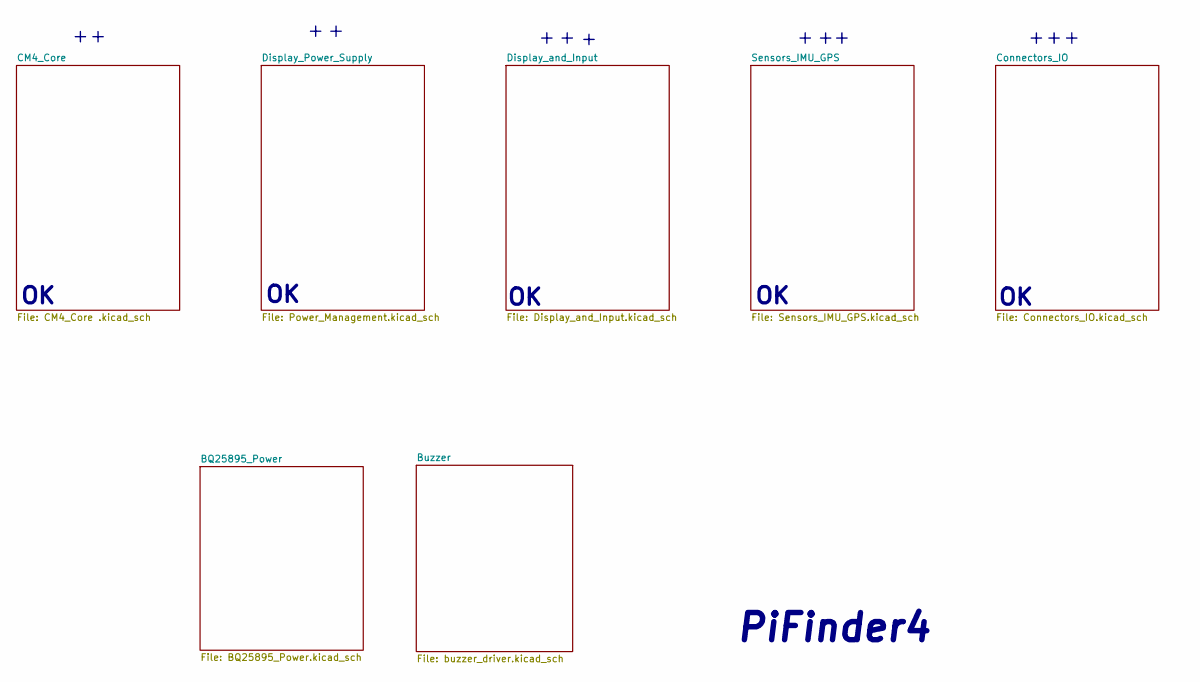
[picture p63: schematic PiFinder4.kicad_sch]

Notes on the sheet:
PiFinder4

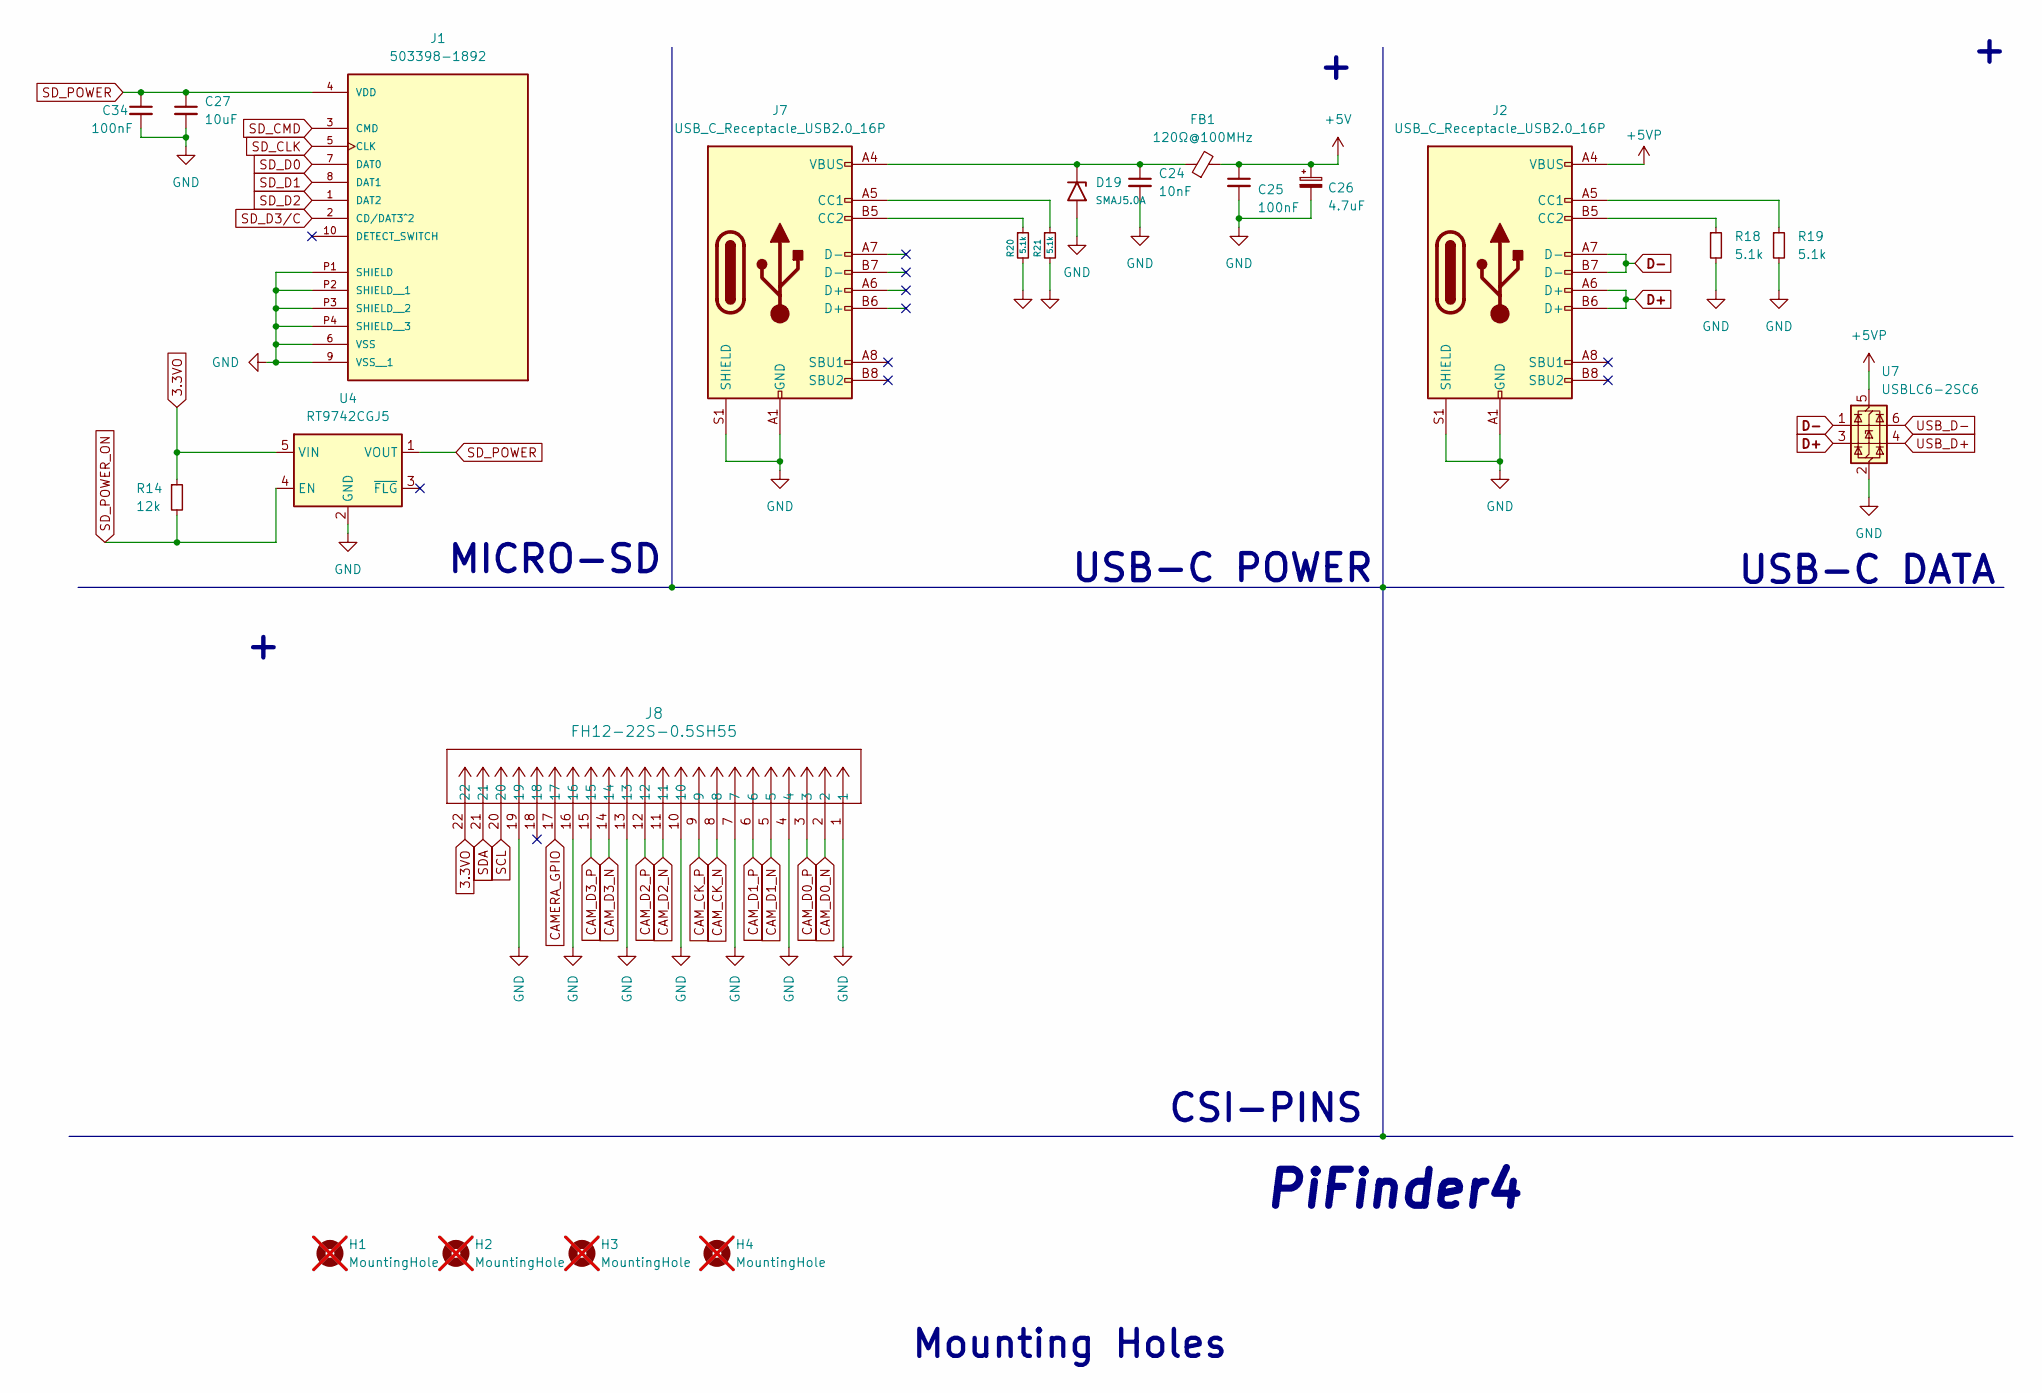
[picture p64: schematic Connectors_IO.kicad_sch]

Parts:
C24: 10nF; C_0402_1005Metric; LCSC C15195
C25, C34: 100nF; C_0603_1608Metric; LCSC C14663
C26: 4.7uF; CP_Elec_4x5.4; LCSC C970651
C27: 10uF; C_0805_2012Metric; LCSC C15850
D19: SMAJ5.0A; D_SMA; LCSC C10758
FB1: 120Ω@100MHz; L_1206_3216Metric; LCSC C85841
H1, H2, H3, H4: MountingHole; MountingHole_2.5mm; not fitted
J1: 503398-1892; MOLEX_503398-1892; PARTREV 0; LCSC C428492
J2, J7: USB_C_Receptacle_USB2.0_16P; USB_C_Receptacle_HCTL_HC-TYPE-C-16P-01A; LCSC C165948
J8: FH12-22S-0.5SH55; CONN_FH12-22S-0.5SH55_HIR; LCSC C597981
R14: 12k; R_0402_1005Metric; LCSC C25752
R18, R19, R20, R21: 5.1k; R_0402_1005Metric; LCSC C25905
U4: RT9742CGJ5; TSOT-23-5; LCSC C424402
U7: USBLC6-2SC6; SOT-23-6; LCSC C2687116

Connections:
3.3VO: J8.22, R14.1, U4.5 (VIN); also elsewhere on the board
+5V: C25.1, C26.1, FB1.2; also elsewhere on the board
+5VP: J2.A4 (VBUS), J2.A9 (VBUS), J2.B4 (VBUS), J2.B9 (VBUS), U7.5 (VBUS); also elsewhere on the board
CAMERA_GPIO: J8.17; also elsewhere on the board
CAM_CK_N: J8.8; also elsewhere on the board
CAM_CK_P: J8.9; also elsewhere on the board
CAM_D0_N: J8.2; also elsewhere on the board
CAM_D0_P: J8.3; also elsewhere on the board
CAM_D1_N: J8.5; also elsewhere on the board
CAM_D1_P: J8.6; also elsewhere on the board
CAM_D2_N: J8.11; also elsewhere on the board
CAM_D2_P: J8.12; also elsewhere on the board
CAM_D3_N: J8.14; also elsewhere on the board
CAM_D3_P: J8.15; also elsewhere on the board
D+: J2.A6 (D+), J2.B6 (D+), U7.3 (I/O2)
D-: J2.A7 (D-), J2.B7 (D-), U7.1 (I/O1)
GND: C24.2, C25.2, C26.2, C27.2, C34.2, D19.2 (A2), J1.6 (VSS), J1.9 (VSS__1), J1.P1 (SHIELD), J1.P2 (SHIELD__1), J1.P3 (SHIELD__2), J1.P4 (SHIELD__3), J2.A1 (GND), J2.A12 (GND), J2.B1 (GND), J2.B12 (GND), J2.S1 (SHIELD), J7.A1 (GND), J7.A12 (GND), J7.B1 (GND), J7.B12 (GND), J7.S1 (SHIELD), J8.1, J8.4, J8.7, J8.10, J8.13, J8.16, J8.19, R18.2, R19.2, R20.2, R21.2, U4.2 (GND), U7.2 (GND); also elsewhere on the board
unnamed: C24.1, D19.1 (A1), FB1.1, J7.A4 (VBUS), J7.A9 (VBUS), J7.B4 (VBUS), J7.B9 (VBUS)
unnamed: J2.A5 (CC1), R19.1
unnamed: J2.B5 (CC2), R18.1
unnamed: J7.A5 (CC1), R21.1
unnamed: J7.B5 (CC2), R20.1
SCL: J8.20; also elsewhere on the board
SDA: J8.21; also elsewhere on the board
SD_CLK: J1.5 (CLK); also elsewhere on the board
SD_CMD: J1.3 (CMD); also elsewhere on the board
SD_D0: J1.7 (DAT0); also elsewhere on the board
SD_D1: J1.8 (DAT1); also elsewhere on the board
SD_D2: J1.1 (DAT2); also elsewhere on the board
SD_D3/C: J1.2 (CD/DAT3^2); also elsewhere on the board
SD_POWER: C27.1, C34.1, J1.4 (VDD), U4.1 (VOUT)
SD_POWER_ON: R14.2, U4.4 (EN); also elsewhere on the board
USB_D+: U7.4 (I/O2); also elsewhere on the board
USB_D-: U7.6 (I/O1); also elsewhere on the board

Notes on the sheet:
CSI-PINS
USB-C DATA
PiFinder4
USB-C POWER
MICRO-SD
Mounting Holes

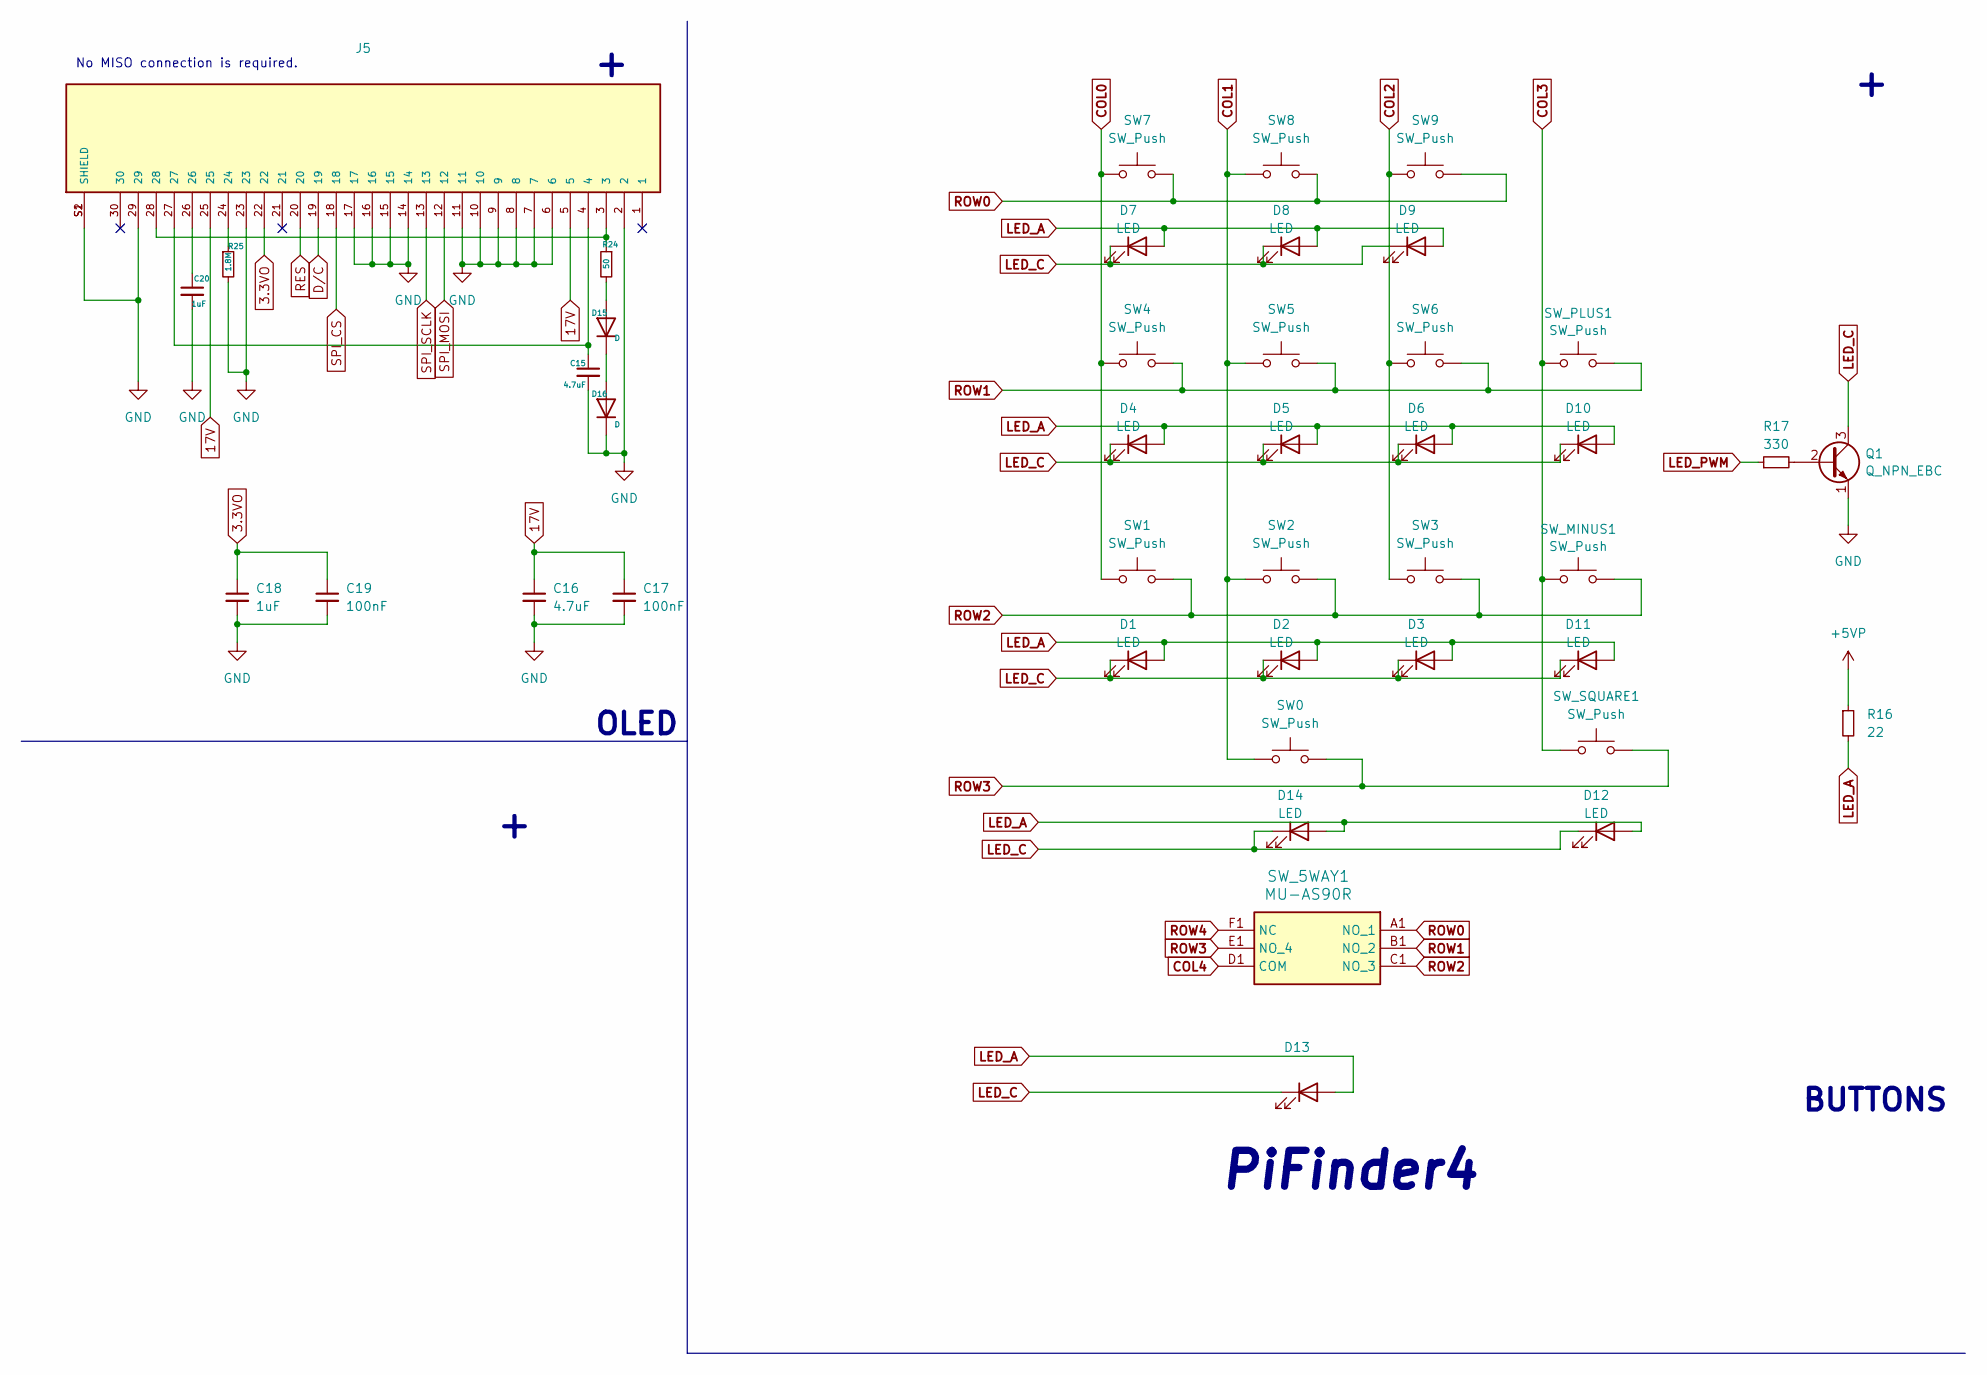
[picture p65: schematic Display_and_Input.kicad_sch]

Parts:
C15, C16: 4.7uF; C_1206_3216Metric; LCSC C29823
C17, C19: 100nF; C_0603_1608Metric; LCSC C14663
C18, C20: 1uF; C_0603_1608Metric; LCSC C15849
D1, D2, D3, D4, D5, D6, D7, D8, D9, D10, D11, D12, D13, D14: LED; LED_1210_3225Metric; LCSC C264578
D15, D16: D; D_SOD-123; LCSC C81598
J5: TE_3-1734592-0; PARTREV C; LCSC C375905
Q1: Q_NPN_EBC; PF_SOT-23-NPN; LCSC C280842
R16: 22; R_0402_1005Metric; LCSC C25092
R17: 330; R_0402_1005Metric; LCSC C25104
R24: 50; R_0603_1608Metric; LCSC C844932
R25: 1.8M; R_0402_1005Metric; LCSC C38587
SW0, SW1, SW2, SW3, SW4, SW5, SW6, SW7, SW8, SW9: SW_Push; SW_Push_6x6mm_SMT_withhole_tight; LCSC C4364377
SW_5WAY1: MU-AS90R; MUAS70R; Mouser Part Number 642-MU-AS70R; LCSC C38516684
SW_MINUS1: SW_Push; SW_Push_6x6mm_SMT_withhole_tight; LCSC C4364377
SW_PLUS1: SW_Push; SW_Push_6x6mm_SMT_withhole_tight; LCSC C4364377
SW_SQUARE1: SW_Push; SW_Push_6x6mm_SMT_withhole_tight; LCSC C4364377

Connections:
3.3VO: C18.1, C19.1, J5.22; also elsewhere on the board
17V: C16.1, C17.1, J5.5, J5.25; also elsewhere on the board
+5VP: R16.1; also elsewhere on the board
COL0: SW1.1, SW4.1, SW7.1; also elsewhere on the board
COL1: SW0.1, SW2.1, SW5.1, SW8.1; also elsewhere on the board
COL2: SW3.1, SW6.1, SW9.1; also elsewhere on the board
COL3: SW_MINUS1.1, SW_PLUS1.1, SW_SQUARE1.1; also elsewhere on the board
COL4: SW_5WAY1.D1 (COM); also elsewhere on the board
D/C: J5.19; also elsewhere on the board
GND: C15.2, C16.2, C17.2, C18.2, C19.2, C20.2, D16.1 (K), J5.2, J5.6, J5.7, J5.8, J5.9, J5.10, J5.11, J5.14, J5.15, J5.16, J5.17, J5.23, J5.29, J5.S1 (SHIELD), J5.S2 (SHIELD), Q1.1 (E), R25.2; also elsewhere on the board
LED_A: D1.2 (A), D2.2 (A), D3.2 (A), D4.2 (A), D5.2 (A), D6.2 (A), D7.2 (A), D8.2 (A), D9.2 (A), D10.2 (A), D11.2 (A), D12.2 (A), D13.2 (A), D14.2 (A), R16.2
LED_C: D1.1 (K), D2.1 (K), D3.1 (K), D4.1 (K), D5.1 (K), D6.1 (K), D7.1 (K), D8.1 (K), D9.1 (K), D10.1 (K), D11.1 (K), D12.1 (K), D13.1 (K), D14.1 (K), Q1.3 (C)
LED_PWM: R17.1; also elsewhere on the board
unnamed: C15.1, J5.4, J5.27
unnamed: C20.1, J5.26
unnamed: D15.2 (A), R24.2
unnamed: D15.1 (K), D16.2 (A)
unnamed: J5.24, R25.1
unnamed: J5.3, J5.28, R24.1
unnamed: Q1.2 (B), R17.2
RES: J5.20; also elsewhere on the board
ROW0: SW7.2, SW8.2, SW9.2, SW_5WAY1.A1 (NO_1); also elsewhere on the board
ROW1: SW4.2, SW5.2, SW6.2, SW_5WAY1.B1 (NO_2), SW_PLUS1.2; also elsewhere on the board
ROW2: SW1.2, SW2.2, SW3.2, SW_5WAY1.C1 (NO_3), SW_MINUS1.2; also elsewhere on the board
ROW3: SW0.2, SW_5WAY1.E1 (NO_4), SW_SQUARE1.2; also elsewhere on the board
ROW4: SW_5WAY1.F1 (NC); also elsewhere on the board
SPI_CS: J5.18; also elsewhere on the board
SPI_MOSI: J5.12; also elsewhere on the board
SPI_SCLK: J5.13; also elsewhere on the board

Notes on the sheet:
No MISO connection is required.
PiFinder4
BUTTONS
OLED

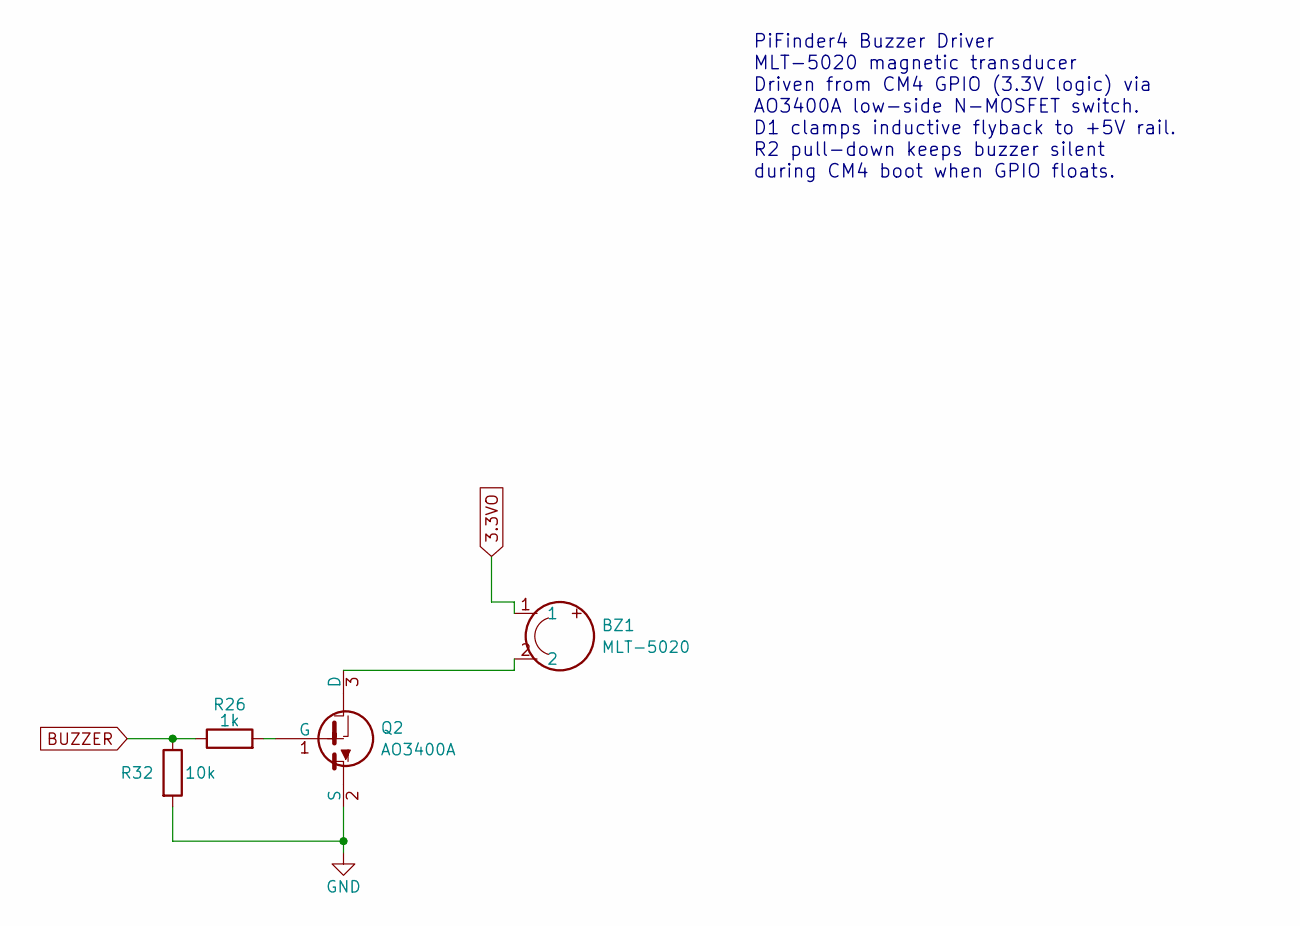
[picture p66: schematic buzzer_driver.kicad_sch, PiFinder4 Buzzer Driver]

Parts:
BZ1: MLT-5020; MagneticBuzzer_HuaWha_MLT-5020; LCSC C94598
Q2: AO3400A; SOT-23; LCSC C20917
R26: 1k; R_0402_1005Metric; LCSC C11702
R32: 10k; R_0402_1005Metric; LCSC C25744

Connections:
3.3VO: BZ1.1; also elsewhere on the board
BUZZER: R26.1, R32.1; also elsewhere on the board
GND: Q2.2 (S), R32.2; also elsewhere on the board
unnamed: BZ1.2, Q2.3 (D)
unnamed: Q2.1 (G), R26.2

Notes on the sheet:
PiFinder4 Buzzer Driver MLT-5020 magnetic transducer Driven from CM4 GPIO (3.3V logic) via AO3400A low-side N-MOSFET switch. D1 clamps inductive flyback to +5V rail. R2 pull-down keeps buzzer silent during CM4 boot when GPIO floats.

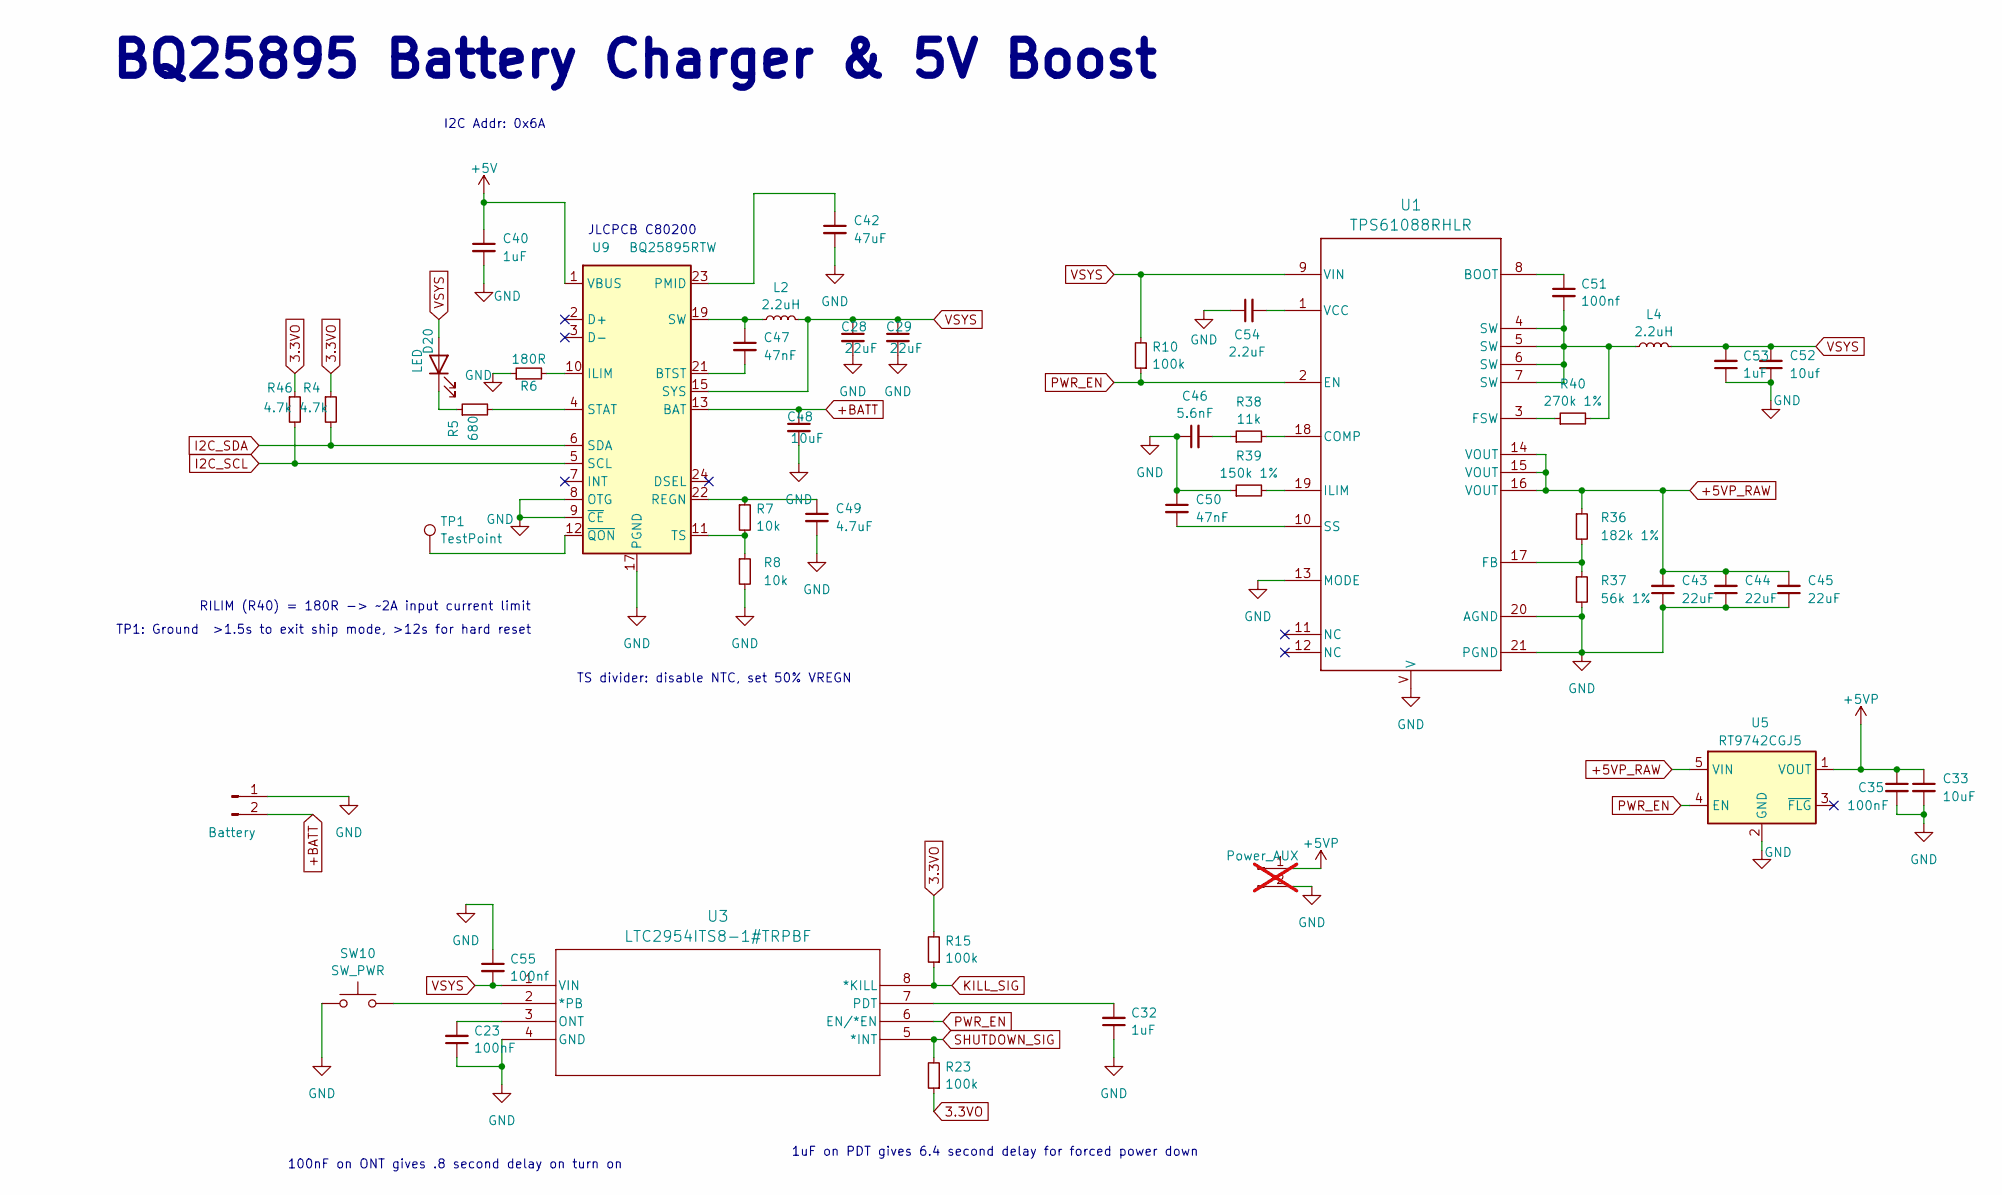
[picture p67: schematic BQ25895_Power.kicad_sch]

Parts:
C23, C35: 100nF; C_0603_1608Metric; LCSC C14663
C28, C29, C43, C44, C45: 22uF; C_0805_2012Metric; LCSC C45783
C32, C40, C53: 1uF; C_0603_1608Metric; LCSC C15849
C33: 10uF; C_0805_2012Metric; LCSC C15850
C42: 47uF; C_1206_3216Metric; LCSC C403725
C46: 5.6nF; C_0603_1608Metric; LCSC C107095
C47, C50: 47nF; C_0603_1608Metric; LCSC C1622
C48: 10uF; C_0603_1608Metric; LCSC C96446
C49: 4.7uF; C_0603_1608Metric; LCSC C19666
C51, C55: 100nf; C_0603_1608Metric; LCSC C14663
C52: 10uf; C_0805_2012Metric; LCSC C15850
C54: 2.2uF; C_0603_1608Metric; LCSC C23630
D20: LED; LED_1210_3225Metric; LCSC C264578
J3: Power_AUX; PinHeader_1x02_P2.54mm_Vertical; LCSC C160352; not fitted
J4: Battery; JST_PH_B2B-PH-SM4-TB_1x02-1MP_P2.00mm_Vertical; LCSC C160352
L2, L4: 2.2uH; L_Coilcraft_XAL4020-XXX; LCSC C3151182
R4, R46: 4.7k; R_0402_1005Metric; LCSC C25900
R5: 680; R_0402_1005Metric; LCSC C137948
R6: 180R; R_0402_1005Metric; LCSC C138045
R7, R8: 10k; R_0402_1005Metric; LCSC C25744
R10, R15, R23: 100k; R_0402_1005Metric; LCSC C25741
R36: 182k 1%; R_0402_1005Metric; LCSC C5159679
R37: 56k 1%; R_0402_1005Metric; LCSC C114756
R38: 11k; R_0402_1005Metric; LCSC C138063
R39: 150k 1%; R_0402_1005Metric; LCSC C2909320
R40: 270k 1%; R_0402_1005Metric; LCSC C25770
SW10: SW_PWR; SW_Push_6x6mm_SMT_withhole_tight; LCSC C4364377
TP1: TestPoint
U1: TPS61088RHLR; RHL0020A; LCSC C87357
U3: LTC2954ITS8-1#TRPBF; TSOT-23_TS8_LIT; LCSC C683782
U5: RT9742CGJ5; TSOT-23-5; LCSC C424402
U9: BQ25895RTW; Texas_RTW_WQFN-24-1EP_4x4mm_P0.5mm_EP2.7x2.7mm_ThermalVias; LCSC C80200

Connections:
3.3VO: R4.1, R15.2, R23.1, R46.1; also elsewhere on the board
+5V: C40.1, U9.1 (VBUS); also elsewhere on the board
+5VP: C33.1, C35.1, J3.1, U5.1 (VOUT); also elsewhere on the board
+5VP_RAW: C43.2, C44.2, C45.2, R36.1, U1.14 (VOUT), U1.15 (VOUT), U1.16 (VOUT), U5.5 (VIN)
+BATT: C48.1, J4.2, U9.13 (BAT), U9.14 (BAT)
GND: C23.1, C28.2, C29.2, C32.1, C33.2, C35.2, C40.2, C42.2, C43.1, C44.1, C45.1, C46.1, C48.2, C49.2, C50.1, C52.1, C53.1, C54.1, C55.1, J3.2, J4.1, R6.1, R8.2, R37.2, R39.1, SW10.1, U1.13 (MODE), U1.20 (AGND), U1.21 (PGND), U1.V, U3.4 (GND), U5.2 (GND), U9.8 (OTG), U9.9 (~CE), U9.17 (PGND), U9.18 (PGND), U9.25 (PGND); also elsewhere on the board
I2C_SCL: R46.2, U9.5 (SCL); also elsewhere on the board
I2C_SDA: R4.2, U9.6 (SDA); also elsewhere on the board
KILL_SIG: R15.1, U3.8 (*KILL); also elsewhere on the board
unnamed: C46.2, R38.1
unnamed: C47.1, L2.1, U9.19 (SW), U9.20 (SW)
unnamed: C51.2, L4.1, R40.2, U1.4 (SW), U1.5 (SW), U1.6 (SW), U1.7 (SW)
unnamed: D20.1 (K), R5.1
unnamed: C51.1, U1.8 (BOOT)
unnamed: R38.2, U1.18 (COMP)
unnamed: R36.2, R37.1, U1.17 (FB)
unnamed: R40.1, U1.3 (FSW)
unnamed: R39.2, U1.19 (ILIM)
unnamed: C50.2, U1.10 (SS)
unnamed: C54.2, U1.1 (VCC)
unnamed: SW10.2, U3.2 (*PB)
unnamed: C23.2, U3.3 (ONT)
unnamed: C32.2, U3.7 (PDT)
unnamed: C47.2, U9.21 (BTST)
unnamed: R6.2, U9.10 (ILIM)
unnamed: C42.1, U9.23 (PMID)
unnamed: C49.1, R7.1, U9.22 (REGN)
unnamed: R5.2, U9.4 (STAT)
unnamed: R7.2, R8.1, U9.11 (TS)
unnamed: TP1.1, U9.12 (~QON)
PWR_EN: R10.1, U1.2 (EN), U3.6 (EN/*EN), U5.4 (EN)
SHUTDOWN_SIG: R23.2, U3.5 (*INT); also elsewhere on the board
VSYS: C28.1, C29.1, C52.2, C53.2, C55.2, D20.2 (A), L2.2, L4.2, R10.2, U1.9 (VIN), U3.1 (VIN), U9.15 (SYS), U9.16 (SYS)

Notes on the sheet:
JLCPCB C80200
TS divider: disable NTC, set 50% VREGN
RILIM (R40) = 180R -> ~2A input current limit
TP1: Ground >1.5s to exit ship mode, >12s for hard reset
100nF on ONT gives .8 second delay on turn on
I2C Addr: 0x6A
BQ25895 Battery Charger & 5V Boost
1uF on PDT gives 6.4 second delay for forced power down

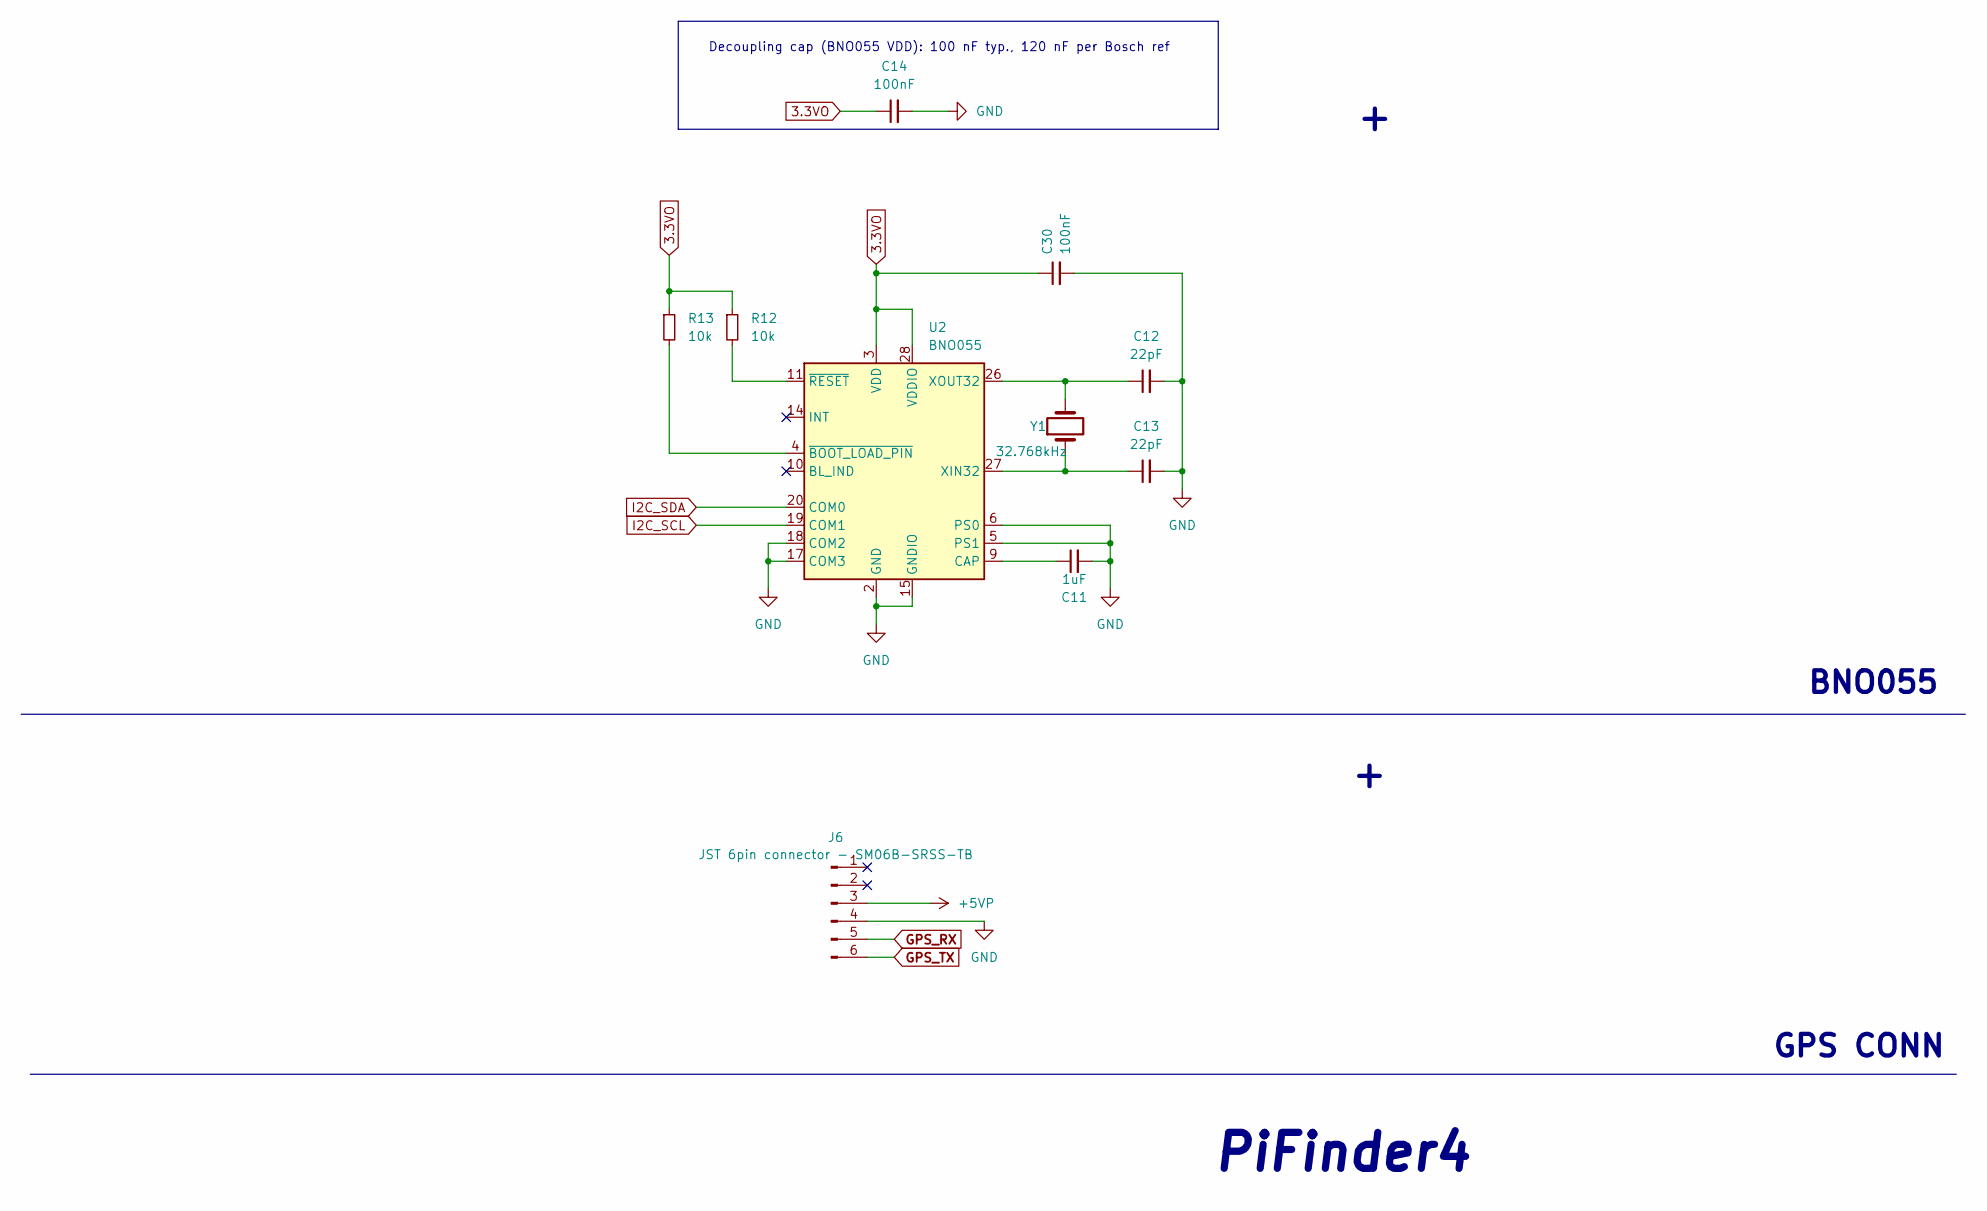
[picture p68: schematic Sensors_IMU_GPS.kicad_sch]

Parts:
C11: 1uF; C_0603_1608Metric; LCSC C15849
C12, C13: 22pF; C_0402_1005Metric; LCSC C1555
C14, C30: 100nF; C_0603_1608Metric; LCSC C14663
J6: JST 6pin connector - SM06B-SRSS-TB; JST_SH_BM06B-SRSS-TB_1x06-1MP_P1.00mm_Vertical; LCSC C160392
R12, R13: 10k; R_0402_1005Metric; LCSC C25744
U2: BNO055; LGA-28_5.2x3.8mm_P0.5mm; LCSC C93216
Y1: 32.768kHz; Crystal_SMD_3215-2Pin_3.2x1.5mm; LCSC C32346

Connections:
3.3VO: C14.1, C30.1, R12.1, R13.1, U2.3 (VDD), U2.28 (VDDIO); also elsewhere on the board
+5VP: J6.3; also elsewhere on the board
GND: C11.2, C12.2, C13.2, C14.2, C30.2, J6.4, U2.2 (GND), U2.5 (PS1), U2.6 (PS0), U2.15 (GNDIO), U2.16 (GNDIO), U2.17 (COM3), U2.18 (COM2), U2.25 (GNDIO); also elsewhere on the board
GPS_RX: J6.5; also elsewhere on the board
GPS_TX: J6.6; also elsewhere on the board
I2C_SCL: U2.19 (COM1); also elsewhere on the board
I2C_SDA: U2.20 (COM0); also elsewhere on the board
unnamed: C11.1, U2.9 (CAP)
unnamed: C13.1, U2.27 (XIN32), Y1.1
unnamed: C12.1, U2.26 (XOUT32), Y1.2
unnamed: R13.2, U2.4 (~BOOT_LOAD_PIN)
unnamed: R12.2, U2.11 (~RESET)

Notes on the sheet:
PiFinder4
Decoupling cap (BNO055 VDD): 100 nF typ., 120 nF per Bosch ref
GPS CONN
BNO055

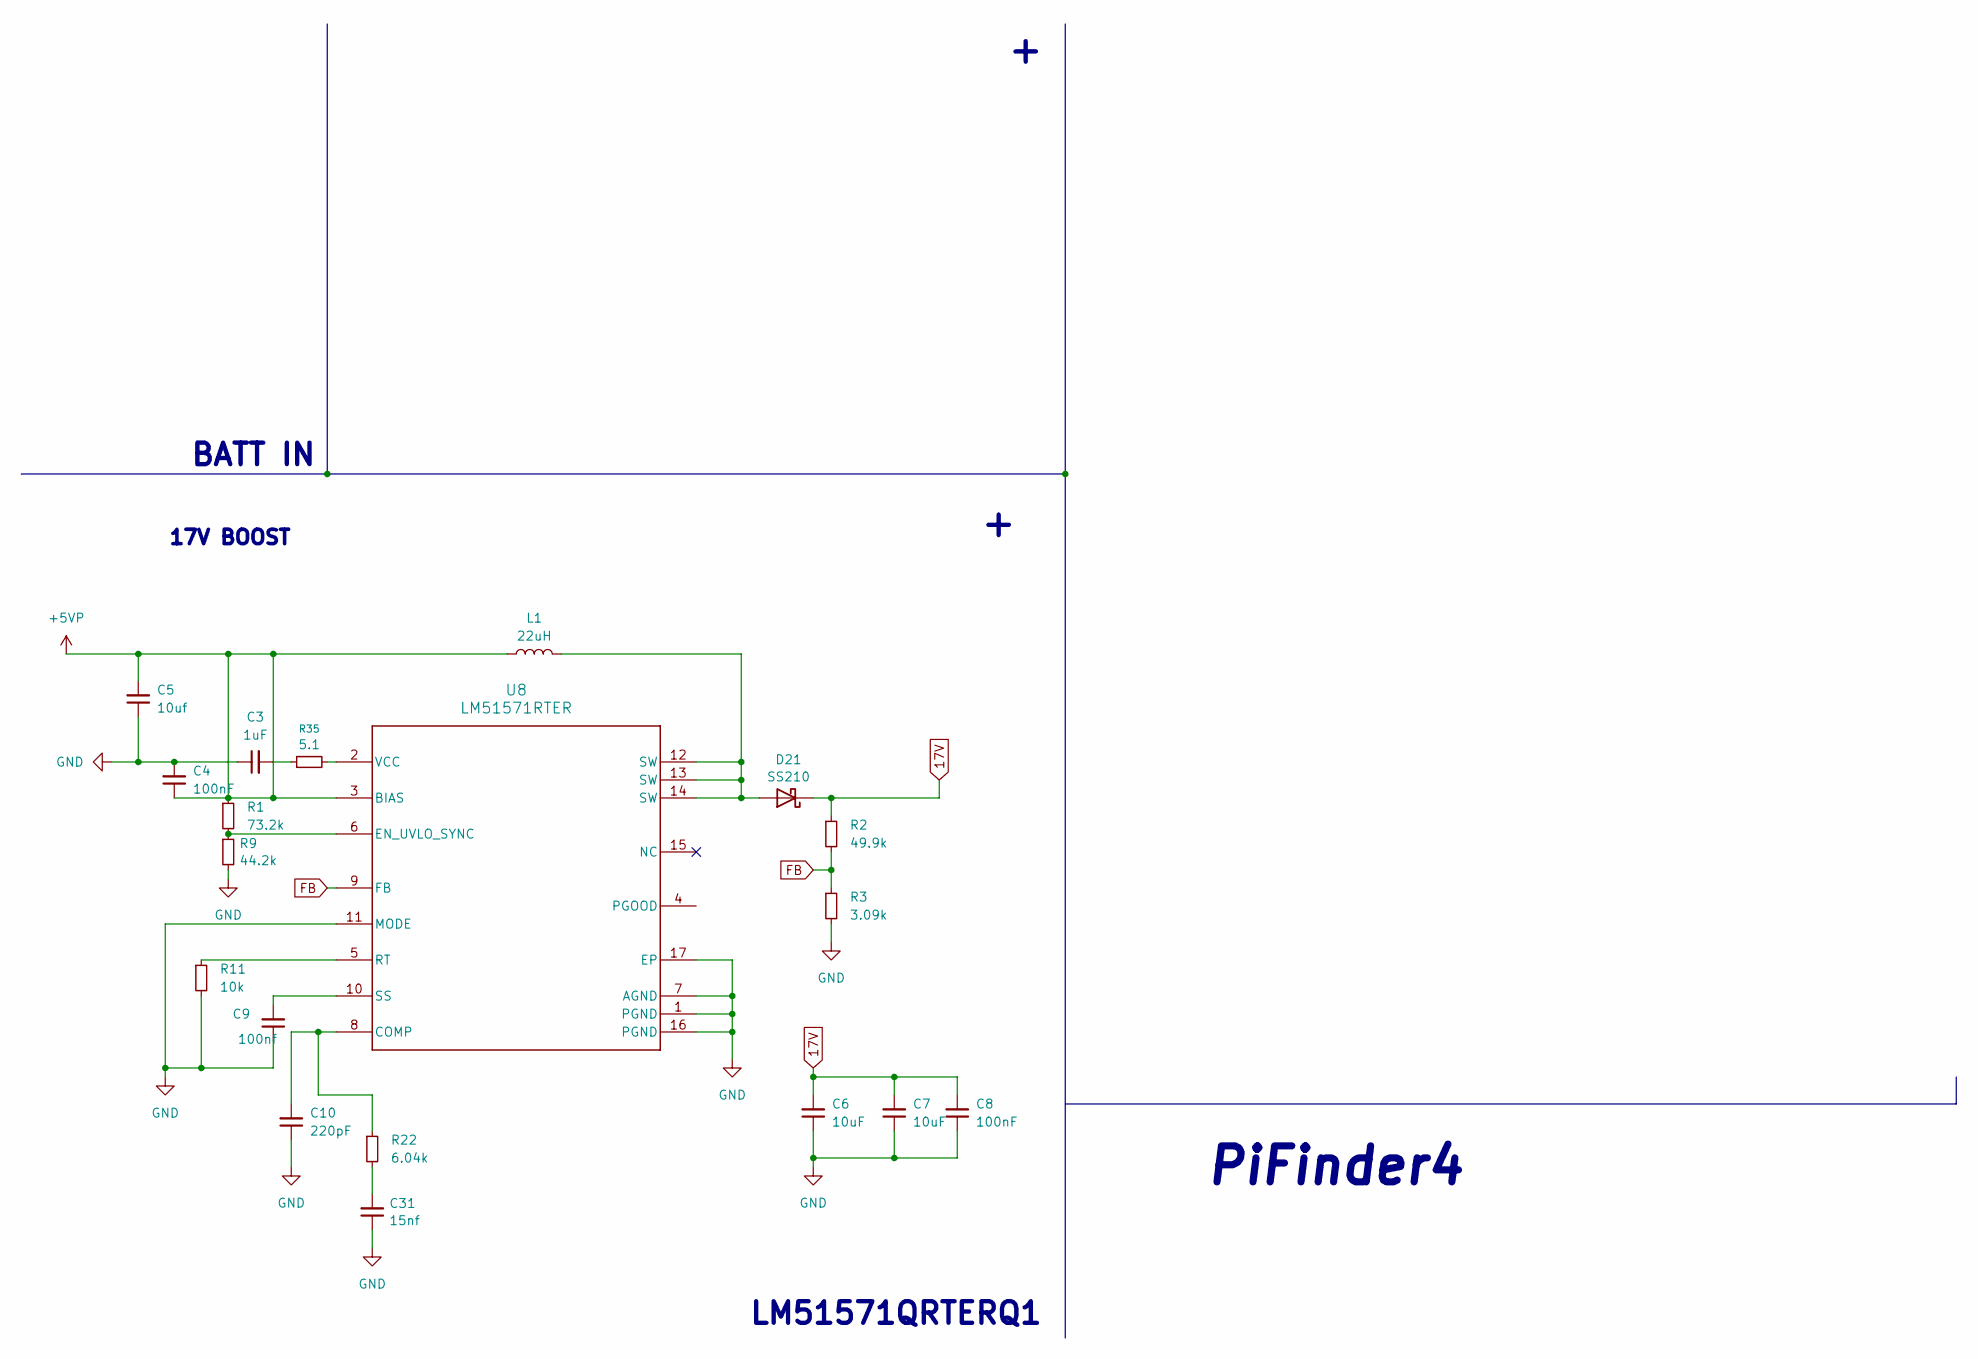
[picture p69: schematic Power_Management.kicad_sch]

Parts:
C3: 1uF; C_0603_1608Metric; LCSC C15849
C4, C8: 100nF; C_0603_1608Metric; LCSC C14663
C5: 10uf; C_0805_2012Metric; LCSC C15850
C6, C7: 10uF; C_1206_3216Metric; LCSC C13585
C9: 100nf; C_0603_1608Metric; LCSC C14663
C10: 220pF; C_0402_1005Metric; LCSC C1530
C31: 15nf; C_0402_1005Metric; LCSC C114405
D21: SS210; D_SMA; PARTREV 2; LCSC C14996
L1: 22uH; L_Wurth_WE-LQSH-3012; LCSC C41405943
R1: 73.2k; R_0402_1005Metric; LCSC C26986
R2: 49.9k; R_0402_1005Metric; LCSC C2906873
R3: 3.09k; R_0402_1005Metric; LCSC C11460
R9: 44.2k; R_0402_1005Metric; LCSC C25895
R11: 10k; R_0402_1005Metric; LCSC C25744
R22: 6.04k; R_0402_1005Metric; LCSC C97819
R35: 5.1; R_0402_1005Metric; LCSC C412902
U8: LM51571RTER; LM51571; LCSC C3188430

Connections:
17V: C6.2, C7.2, C8.2, D21.1 (K), R2.1; also elsewhere on the board
+5VP: C4.1, C5.2, L1.1, R1.1, U8.3 (BIAS); also elsewhere on the board
FB: R2.2, R3.1, U8.9 (FB)
GND: C3.1, C4.2, C5.1, C6.1, C7.1, C8.1, C9.1, C10.1, C31.1, R3.2, R9.2, R11.2, U8.1 (PGND), U8.7 (AGND), U8.11 (MODE), U8.16 (PGND), U8.17 (EP); also elsewhere on the board
unnamed: C3.2, R35.1
unnamed: C31.2, R22.2
unnamed: D21.2 (A), L1.2, U8.12 (SW), U8.13 (SW), U8.14 (SW)
unnamed: C10.2, R22.1, U8.8 (COMP)
unnamed: R1.2, R9.1, U8.6 (EN_UVLO_SYNC)
unnamed: R11.1, U8.5 (RT)
unnamed: C9.2, U8.10 (SS)
unnamed: R35.2, U8.2 (VCC)

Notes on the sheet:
17V BOOST
BATT IN
LM51571QRTERQ1
PiFinder4

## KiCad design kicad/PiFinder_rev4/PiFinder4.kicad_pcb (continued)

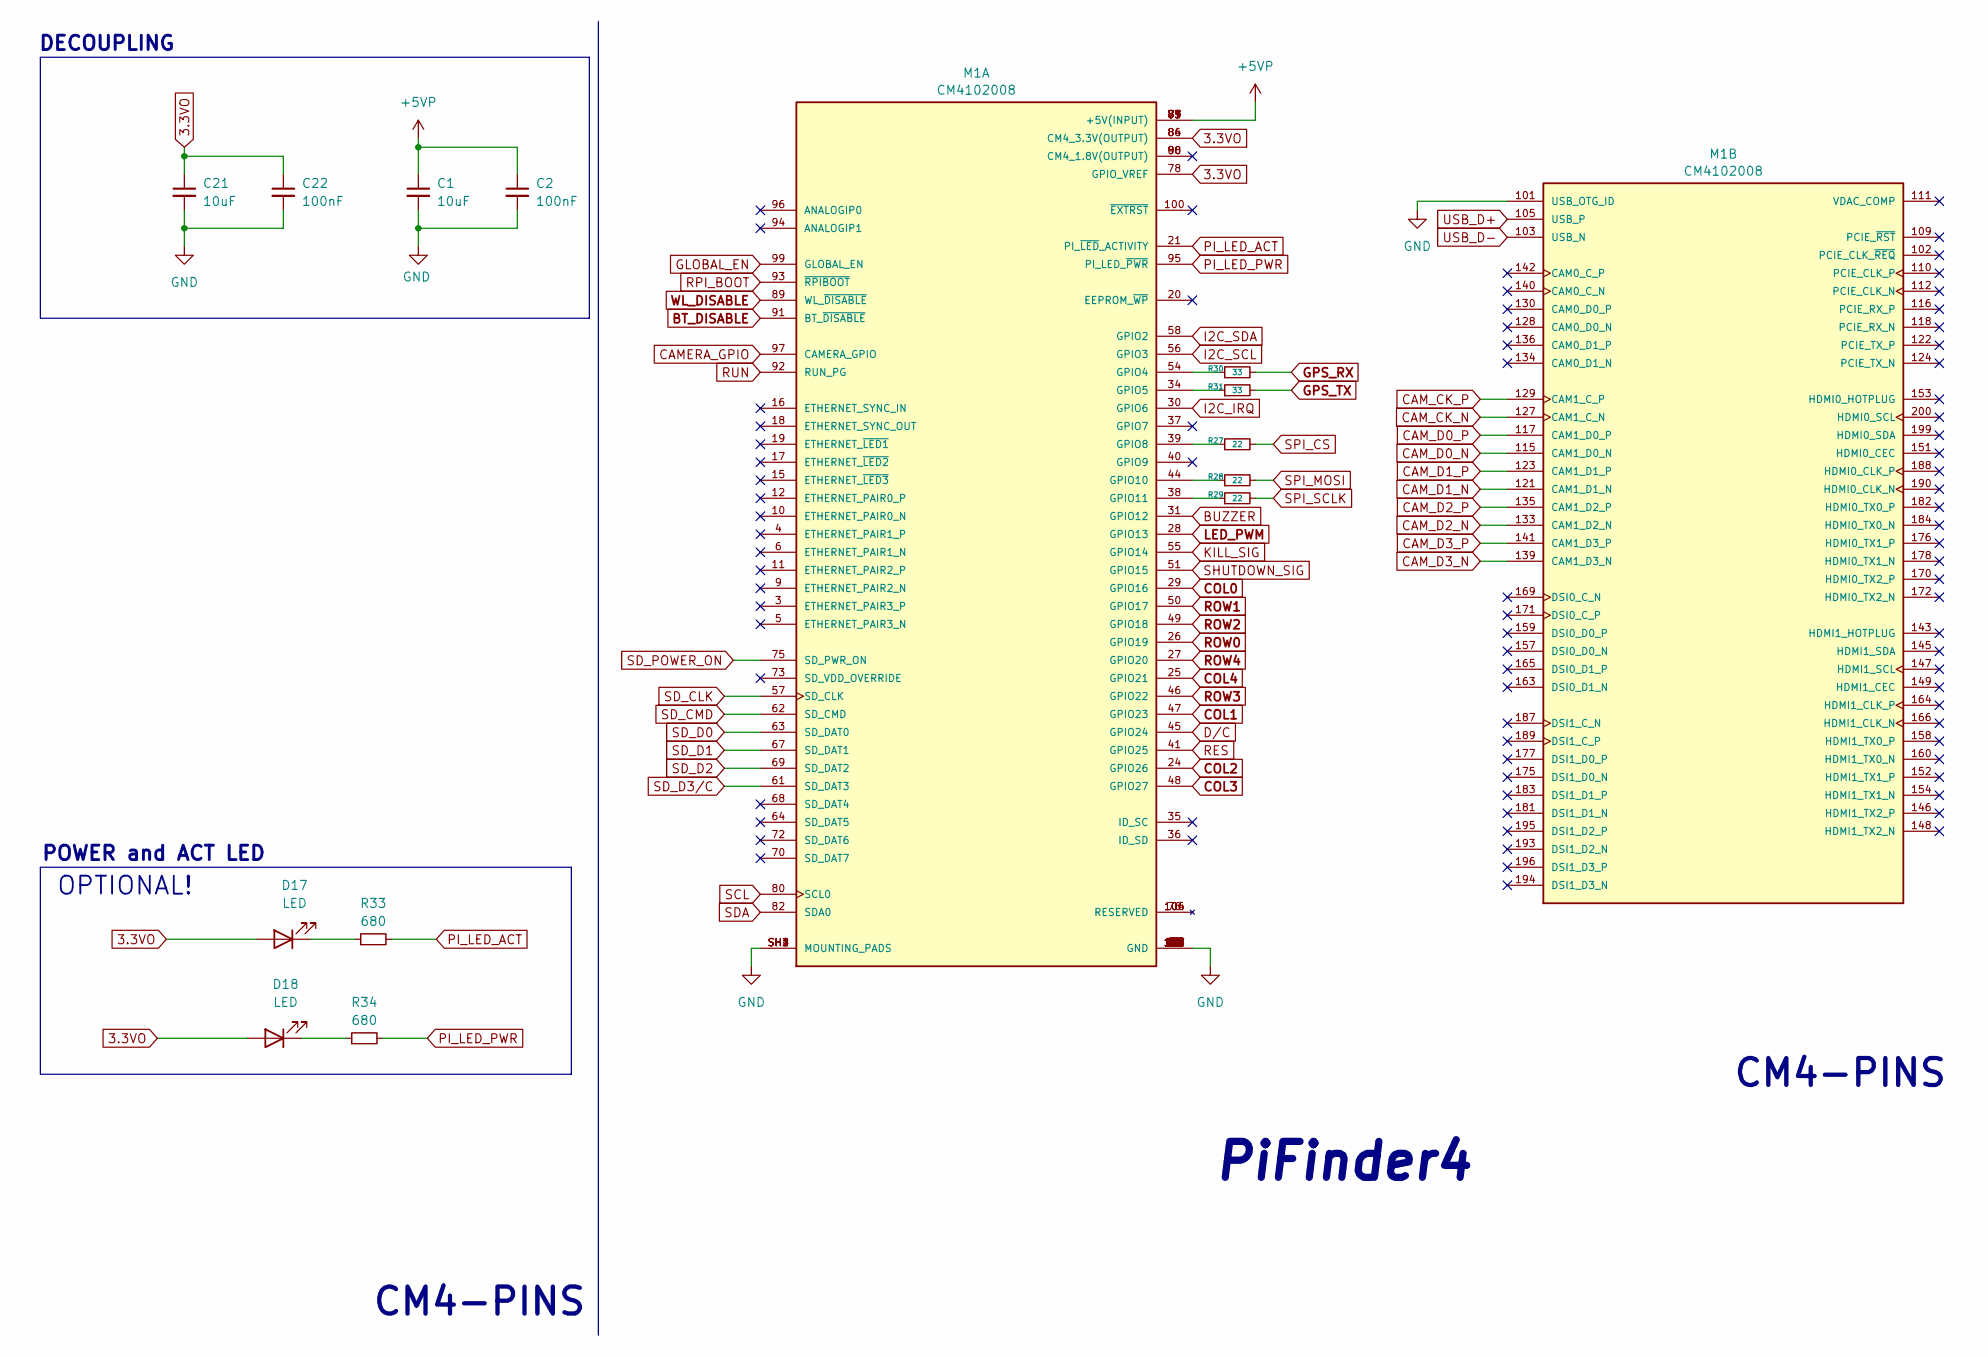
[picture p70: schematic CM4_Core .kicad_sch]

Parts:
C1: 10uF; C_0805_2012Metric; LCSC C15850
C2, C22: 100nF; C_0603_1608Metric; LCSC C14663
C21: 10uF; C_0603_1608Metric; LCSC C96446
D17, D18: LED; LED_1210_3225Metric; LCSC C264578
M1: CM4102008; MODULE_CM4102008; PARTREV 2021-10-12; LCSC C597931
R27, R28, R29: 22; R_0402_1005Metric; LCSC C25092
R30, R31: 33; R_0402_1005Metric; LCSC C25105
R33, R34: 680; R_0402_1005Metric; LCSC C137948

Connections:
3.3VO: C21.1, C22.1, D17.2 (A), D18.2 (A), M1.78 (GPIO_VREF), M1.84 (CM4_3.3V(OUTPUT)), M1.86 (CM4_3.3V(OUTPUT)); also elsewhere on the board
+5VP: C1.1, C2.1, M1.77 (+5V(INPUT)), M1.79 (+5V(INPUT)), M1.81 (+5V(INPUT)), M1.83 (+5V(INPUT)), M1.85 (+5V(INPUT)), M1.87 (+5V(INPUT)); also elsewhere on the board
BT_DISABLE: M1.91 (BT_~DISABLE)
BUZZER: M1.31 (GPIO12); also elsewhere on the board
CAMERA_GPIO: M1.97 (CAMERA_GPIO); also elsewhere on the board
CAM_CK_N: M1.127 (CAM1_C_N); also elsewhere on the board
CAM_CK_P: M1.129 (CAM1_C_P); also elsewhere on the board
CAM_D0_N: M1.115 (CAM1_D0_N); also elsewhere on the board
CAM_D0_P: M1.117 (CAM1_D0_P); also elsewhere on the board
CAM_D1_N: M1.121 (CAM1_D1_N); also elsewhere on the board
CAM_D1_P: M1.123 (CAM1_D1_P); also elsewhere on the board
CAM_D2_N: M1.133 (CAM1_D2_N); also elsewhere on the board
CAM_D2_P: M1.135 (CAM1_D2_P); also elsewhere on the board
CAM_D3_N: M1.139 (CAM1_D3_N); also elsewhere on the board
CAM_D3_P: M1.141 (CAM1_D3_P); also elsewhere on the board
COL0: M1.29 (GPIO16); also elsewhere on the board
COL1: M1.47 (GPIO23); also elsewhere on the board
COL2: M1.24 (GPIO26); also elsewhere on the board
COL3: M1.48 (GPIO27); also elsewhere on the board
COL4: M1.25 (GPIO21); also elsewhere on the board
D/C: M1.45 (GPIO24); also elsewhere on the board
GLOBAL_EN: M1.99 (GLOBAL_EN)
GND: C1.2, C2.2, C21.2, C22.2, M1.1 (GND), M1.2 (GND), M1.7 (GND), M1.8 (GND), M1.13 (GND), M1.14 (GND), M1.22 (GND), M1.23 (GND), M1.32 (GND), M1.33 (GND), M1.42 (GND), M1.43 (GND), M1.52 (GND), M1.53 (GND), M1.59 (GND), M1.60 (GND), M1.65 (GND), M1.66 (GND), M1.71 (GND), M1.74 (GND), M1.98 (GND), M1.101 (USB_OTG_ID), M1.107 (GND), M1.108 (GND), M1.113 (GND), M1.114 (GND), M1.119 (GND), M1.120 (GND), M1.125 (GND), M1.126 (GND), M1.131 (GND), M1.132 (GND), M1.137 (GND), M1.138 (GND), M1.144 (GND), M1.150 (GND), M1.155 (GND), M1.156 (GND), M1.161 (GND), M1.162 (GND), M1.167 (GND), M1.168 (GND), M1.173 (GND), M1.174 (GND), M1.179 (GND), M1.180 (GND), M1.185 (GND), M1.186 (GND), M1.191 (GND), M1.192 (GND), M1.197 (GND), M1.198 (GND), M1.SH1 (MOUNTING_PADS), M1.SH2 (MOUNTING_PADS), M1.SH3 (MOUNTING_PADS), M1.SH4 (MOUNTING_PADS); also elsewhere on the board
GPS_RX: R30.2; also elsewhere on the board
GPS_TX: R31.2; also elsewhere on the board
I2C_IRQ: M1.30 (GPIO6)
I2C_SCL: M1.56 (GPIO3); also elsewhere on the board
I2C_SDA: M1.58 (GPIO2); also elsewhere on the board
KILL_SIG: M1.55 (GPIO14); also elsewhere on the board
LED_PWM: M1.28 (GPIO13); also elsewhere on the board
unnamed: D17.1 (K), R33.1
unnamed: D18.1 (K), R34.1
unnamed: M1.54 (GPIO4), R30.1
unnamed: M1.34 (GPIO5), R31.1
unnamed: M1.39 (GPIO8), R27.1
unnamed: M1.44 (GPIO10), R28.1
unnamed: M1.38 (GPIO11), R29.1
PI_LED_ACT: M1.21 (PI_~LED_ACTIVITY), R33.2
PI_LED_PWR: M1.95 (PI_LED_~PWR), R34.2
RES: M1.41 (GPIO25); also elsewhere on the board
ROW0: M1.26 (GPIO19); also elsewhere on the board
ROW1: M1.50 (GPIO17); also elsewhere on the board
ROW2: M1.49 (GPIO18); also elsewhere on the board
ROW3: M1.46 (GPIO22); also elsewhere on the board
ROW4: M1.27 (GPIO20); also elsewhere on the board
RPI_BOOT: M1.93 (~RPIBOOT)
RUN: M1.92 (RUN_PG)
SCL: M1.80 (SCL0); also elsewhere on the board
SDA: M1.82 (SDA0); also elsewhere on the board
SD_CLK: M1.57 (SD_CLK); also elsewhere on the board
SD_CMD: M1.62 (SD_CMD); also elsewhere on the board
SD_D0: M1.63 (SD_DAT0); also elsewhere on the board
SD_D1: M1.67 (SD_DAT1); also elsewhere on the board
SD_D2: M1.69 (SD_DAT2); also elsewhere on the board
SD_D3/C: M1.61 (SD_DAT3); also elsewhere on the board
SD_POWER_ON: M1.75 (SD_PWR_ON); also elsewhere on the board
SHUTDOWN_SIG: M1.51 (GPIO15); also elsewhere on the board
SPI_CS: R27.2; also elsewhere on the board
SPI_MOSI: R28.2; also elsewhere on the board
SPI_SCLK: R29.2; also elsewhere on the board
USB_D+: M1.105 (USB_P); also elsewhere on the board
USB_D-: M1.103 (USB_N); also elsewhere on the board
WL_DISABLE: M1.89 (WL_~DISABLE)

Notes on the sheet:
CM4-PINS
DECOUPLING
POWER and ACT LED
OPTIONAL!
PiFinder4

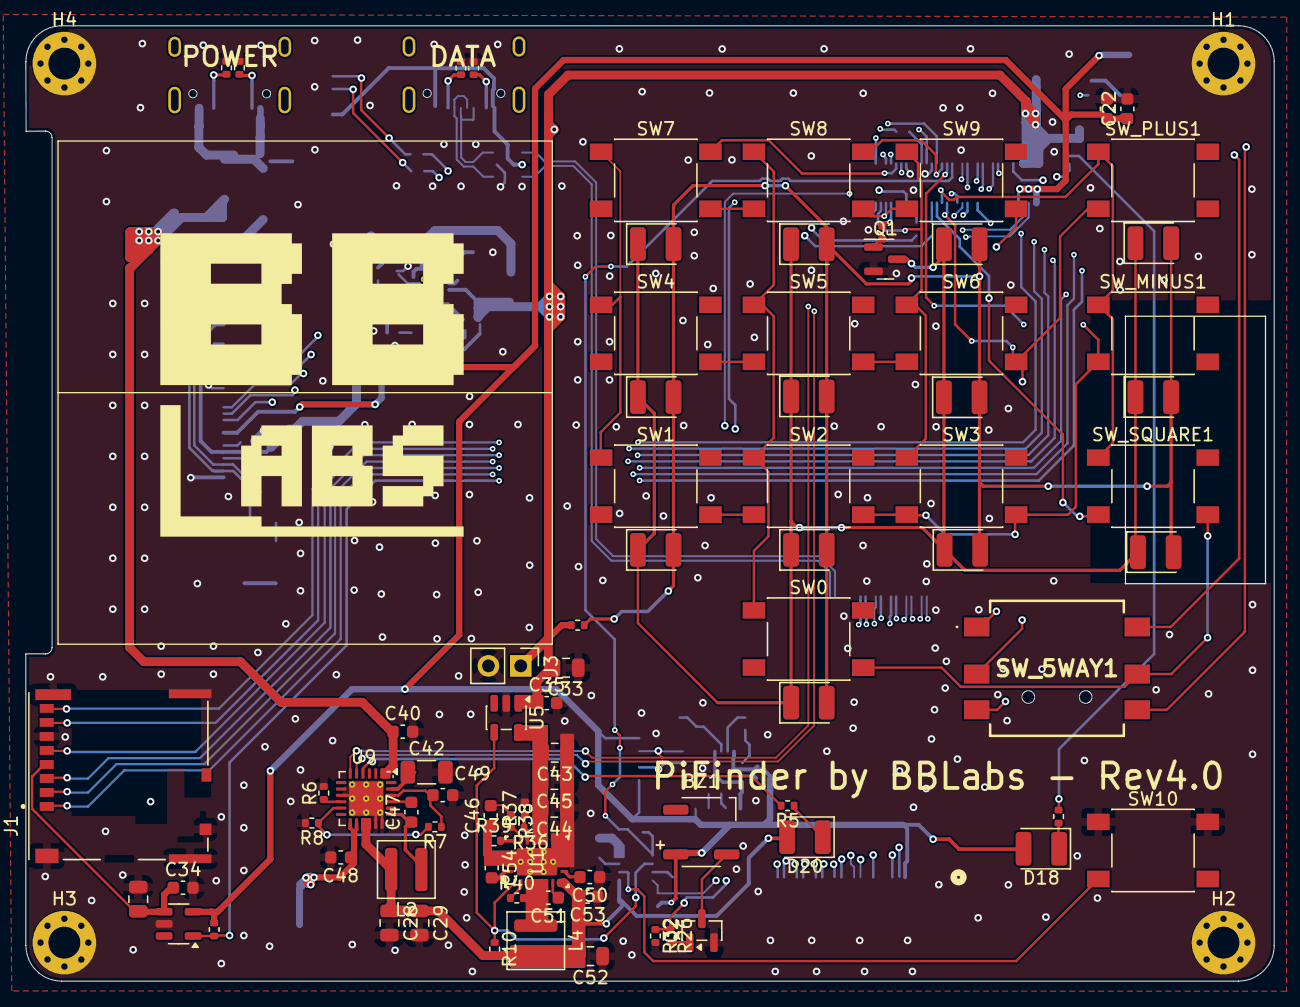
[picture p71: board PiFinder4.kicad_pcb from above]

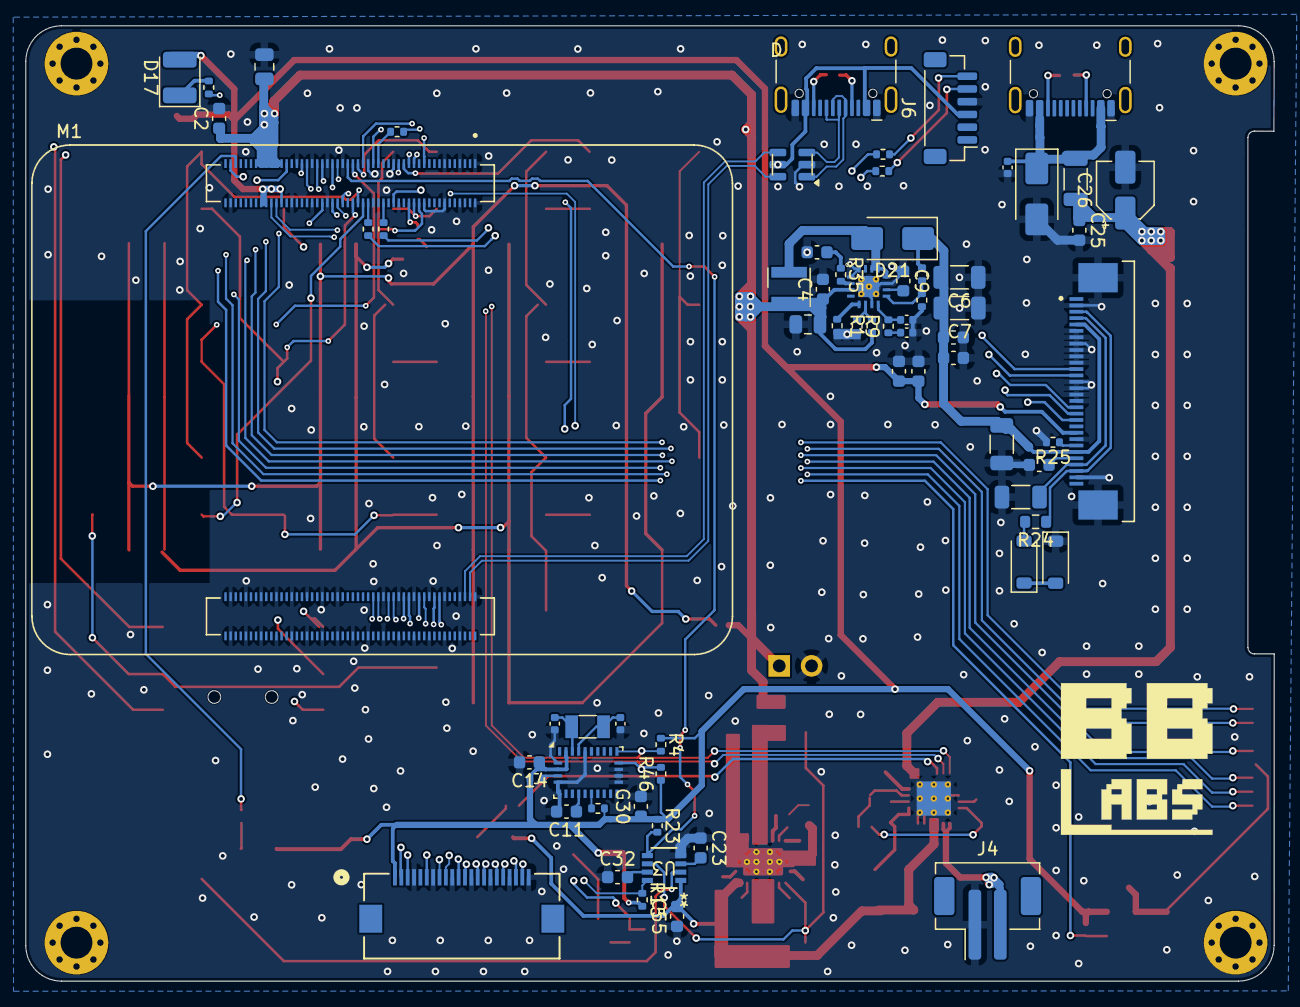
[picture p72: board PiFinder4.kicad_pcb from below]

Board: 4 copper layers, 98.0 x 75.0 mm, 155 parts (68 on the bottom side), 116 nets.

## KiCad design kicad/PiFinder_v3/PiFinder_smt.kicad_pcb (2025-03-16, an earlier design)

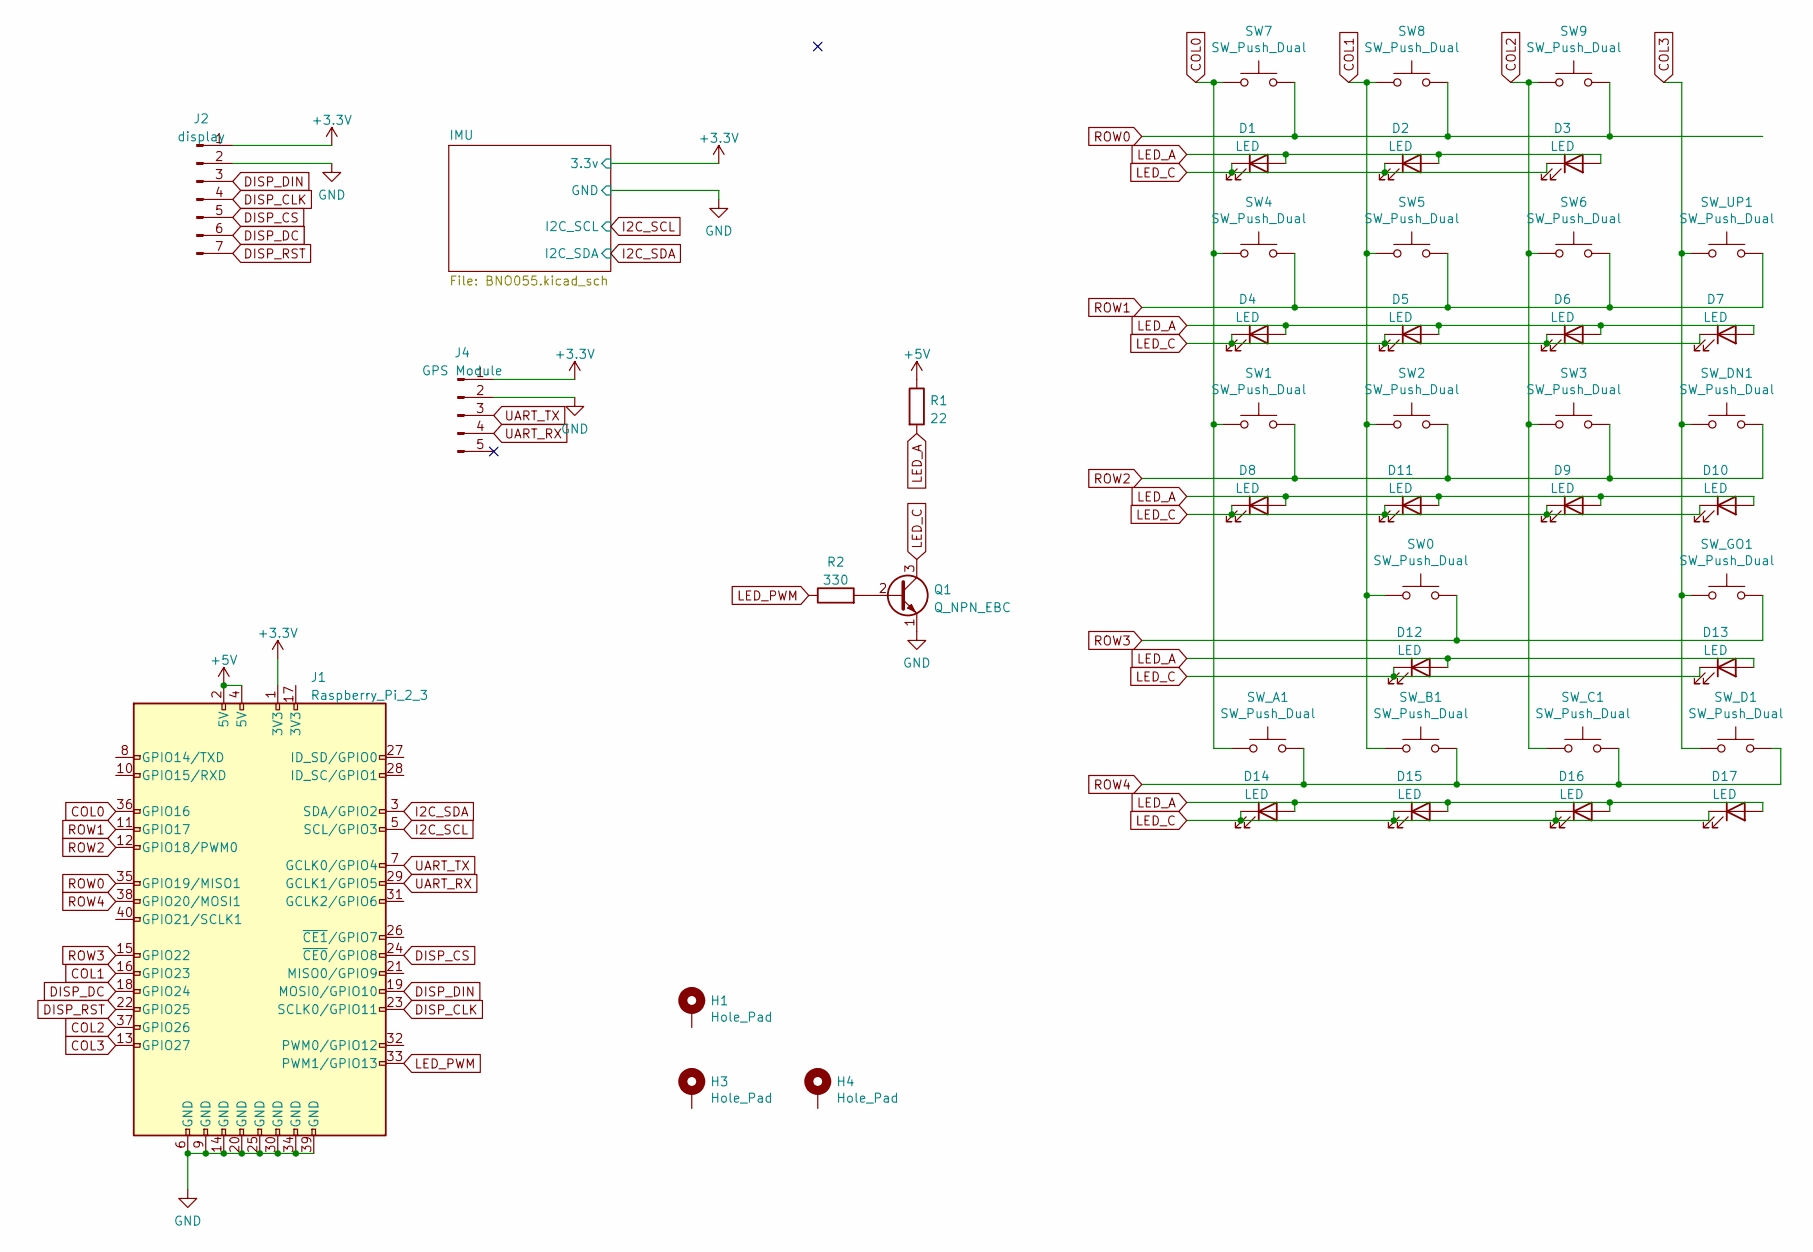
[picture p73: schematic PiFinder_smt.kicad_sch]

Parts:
D1, D2, D3, D4, D5, D6, D7, D8, D9, D10, D11, D12, D13, D14, D15, D16, D17: LED; LED_1210_3225Metric; LCSC C125112
H1, H3, H4: Hole_Pad; Mount_M2.5
J1: Raspberry_Pi_2_3; Pin_Header_Straight_2x20
J2: display; Waveshare1.5inOled_flushmount
J4: GPS Module; GT-U7_GPS_smt
Q1: Q_NPN_EBC; PF_SOT-23-NPN; LCSC C280842
R1: 22; R_0805_2012Metric; LCSC C17561
R2: 330; R_0805_2012Metric; LCSC C17630
SW0, SW1, SW2, SW3, SW4, SW5, SW6, SW7, SW8, SW9: SW_Push_Dual; SW_Push_6x6mm_SMT_withhole_tight; LCSC C4364377
SW_A1: SW_Push_Dual; SW_Push_6x6mm_SMT_withhole_tight; LCSC C4364377
SW_B1: SW_Push_Dual; SW_Push_6x6mm_SMT_withhole_tight; LCSC C4364377
SW_C1: SW_Push_Dual; SW_Push_6x6mm_SMT_withhole_tight; LCSC C4364377
SW_D1: SW_Push_Dual; SW_Push_6x6mm_SMT_withhole_tight; LCSC C4364377
SW_DN1: SW_Push_Dual; SW_Push_6x6mm_SMT_withhole_tight; LCSC C4364377
SW_GO1: SW_Push_Dual; SW_Push_6x6mm_SMT_withhole_tight; LCSC C4364377
SW_UP1: SW_Push_Dual; SW_Push_6x6mm_SMT_withhole_tight; LCSC C4364377

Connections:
+3.3V: J1.1 (3V3), J2.1, J4.1; also elsewhere on the board
+5V: J1.2 (5V), J1.4 (5V), R1.1
COL0: J1.36 (GPIO16), SW1.1, SW4.1, SW7.1, SW_A1.1
COL1: J1.16 (GPIO23), SW0.1, SW2.1, SW5.1, SW8.1, SW_B1.1
COL2: J1.37 (GPIO26), SW3.1, SW6.1, SW9.1, SW_C1.1
COL3: J1.13 (GPIO27), SW_D1.1, SW_DN1.1, SW_GO1.1, SW_UP1.1
DISP_CLK: J1.23 (SCLK0/GPIO11), J2.4
DISP_CS: J1.24 (~CE0/GPIO8), J2.5
DISP_DC: J1.18 (GPIO24), J2.6
DISP_DIN: J1.19 (MOSI0/GPIO10), J2.3
DISP_RST: J1.22 (GPIO25), J2.7
GND: J1.6 (GND), J1.9 (GND), J1.14 (GND), J1.20 (GND), J1.25 (GND), J1.30 (GND), J1.34 (GND), J1.39 (GND), J2.2, J4.2, Q1.1 (E); also elsewhere on the board
I2C_SCL: J1.5 (SCL/GPIO3); also elsewhere on the board
I2C_SDA: J1.3 (SDA/GPIO2); also elsewhere on the board
LED_A: D1.2 (A), D2.2 (A), D3.2 (A), D4.2 (A), D5.2 (A), D6.2 (A), D7.2 (A), D8.2 (A), D9.2 (A), D10.2 (A), D11.2 (A), D12.2 (A), D13.2 (A), D14.2 (A), D15.2 (A), D16.2 (A), D17.2 (A), R1.2
LED_C: D1.1 (K), D2.1 (K), D3.1 (K), D4.1 (K), D5.1 (K), D6.1 (K), D7.1 (K), D8.1 (K), D9.1 (K), D10.1 (K), D11.1 (K), D12.1 (K), D13.1 (K), D14.1 (K), D15.1 (K), D16.1 (K), D17.1 (K), Q1.3 (C)
LED_PWM: J1.33 (PWM1/GPIO13), R2.1
unnamed: Q1.2 (B), R2.2
ROW0: J1.35 (GPIO19/MISO1), SW7.2, SW8.2, SW9.2
ROW1: J1.11 (GPIO17), SW4.2, SW5.2, SW6.2, SW_UP1.2
ROW2: J1.12 (GPIO18/PWM0), SW1.2, SW2.2, SW3.2, SW_DN1.2
ROW3: J1.15 (GPIO22), SW0.2, SW_GO1.2
ROW4: J1.38 (GPIO20/MOSI1), SW_A1.2, SW_B1.2, SW_C1.2, SW_D1.2
UART_RX: J1.29 (GCLK1/GPIO5), J4.4
UART_TX: J1.7 (GCLK0/GPIO4), J4.3

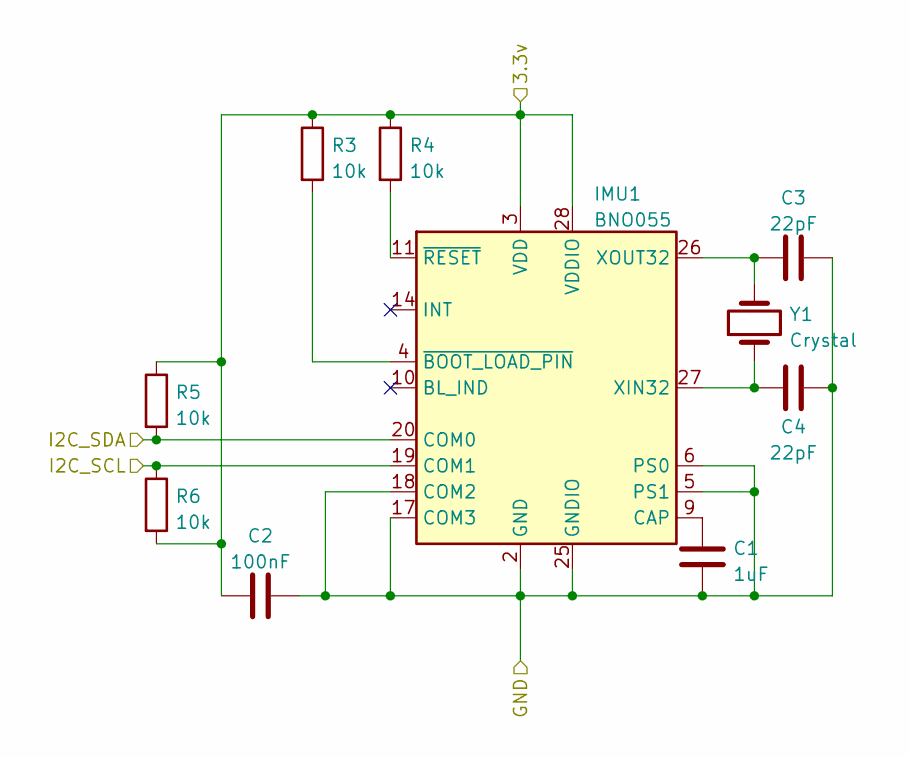
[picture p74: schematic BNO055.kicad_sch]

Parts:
C1: 1uF; C_0805_2012Metric; LCSC C2940738
C2: 100nF; C_0805_2012Metric; LCSC C49678
C3, C4: 22pF; C_0805_2012Metric; LCSC C24658
IMU1: BNO055; LGA-28_5.2x3.8mm_P0.5mm; LCSC C93216
R3, R4, R5, R6: 10k; R_0805_2012Metric; LCSC C17414
Y1: Crystal; Crystal_SMD_3215-2Pin_3.2x1.5mm; LCSC C5366532

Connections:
+3.3V: C2.1, IMU1.3 (VDD), IMU1.28 (VDDIO), R3.1, R4.1, R5.1, R6.2; also elsewhere on the board
GND: C1.2, C2.2, C3.2, C4.2, IMU1.2 (GND), IMU1.5 (PS1), IMU1.6 (PS0), IMU1.15 (GNDIO), IMU1.16 (GNDIO), IMU1.17 (COM3), IMU1.18 (COM2), IMU1.25 (GNDIO); also elsewhere on the board
I2C_SCL: IMU1.19 (COM1), R6.1; also elsewhere on the board
I2C_SDA: IMU1.20 (COM0), R5.2; also elsewhere on the board
unnamed: C1.1, IMU1.9 (CAP)
unnamed: C3.1, IMU1.26 (XOUT32), Y1.2
unnamed: C4.1, IMU1.27 (XIN32), Y1.1
unnamed: IMU1.4 (~BOOT_LOAD_PIN), R3.2
unnamed: IMU1.11 (~RESET), R4.2


Board: 2 copper layers, 93.8 x 64.2 mm, 53 parts (1 on the bottom side), 30 nets.

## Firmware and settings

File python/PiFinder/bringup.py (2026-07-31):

#!/usr/bin/python
# -*- coding:utf-8 -*-
"""
Bench validation for a freshly assembled PiFinder board — one command, one
screen, every listed subsystem exercised while the builder watches::

    python -m PiFinder.bringup

A **single process** that opens the panel directly, drives the keypad backlight
and buzzer, interrogates the IMU and charger, and scans the keypad matrix. It
does **not** boot the application: no ``SharedStateObj``, no catalogs, no
solver, no camera, no ``MenuManager``. It runs on a card with nothing
configured yet and is ready in about a second. Glossary:
``docs/ax/bringup/CONTEXT.md``.

Six **checks**, in three kinds — and the kind decides whether a check can gate
the **verdict**:

========= ========== ==========================================================
SCREEN    witnessed  Screen-proof patterns, then the dashboard — builder's eyes
BACKLIGHT witnessed  Continuous brightness ramp — the builder's eyes
BUZZER    witnessed  Startup earcon + one per keypress — the builder's ears
IMU       probed     BNO055 answers its chip id; the quaternion moves on tilt
CHARGER   probed     BQ25895 part-number register reads 0b111; voltages decode
SWITCHES  exercised  Every populated matrix position observed closing
========= ========== ==========================================================

Only **probed** and **exercised** checks gate the verdict and the exit status.
A witnessed check is reported as *emitted*: the program drove the hardware, and
whether light or sound came out is not something it can know.

Ending a run
------------

A run is open-ended; it ends on Ctrl-C, on ``--timeout``, or on the **power
hold** — the power switch held closed for :data:`SHUTDOWN_HOLD_SECONDS`, which
shuts the card down cleanly. That last one exists because a bring-up run
happens at a bench with no keyboard and no SSH session in sight: the board is
on a mat with a bare card in it, and pulling power on a mounted filesystem is
how a builder corrupts an image between the first board and the tenth.

*Tap* and *hold* therefore mean different things to the power switch, and both
are wanted: a tap is what the ``SWITCHES`` check needs (it registers the
closure like any other switch), and a hold ends the run. The power cell shows a
filling bar for the whole second so the boundary is visible and an accidental
hold can be released before it arms; ``--no-power-shutdown`` removes the
gesture for a builder who would rather not risk it at all.

The threshold matches ``keyboard_pi.run_keyboard``'s, which is also one second
— the same press ends a bring-up run and opens the shutdown menu in the running
application, so a builder learns the gesture once.

Why the panel is not auto-detected
----------------------------------

``main.py`` and ``splash.py`` pick their panel from ``hardware_detect``, which
probes for the BQ25895 charger: charger present means a rev4 board, so use the
176x176 SSD1333. That is exactly the wrong rule for a board under bring-up — a
dead or unsoldered charger would make a perfectly good screen look dead too,
and the builder would chase the wrong fault. So bring-up takes the panel from
the revision the *builder* declares (``--revision``, default rev4 -> SSD1333)
and never from a probe result, with ``--display`` to override outright. This
deviation is deliberate and is recorded here rather than in an ADR because it
is local to this tool: nothing in the running application depends on it.

Why nothing here is translated
------------------------------

Every other user-facing string in this repo goes through ``gettext``. These
deliberately do not, and the module never performs the ``_()`` install that
``main.py`` does — adding ``_()`` calls would ``NameError`` at runtime. The
audience for a bring-up run is the **builder** at the bench, not the
**observer** at the eyepiece.

Structure follows ``sound.py``'s discipline: pure logic separated from thin
hardware seams, so the interesting parts are unit-testable off-Pi and every
hardware import is lazy. ``import PiFinder.bringup`` and
``python -m PiFinder.bringup --help`` both work with no ``RPi.GPIO``, ``board``
or ``rpi_hardware_pwm`` installed.
"""

import argparse
import logging
import os
import signal
import subprocess
import time
from dataclasses import dataclass, field
from enum import Enum
from typing import (
    Callable,
    Dict,
    FrozenSet,
    List,
    Optional,
    Sequence,
    Set,
    Tuple,
    TypeVar,
)

from PIL import Image, ImageDraw

from PiFinder import displays, keypad, utils
from PiFinder.battery_bq25895 import EXPECTED_PN, REG14
from PiFinder.keyboard_interface import KeyboardInterface as K
from PiFinder.sound import MASTER_DUTY, BuzzerPWM, play_earcon
from PiFinder.types.hardware import BatteryState
from PiFinder.types.sound import Earcon
from PiFinder.ui.layout import BoxRow, StackedRows, center_box_row, rows_below_titlebar

logger = logging.getLogger("BringUp")

T = TypeVar("T")  # a hardware seam, for Hardware._open

# --- Board / card constants -------------------------------------------------

I2C_BUS_PATH = "/dev/i2c-1"

# Raspberry Pi OS moved config.txt when the boot partition was remounted at
# /boot/firmware; look for the new location first.
BOOT_CONFIG_PATHS = ("/boot/firmware/config.txt", "/boot/config.txt")

# Which GPIO each PWM channel has to reach for its consumer to work.
BUZZER_PWM_CHANNEL = 0
BUZZER_GPIO = 12
BACKLIGHT_PWM_CHANNEL = 1
BACKLIGHT_GPIO = 13

# Legal pin/function combinations per PWM channel, from the Raspberry Pi
# `pwm` / `pwm-2chan` overlay documentation. The overlay lines name a *pin*,
# not a channel, so this table is how a config.txt line is attributed.
PWM_CHANNEL_PINS: Dict[int, FrozenSet[int]] = {
    0: frozenset({12, 18, 40, 52}),
    1: frozenset({13, 19, 41, 45, 53}),
}

BACKLIGHT_PWM_HZ = 120  # matches main.init_keypad_pwm
# main.set_keypad_brightness documents 0-100 with an effective range of ~0-12.
# That comment predates rev4 -- retune with --backlight-max if the rev4 LEDs
# behave differently.
BACKLIGHT_MAX_DUTY = 12.0
BACKLIGHT_RAMP_SECONDS = 2.0

# Loop pacing. The scan sleeps a fixed period *after* its work rather than to a
# deadline, so the real scan rate sags toward ~40 Hz on the frames that also
# redraw -- still many times faster than a human press, which is all the switch
# check needs.
SCAN_HZ = 60
DRAW_HZ = 12  # redraw slower, to keep SPI traffic reasonable
BACKLIGHT_HZ = 30  # each step is a sysfs write; 30 Hz is already imperceptible
CHARGER_POLL_SECONDS = 1.0

PATTERN_SECONDS = 1.5  # per pattern; three of them
STATUS_ROWS = 3  # IMU / CHARGER / SWITCHES lines under the title bar

# How long the power switch must stay closed to end the run and shut the card
# down. One second, matching keyboard_pi.run_keyboard's power threshold, so the
# gesture is the same one the finished unit answers to.
SHUTDOWN_HOLD_SECONDS = 1.0
# Segments in the hold bar drawn in the power cell. Four puts the label at six
# characters ("[####]"), which is 30 px in the 34 px power cell on the
# narrowest panel bring-up supports -- see test_bringup.
HOLD_BAR_SEGMENTS = 4
# The clean-shutdown command, spelled out rather than imported: see
# request_shutdown.
SHUTDOWN_COMMAND = ("sudo", "shutdown", "now")

DEFAULT_REVISION = "rev4"
# Panel per revision. Keyed by keypad.POPULATION_MAPS, which is where the set of
# known revisions lives -- --revision reads its choices from there, so the two
# registries cannot list different revisions. Unknown revisions fall back to the
# 128x128 panel.
REVISION_PANELS = {"rev3": "ssd1351", "rev4": "ssd1333"}
FALLBACK_PANEL = "ssd1351"
# Hand-copied from displays.get_display's if-chain (there is no registry to read
# it from). test_bringup keeps the copy honest in both directions.
DISPLAY_NAMES = (
    "ssd1333",
    "ssd1351",
    "st7789",
    "pg_128",
    "pg_176",
    "pg_320",
    "headless",
    "headless_176",
    "headless_320",
)

# Check names, so the seams and the report can't drift apart.
SCREEN = "SCREEN"
BACKLIGHT = "BACKLIGHT"
BUZZER = "BUZZER"
IMU = "IMU"
CHARGER = "CHARGER"
SWITCHES = "SWITCHES"


# ---------------------------------------------------------------------------
# Pure logic (no hardware, no sleep -- the unit-test targets)
# ---------------------------------------------------------------------------


class Kind(str, Enum):
    """What a check's answer is worth. See the glossary."""

    PROBED = "probed"  # the program asked the part directly
    EXERCISED = "exercised"  # the builder drove it, the program confirmed it
    WITNESSED = "witnessed"  # the program emitted, the builder is the sensor

    @property
    def gates(self) -> bool:
        """Whether this kind may contribute to the verdict."""
        return self in (Kind.PROBED, Kind.EXERCISED)


class Status(str, Enum):
    PASS = "PASS"
    FAIL = "FAIL"
    EMITTED = "emitted"  # witnessed only: the program drove the hardware
    SKIPPED = "skipped"  # could not run -- usually a failed pre-flight


@dataclass(frozen=True)
class CheckResult:
    """One named check's outcome.

    The constructor enforces the invariant the verdict rests on: a witnessed
    check can never carry PASS or FAIL, because "the buzzer passed" is not
    something the program is in a position to say.
    """

    name: str
    kind: Kind
    status: Status
    detail: str = ""

    def __post_init__(self) -> None:
        if self.kind is Kind.WITNESSED:
            if self.status not in (Status.EMITTED, Status.SKIPPED):
                raise ValueError(
                    f"witnessed check {self.name} cannot be {self.status.value}"
                )
        elif self.status is Status.EMITTED:
            raise ValueError(f"{self.kind.value} check {self.name} cannot be emitted")


def compute_verdict(results: Sequence[CheckResult]) -> bool:
    """The run's overall result: True only when every **gating** check passed.

    Witnessed checks are excluded by construction — they can only be EMITTED or
    SKIPPED, neither of which is PASS — so adding or removing them never moves
    the verdict. A gating check that was SKIPPED (a failed pre-flight
    invalidated it) does not pass either: the run did not verify that part, and
    saying PASS would claim it did. PURE.
    """
    gating = [result for result in results if result.kind.gates]
    if not gating:
        return False  # nothing was verified; that is not a pass
    return all(result.status is Status.PASS for result in gating)


def parse_pwm_overlay(config_txt: str) -> Dict[int, int]:
    """Map PWM channel -> GPIO pin, as provisioned by a ``config.txt``. PURE.

    The overlays name a pin, not a channel::

        dtoverlay=pwm,pin=13,func=4                        -> {1: 13}
        dtoverlay=pwm-2chan,pin=12,func=4,pin2=13,func2=4  -> {0: 12, 1: 13}

    so a pin is attributed to a channel through :data:`PWM_CHANNEL_PINS`.
    A channel absent from the result is exported by the kernel but muxed to no
    pin — which is the whole reason this check exists:
    ``HardwarePWM(pwm_channel=0)`` then succeeds and drives nothing, a silence
    indistinguishable from a dead buzzer.

    Commented-out lines are ignored, and a later line for the same channel
    wins, mirroring how the firmware applies overlays in order.
    """
    routing: Dict[int, int] = {}
    for raw_line in config_txt.splitlines():
        line = raw_line.split("#", 1)[0].strip()
        if not line.startswith("dtoverlay="):
            continue
        fields = line[len("dtoverlay=") :].split(",")
        overlay = fields[0].strip()
        if overlay not in ("pwm", "pwm-2chan"):
            continue

        params: Dict[str, str] = {}
        for param in fields[1:]:
            if "=" in param:
                key, value = param.split("=", 1)
                params[key.strip()] = value.strip()

        # Overlay defaults: `pwm` defaults to pin 12, `pwm-2chan` to 12 and 13.
        pins = [params.get("pin", "12")]
        if overlay == "pwm-2chan":
            pins.append(params.get("pin2", "13"))

        for pin_text in pins:
            try:
                pin = int(pin_text)
            except ValueError:
                continue
            for channel, legal_pins in PWM_CHANNEL_PINS.items():
                if pin in legal_pins:
                    routing[channel] = pin
    return routing


@dataclass
class Preflight:
    """What the **card** has been provisioned with, as opposed to what the
    **board** carries.

    Reported on its own line and before anything else, because a failed
    pre-flight *invalidates* the checks that depend on it — and a
    misprovisioned image diagnosed as a bad board gets a good part desoldered.
    """

    i2c_bus_present: bool
    config_path: Optional[str]
    pwm_routing: Dict[int, int] = field(default_factory=dict)

    def _routed(self, channel: int, gpio: int) -> Optional[bool]:
        """True / False, or None when there is no config.txt to read."""
        if self.config_path is None:
            return None
        return self.pwm_routing.get(channel) == gpio

    @property
    def buzzer_routed(self) -> Optional[bool]:
        return self._routed(BUZZER_PWM_CHANNEL, BUZZER_GPIO)

    @property
    def backlight_routed(self) -> Optional[bool]:
        return self._routed(BACKLIGHT_PWM_CHANNEL, BACKLIGHT_GPIO)


def format_preflight(preflight: Preflight) -> str:
    """One line summarising the card's provisioning. PURE."""

    def routing(label: str, channel: int, gpio: int, routed: Optional[bool]) -> str:
        target = f"pwm ch{channel}->gpio{gpio} ({label})"
        if routed is None:
            return f"{target} UNKNOWN"
        return f"{target} {'ok' if routed else 'NOT ROUTED'}"

    parts = [f"i2c-1 {'ok' if preflight.i2c_bus_present else 'MISSING'}"]
    parts.append(
        routing(
            "backlight",
            BACKLIGHT_PWM_CHANNEL,
            BACKLIGHT_GPIO,
            preflight.backlight_routed,
        )
    )
    parts.append(
        routing("buzzer", BUZZER_PWM_CHANNEL, BUZZER_GPIO, preflight.buzzer_routed)
    )
    if preflight.config_path is None:
        parts.append("no config.txt found")
    return f"{'PRE-FLIGHT':<11} " + " | ".join(parts)


def read_preflight() -> Preflight:
    """Inspect the card. The only impure part is reading two files."""
    config_path: Optional[str] = None
    config_txt = ""
    for candidate in BOOT_CONFIG_PATHS:
        try:
            with open(candidate, "r") as config_file:
                config_txt = config_file.read()
            config_path = candidate
            break
        except OSError:
            continue
    return Preflight(
        i2c_bus_present=os.path.exists(I2C_BUS_PATH),
        config_path=config_path,
        pwm_routing=parse_pwm_overlay(config_txt),
    )


def backlight_duty(
    elapsed: float,
    period: float = BACKLIGHT_RAMP_SECONDS,
    ceiling: float = BACKLIGHT_MAX_DUTY,
) -> float:
    """Duty cycle (%) for the backlight ramp at ``elapsed`` seconds in. PURE.

    A triangle wave, 0 -> ceiling -> 0 every ``period``. A sweep beats a static
    level: a dim or partially-lit LED string is obvious against a ramp and
    invisible against a fixed brightness.
    """
    if period <= 0:
        return ceiling
    phase = (elapsed % period) / period
    return ceiling * (2 * phase if phase < 0.5 else 2 * (1 - phase))


Position = Tuple[int, int]


@dataclass(frozen=True)
class Edges:
    """What changed between two scans."""

    pressed: FrozenSet[Position]
    released: FrozenSet[Position]
    power_pressed: bool
    power_released: bool

    @property
    def any_pressed(self) -> bool:
        return bool(self.pressed) or self.power_pressed


class GridState:
    """Which switches have been observed closing, and which are closed now.

    Separating **held** from **seen** is deliberate. A position that reads
    permanently closed is a solder bridge; a position that closes but never
    releases is a mechanical fault. Both are build defects that a press-counter
    alone would score as a pass, and both are obvious at a glance on the grid.

    ``seen`` records raw truth, including closures at positions the population
    map says are *unpopulated* — a miswired or ghosting matrix. Those don't
    fail the run (the map, not the board, may be what is wrong) but they are
    reported, which is how a disputed population map gets settled at the bench.
    """

    def __init__(self, populated: FrozenSet[Position]):
        self.populated = frozenset(populated)
        self.seen: Set[Position] = set()
        self.held: Set[Position] = set()
        self.power_seen = False
        self.power_held = False

    def update(self, closed: Set[Position], power_closed: bool = False) -> Edges:
        """Feed one scan; return the press / release edges it produced."""
        now_closed = set(closed)
        pressed = frozenset(now_closed - self.held)
        released = frozenset(self.held - now_closed)
        self.held = now_closed
        self.seen |= now_closed

        power_pressed = power_closed and not self.power_held
        power_released = self.power_held and not power_closed
        self.power_held = power_closed
        self.power_seen = self.power_seen or power_closed

        return Edges(
            pressed=pressed,
            released=released,
            power_pressed=power_pressed,
            power_released=power_released,
        )

    @property
    def missing(self) -> FrozenSet[Position]:
        """Populated positions never observed closing."""
        return self.populated - self.seen

    @property
    def unexpected(self) -> FrozenSet[Position]:
        """Positions that closed although the population map has no switch
        there — a miswire, a ghost, or a wrong population map."""
        return frozenset(self.seen - self.populated)

    @property
    def seen_count(self) -> int:
        return len(self.populated & self.seen)

    @property
    def expected_count(self) -> int:
        return len(self.populated)

    @property
    def complete(self) -> bool:
        """Every populated switch closed at least once, power included."""
        return not self.missing and self.power_seen


class PowerHold:
    """How long the power switch has been closed, and whether that has crossed
    the shutdown threshold. PURE — the clock is injected.

    Kept apart from :class:`GridState`, which records what the *switch check*
    saw: a closure is a closure there whether it lasted 20 ms or 20 s, and
    folding the gesture in would let "the builder is shutting down" and "the
    power switch conducts" turn into one flag. They are separate findings.

    Rearms on release, so a hold that is let go re-arms rather than firing
    again on the next scan, and a held-down (or shorted) power line fires
    exactly once instead of every frame for the rest of the run.
    """

    def __init__(
        self, threshold: float = SHUTDOWN_HOLD_SECONDS, enabled: bool = True
    ) -> None:
        self.threshold = threshold
        self.enabled = enabled
        self.progress = 0.0  # 0.0 -> 1.0 across the hold; 0.0 while open
        self._since: Optional[float] = None
        self._fired = False

    def update(self, closed: bool, now: float) -> bool:
        """Feed one scan; True on the single frame the hold arms."""
        if not closed:
            self._since = None
            self._fired = False
            self.progress = 0.0
            return False

        if self._since is None:
            self._since = now
        if not self.enabled:
            # No bar either: a run with the gesture off must not draw something
            # that looks like it is about to arm.
            self.progress = 0.0
            return False

        elapsed = now - self._since
        self.progress = (
            1.0 if self.threshold <= 0 else min(1.0, elapsed / self.threshold)
        )
        if self._fired or elapsed < self.threshold:
            return False
        self._fired = True
        return True


# --- Labels -----------------------------------------------------------------

# One character per key, for the grid cells. ASCII on purpose: the UI fonts
# carry no box-drawing glyphs, and a builder reads these at ~10 px.
KEY_LABELS = {
    K.UP: "^",
    K.DOWN: "v",
    K.LEFT: "<",
    K.RIGHT: ">",
    K.PLUS: "+",
    K.MINUS: "-",
    K.SQUARE: "#",
}

KEY_NAMES = {
    K.PLUS: "PLUS",
    K.MINUS: "MINUS",
    K.SQUARE: "SQUARE",
    K.LEFT: "LEFT",
    K.UP: "UP",
    K.DOWN: "DOWN",
    K.RIGHT: "RIGHT",
}


def cell_label(row: int, col: int) -> str:
    """The one-character grid label for a matrix position ("" for a hole)."""
    key = keypad.key_at(row, col)
    if key == K.NA:
        return ""
    return KEY_LABELS.get(key, str(key))


def power_cell_label(progress: float) -> str:
    """The power cell's label: ``PWR`` at rest, a hold bar while held. PURE.

    Feedback has to survive a 10 px cell on the 128 px panel, where the small
    font is 9 px tall and leaves no room to draw a progress bar *under* the
    text. So the bar **is** the text, rendered by the same centred-label path
    every other cell uses — nothing new in the draw path, and it lays out
    identically on all three panels.

    The hold maps onto *one segment to full*, not zero to full. One segment
    lights on the first frame the switch closes, because the bar's job is to
    say "this is going somewhere" while there is still nearly a second left to
    let go — and the last segment lights only at the threshold itself, so a
    full bar never sits there for a quarter of the hold implying more time
    remains than there is.
    """
    if progress <= 0.0:
        return "PWR"
    filled = min(HOLD_BAR_SEGMENTS, 1 + int(progress * (HOLD_BAR_SEGMENTS - 1)))
    return "[" + "#" * filled + "-" * (HOLD_BAR_SEGMENTS - filled) + "]"
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

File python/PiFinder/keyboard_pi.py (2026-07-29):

#!/usr/bin/python
# -*- coding:utf-8 -*-
"""
This module is runs the keyboard matrix
and adds keys to the provided queue

"""

from time import sleep, time
import libinput
from PiFinder import keypad
from PiFinder.keyboard_interface import KeyboardInterface
import RPi.GPIO as GPIO
import logging
from PiFinder.multiproclogging import MultiprocLogging

logger = logging.getLogger("Keyboard.Pi")


class KeyboardPi(KeyboardInterface):
    def __init__(self, q):
        self.q = q

        # Matrix wiring and keymaps live in PiFinder.keypad, which is
        # import-safe (no RPi.GPIO / libinput) so bring-up and the unit tests
        # can read the same tables this scanner runs on.
        self.cols = keypad.MATRIX_COLS
        self.rows = keypad.MATRIX_ROWS
        self.power_gpio = keypad.POWER_GPIO

        # Timer for power-off debounce, and latch so we only emit
        # one POWER_BTN per physical press
        self.power_press_time = 0
        self.power_sent = False

        self.keymap = keypad.KEYMAP
        # If SQUARE is pressed together with key, ALT_<key> is sent
        self.alt_keymap = keypad.ALT_KEYMAP
        self.long_keymap = keypad.LONG_KEYMAP

        # Derive keycodes from the keymap so they track the matrix layout
        # (cols/rows) rather than being hard-coded. SQUARE is the brightness/
        # alt-chord modifier; the d-pad up/down buttons auto-repeat when held.
        self.square_keycodes = {
            i for i, v in enumerate(self.keymap) if v == self.SQUARE
        }
        self.repeat_keycodes = {
            i for i, v in enumerate(self.keymap) if v in (self.UP, self.DOWN)
        }

        # physical keyboard support init
        self.li_kb = libinput.LibInput(context_type=libinput.ContextType.UDEV)
        self.li_kb.assign_seat("seat0")

    def get_keyboard_key(self) -> int:
        """
        Checks libinput keyboard, if keyrelesed
        map to our keycode and return

        Returns 0 for no key registered
        """
        key_mapping: dict[int, int] = {
            103: self.UP,
            108: self.DOWN,
            105: self.LEFT,
            106: self.RIGHT,
            28: self.SQUARE,
            78: self.MINUS,
            74: self.PLUS,
        }

        while True:
            while True:
                self.li_kb._libinput.libinput_dispatch(self.li_kb._li)
                hevent = self.li_kb._libinput.libinput_get_event(self.li_kb._li)
                if not hevent:
                    return 0
                type_ = self.li_kb._libinput.libinput_event_get_type(hevent)

                if type_.is_keyboard():
                    kbev = libinput.KeyboardEvent(hevent, self.li_kb._libinput)
                    if kbev.key_state == libinput.constant.KeyState.RELEASED:
                        return key_mapping.get(kbev.key, 0)

    def run_keyboard(self, log_queue):
        """
        scans keyboard matrix, puts release events in queue
        """
        MultiprocLogging.configurer(log_queue)

        GPIO.setmode(GPIO.BCM)
        GPIO.setup(self.rows, GPIO.IN)
        GPIO.setup(self.cols, GPIO.IN, pull_up_down=GPIO.PUD_UP)

        # Setup power GPIO, no pullup needed, has it's own
        GPIO.setup(self.power_gpio, GPIO.IN)

        pressed = set()
        alt_sent = False
        hold_counter = 0
        hold_sent = False
        scan_freq = 60
        while True:
            # Check physical keyboard
            if keyboard_key := self.get_keyboard_key():
                self.q.put(keyboard_key)
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

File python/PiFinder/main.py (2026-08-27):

#!/usr/bin/python
# -*- coding:utf-8 -*-
"""
This module is the main entry point for PiFinder it:
* Initializes the display
* Spawns keyboard process
* Sets up time/location via GPS
* Spawns camers/solver process
* then runs the UI loop

"""

import gettext

import os

# skyfield performance fix, see: https://rhodesmill.org/skyfield/accuracy-efficiency.html
os.environ["OPENBLAS_NUM_THREADS"] = "1"
os.environ["MKL_NUM_THREADS"] = "1"
import time
import queue
import datetime
import json
import uuid
import logging
import argparse
import pickle
from pathlib import Path
from PIL import Image, ImageOps
from multiprocessing import Process, Queue
from multiprocessing.managers import BaseManager

import PiFinder.i18n  # noqa: F401
from PiFinder import solver
from PiFinder import config
from PiFinder import pos_server
from PiFinder import utils
from PiFinder import server
from PiFinder import timez
from PiFinder import keyboard_interface
import PiFinder.sound as sound
from PiFinder.types.sound import Earcon, SetVolume
from PiFinder.battery_bq25895 import (
    POLL_INTERVAL as BATTERY_POLL_INTERVAL,
    LowBatteryWarner,
)

from PiFinder.multiproclogging import MultiprocLogging
from PiFinder.catalogs import CatalogBuilder, CatalogFilter, Catalogs
from PiFinder.calc_utils import sf_utils
from PiFinder.state_utils import sleep_for_framerate

from PiFinder.ui.console import UIConsole
from PiFinder.ui.menu_manager import MenuManager

from PiFinder.state import SharedStateObj, UIState

from PiFinder.image_util import subtract_background

from PiFinder.displays import DisplayBase, get_display

import PiFinder.manager_patch as patch

from typing import Any, Optional, TYPE_CHECKING

# Mypy i8n fix
if TYPE_CHECKING:

    def _(a) -> Any:
        return a


logger = logging.getLogger("main")

hardware_platform = "Pi"
display_hardware = "SSD1351"
display_device: DisplayBase = DisplayBase()
keypad_pwm = None


def init_keypad_pwm():
    # TODO: Keypad pwm class that can be faked maybe?
    global keypad_pwm
    global hardware_platform
    if hardware_platform == "Pi":
        keypad_pwm = HardwarePWM(pwm_channel=1, hz=120)
        keypad_pwm.start(0)


def set_keypad_brightness(percentage: float):
    """
    keypad brightness between 0-100, although effective range seems 0-12
    """
    global keypad_pwm
    if percentage < 0 or percentage > 100:
        logger.error("Invalid percentage for keypad brightness")
        percentage = max(0, min(100, percentage))
    if keypad_pwm:
        keypad_pwm.change_duty_cycle(percentage)


def set_brightness(level, cfg):
    """
    Sets oled/keypad brightness
    0-255
    """
    global display_device
    display_device.set_brightness(level)

    if keypad_pwm:
        # determine offset for keypad
        keypad_offsets = {
            "+3": 2,
            "+2": 1.6,
            "+1": 1.3,
            "0": 1,
            "-1": 0.75,
            "-2": 0.5,
            "-3": 0.25,
            "-4": 0.13,
            "Off": 0,
        }
        keypad_brightness = cfg.get_option("keypad_brightness")
        set_keypad_brightness(level * 0.05 * keypad_offsets[keypad_brightness])


def setup_dirs():
    utils.create_path(Path(utils.data_dir))
    utils.create_path(Path(utils.data_dir, "captures"))
    utils.create_path(Path(utils.data_dir, "obslists"))
    utils.create_path(Path(utils.data_dir, "screenshots"))
    utils.create_path(Path(utils.data_dir, "solver_debug_dumps"))
    utils.create_path(Path(utils.data_dir, "logs"))
    utils.create_path(Path(utils.data_dir, "telemetry"))
    os.chmod(Path(utils.data_dir), 0o777)


patch.apply()


class StateManager(BaseManager):
    pass


StateManager.register("SharedState", SharedStateObj)
StateManager.register("UIState", UIState)
StateManager.register("NewImage", Image.new)


class PowerManager:
    def __init__(self, cfg, shared_state, display_device):
        self.cfg = cfg
        self.shared_state = shared_state
        self.display_device = display_device
        self.last_activity = time.time()

    def register_activity(self):
        """
        Resets idle counter, wakes up systems if needed
        returns True if activity caused wakeup
        """
        self.last_activity = time.time()

        # power states
        # 0 = Sleep
        # 1 = Wake
        if self.shared_state.power_state() < 1:
            # wake up
            self.wake_up()
            return True

        return False

    def wake_up(self):
        """
        Do all the wakeup things
        """
        self.last_activity = time.time()
        self.shared_state.set_power_state(1)
        self.wake_screen()

    def go_to_sleep(self):
        """
        Do all the sleep things
        """
        self.shared_state.set_power_state(0)
        self.sleep_screen()

    def update(self):
        """
        Check IMU for activity
        go to sleep if needed
        if asleep, Introduce wait state
        """
        if self.get_sleep_timeout() <= 0:
            # Disabled
            self.register_activity()
            return

        if self.shared_state.power_state() > 0:
            # We are awake, should we sleep?
            if time.time() - self.last_activity > self.get_sleep_timeout():
                self.go_to_sleep()

        else:  # We are asleepd, should we wake up?
            _imu = self.shared_state.imu()
            if _imu:
                if _imu.moving:
                    self.wake_up()

    def get_sleep_timeout(self):
        """
        returns the sleep timeout amount
        """
        sleep_timeout_option = self.cfg.get_option("sleep_timeout")
        sleep_timeout = {
            "Off": -1,
            "10s": 10,
            "20s": 20,
            "30s": 30,
            "1m": 60,
            "2m": 120,
        }[sleep_timeout_option]
        return sleep_timeout

    def get_screen_off_timeout(self):
        """
        returns the screen off timeout amount
        """
        screen_off_option = self.cfg.get_option("screen_off_timeout")
        screen_off = {
            "Off": -1,
            "30s": 30,
            "1m": 60,
            "10m": 600,
            "30m": 1800,
        }[screen_off_option]
        return screen_off

    def wake_screen(self) -> None:
        screen_brightness = self.cfg.get_option("display_brightness")
        set_brightness(screen_brightness, self.cfg)
        self.display_device.device.show()
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

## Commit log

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2023-08-23 Revert "using new db structure, still returning dict instead of compositeobject"
    This reverts commit 8ae921d066d2f598078f92d281ca2cc7d1d6b758.
    [obslist.py]
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2023-09-21 Fixed various unwanted behaviours, fixed cam_solve_time almost never being the same as solve_time
    [camera_debug.py, integrator.py]
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2024-01-24 Fix crash / planets available on startup (wrong positions) updated when gps dt avaial
    [cat_images.py, catalogs.py]
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2024-02-07 Revert "Merge pull request #134 from mrosseel/cedar-solve"
    This reverts commit 25737d9c3f3f3b5be22dd79b295ea60bcc0f8b3c, reversing
    changes made to cf6e2df4beeff463ff149ab339a8331ac20884a8.
    [camera_debug.py, catalogs.py, integrator.py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]
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2024-02-17 Simplify catalog selection code which fixed a crash, rename delete to long_d
    [catalogs.py, config.py, main.py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]
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2024-02-21 Fixed selection bugs in catalogs. Fix nearby crash. Add pre-commit to nix shell.
    [catalogs.py, nearby.py]
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2024-07-14 Add T9 style keypad for searching (#187)
    * Search screen added
    * Small key changes
    * First stab at using the Objectlist
    * Fix ObjectList usage
    * Fix setup.py and name search
    * Added cursor, keypad modes, clear. Improve layout
    * Remove local keyboard print
    * Delete commented code
    * Reverting to main db and menu_structure
    [catalogs.py, keyboard_local.py, main.py]
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2024-07-18 T9 use bold font (#191)
    * Make important info bold to be better readable.
    * Letters a bit bigger, char limit of 11
    * Fix duplicate entries by breaking the loop
    [catalogs.py]
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2024-07-22 Object_list improvements for Nearby mode (#194)
    * Abstract color modifiers, line numbers to support nearby mode
    * Remove focus method
    * Trying sorting option visualisation
    * Extract nearby code in class.
    Implement update criteria and make it actually update.
    Make updating 1000x faster by limiting to only 100 nearby objects.
    * nox reformatting
    * Return empty list for sorting nearby without solution
    * Changed Debug camera behaviour.
    - there are now 3 images: debug1 - debug3
    - 2 images solve, one doesn't
    - all images stay the same for 5 seconds. This is to be able to visually
    test nearby and other location dependent views.
    * Add missing soft links
    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
    [camera_debug.py, catalogs.py, imu_pi.py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]
2024-07-27 First pass at marking menus (#196)
    * First pass at marking menus
    * quick mmtester
    * Circular menus... needs requirements update
    * Working on implemening MM
    * Menu displays
    * Object list / sort working
    * Starting on menu jump
    * Use scale 1 to better judge legibility
    * Working menu jump and help
    * Fix crash with no menu in module
    * Filter object_list only and always when filters have changed
    * Fix crash in textentry due to missing font function
    [catalogs.py, config.py, main.py]
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2024-08-01 add TLK's 90 vars dataset + setup cleanup + MagnitudeObject (#195)
    * Used now MagnitudeObject, used new setup way everywhere.
    * Fix unit tests
    * nox passes now
    * Correct unit test
    * Fix linting
    * More merge conflicts
    * Delete catalog
    * Fixed magnitude error
    [catalogs.py, composite_object.py]
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2024-08-09 Harmonize logging and make it work(tm) with multiprocessing (#203)
    * create keyboard_none, support -k none switch
    * nox: ruff code formatting
    * use getLogger and convert print statements to logging.
    * add keyboard_none and command line parameter.
    * Eliminate prints and use a logger instead.
    * Fix typo uid -> uuid
    * Use logger in pos_server (SkySafariServer)
    * Run tetra3 centroider, if cedar_detect binary is not found.
    * Log to specific logger instead of using the root logger via logging.*
    * ruff formatting
    * Silence lint messages.
    * use printf style parameters in log messages.
    * Fix typo in debug() parameters.
    * Added helper class MultiprocLogging to ma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
    [calc_utils.py, camera_debug.py, camera_interface.py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]
2024-08-10 Fix solver logging (#206)
    * Fixes to logging:
    - default log config must not disable all loggers
    - fix order of parameters when starting processes (verbose must be last)
    - cleaned bootstrap of logging.
    - A few more log messages.
    * Forgot to checkin logconf_default.json
    * Ruff formatting
    * Add test with basicconfig in logging
    ---------
    [main.py, multiproclogging.py]
2024-08-10 [WIP] Recent/History view (#207)
    * Working recent/history implementation
    * Update code for new pyhotkey version
    * Fix review remarks
    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
    [camera_interface.py, composite_object.py, integrator.py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]
2024-08-10 Fix endless logging & collect early log messages in the log file (#208)
    * Collect early logs, too.
    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
    [main.py, multiproclogging.py]
2024-08-11 Fix logging crashes and recent bug (#210)
    * Fix logging for keyboard_pi
    * Also fix camera
    * Added eq to CompositeObject, fixes recent bug.
    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
    [camera_pi.py, composite_object.py, keyboard_local.py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]
2024-08-12 Nearby smooth (#211)
    * Add logging for nearby insight
    * Fix remote square button
    * Introduce constanst to steer the behaviour of nearby
    * Better logging
    * Further tuning of params
    [nearby.py]
2024-08-13 Goto fix (#213)
    * Fix goto handling, there's no history list anymore
    * Fix magnitude bug for pushed object
    * Add missing camera exposure for testing
    * Make object_id unique so recents don't overwrite each other
    * Add jump to label, so recent is refreshed on push
    [main.py]
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2024-08-14 Shift for long keys not working, adding m (marking) as alternate for long-square
    [keyboard_local.py]
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2024-08-19 Compensate for roll offset (rebased) #192 (#216)
    * solver.py: Return RA, Dec, Roll at the centre of the camera. Returns solved["Roll"] = None (roll at the target), which needs to be calculated in integrator.py
    (cherry picked from commit 623c5045034483222700caec4dc42f4e6395d18b)
    * Calculate roll offset at center of Camera and apply to the calculated roll at the target RA/Dec.
    (cherry picked from commit edcc6cc2f46d41fc938da8280da8170a67e92661)
    * Lint with Black
    (cherry picked from commit 084a863d083f36bf211818b78444120ec932d8b0)
    * Intialize for keys solved["Roll"] etc. Replace roll_offset with solved["Roll_offset"]
    (cherry picked from commit 9f5e752fa875d2a0dc80de518ddf15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
    [calc_utils.py, integrator.py]
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2024-08-20 Catalog Image and Chart bug fixes (#218)
    * Fix error on missing roll on in cat_image, set up preload system for modules
    * Preload working, adjust startup messages
    [cat_images.py, main.py]
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2024-09-06 Fixing magnitude filtering bug (#228)
    Three fixes which prevented succesful magnitude filtering.
    Also some extra nearby filtering calls (not sure if needed)
    [catalogs.py, nearby.py]
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2024-09-07 Fix sharpless catalog import, and some other things. (#230)
    Fixed epoch conversion code
    Added missing variables files
    Added heasarch sharpless file (not used) and a readme.md
    [v90.csv]
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2024-09-12 Experimental Alignment Feature (#234)
    * WIP
    * working on rotating projections before raster
    * Working rotation before rasterization
    * Slight cleanup
    * Reduce plot render size to target size
    * Workign on reticle adjust
    * Star selection working
    * Add align on object, clean up alignment system
    * Improved navigation, fixed immediate exit bug
    * Bury align menu option
    [integrator.py, keyboard_interface.py, main.py]
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2024-09-18 GPS async processing (#237)
    * Remove active from state, put solver in loop.
    Fix typos and nox redefinition error
    * Restore logconf
    * Crashes on HardwarePWM
    * gps rewrite
    * wrap the generators
    * async gps
    * async gps
    * merge troubles
    * ignore hip_main.dat
    * SKY should leave time for TPV to run
    * No await for queue ops
    * Use other error info for faster lock
    * hdop and pdop getting it from sky
    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
    [gps_pi.py, main.py]
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2024-09-23 Add missing flat camera tray, pi_sugar spacer, and adjust pimount gps holder
    [flat30_camtray.stl, pi_mount.stl, pi_sugar_spacer.stl]
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2024-10-12 1. comets (#198)
    - all images stay the same for 5 seconds. This is to b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
    [calc_utils.py, camera_interface.py, catalogs.py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]
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2024-11-06 Add User Observing Equipment Config (#252)
    * Add equipment tracking
    * Fix up active equipment serialization, add some calculation functions
    [config.py, equipment.py]
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2024-12-20 Equipment (#255)
    * Add equipment support in the web interface.
    * Add missing equipment.tpl file and fix nox error.
    * Add missing equipment.tpl file and fix nox error.
    * Default mount for import from DeepskyLog is Alt/Az.
    * Add telescope and eyepiece information to the PiFinder interface.
    * Select telescope and eyepiece from the PiFinder screen.
    * Remove make from name on PiFinder screen.
    * Remove make from name on PiFinder screen.
    * Use one of the configured eyepieces when logging an observation.
    [equipment.py]
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2025-01-21 Adjust Catalog Selection Logic, Add Filter by Constellation, Fix minor catalog defects (#236)
    Catalog filter refactor, add constellation, fix catalog data defects
    [catalogs.py, main.py, obj_types.py]
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2025-02-02 Extend Equipment Functionalty to Object Image Preview (#263)
    * Add equipment selection to main menu, rework equipment ui to jump to it
    * Switch logging to use equipment eyepiece menu, fix serialization of solution
    * Make object images use eyepieces
    * Remove errant raw camera file
    * Refresh equipment config on web interface updates
    [cat_images.py, config.py, equipment.py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]
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2025-03-16 Release v2.1.1 to RC (#293)
    * Updating readme and parts for case
    * Removing errant file
    * Make align system more dynamic and user-friendly (#277)
    * Stashing dynamic align
    * Working on hybrid
    * More refinement
    * Refined Align system, cleaned up no-solve messages in align/chart
    * Update adjustment docs
    * Fix crash when adding instrument with a float as aperture or focal_length. (#289)
    * Better logging in an attempt to catch #286 (#287)
    * Make UIConsole a singleton.
    * Add log statements for start of sub processes.
    * Handle ValueError, if cedar_detect cannot be found.
    * Log something at start of log process
    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
    [PiFinder_smt.kicad_pcb, bezel.stl, bottom.stl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]
2025-03-16 Release v2.1.1 (#294)
    * Release v2.1.1 to RC (#293)
    * Make UIConsole a singl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
    [PiFinder_smt.kicad_pcb]
2025-03-24 Uses raw ublox data for GPS lock, add GPS UI (#268)
    * Adding raw ubx data parser
    * first version nothing worknig
    * remove accuracy filter
    * fix num sats
    * fixe ecef calculations
    * Updating to main
    * Renaming files and reinstating the original gps processor as gpsd
    * Restore post_update file
    * Improve status screen
    * Remove duplicate align
    * Improve status screen
    * fix typo
    * fixing ubx parsing, changing gpsstatus
    * Return UBX messages instead of gpsd ones, fix web location setting
    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
    [camera_interface.py, camera_pi.py, catalogs.py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]
2025-03-26 1. Gps UI tweaks (#303)
    * Merged main with the location changes
    * no ubx yet
    * Revert "no ubx yet"
    This reverts commit c872394fea9ff1b9aec03fa386954cb757aff557.
    * Add time entry in case even time is not working
    * add timeentry
    * center boxes, fix popup, clean up legend
    * align gpsstatus fields
    * align more
    [main.py]
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2025-04-01 less gps logging (#304)
    * decrease logging
    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
    [main.py]
2025-04-05 Ecef fix (#307)
    * fix ecef errors
    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
    [gps_ubx_parser.py]
2025-04-06 Web logging (#306)
    * working logging
    * Adding log view to web interface
    * remove setting of log level
    * reverse logging changes
    * remove log queue
    * console log should be info, revert some more stuff
    * Remove connection fix changes
    * Ecef fix (#307)
    no ubx yet
    Revert "no ubx yet"
    decrease logging
    working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
    [calc_utils.py, main.py]
2025-04-06 Log rotation (#308)
    * Let the logger do the rollover
    Let the logger do the rollover
    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
    [main.py, multiproclogging.py]
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2025-05-05 Internationalization - Proof of Concept (#264)
    * Prototype go at extracted string for i18n
    * First i18n prototype that works
    * Translate when displaying the menu
    * Checkin latest po.
    * Update messages.po
    * Update messages.po
    * Update messages.po
    * Update messages.po
    * Update messages.po
    * Update messages.po
    * Update messages.po
    * Menu entry "Language" added.
    * Update messages.po
    * Switch langauge on the fly.
    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
    [camera_pi.py, cat_images.py, equipment.py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]
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2025-06-25 Show magnification (#324)
    * Show magnification in image view
    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
    [cat_images.py]
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2025-06-27 Gps ubx replay with fake hardware (#305)
    * Fix sats, add time info, fix timezone and locking logic, status screen
    * Disabling camera, improving lock language
    * Change message, fix nox complaint
    * fixing lint
    * It's broken now
    * fix planet position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
    [gps_fake.py, gps_ubx.py, gps_ubx_parser.py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]
2025-06-27 Steinicke catalog (#323)
    * Refactor catalog imports, add steinicke
    * Add M40 and M45 to fix unit tests, and add 1 to arp, still missing 1
    * fix linting issues
    * Fix messier naming + add 2 missing messier 24 and 102
    * Speed up image fetching
    * linting
    * Fix (hopefully) all classifications, checked first 200 manually
    * Add NGC unit tests
    * Added unit tests for IC, ngc, ...
    * Last cleanup and adding missing files
    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
    [cat_images.py, composite_object.py, get_images.py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]
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2025-09-03 Fix Debug Dump and split "Save Picture" into separate hotkey (#329)
    * Added comments.
    * Use a separate magickey for each modified interaction (for LNG and ALT)
    * Save picture only on ALT_LEFT, take picture and dump on ALT_RIGHT
    * Make debug dump work again. Fixes #283
    * nox format
    * provide rationale for selected keys in comments.
    * Provide a keyboard overview in classes' description.
    [keyboard_local.py, keyboard_pi.py, main.py]
2025-09-13 Rename AS Dream to AS Bloom and fix star chart rotation for Dream PiFinder configuration (#342)
    [calc_utils.py, camera_interface.py, imu_pi.py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]
2025-09-14 Adding WDS import, and a new way of handling object images (#248)
    * Adding WDS import, and a new way of handling object images
    * Fix missing catalogs, get_objects query and unit tests
    * updated db
    * optimise WDS catalog import speed, merge into new catalog_imports
    * Update db, add readme
    * Reset tetra3 submodule to match upstream/main
    [cat_images.py, main.py]
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2025-09-20 Disable WDS for this release to work on performance and near sort crash
    [catalogs.py]
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2025-09-23 Fix cat images path resolution (#350)
    * Fix image path resolution in cat_images.py
    The resolve_image_name function was returning bare object names instead of full paths when catalog_object.image_name was pre-populated from the database. This caused image loading to fail as the system expected full file paths.
    Changes:
    - Remove conditional check that skipped path resolution when image_name was already set
    - Always resolve full paths with proper subdirectory structure (/path/to/catalog_images/{last_digit}/{name}_{source}.jpg)
    - Simplified logic to eithe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
    [cat_images.py]
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2025-09-28 Degraded Operation if IMU cannot be detected (#348)
    * Fall back to fake IMU, if IMU cannot be initialized.
    * Warn of degraded operation
    * Run nox, fix typing errors
    * ruff formatting and translation
    * Translate message
    [imu_fake.py, imu_pi.py, main.py]
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2025-10-04 Fix OSX logging levels by apply log config in each new subprocess
    [multiproclogging.py]
2025-10-08 configurable GPS baud rate (#345)
    * GPS baud rate configuration
    * check and fix gpsd baud on startup
    * add notes
    * limit texts to 15 chars per line of which we have 2
    * join GPS settings in 1 menu
    * New Settings Menu Structure:
    Settings
    ├── User Pref...
    ├── Chart...
    ├── Camera Exp
    ├── WiFi Mode
    ├── Mount Type
    └── Advanced
    ├── PiFinder Type
    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
    [main.py]
2025-10-08 WDS fixes (#352)
    * first pass on missing radecs for WDS
    * Reenable WDS, beter parsing of coords+fallback coords
    * Speed up name loading
    * Add debugging timing
    * eliminate double call
    * db optimisations
    * Background loading of objects
    * Enable mag loading again
    * init mag with object
    * Defer catalogs
    * thread safe background loader
    * improve startup time by deferring filtering
    * Preload modules to speed up st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
    [catalogs.py, composite_object.py, main.py]
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2025-10-19 Comets fix (#353)
    * Adding CM catalog to config, add status, add refresh, add i18n
    * Better comet progress indication and refresh
    * Refactor catalog architecture using composition pattern
    Split catalog classes into modular architecture to reduce coupling and
    eliminate code duplication:
    - Extract base classes (CatalogBase, CatalogState, CatalogStatus) to
    new catalog_base.py module
    - Replace deep inheritance with composition pattern using TimerMixin
    and VirtualIDManager
    - Split CometCatalog into separate comet_catalog.py file to brea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
    [catalog_base.py, catalogs.py, comet_catalog.py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]
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2025-11-11 Wds fix (#355)
    * Adjust batches and sleep times to increase responsiveness
    * Make search async
    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
    [catalogs.py]
2025-11-11 Camera auto exposure (#356)
    * Added PID control loop for auto exposure of camera
    * Added logging for real camera testing
    * Add preview overlay
    * Fixed star count, still might have to refactor
    * implement sweeping
    * Also sweep if no solves
    * Refactoring, sweep implementation, unit tests
    * fix RSME logging crash
    * Added experimental menu
    * Fix overlay glitch
    * Really fix exposure overlay
    * Optimized pid params
    * Added histogram plugin
    * pid tuning was too agressive, reverted
    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
    [auto_exposure.py, camera_debug.py, camera_interface.py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]
2025-11-15 Gpsd source (#358)
    Add lock_type to GPSD based messages to fix #357
    [gps_gpsd.py]
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2025-12-09 Sqm Correction UI (#366)
    Add features for user to report actual SQM and package this along with exposures to help improve SQM feature in the future
    [camera_interface.py]
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2026-01-25 Sqm improvements (#372)
    * Adding first version of sqm measurement
    * Added UI screen, some refactoring for jupyter debugging
    * Fix crash on no solution
    * No shared_state crash
    * Protect against various crash situations
    * Swapping centroid y/x
    * Added bortle classes, radius=3
    * Now try radius=2
    * Introducing bias image
    * Delete and ignore comets file, sqm fixes
    * Fix bias image bug
    * Missing bias image arguments
    * Another raw_image mention removed
    * Add debugging output
    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
    [auto_exposure.py, camera_interface.py, camera_profiles.py]
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2026-01-25 Rework gpsd gps code to fix issue with early dongle which never reported sky (#373)
    [gps_gpsd.py]
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2026-02-28 Add Harris Globular Cluster catalog loader (#384)
    * Add Harris Globular Cluster catalog loader
    * Nox fixes and full database
    * Unit Test change, Harris Loader fix, corrected catalog
    * ruffed Harris Loader fix
    [main.py]
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2026-03-01 Eq-mount support under IMU dead-reckoning tracking (#338)
    * Add comments
    * Need to change dictionary solve in both integrator.py and solver.py --> Now plate solves but chart doesn't move when PiFinder moved
    * Fix at scope: Missing name space pointing.
    * Edit comment
    * Fix at scope: Typo
    * Debug at scope: Increased threshold for using IMU tracking to 0.1 deg. Smoother. BUT IMU tracking is L/R and Up/Down reversed!?
    * imu_pi.py: Disable BNO055 config to rotate the IMU data
    * Disable using the old method to calculate Euler angles (imu["pos"])
    * Update comments
    * Remove debug logging that was added that was dumping too much to the log file.
    * Additional logging printing for debugging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
    [calc_utils.py, camera_interface.py, imu_pi.py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]
2026-03-01 IMU Integrator Selection + Misc Adjustments (#388)
    * Rename func
    * Add new class ImuDeadReckoning
    * Update ImuDeadReckoning() class
    * Remove unused dictionary entry (now using the new ImuDeadReckoning() class)
    * Update integrator.py to use ImuDeadReckoning()
    * Debug on PiFinder in test mode --> The charts move up/down and left/right reversed?
    * Remove cached astro_data/comets.txt
    * Fix .gitignore to ignore astro_data/comets.txt
    * Correct spelling in comments
    * Update README. Tested and runs OK. Reproduces functionality of the existing system.
    * Add __init__.py to pointing_model/
    * Refactor: Define axis_angle2quat()
    * Update README
    * First attempt at non-upright support using ro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
    [calc_utils.py, camera_interface.py, integrator.py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]
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2026-03-16 SQM enhancements (#374)
    This reverts commit c872394fea9ff1b9aec03fa386954cb75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
    [camera_profiles.py]
2026-04-07 Fix empty logs (#400)
    * Remove ruff warnings in VScode
    * Fix error in comets, related to string coercion
    * Use a dynamic path to the data_dir when searching for logs
    * Silence warnings in VScode
    * Patch early to avoid pickle errors in interprocess communication
    * Fix: Import server again
    * Fix: collect early logging also in log file
    * Add missing bracket.
    [comets.py, main.py, multiproclogging.py]
2026-04-17 replace generic planet identifiers (, ) with meaningful planet names in both the object list and the details/navigation screen (#390)
    [composite_object.py]
2026-04-17 Fix debug cam rotate time, add gps arg, catch type error in pos_server, fix camera fade on non-solves
    [camera_debug.py, main.py]
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2026-04-17 fix: handle MPC comet data with unparseable orbital elements (#401)
    Skyfield's load_comets_dataframe() can return string dtypes for numeric
    columns when the MPC data file contains rows it can't parse (e.g. the
    MPEC 2026-F34 batch of 27 historical comets with malformed fields).
    Even a few bad rows cause pandas to fall back to dtype=object for the
    entire perihelion_year column, which then crashes comet_orbit() for
    *every* comet with a numpy UFuncNoLoopError.
    Fix: force numeric coercion with pd.to_numeric() after loading, drop
    rows with unparseable essential fields, and add a try/except safety
    net around individual comet processing.
    [comets.py]
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2026-04-17 fix: replace incremental comet update with full reinit (#391)
    The incremental update path in do_timed_task() could never add new
    comets or remove stale ones. Combined with a boot-time race condition
    (wrong datetime before GPS lock), the initial catalog could contain
    wrong comets with no way to self-correct.
    init_comets() is already idempotent and the computation cost is
    identical since calc_comets() was called on every update anyway.
    [comet_catalog.py]
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2026-04-18 webserver: Upload and choose log configuration (#410)
    * Change from selection of "components" to switching the log configuration from webserver/logs and restarting the unit.
    * Clean up nox messages, errors and warnings.
    [main.py, multiproclogging.py]
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
